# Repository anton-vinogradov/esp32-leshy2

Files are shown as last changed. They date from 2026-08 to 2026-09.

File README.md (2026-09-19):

<div align="center">

# Leshy2 ⭐

### An open standalone pocket tool for radio, communication and authorised research

**2.4/5-GHz Wi‑Fi · BLE · 802.15.4 · 3× nRF24 · Sub‑GHz · VHF/UHF · FM/AM/SW/LW/Airband · IR · LoRa/CC1101+NFC Cap**

[Capabilities](docs/hardware.md) · [Roadmap](docs/roadmap.md) · [Stage reports](docs/stage-results.md) · [Schematics](docs/schematics.md) · [Firmware](https://github.com/anton-vinogradov/esp32-leshy2-firmware) · [Русский](README.ru.md)

</div>

<!-- current-substep: H6.0.3-R1 -->

## What we want

Leshy2 is intended to be a hobby device combining spectrum
observation, communication, diagnostics and safe experimentation without a
mandatory laptop. The first order targets one genuinely working prototype:
the factory supplies two populated PCBAs and the owner completes a simple,
solder-free final assembly.

Repairability is not a design priority and does not justify greater cost, size,
or layout/manufacturing complexity. Optional service conveniences are acceptable
only without those penalties. Safety, reliability, required assembly and test
access, and firmware programming/recovery remain mandatory.

PCB layer count is an engineering choice based on electrical integrity,
manufacturability and the complete quoted cost, not a minimization target.
The current six-layer baseline is retained until a validated comparison justifies a change.

| Area | Intended result |
|---|---|
| Radio | S3 Wi‑Fi/BLE, C5 2.4/5-GHz Wi‑Fi and 802.15.4, 3× full nRF24, CC1101, VHF/UHF voice, FM/AM/SW/LW/Airband RX and IR |
| Interface | 3.5-inch 320×480 touch IPS, direct i8080‑8, buttons, encoder, microSD and audio |
| Expansion | Protected Cap slot for U214 LoRa or U219 CC1101+NFC and an M5 Unit port |
| Reliability | Four independent USB ports, accessible recovery, hardware TX evidence and fail-closed safety |

Transmission and hazardous laboratory functions are constrained by the
[safety model](docs/safety.md); the device is only for lawful use with the
system owner's permission.

## What we decided

- Two 80 × 150-mm six-layer boards: front UI/radio and rear RF/power.
- Six compute domains: S3, C5, front Hub RP, rear RF RP, Pack and Safety.
- Ten permanent antenna ports are split 5+5; each RF path remains board-local and reaches its external connector directly or through one removable microcoax.
- The EastRising `ER-TFT035IPS-6 + ER-TPC035-6` display connects directly to S3 through a 50-contact ZIF and i8080‑8; its FPC points toward the antenna edge, folds without twist and retains at least 5 mm of relaxed reserve.
- The factory fabricates and populates two PCBAs. Without soldering, the owner fits the display on a stock rectangular PSA pad, five microcoax jumpers, knob, fasteners and enclosure.
- The 80-contact M1 carries no structural load; four nylon screws, compression stops and the enclosure carry it.
- The 80 × 150-mm outline remains while routing meets its rules. If a required power, USB/i8080 or RF path cannot route after legal local rearrangement, the next candidate is 85 × 150 mm followed by complete requalification.

## What is designed

### Physical layout

The current preview below is composed from the actual PCBs: exterior faces share one scale, without an extra rear-board mirror. Only the installed display panel's envelope is added in blue. This is not an assembled 3D validation. Inspect the inner sides in [all four current component views](docs/h6-r2-component-views.md). Coordinates and cable paths are available in the [exact-placement](docs/h6-r2-exact-placement.md) and [microcoax](docs/h6-r2-microcoax-service.md) views.

Current native PCB arrangement with the display-panel envelope

H1-to-native correspondence is not fully verified: H1 remains a concept archive, not a picture of current positions. [H6 corrections and open interface findings](docs/h6-r2-interface-review.md) describe the current boards.

[Placement corrections and their verification](docs/h6-r2-placement-repair.md) explain the holder, encoder, port/card access and internal audio assembly. The routing phase is still open.

[Component unification](docs/h6-r2-component-unification.md): GCT USB4105-GF-A ×4 is installed on the native boards; fresh DRC/parity and preservation checks pass. Other candidates and necessary functional differences remain separate.

[Archive: H1 concept four-face Leshy2 mock-up](docs/images/h1-r2-four-faces.svg?rev=h1-r2.39-views-20260907)

[Legend for 223 H1 concept bodies](docs/images/h1-r2-component-legend.svg?rev=h1-r2.39-views-20260907) ·
[physical-design report](docs/h1-r2-physical-layout.md) ·
[functional-architecture report](docs/h0-r2-functional-architecture.md) ·
[front inner face](docs/images/h1-r2-inner-ui.svg) ·
[rear inner face](docs/images/h1-r2-inner-rf.svg) ·
[display mounting](docs/images/display-mount.svg) ·
[physical sections](docs/images/h1-r2-inner-sections.svg)

Leshy2 functional architecture

### Current routing

These are exports from the live `.kicad_pcb` files, not illustrative mock-ups.
Open either board for the full-size SVG.

<table>
  <tr>
    <td width="50%"><a href="docs/images/h6-r2-routing-ui.svg">Current UI-board routing</a></td>
    <td width="50%"><a href="docs/images/h6-r2-routing-rf.svg">Current RF/power-board routing</a></td>
  </tr>
  <tr><td align="center">UI PCB</td><td align="center">RF / power PCB</td></tr>
</table>

### Current components · both faces

All four views use the same scale. Outer faces are above; inner faces below
are viewed after turning each board over, with the antenna edge still at the top.
Grey shows component outlines/references; blue is actual silkscreen.
Known footprint defects remain visible — these views do not certify assembly.
[Full-size views and legend](docs/h6-r2-component-views.md). Gold shows all 50 SMA lands and the two-sided copper lands of USB, Cap and encoder interfaces; NFC endpoints are distinguished in the legend.

[Interface labels and coverage](docs/h6-r2-interface-silkscreen.md) distinguish user, service and assembly silkscreen from grey drawing references.

<table>
  <tr><th width="50%">Front / UI</th><th width="50%">Rear / RF-power</th></tr>
  <tr>
    <td><a href="docs/images/h6-r2-components-ui-outer.svg">UI components, outer face</a></td>
    <td><a href="docs/images/h6-r2-components-rf-outer.svg">RF components, outer face</a></td>
  </tr>
  <tr>
    <td><a href="docs/images/h6-r2-components-ui-inner.svg">UI components, inner face after turning over</a></td>
    <td><a href="docs/images/h6-r2-components-rf-inner.svg">RF components, inner face after turning over</a></td>
  </tr>
</table>

Component views refresh together with routing exports; the common freshness
check rejects images that no longer match the PCB files.

## What we obtained and verified

**Current hardware marker: `H6.0.3-R1`.**

- The historical H0–H5 reviews, including H2 native production ECAD, retain their own baseline scope; their reports are collected in [one index](docs/stage-results.md).
- **Current H3 is `review_required`.** The [current analytical result](docs/h3-r2-acceptance.md) and [rail-voltage paths](docs/power-rail-margins.md) now use the fitted MAIN converter/divider/current-setting resistor. They expose current and voltage shortfalls; MAIN temperature is not established. The MAIN/AON circuit remains unqualified for production or battery energization.
- Both native KiCad boards pass the current [exact-placement checks](docs/h6-r2-exact-placement.md).
- Manufacturer-drawing corrections are being integrated into both PCBs. The [native interface review](docs/h6-r2-interface-review.md) separates applied corrections from remaining assembly gates; clean DRC alone does not prove physical assembly.
- Recovery: S3 ROM UART0 has dedicated native pins; the [C5 TS3/LV control correction](docs/h6-r2-c5-mux-control-review.md) is implemented in source/native ECAD with scoped topology and DRC/parity checks passed. The Safety service manager, electrical/HIL qualification and KILL/update policy remain open; LV20 requires Pre-order, MOQ 21. [Actual recovery boundary](docs/service-recovery.md).
- [Routing automation and design checks](docs/h6-r2-routing-automation.md): the benchmark passed **474/474 connections plus three identical cold replays per block**; the new parallel acceptance command reports current design blockers explicitly. Production routing remains paused pending full-board and electrical qualification. Live copper/connectivity counts, hash-bound DRC results and electrical-review limitations have one owner: [H6.0.3-R1](docs/h6-r2-current-routing.md).
- Native ERC currently uses passive symbol pins; zero findings do not prove correct rail sources or compatible outputs. This electrical-semantics gap blocks release; [corrected pin mappings and partial typed-ERC review](docs/h6-r2-electrical-semantics.md) describe the current evidence and remaining work.

## What remains

1. Correct the native interface/assembly findings and close the electrical-pin/rail-source review gap, then finish every connection and zero schematic-to-PCB parity in H6.0.3.
2. Re-run power/thermal, USB/i8080/M1, RF/Airband, plane and return-current checks on the actual copper.
3. Check STEP, enclosure, cables and final assembly; produce Gerber/BOM/CPL and complete independent DFM/CPL review.
4. Build the first-spin firmware package: reproducible images, fake HAL, available emulation, display test patterns and a safe first-power-on procedure.
5. Immediately before ordering, recheck every exact MPN against JLCPCB Standard PCBA stock/MOQ/price and approve the single actual quote.

Ordering and fabrication remain blocked.

## How the documentation is organised

Each kind of information now has one owner so the same decision is not retold
on several pages:

| Document | Sole role |
|---|---|
| This page | Product story: intent → decisions → implementation → result → remaining work |
| [Roadmap](docs/roadmap.md) | Stage order, current marker and transition criteria only |
| [Stage reports](docs/stage-results.md) | Links to immutable completed-phase results only |
| [Physical design](docs/h1-r2-physical-layout.md), [schematics](docs/schematics.md), [cost](docs/h1-r2-cost.md) | Detail for one subject area |
| `hardware/**/generated` and release contracts | Machine-checkable truth |

Navigation links may repeat; substantive claims belong to their one owner. The
English pages are translations of the Russian pages with the same structure,
not a second independent narrative.

Licensed under [CERN Open Hardware Licence Version 2 — Strongly Reciprocal](LICENSE).

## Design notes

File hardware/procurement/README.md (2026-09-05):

# Procurement evidence workspace

These files preserve the reviewed H5 component/factory evidence used by current
H6 layout work. They are not part of the public finished-product narrative, do not
authorize a purchase and do not replace H7/H8 owner bring-up on the sole prototype.
The active policy is source research first, mapping to the selected assembly
platform second, a documented replacement or exact-part sourcing route third,
and one prototype order only after H6/F-PO and explicit approval. There is no
separate engineering-sample or H5 coupon purchase.
H1 through H5, including the joined pre-layout and component/factory reviews,
are complete. H6.0.3-R1 owns 80-mm routing and net parity after the complete
H6.0.1 placement/mechanical/cable closure and historical H6.0.2 routing slice. JLCPCB Standard PCBA is the
non-exclusive reference, and the full 210-line BOM is mapped to `J0`–`J3`, `J4-F`, `J4-P` or `J5-U`
in the [public manufacturing baseline](../../docs/manufacturing-platform.md).
The controlling state is
[`hardware/verification/h5-component-evidence-plan.json`](../verification/h5-component-evidence-plan.json).

| Gate | Prepared artifact | Current state | Closure condition |
|---|---|---|---|
| exact display and owner installation | [`ER-TFT035IPS-6-display-assembly.md`](ER-TFT035IPS-6-display-assembly.md) | exact `ER-TFT035IPS-6 + ER-TPC035-6 option 5344`, direct `FH34SRJ-50S-0.5SH(50)`, ready-made 3M (TC) `4910SQ-2(5)` 50.8-mm PSA and the relaxed one-fold FPC route are selected; the HMX donor, adapter, untraceable reseller pads and full 33-m tape roll are rejected routes | current-lot dry fit proves the ≤24.66-mm neutral-axis path, ≥5.00-mm relaxed reserve, correct contact orientation, ≤0.714-mm folded stack and ≥0.20-mm pad clearance before owner bonding; owner verifies image/backlight/touch in H7/H8 |
| exact U214 mating stack | [`U214-mating-data-request.md`](U214-mating-data-request.md) | H1 paper geometry closed with pass-through `HLE-107-02-G-DV-PE-LC`; optional manufacturer confirmation retained | exact U214 is packed with the sole prototype; owner performs ordinary mating, continuity and retention checks in H7/H8 |
| dual-SA818S and owner final assembly | [`original inquiry`](H5.0.3-R1-no-order-supplier-inquiry.md) + [`initial reply`](H5.0.3-R1-jlcpcb-response-2026-08-26.md) + [`substantive 2 September reply`](H5.0.3-R1-jlcpcb-response-2026-09-02.md) + [`machine record`](H5.0.3-R1-supplier-response.json) + [`ticket merge notice`](H5.0.3-R1-jlcpcb-ticket-merge-2026-09-02.md) | JLCPCB confirms exact `SA818S-U/V` placement at separate designators, exact-MPN incoming control and no replacement without confirmation, with PCBA MOQ 2. The owner accepts post-PCBA display/PSA/FPC, microcoax, knob and enclosure assembly, so the recorded JLCPCB box-build decline is non-gating. The substantive reply went to `av@apache.org` and appears in Gmail account `no.mail.in@gmail.com` | ✅ `H5-EVR07` passes the PCBA supplier gate; H6 creates quoteable outputs and order-time checks final VHF terms/stock |
| optional Parts API | [`H5.0.3-R1-parts-api-support-inquiry.md`](H5.0.3-R1-parts-api-support-inquiry.md) | support attributes rejection to a new account with no order history, but is not the API review team and gives no threshold; no reapplication submitted | Parts is actually approved after sufficient order history or an accepted exception case; manual evidence remains authoritative meanwhile |
| optional full-device comparison | [`sent PCBWay inquiry`](H5.0.3-R1-pcbway-fallback-inquiry.md) + [`H5-EVR08`](../verification/generated/H5-EVR08-fallback-factory-readiness.json) | The information-only exact-one questionnaire was sent on 2026-09-02 from `vinogradov.anton@gmail.com` to `service@pcbway.com`; Gmail confirmed submission. Owner final assembly removes this response from the release gate. Seeed remains the PCBA second source. No commercial action was created | Record PCBWay's answer when it arrives and compare cost/convenience; do not wait before H6 |
| sole-prototype article manifest | [`pre-kicad-sample-plan.md`](pre-kicad-sample-plan.md) | ✅ 33-line `$267.91` known-material manifest published, including exact panel, ready-cut `3M (TC) 4910SQ-2(5)` and exact `Ettinger 007.02.611` 11-mm stops; all routes mapped and purchase not authorized | H6 locks exact M2.5 nylon screw length and emits Gerber/BOM/CPL; quote and final VHF/stock checks follow immediately before the one order |

The current evidence does not authorize a purchase. KiCad PCB placement/routing
is authorized under H6; prototype fabrication remains a separate later gate.

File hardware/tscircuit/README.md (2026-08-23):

# Current ECAD status

There is **no current Leshy2 schematic or PCB layout in this directory yet**.
The previous tscircuit sheets and their partial KiCad exports were moved to
[`drafts/legacy-2026-08-22/tscircuit-pre-g2f3i`](../../drafts/legacy-2026-08-22/tscircuit-pre-g2f3i/)
because they describe a superseded device: 80-mm boards, a 4-inch ST7796
display, discrete D-pad buttons, STOP, onboard LoRa, SA868 and the old
controller/resource assignment.

Those files are retained only as historical implementation material. They must
not be built, reviewed as the current circuit or sent to a PCB manufacturer.

The current electrical source is the machine-reviewed `G2F-3I` architecture in
[`hardware/architecture`](../architecture/). H1 has been accepted and H2 now
authorizes a new reviewable production schematic generated from that source.
KiCad PCB placement and routing remain unauthorized until the current
schematic, ERC, power/fault simulation and joined mechanical/electrical/firmware
review pass.

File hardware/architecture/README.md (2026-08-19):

# Hardware architecture sources

This directory is the machine-readable source for the Leshy2 device map.

- `devices.json` contains physical devices, exact/current MPNs and contact data.
- `candidates/G2F-3I.json` assigns devices, nets and controller resources in the
  consolidated target architecture.
- `antenna-kit.json` is the dated 12-item full-field antenna manifest, including
  exact first targets, connector polarity, availability and remaining gates.
- `am-lw-pod.json` defines the passive controlled AM/LW pod assembly, its exact
  constituent first targets and the measurements still required before release.
- `generate.py` validates the sources and emits the exact pad/net atlas, pin
  ledger and BOM into `generated/`.
- `tests/` checks contact accounting, GPIO availability, safety defaults,
  resource exclusivity and generated output freshness.

Generate or verify the artifacts with:

```sh
python3 hardware/architecture/generate.py --write
python3 hardware/architecture/generate.py --check
python3 -m unittest discover -s hardware/architecture/tests
```

The public product description is in [`docs/hardware.md`](../../docs/hardware.md).

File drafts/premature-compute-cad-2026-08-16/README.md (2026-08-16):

# Premature compute CAD snapshot

- Archived: 2026-08-16
- Source: exact tracked CAD/CI snapshot from commit `d997122` (`HEAD` when the architecture process was reopened)
- Status: **noncanonical draft/reference; do not use for implementation**
- Superseding decision: [`DEC-0032`](../../docs/review/decisions/DEC-0032-reopen-product-design-before-cad.md)

This snapshot preserves the former `SYN-3A` compute symbols, footprints, provenance,
validator and CI workflow for traceability. Its presence does not select S3, C5,
RP2354A, their package variants, their service topology or any interconnect.

Reusing any part requires a reviewed target product design, whole-device optimality
decision, conceptual placement and new atomic architecture review under `FLOW-0001`.

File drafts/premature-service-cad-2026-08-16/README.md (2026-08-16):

# Premature service-CAD experiment

- Archived: 2026-08-16
- Status: **noncanonical discarded experiment; no implementation input**
- Superseding decision: [`DEC-0032`](../../docs/review/decisions/DEC-0032-reopen-product-design-before-cad.md)

An uncommitted experiment had started exact service connectors and recovery
footprints before product design and complete architecture selection. Those local
CAD artifacts were discarded rather than promoted. The reviewed, implementation-
neutral requirement that every selected programmable chip retain independent
programming, recovery and diagnostics remains active; connector count, format and
pinout are intentionally open.

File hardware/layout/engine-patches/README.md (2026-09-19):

# Experimental engine patches / экспериментальные исправления

`krt-0.22.0-npth-via-floor.patch` targets [KiCadRoutingTools](https://github.com/drandyhaas/KiCadRoutingTools) commit `5a7fbcb6ee4deebd1d9ec1d5bd094d8681f502f3`. Its SHA256 is `f23c065706e02fd003d350f9cd4c308de7b5849981d98a023c10d43850884b03`. Upstream code is MIT-licensed; its notice is retained alongside this patch.

The patch consistently applies the declared copper-to-NPTH floor to via obstacles, post-route nudging and internal DRC. It includes seven regression tests, including the actual failing RF/UI coordinates. It does not weaken rules or change the Rust binary. Apply only to an isolated checkout with `git apply`; never mutate the pinned baseline while a comparison is running. Independent native KiCad validation remains mandatory. Passing unit tests alone is not routing or production acceptance.

Патч согласованно учитывает заданный зазор от меди до NPTH в препятствиях для via, последующем сдвиге via и внутреннем DRC. Семь тестов включают реальные ошибочные координаты RF/UI. Правила и Rust-бинарник не меняются. Применять через `git apply` только в отдельной копии указанной версии; исходный движок во время сравнения не менять. Независимая проверка KiCad обязательна; одних unit-тестов недостаточно для принятия трассировки или производства.

## Pending-pad experiment / эксперимент защиты площадок

`krt-0.22.0-npth-pending-pad.patch` is a **combined replacement**, not a patch to apply on top of the first one. Apply it to the same clean upstream commit. SHA256: `0dec1ef898beec101580f496a7ef48a9042cb45ad77b29b2468e26c3f8a63067`. It retains the NPTH fix and adds opt-in `KICAD_PENDING_PAD_PROTECTION=1`: existing soft approach costs can persist for unescaped pads after a multipoint net's first branch is routed. It creates no copper and changes no clearance rules. Nine additional tests cover default-off behavior, owner exclusion, attachment/rip lifecycle and all four obstacle builders. Retirement reuses the engine's XY attachment heuristic, **not electrical connectivity**; strict native validation remains authoritative. Unit-test success does not establish a successful 474-connection campaign.

`krt-0.22.0-npth-pending-pad.patch` — **совмещённая замена**, не дополнение поверх первого патча; применять к той же чистой upstream-версии. Он сохраняет исправление NPTH и добавляет выключенную по умолчанию опцию `KICAD_PENDING_PAD_PROTECTION=1`: мягкая защита подходов к площадкам может сохраняться после трассировки первой ветви многоточечной сети. Медь не создаётся, правила зазоров не меняются. Девять новых тестов проверяют выключенное состояние, исключение собственной сети, появление/удаление подходящей меди и четыре пути построения препятствий. Снятие защиты использует существующую XY-эвристику, **не проверку электрической связности**; окончательное решение остаётся за независимым native-контролем. Успех unit-тестов не означает прохождения бенчмарка 474 связей.

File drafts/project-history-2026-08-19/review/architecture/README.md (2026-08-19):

# Product and architecture workspace

- Статус: **G2F logical/electrical feasibility active; architecture reopened**
- Correction: [`DEC-0032`](../decisions/DEC-0032-reopen-product-design-before-cad.md)
- Sequencing refinement: [`DEC-0041`](../decisions/DEC-0041-electrical-feasibility-before-physical-layout.md)
- Integrated-mockup pause: [`DEC-0058`](../decisions/DEC-0058-internals-before-integrated-mockup.md)
- Method: [`FLOW-0001`](FLOW-0001-product-to-cad-gates.md)

## Canonical active chain

1. Reviewed intent/capability inputs from stages 1–2.
2. Logical/electrical feasibility: neutral semantic demand, real-device pin
   provenance and at least two complete owner/bus/GPIO candidates.
3. Owner-selected working electrical baseline, explicitly provisional.
4. Dependency-ordered internal closure through [`INT-0001`](INT-0001-internal-design-closure-sequence.md):
   compute/service, safety, power, UI/storage, audio, RF and expansion evidence.
5. Resume target physical/product mockup only after the joint internal paper
   review; any packing/RF/power conflict loops back visibly.
6. Whole-device optimality, conceptual co-design and owner decision.
7. Atomic architecture only after all prior gates pass.
8. Final components, electrical CAD, schematic and PCB afterwards.

The current active artifacts are `DEM-0001`, `SRC-0002`, `DSP-0001/0002`,
`CTL-0001`, [`NIF-0001`](NIF-0001-digital-noninterference-layout.md),
[`RFQ-0002`](RFQ-0002-g2f-3i-rf-concurrency-boundary.md) and the generated
`G2F-pin-ledger` plus focused
[`G2F-3I principled pinout`](generated/G2F-3I-principled-pinout.md).
`PIN-0003/REV-0004V` review the exact owner/contact projection;
`DEC-0052/REV-0004X` then allocate S3 GPIO41/42 to direct-QSPI D2/D3 and record
the then-current `S3=2, C5=1, RP=0, slow=P27` free-contact state. Subsequent
`AUDIO-0002/FND-0067` uses P27 for the omitted RX-audio source selector;
`DEC-0054/REV-0005D` then assigns S3 GPIO6 to reset-safe `AUDIO_ARM`. After
`DEC-0059`, GPIO47 was the only free S3 contact. `DEC-0086/UI-0001` now use
GPIO39/GPIO47 for direct encoder PCNT0 capture and move touch IRQ into shared
GPIO37. `DEC-0088/DSP-0007` fix exact active-low ST77922, 10-kOhm raw pull-up
and non-inverting 1G07. A dedicated TCA9534A restores
interrupt-driven 4×3 controls and releases TCA6424 P00…P05. I5 now assigns
P00/P01/P02 to capture selection, speaker enable and headphone sensing; I6
assigns P03/P04 to powered-off CC1101 band selection. `DEC-0098/EXP-0001` then
uses P05 for independent native-M5-Unit power. Current free state is
`S3=0, C5=1, RP=0, main slow=0`; UI-matrix P7 remains reserved.
`DEC-0051` publishes that reviewed projection as the visible principle-level
working design in the root target document; it remains reopenable and is not
the G7 atomic architecture.
`DEC-0044/REV-0004L` make `G2F-3I` the leading reviewed paper
map under a digital no-neighbour-stall invariant. `FND-0053/REV-0004M` prove
that arbitrary cross-group co-located same-band TX↔RX cannot be promised;
`DEC-0045` selects one active group, while `SG-N24` explicitly requires every
simultaneous three-radio PTX/PRX mix. `DEC-0047` selects a qualified RF envelope.
`N24H-0001` separates ordered `L0 DIV↔DIV` pre-HIL from target `T1`, while
`N24M-0001/IMP-0040/DEC-0048` select three compact IPEX→external-SMA nRF paths
and external SMA for every onboard antenna endpoint; exact production lots,
feeds and measurements remain open.
`DEC-0046/QST-0001` require unused interfaces to
enter verified quiet states. It is not yet target: exact RF paths, power gates,
peripherals and HIL remain open; CAD stays blocked.
`AUDIO-0001/REV-0005B` close the exact ES8311 QFN-20 digital/contact fit:
S3 GPIO1/2/15/16/17/18 land on real I2C/I2S contacts, `CE` is address strap
`0x19`, and P10 is external `CODEC_PWR_EN`. `AUDIO-0002/REV-0005C` compare the
complete capture/playback/TX/reset path, add exact TAC5111IRGER reference
contacts and expose `FND-0067`; `DEC-0054` accepts the active-buffer ES8311
prototype plus direct arm and exact selector/gate/amp ICs. `FND-0095/
AUDIO-0003/DEC-0090/REV-0005AU` now close the dependent I5 paper block with
exact power/interface isolation, analog passives, address/clock handling and
physical microphone/speaker/headphone endpoints. I5 has **«Проведено ревью»**;
acoustic/RF/specimen HIL stays explicit. I6 later receives paper review by
`DEC-0097/COX-0001/REV-0005BC`; I7 is reviewed by `DEC-0098/0099`, and I8 is
now active.
`DEC-0058` now pauses the integrated mockup until the internal chain is jointly
reviewed. `INT-0001/I1` has **Проведено ревью** through
`DEC-0059/REV-0005L`: 1-bit C5 SDIO restores S3 UART0 and C5 native USB,
while M5 Unit UART moves to UART1 on the same pins. `DEC-0061/SAFE-0002/
REV-0005O` now give `I2` **Проведено ревью**: exact AON latch/reset/gate
devices cover S3+C5+RP and every external TX request, while seven RF detectors,
optical IR evidence, local-I²C source mask and direct physical aggregate are
machine-projected. `DEC-0082/PWR-0021/REV-0005AM` now give I3 paper electrical
scope **«Проведено ревью»** and make I4 the active paper block; named
procurement and prototype HIL evidence remains open.
`DEC-0083/USB-0001/REV-0005AN` then close the first I4 endpoint: exact JAE
USB-C and TI four-line protection replace the abstract port, corrected 220-pF
CC shunts preserve capacitance margin, and that endpoint leaves GPIO47 free. Physical
port/SI/ESD HIL stays open while I4 proceeds.
`FND-0088/DSP-0006/DEC-0084/REV-0005AO` then close the display paper
electrical endpoint: exact first ZIF candidate, protected-main logic supply,
reset-low defaults and a separately latch-protected PWM backlight replace the
three former abstractions. Real-tail mate/orientation, panel procurement and
electrical/thermal HIL remain open; no KiCad or physical freeze is implied.
`FND-0089/STO-0001/DEC-0085/REV-0005AP` then close the microSD paper
electrical endpoint. Exact card-side Ioff buffers, CS-gated DAT0 return,
mandatory switched pulls, all exposed-contact/detect ESD, reset defaults and
SPI-mode-first sequencing preserve the shared S3 allocation without a new
GPIO. Socket placement/access, real media, throughput and fault HIL stay open.
`FND-0090/UI-0001/DEC-0086/REV-0005AQ` then restore the complete local-control
inventory and close its principled pin fit: 4x3 ordinary matrix, direct PCNT0
encoder, direct RP PTT and independent AON STOP/RE-ARM.
`FND-0092/UI-0002/DEC-0087/REV-0005AR` close the next electrical boundary with
exact low-current switches, a gold-clad COM+NC STOP target, exact pull/filter
networks and separate matrix/fast/safety ESD returns. Cap/guard/harness and
enclosure mechanics and control HIL remain open.
`FND-0093/DSP-0007/DEC-0088/REV-0005AS` then close the exact integrated touch
identity/address/polarity endpoint: ST77922 is the assembly TDDI at `0x38`,
active-low TP_INT has its own 10-kOhm raw pull-up and fixed 1G07 path to shared
GPIO37, and the former inverter option is removed. Specimen IRQ/reset,
shared-source and physical HIL remain open.
`FND-0094/IOX-0001/DEC-0089/REV-0005AT` then complete the consolidated I4
audit. Exact TCA6424A power/address/reset/interrupt, AON-to-main observation
isolation, pack target `0x2A`, real GPIO4 microSD return, direct USB-shell
ground bond and exact STOP LED resistor are machine-projected. I4 paper
electrical scope has **«Проведено ревью»**; I5 follows as reviewed above, while prototype,
physical and procurement evidence stays open and KiCad remains unauthorized.
`PWR-0002/REV-0005P` review its current load/scenario prerequisites and reject
the legacy sheet as a target: its charger lacks a system power path, its ADC
is not a fuel gauge, fixed 3-A Type-C draw is unproven and its rails do not fit
the accepted AON/voice/current envelope. The owner accepted `IMP-0052/B` as
`DEC-0062`: the two 18650 slots remain individually replaceable, and admission
is fail-closed rather than accepting arbitrary loose cells. `DEC-0064` then
reopened the electrical series/controlled-1S arrangement for comparison, and
`DEC-0065/REV-0005T` confirm supervised 2S for the base product.
`PWR-0003/IMP-0053` are closed by `DEC-0063`: the owner selected sink-only
USB-PD up to 30 W. `PWR-0004/REV-0005R` review exact TPS25751DREFR,
BQ25798RQMR, CAT24C512WI-GT3 and TVS2200DRVR fit while leaving the cell manager,
rail tree, passives and HIL active in I3. `PWR-0005/FND-0075` separate ordinary
pack gauging from fail-closed loose-cell admission; `DEC-0066/REV-0005V`
accept exact MAX17320G20+T plus MSPM0C1104SDGS20R and project both physical
devices separately. `PWR-0006/FND-0076` retain the
controlled two-slot 1S and one-slot 1S alternatives as future-SKU comparison
evidence. `PWR-0007/FND-0077/REV-0005W` review the exact 2S tap rules, reset
hold, admission-supply isolation, two-ADC evidence and common-path losses.
`DEC-0067/REV-0005X` close the exposed recovery gate with no in-device
deep-cell recovery and accept the exact active switching FET, fuses, shunt,
NTCs, hold and supply-isolation packages. `PWR-0008/DEC-0068/REV-0005Y`
then review the independent fixed AON/3.3/4.0/5.0-V rail tree, exact
TPS629203/TPS564252 inductors, five TPS22919 branches and reverse-blocking
TPS259470L latch-off external boundary after `DEC-0069/REV-0005Z`.
`PWR-0009/DEC-0070/REV-0005AA` add two exact `MMBT3904-7-F` qualifiers so
disabled optional rails release `POWER_FAULT_N`, while EN-high PG loss remains
hardware-visible. `PWR-0010/DEC-0071/REV-0005AB` correct the earlier startup
claim: the 1.509-A eFuse limit is immediately active, 4.7 nF controls startup
slew and 220 nF admits only a bounded post-start 2-A transient. Exact OVLO,
local bypass and output bleed are now eight physical MPN-bearing instances in
the machine source and living diagrams. `PWR-0011/DEC-0072/REV-0005AC` then
replace the four converters' abstract networks with 24 exact physical
configuration, input, output, fixed-feedback and feed-forward passives. Their
fixed tolerance ranges remain compatible with the loads and eFuse OVLO, and
the obsolete 45.0-kOhm candidate is rejected for the active 45.3-kOhm MPN.
`PWR-0012/DEC-0073/REV-0005AD` first close direct AON enable plus nine exact
EN/PG/fault resistors using only existing BOM MPNs. `FND-0084/PWR-0019/
DEC-0080/REV-0005AK` later expose and remove the hidden source-sequencer
endpoint: AON PG directly holds TPS3808 MR, delayed POR directly enables main,
and an exact 10-kOhm/100-kOhm pair gives 3.0-V nominal release. The amended
control profile has ten physical resistor positions and no new unique MPN.
`FND-0085/PWR-0020/DEC-0081/REV-0005AL` then correct the remaining internal
single-fault gap with exact independent AON/main/voice post-buck cutoffs,
protected-side PG, threshold/loss calculations and a reviewed fault matrix;
no GPIO or function is lost.
`FND-0086/PWR-0021/DEC-0082/REV-0005AM` consolidate every I3 paper obligation,
heat source, fault and physical residue. I3 is paper-reviewed with all
prototype/lot/I8 evidence still explicit; this activates the dependent I4
paper block at that point in the chain.
`FND-0087/USB-0001/DEC-0083/REV-0005AN` now give exact protected product USB
the first I4 paper-endpoint review without promoting placement or HIL.
`FND-0088/DSP-0006/DEC-0084/REV-0005AO` give the second I4 endpoint a paper
review while explicitly rejecting a back-power-prone whole-panel switch and
keeping the connector footprint blocked on a real FPC-tail proof.
`FND-0089/STO-0001/DEC-0085/REV-0005AP` give the third I4 endpoint a paper
review, eliminate storage back-power and display-D1 contention, and keep the
socket footprint, media/endurance, throughput and destructive HIL blocked.
`FND-0090…0093/UI-0001/UI-0002/DSP-0007/DEC-0086…0088` retain every physical
control, close exact switch/protection and touch identity/address/polarity,
and leave only named mechanics/specimen HIL before the consolidated I4 audit.
`FND-0094/IOX-0001/DEC-0089/REV-0005AT` close that consolidated audit, correct
the shared-interface residues and advance the dependency chain to I5 without
claiming layout or HIL evidence.
`FND-0095/AUDIO-0003/DEC-0090/REV-0005AU` close that I5 paper block and
advance the dependency chain to active I6 without claiming acoustic, RF,
layout or HIL evidence.
`FND-0096/N24E-0001/DEC-0091/REV-0005AV` close the first I6 paper subblock:
three full-function nRF paths gain exact powered-off digital isolation,
local energy and directional 2400–2525-MHz actual-TX evidence. The unproven
Ebyte RF mate, thresholds, T1 fixture and every other I6 RF endpoint remain
open, so I6 and the no-KiCad boundary are unchanged.
`FND-0097/NAT-0001/DEC-0092/REV-0005AW` then close the native-radio paper
subblock: exact S3 2.4-GHz and C5 2.4/5-GHz external contacts now lead through
separate real U.FL mates and dual-band directional couplers into complete
LTC5532 evidence circuits. C5 ANT2 is explicitly default-disabled/no-connect;
jumper length, chassis RP-SMA, thresholds and whole-feed HIL remain physical
gates. `FND-0098/CCRF-0001/DEC-0093/REV-0005AX` next close the CC1101 paper
subblock: two equal-control SP3T bodies isolate all three branches at both ends,
P03/P04 select 315/433/868–915 only while power is off, exact crystal/balun/
passives/ESD are physical and a final-line AD8314 sample replaces the abstract
evidence tap. Conducted tuning, sensitivity/output/spurious/legal-profile,
SMA mechanics and coexistence HIL remain open; I6 and no-KiCad boundary stay
active for the remaining RF endpoints. `FND-0099/VRF-0001/DEC-0094/
REV-0005AY` then close the SA518 RF paper subblock: physical ANT contact 7
feeds a direct protected 50-Ohm SMA boundary, exact 24-V low-C ESD and an
AD8314 5.1-kOhm/52.3-Ohm actual-TX sample. The lower-voltage CC TVS is not
reused, no unproven filter bank spends P05, and a measured conducted failure
explicitly reopens that choice. Voice RF HIL remains open; I6 continues with
IR and consolidated coexistence under the same no-KiCad boundary.
`FND-0100/IRF-0001/DEC-0095/REV-0005AZ` then close the IR paper endpoint.
Exact top-view SMD `TSOP95238TT` and `TSMP95000TT` retain robust
demodulation plus measured 30-60-kHz carrier learning behind one discharged
receive rail and Ioff return buffer. Exact `VSMY14940`, 33-Ohm limit,
`DMN2056U-7` and the existing STOP gate close TX; shielded `VEMD1060X01` plus
AON `TLV9061IDBVR` verify physical light rather than current. Pin budgets do
not change. `FND-0101/RXF-0001/DEC-0096/REV-0005BA` subsequently catch the
still-abstract Si4732 FMI/AMI endpoints and add separate protected FM/SW and
non-50-Ohm AM/LW first-target circuits. `FND-0102/REV-0005BB` then correct the
entire shifted SOIC-16 machine contact map from the visually inspected
manufacturer package drawing and lock all 16 contacts. Optical/thermal/IEC and consolidated
coexistence HIL remain open. `FND-0103/FND-0104/COX-0001/DEC-0097/
REV-0005BC` then remove the stale cross-group-promotion path, split receiver,
codec/audio and voice quiet contracts and freeze one consolidated matrix for
all groups, legal intragroup modes, ordered transitions, eight fixture classes,
actual-TX evidence and no-stall thresholds. I6 has **«Проведено ревью»** for
paper electrical and qualification scope; physical HIL remains explicitly
not executed and can reopen its owner. I7 subsequently closes below and the
no-KiCad boundary continues through active I8.
`FND-0105/EXP-0001/DEC-0098/REV-0005BD` close the I7 M5 expansion paper
subblock. U214 and the native HY2.0-4P Unit port now have independent
true-reverse-blocking 5-V branches, branch-valid supervisors, exact signal
isolation and connector ESD. The fictitious accessory-presence input is removed;
P26 reports real Unit-rail readiness. Connector MPNs and all physical/hot-plug/
reverse-source/profile/coexistence evidence remain open.
`FND-0106…0108/SVC-0002/DEC-0099/REV-0005BE` then close the remaining I7
service/recovery paper circuit: separate data-only C5/RP USB ports now block
VBUS and D-line backfeed, three keyed DBG10 and six controls are exact, and
passive-drain reset sinks remove push-pull contention. I7 has **«Проведено
ревью»**; I8 is active and the no-KiCad boundary continues.
`FND-0109/BOM-0008` then generate the first complete I8 coverage view.
`PWR-0022/DEC-0100/REV-0005BF` repair and re-review the exposed MAX17320/MSPM0
support residue without changing the accepted 2S product topology. The current
map has 858 architecture instances; `FND-0112/BOM-0011/DEC-0103/REV-0005BJ`
exclude the one assembly-internal ST77922 evidence node, leaving 857
supplied/costed placements / 187 purchase MPN lines plus four explicit SMA, cable, M5
and antenna-kit gap families. `FND-0110/SAFE-0003/DEC-0101/REV-0005BG`
subsequently instantiate every actual-TX threshold network and repair the
AON-to-main evidence boundary. I8 inventory coverage is reviewed;
orderability, cost and alternate qualification remain active.
`FND-0113/REV-0005BP` then repair the product-site projection itself: a bounded
vertical overview renders on GitHub, while the exhaustive one-device-per-node
source and pin/net tables stay machine-derived. No architecture content changes;
I8 remains active and KiCad remains unauthorized.
`FND-0111/BOM-0009/DEC-0102/REV-0005BH` subsequently recheck all 33 missing
source lines, replace the RP prose pseudo-MPN with exact `SC1512-A4`
(`RP2354B0A4`) and, after the internal-node correction, leave current
orderability coverage at 186/187. Exact
standalone `HMX035CTFT-001` sourcing is the sole used-line residue; cost and
the four physical purchase families remain open. `DSP-0008/BOM-0010/REV-0005BI` then prove current complete-board
specimen access, define the exact standalone-panel RFQ and record the first
no-drop-in disposition without changing the display endpoint.
`BOM-0012/DEC-0104/REV-0005BK` subsequently classify all 187 purchase lines:
policy coverage is complete without pretending that specific second-source
MPNs are already qualified.
`BOM-0013…0026/DEC-0105…0106/REV-0005BL…CA` then validate the cost-evidence
contract, explicit RFQ/retail gaps and first 175/187 prices covering 829
placements. Their USD 157.3727 base-product subtotal is deliberately partial;
all twelve remaining prices have explicit gates and full factory COGS remains
open.
`BOM-0027/REV-0005CB` subsequently make the four physical-family boundaries
machine-readable: 4/4 families / 28 items now have owner, prerequisites and
acceptance. Exact connectors, harnesses, antenna-kit items and physical/RF HIL
remain open at those gates; no MPN or footprint is guessed.
`FND-0115/BOM-0028/REV-0005CC` then remove the circular exit condition: G2F/I8
cannot depend on G3 geometry or the downstream G8 frozen BOM. I8 receives
**«Проведено ревью»** in paper procurement-feasibility scope; exact physical
gate execution, target RFQ, named production alternates and factory COGS stay
mandatory at G3/G8. `FND-0116/I9-0001/REV-0005CD` then complete the joint
working-candidate paper review: all 59 unique `abstract:*` boundaries are
exhaustively classified and no owner decision remains hidden. G3 integrated
mockup work resumes; G7 atomic selection and KiCad remain unauthorized.
`PWR-0013/DEC-0074/REV-0005AE` then close the exact 10-Ohm pre-admission
load, independent non-retriggerable timer, 28.7-40.7-ms C0G paper window,
25-50-ms production acceptance and both divider/filter frontends. `FND-0078`
corrects the old PA24 battery-divider assignment to real
PA25/PA26 contacts without changing the `12/3/3` budget.
`PWR-0014/DEC-0075/REV-0005AF` then close the exact BQ25798 2S/750-kHz
strap, 2.2-uH/7-A inductor, all physical energy banks, BATP/TS/ILIM, local-bus
pulls, reset-high CE and special-pin terminations. `FND-0079` corrects product
USB-C/USB2 protection back to I4 and exposes TPS25751/CAT24C512 support
passives as the next true I3 paper dependency.
`FND-0080/PWR-0015/DEC-0076/REV-0005AG` then correct separate TPS
VBUS/VBUS_IN startup, hardware SafeMode,
17 exact support components and both complete I2C pull networks.
`FND-0082/PWR-0017/DEC-0078/REV-0005AI` then correct the physical TPUL WQFN
map, reuse its second channel for a `>=350 ms` hardware refractory lockout and
replace the single load with two parallel 20-Ohm/2-W branches. Exact-cell
selection is then closed at paper level by `FND-0083/PWR-0018/DEC-0079/
REV-0005AJ`: two exact `XTAR 18650 4000mAh` protected button-top instances
provide `28.8 Wh`, a 10-A discharge class and a 2-A standard-charge ceiling.
Assembly-matching certification evidence, droop distributions, mechanical
continuity/thermal coupling, calculated hot loss and HIL remain active.

## Active G2F artifacts

- [`INT-0001`](INT-0001-internal-design-closure-sequence.md) defines the
  dependency-ordered `I0…I9` paper/electrical closure required before the
  integrated physical mockup resumes;
- [`SAFE-0001`](SAFE-0001-aon-stop-and-tx-evidence-options.md) reviews the `I2`
  options; [`SAFE-0002`](SAFE-0002-accepted-aon-stop-and-evidence-circuit.md)
  records the accepted exact fan-out, pulls, fault matrix, eight evidence
  channels and test points. `FND-0071` paper mismatch is closed; I3/I6/HIL
  measured proof remains explicit;
- [`SAFE-0003`](SAFE-0003-exact-actual-tx-threshold-and-isolation.md)
  instantiates all eight comparator threshold/hysteresis networks, completes
  comparator/source-mask support and isolates three AON evidence signals from
  main-domain inputs; paper electrical scope reviewed, calibration/HIL open;
- [`PWR-0002`](PWR-0002-i3-power-prerequisite-audit.md) re-derives the `I3`
  loads/scenarios and rejects the old source as a target;
- [`PWR-0003`](PWR-0003-charge-power-path-options.md) compares the complete
  5-V Type-C/NVDC and USB-PD/buck-boost paths; B is accepted by `DEC-0063`;
- [`PWR-0004`](PWR-0004-accepted-usb-pd-front-end.md) verifies the exact
  sink-only 30-W PD/charger/configuration/protection path and sourcing snapshot;
- [`PWR-0005`](PWR-0005-replaceable-2s-manager-options.md) reviews exact
  gauge/admission candidates and reset-default behavior; option A is accepted
  by `DEC-0066`;
- [`PWR-0006`](PWR-0006-one-or-two-cell-topology-comparison.md) reviews the
  reopened topology, rails, losses, one-cell behavior and cost; supervised 2S
  is accepted by `DEC-0065`;
- [`PWR-0007`](PWR-0007-max17320-2s-surrounding-circuit.md) verifies the 2S
  sensing/shorting rules, current/loss screen, per-slot fuse/NTC candidates,
  shunt, reset hold, supply handover and real ADC budget; `DEC-0067` accepts
  no in-device recovery and the exact active common-drain power FET;
- [`PWR-0008`](PWR-0008-exact-downstream-rail-tree.md) verifies independent
  fixed rails, exact converter/inductor/load-switch/eFuse contacts, current
  headroom, availability, sequencing and the updated cost screen;
- [`PWR-0010`](PWR-0010-external-efuse-passive-profile.md) closes the first
  exact eFuse `RILM/dVdt/ITIMER/OVLO`, local-capacitor and discharge profile,
  and separates controlled startup from the bounded 2-A post-start interval;
- [`PWR-0011`](PWR-0011-application-converter-passive-profile.md) closes the
  exact AON and three TPS564252 energy/configuration/feedback profiles as 24
  separate physical parts, including lifecycle, tolerance and DC-bias screens;
- [`PWR-0012`](PWR-0012-exact-converter-control-passives.md) closes direct
  AON enable and, after the DEC-0080 amendment, ten exact converter/POR
  EN/PG/fault resistors without adding a GPIO or unique BOM MPN;
- [`PWR-0013`](PWR-0013-exact-pack-diagnostic-frontends.md) is retained as the
  historical first diagnostic pass and is explicitly superseded by PWR-0017;
- [`PWR-0014`](PWR-0014-exact-bq25798-passive-profile.md) closes the exact
  BQ25798 2S/750-kHz energy, current/temperature sensing, reset and special-pin
  profile while leaving placement/thermal/source-transition HIL explicit;
- [`PWR-0015`](PWR-0015-exact-tps25751-eeprom-support-profile.md) closes the
  exact TPS25751D/CAT24 autonomous SafeMode startup, 17 support components,
  unused contacts and complete local/host pull networks;
- [`PWR-0016`](PWR-0016-keystone-1048p-holder-and-ntc-coupling.md) closes the
  exact polarized holder and three physical cell-temperature contact roles;
- [`PWR-0017`](PWR-0017-hardware-diagnostic-refractory-lockout.md) closes the
  corrected TPUL contacts, cascaded hardware cooldown, hot repetition bound
  and two-branch pulse-rated load while leaving exact-cell droop numbers HIL;
- [`PWR-0018`](PWR-0018-xtar-18650-4000mah-cell-profile.md) selects two exact
  XTAR protected 4-Ah cells as the first qualification target and records the
  certification/specimen gates;
- [`PWR-0019`](PWR-0019-exact-source-sequence-and-power-reserve.md) replaces
  the abstract source sequencer with the exact AON-PG/POR/main path and freezes
  a conservative system-first USB/charge power rule;
- [`PWR-0020`](PWR-0020-independent-post-buck-containment.md) separates all
  internal raw buck outputs from their loads with exact independent cutoffs,
  protected PG and reviewed threshold/loss/single-fault behavior;
- [`PWR-0021`](PWR-0021-i3-consolidated-paper-closure.md) audits the complete
  I3 dependency, heat/fault ledger and remaining evidence, allowing I4 paper
  work without claiming prototype qualification;
- [`PWR-0022`](PWR-0022-exact-max17320-2s-support-profile.md) repairs the exact
  MAX17320 2S support, status translation, shunt force path and MSPM0 support;
  **Проведено ревью paper electrical scope**, physical/HIL open;
- [`USB-0001`](USB-0001-exact-product-usb-c-and-protection.md) closes the first
  I4 endpoint with exact JAE USB-C, four-line TI CC/USB2 protection, corrected
  220-pF CC shunts and complete real-contact routing while retaining HIL;
- [`STO-0001`](STO-0001-exact-isolated-microsd-endpoint.md) closes the third
  I4 endpoint with exact switched power, partial-power isolation, pull/damping,
  complete socket ESD and always-readable detect while retaining physical and
  media HIL;
- [`UI-0002`](UI-0002-exact-switch-and-control-protection.md) closes exact
  contact-current, default-state and ESD routes for every retained physical
  control while keeping actuator/enclosure HIL open;
- [`DSP-0007`](DSP-0007-exact-integrated-st77922-touch-endpoint.md) names the
  integrated ST77922, exact `0x38`/active-low contract and fixed board IRQ
  normalizer while retaining specimen/shared-line HIL;
- [`IOX-0001`](IOX-0001-consolidated-i4-electrical-closure.md) audits all I4
  endpoints together, closes the exact main slow-I/O core and cross-domain
  routes, and classifies every remaining item as HIL, physical, I5…I8 or CAD;
- [`AUDIO-0003`](AUDIO-0003-exact-audio-and-receiver-endpoint.md) closes I5
  with exact codec/receiver/voice power and isolation, complete analog paths,
  exact acoustic endpoints and separately named HIL residue;
- [`DEM-0001`](DEM-0001-current-semantic-signal-demand.md) reconstructs current
  signal demand without inheriting an owner;
- [`SRC-0002`](SRC-0002-real-device-pin-provenance.md) requires the full
  SoC/package/module/carrier chain and records the first verified candidates;
- [`AUD-0013`](../audits/AUD-0013-legacy-layout-generator-reuse.md) records which
  geometry/checks from the old drawing generator will be reused after pin review;
- [`REV-0003X`](../reviews/REV-0003X-electrical-feasibility-entry.md) reviews the
  sequencing correction and these inputs.
- [`DEC-0042`](../decisions/DEC-0042-single-source-architecture-data.md) accepts
  one machine-readable device/net source; [`G2F-pin-ledger`](generated/G2F-pin-ledger.md)
  renders three structurally checked maps including leading `G2F-3I`;
- [`PIN-0003`](PIN-0003-g2f-3i-principled-pinout.md) and the generated
  [`pinout atlas`](generated/G2F-3I-principled-pinout.md) provide the requested
  principled owner/net/pad diagram and exact tables. `FND-0059` fixes stale
  pre-quiet-state budgets; `FND-0060` exposes every still-abstract electrical
  endpoint instead of presenting it as a finished schematic;
- [`REV-0005K`](../reviews/REV-0005K-vertical-living-principled-diagram.md)
  makes that diagram a narrow top-to-bottom living projection. Every accepted
  internals change must update both target README diagrams and the generated
  atlas in the same commit; regression checks current candidate MPN coverage;
- [`REV-0003Y`](../reviews/REV-0003Y-single-source-and-draft-pin-maps.md) reviews
  the generator foundation and explicitly leaves complete-candidate review open.
- [`DSP-0001`](DSP-0001-display-storage-real-device-evidence.md) replaces the
  inherited full-frame target with the accepted task/dirty-region contract;
- [`DSP-0002`](DSP-0002-fast-display-path-options.md) finds that display+SD is
  the only deliberately shared high-rate pair, exposes the stale U214-derived
  `256 B` quantum as `FND-0061`, and reviews direct S3 QSPI, EVE and fourth-MCU
  paths. `IMP-0044/A` is accepted by `DEC-0052`; the machine map now assigns
  S3 GPIO41/42 to QSPI D2/D3 and uses measured `<=1 ms` display occupancy;
- [`DSP-0003`](DSP-0003-exact-fast-display-shortlist.md) shows that the old
  4-inch ST7796S remains a valid A0 workload fixture but not a QSPI target.
  `DEC-0053` accepts the new 3.5-inch portrait `320×480` QSPI IPS+touch class;
  [`DSP-0004`](DSP-0004-display-part-number-register.md) lists every known
  display identifier and every production `TBD` without freezing a dev board;
- [`CTL-0001`](CTL-0001-slow-control-and-external-i2c-boundary.md) proves that
  current validation closes MCU accounting only, derives the open slow-control
  envelope and records the required external-I²C fault boundary;
- [`DEC-0044`](../decisions/DEC-0044-delegated-noninterference-layout.md) accepts
  the 24-endpoint/separated-I²C invariant and delegates layout search;
  [`NIF-0001`](NIF-0001-digital-noninterference-layout.md) records the selected
  paper arrangement and rejected bandwidth/controller variants.
- [`RFQ-0002`](RFQ-0002-g2f-3i-rf-concurrency-boundary.md) applies real
  shared-chain/range/power facts to `G2F-3I`; [`FND-0053`](../findings/FND-0053-arbitrary-colocated-rf-concurrency-is-impossible.md)
  separates impossible arbitrary cross-group TX↔RX concurrency from mandatory
  three-nRF full-function concurrency,
  and [`IMP-0038`](../improvements/IMP-0038-visible-qualified-rf-arbiter.md)
  records the accepted group arbiter. [`FND-0054`](../findings/FND-0054-three-nrf-mix-needs-rf-acceptance.md)
  and [`IMP-0039`](../improvements/IMP-0039-three-nrf-full-mix-acceptance.md)
  derive the physical acceptance envelope for all nRF PTX/PRX mixes;
- [`DEC-0047`](../decisions/DEC-0047-qualified-nrf-mix-with-external-observer.md)
  accepts the qualified-envelope option; [`N24H-0001`](N24H-0001-two-device-full-mix-fixture.md)
  uses the two ESP32-DIV units as `L0` pre-HIL and requires separate target
  `T1` DUT/observer evidence for production acceptance;
- [`QST-0001`](QST-0001-unused-interface-quiet-states.md) propagates
  [`DEC-0046`](../decisions/DEC-0046-unused-interface-quiet-by-default.md) into
  per-interface power-down, clock-parking and EMI proof contracts.
- [`ANT-0001`](ANT-0001-external-sma-path-inventory.md) reviews every onboard
  antenna endpoint against exact device pins. It finds two Si4732 input
  domains and rejects the legacy one-generic-port assumption;
  [`DEC-0049`](../decisions/DEC-0049-nine-dedicated-external-sma-paths.md)
  accepts nine labelled SMA with separate `RX-FM/SW` and `RX-AM/LW` paths.
- [`RFH-0001`](RFH-0001-module-to-external-sma-interface-review.md) separates
  five module-origin feeds from four PCB/frontend-origin feeds. It verifies
  first-generation U.FL/MHF I/AMC compatibility for S3/C5, records Ebyte
  `IPX` as unproven `FND-0057`, and opens external gender choice `IMP-0042`.
- [`RFH-0002`](RFH-0002-antenna-connector-ecosystem-review.md) checks actual
  antenna ecosystems instead of grouping only by frequency. It finds RP-SMA
  typical for native Wi-Fi, standard SMA in Ebyte's nRF ecosystem and both
  polarities in sub-GHz; `DEC-0050/REV-0004T` accept bounded
  `2 RP-SMA + 7 standard SMA` and made exact antenna sourcing the next gate.
- [`ANT-0002`](ANT-0002-current-orderable-antenna-shortlist.md) reviews exact
  current commercial candidates. It finds safe SKU sharing for S3/C5 and the
  three nRF paths, a combined 868/915 candidate, but no honest universal
  315–915 or full VHF/UHF radiator. `DEC-0055/REV-0005E` accept the profiled
  external kit and exact-MPN availability gate. `FND-0058` keeps production
  two-source and assembled-HIL qualification open; `MFG-0001/IMP-0047` cover
  one-stop PCBA plus loose-antenna kitting without yet constraining supplier.
- [`DSP-0002/REV-0004W`](DSP-0002-fast-display-path-options.md) review the
  display acceleration gate against the exact current pin budget. Direct QSPI
  fits with `GPIO41/42`; current RP/C5 display ownership and direct I80/RGB do
  not. `DEC-0052/REV-0004X` accept and propagate this path;
  `DEC-0053/REV-0004Z` accept the 3.5-inch display class while exact production
  assembly, optics and HIL remain open in `DSP-0004`.
- [`AUDIO-0001`](AUDIO-0001-es8311-exact-electrical-fit.md) records every
  ES8311 QFN-20 contact, proves the unchanged digital pin budget and corrects
  `CE` versus external power enable. [`AUDIO-0002`](AUDIO-0002-complete-audio-path-comparison.md)
  compares the whole fail-safe path; [`IMP-0046`](../improvements/IMP-0046-es8311-analog-routing-topology.md)
  is accepted as [`DEC-0054`](../decisions/DEC-0054-fail-safe-complete-audio-path.md)
  with propagation reviewed by `REV-0005D`.

## Active and reference G3 artifacts

- [`PD-0001`](../product-design/PD-0001-g3-physical-design-inputs.md) translates
  reviewed capabilities into physical field/control/safety/RF/expansion/service
  inputs and has received input review;
- [`LAY-0001`](../product-design/LAY-0001-form-factor-candidates.md) visualizes
  compact, balanced and field-service same-scope experiments. Its drawing
  content was reviewed, but its direction is superseded by `DEC-0041`; no owner
  choice among P1/P2/P3 is requested.
- [`PHY-0001`](../product-design/PHY-0001-u214-rear-dock-fit.md) retains the
  accepted bounded U214 rear-envelope decision; its former `DEC-0058` pause is
  released after `INT-0001/I9` review.
- [`G3-0001`](../product-design/G3-0001-current-clamshell-reentry.md) is the
  active generated current clamshell starting projection. It preserves the
  useful legacy geometry/checks while replacing stale ownership, display,
  LoRa, antenna, control, service and battery assumptions; geometry re-entry
  is reviewed and G3 continues.

No electronic zone in `LAY-0001` assigns a chip, bus or pin. Former
`SYN/PIN/PKG` arithmetic may be reused only after exact-device revalidation.

## Active reviewed prerequisites

- reviewed stage-1 intent and safety/legal decisions;
- reviewed `REQ-*` behavior, evidence, concurrency and failure obligations with
  owner/backend clauses reopened by `DEC-0032`;
- `INV-0002/0004` for the prior 125 leaves, the current-competitor delta in
  [`AUD-0004`](../audits/AUD-0004-current-competitor-capability-gap.md), and the
  M5 expansion audit [`AUD-0005`](../audits/AUD-0005-m5-expansion-ecosystem-coverage.md),
  plus the former FIDO audit retained only as superseded evidence
  [`AUD-0006`](../audits/AUD-0006-fido-authenticator-security-boundary.md),
  haptic prerequisite audit
  [`AUD-0007`](../audits/AUD-0007-haptic-product-mechanical-cost.md) and IMU
  instrument-value audit
  [`AUD-0008`](../audits/AUD-0008-imu-instrument-value-and-placement.md), plus
  physical-keyboard archetype audit
  [`AUD-0009`](../audits/AUD-0009-physical-keyboard-product-archetype.md), and
  High-Speed USB host audit
  [`AUD-0010`](../audits/AUD-0010-high-speed-usb-host-use-cases.md), and
  mission-scope audit
  [`AUD-0011`](../audits/AUD-0011-radio-key-product-scope.md), and 6 GHz/Wi-Fi
  6E fact review
  [`AUD-0012`](../audits/AUD-0012-6ghz-wifi6e-product-scope.md).

`W-EXTRA-11` is reviewed by `DEC-0033/REQ-IBTN-0001`; M5-first Unit/Cap plus a
separate high-throughput class without native M5-Bus is reviewed by
`DEC-0034/REQ-EXT-0001`. `W-EXTRA-12` is reviewed by
former `DEC-0035/REQ-FIDO-0001` is removed from target by `DEC-0039`; product
haptic is rejected by `DEC-0036`; optional
external IMU measurement pose is reviewed by `DEC-0037/REQ-IMU-0001`. G2
also closes `W-EXTRA-15` through `DEC-0038`: no integrated keyboard, bounded
phone-assisted text. `DEC-0039/REQ-SCOPE-0001` reject generic `W-EXTRA-16`,
retain only RF-derived high-throughput transport and classify BadUSB as a
software-only exception. `DEC-0040` rejects `W-EXTRA-17` 6 GHz/Wi-Fi 6E from
base and optional product scope. `REV-0002AS` closes repeated G2 review; G3
target product design is now the active gate.

## Candidate/reference studies

- Former [`CAP-0001`](CAP-0001-zero-based-capability-input.md),
  [`CON-0001`](CON-0001-hardware-neutral-concurrency-model.md),
  [`RES-0001`](RES-0001-hardware-neutral-resource-demand.md),
  [`SRC-0001`](SRC-0001-primary-hardware-resource-facts.md),
  [`SYN-0001`](SYN-0001-zero-based-whole-device-candidates.md),
  [`PIN-0002`](PIN-0002-zero-based-exact-pin-maps.md),
  [`BUD-0002`](BUD-0002-zero-based-memory-traffic-budget.md),
  [`PWR-0001`](PWR-0001-zero-based-power-safety-envelope.md),
  [`RFQ-0001`](RFQ-0001-zero-based-rf-zoning-coexistence.md),
  [`CST-0001`](CST-0001-dated-candidate-cost-burden.md) and
  [`PKG-0001`](PKG-0001-zero-based-target-architecture-proposal.md) preserve
  useful electronic-placement arithmetic and risks.

They were reviewed for internal consistency, but not against a prior physical
product design or whole-product optimality model. None is a final prerequisite.
`SYN-3A` is one candidate among future alternatives, not the target.

## Archives

- [premature compute CAD](../../../drafts/premature-compute-cad-2026-08-16/README.md);
- [premature service CAD](../../../drafts/premature-service-cad-2026-08-16/README.md);
- [earlier legacy-derived stage 3](../../../drafts/stage3-legacy-derived-2026-08-16/README.md).

Every later artifact receives **«Проведено ревью»** only for its own reviewed
scope; no status propagates automatically to the next gate.

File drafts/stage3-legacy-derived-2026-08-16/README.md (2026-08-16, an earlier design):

# Archived legacy-derived stage-3 synthesis

- Статус: **Справочный архив**
- Дата архивации: 2026-08-16
- Причина: `FND-0033`, `DEC-0027`

Здесь сохранены полные тексты прежних demand/budget/pin/layout/score/owner artifacts. Они полезны как:

- каталог уже найденных рисков;
- набор гипотез для будущего comparison;
- отрицательные примеры implementation leakage.

Они не могут обосновывать owner, MCU, bus, pin, transport или final architecture. Активная рабочая точка — [`docs/review/architecture/README.md`](../../docs/review/architecture/README.md).

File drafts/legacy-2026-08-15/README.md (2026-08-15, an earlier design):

# Legacy documentation snapshot

This directory preserves the documentation and documentation-sync tooling that existed at the reset baseline on 2026-08-15.

Nothing here is authoritative. Do not update these files to describe the new design; use them only as research input and historical evidence.

Existing tsCircuit and KiCad files outside this directory were not moved because they are implementation artifacts. They are nevertheless considered legacy until regenerated by a reviewed stage.

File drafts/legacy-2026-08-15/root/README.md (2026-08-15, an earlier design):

# Leshy2

*Read this in: **English** · [Русский](README.ru.md)*

**An open-source, portable, multiband RF handheld — a field tool you build yourself.**

Leshy2 is the successor to [esp32-leshy](https://github.com/anton-vinogradov/esp32-leshy), a firmware fork of [ESP32-DIV](https://github.com/cifertech/ESP32-DIV). It keeps the mature ESP32-S3 as the main brain and bolts on an **ESP32-C5 co-processor** for the one thing the S3 can't do — native **5 GHz** Wi-Fi. Two chips, one field tool, in the DIV-style handheld shape, built in the open for about **$135–160** (~$108–125 in electronics).

> 🛑 **Your own gear only.** An educational security-research and radio tool. Use it only on networks, devices, and radios you own or are explicitly authorized in writing to test. Radio law differs by country — it is on you to check and obey it.

---

## 📖 How to read this README

This README is the project's **source of truth**: the pipeline from idea to finished boards, **stage by stage**. Each stage sets a **Spec** (what and why), records the **Decisions** made in it, and produces **Artifacts** (files in this repo) that become the input to the next stage — so you can read it as *spec → decisions → result* and check each step.

**Status:** ⏳ planned · 🟡 in progress · ✅ done · 🔬 reviewed (self-review passed; a later edit drops it back to ✅). Nothing is built on real hardware yet.

| # | Stage | Status |
|--:|---|:---:|
| 1 | [Why a new device](#1-why-a-new-device--vision) | 🔬 |
| 2 | [What it must do — capabilities](#2-what-it-must-do--capabilities) | ✅ |
| 3 | [Components](#3-components) | 🔬 |
| 4 | [Architecture](#4-architecture) | ✅ |
| 5 | [External design & controls](#5-external-design--controls) | ✅ |
| 6 | [Schematic sheets](#6-schematic-sheets) | 🟡 |
| 7 | [Merge, realize, review, complete](#7-merge-realize-review-complete) | 🟡 |
| 8 | [PCB layout](#8-pcb-layout) | 🟡 |
| 9 | [Firmware](#9-firmware) | ⏳ |
| 10 | [Firmware validation in emulation](#10-firmware-validation-in-emulation) | ⏳ |
| 11 | [Fabrication & bring-up](#11-fabrication--bring-up) | ⏳ |

---

## 1. Why a new device — vision

**✅ Spec.** Take [ESP32-DIV](https://github.com/cifertech/ESP32-DIV) further: keep its mature ESP32-S3 design and **broaden what the handheld can do** — first the 5 GHz Wi-Fi DIV lacks, then a wider set of on-board radios and peripherals. Concretely, support:

- **5 GHz Wi-Fi + Zigbee / 802.15.4 / Thread** — via an **ESP32-C5** co-processor (the only ESP32 with native 5 GHz).
- **Bluetooth LE** — BLE advertising flood, and the phone-typed text keyboard / companion link (both MCUs have BLE).
- **2.4 GHz raw** — 3× nRF24L01+PA/LNA (parallel scan, mousejack, jammer).
- **Sub-GHz 315 / 433 / 868 / 915 MHz** — CC1101 + an SP4T multi-band front end.
- **LoRa / Meshtastic** — SX1262 / E22-900M22S (+22 dBm).
- **Voice walkie** — SA868-U, 2 W TX/RX 433 / 446 MHz NBFM.
- **HF / CB / FM receiver + real analog audio** — Si4732 + a PAM8302 amp → speaker + a **TRRS headset jack** (headphone out + a mic ring to the SA868 walkie for hands-free) and an on-board MEMS mic.
- **GPS** — an **external M5 GPS Unit** on a Grove port (its own antenna); no on-board GPS. Plus **IR TX / RX**, **microSD** (PCAP logging).
- **2× Grove I²C** expansion for M5 Units (NFC / RFID2, RTC, IMU, sensors) + a **Grove-UART** port for the M5 GPS Unit (the S3's freed UART2).
- **2S 18650 power** with an on-board balancing boost-charger.
- **A bigger, higher-res display** — a **4.0″ 320×480 IPS** panel vs DIV's 2.8″ 240×320 (ILI9341): same SPI interface, but **~2× the area and 2× the pixels** (~2× the waterfall on screen) and IPS for wider viewing angles. Same ~143 ppi — bigger and roomier, not sharper. Plus **capacitive touch** (DIV is button-only).
- **A proper control set** — a **5-way D-pad + BACK + OPTIONS + PTT + panic STOP + F1 / F2 + an encoder wheel** (DIV's buttons are minimal); long text is typed from a phone.
- **Honest "on-air" indicators** — a per-TX-chain amber TX LED (7 chains; a passive hardware envelope detector, 0 GPIO) that shows a chain is transmitting even if the firmware hangs.

The S3 stays the brain (UI, display, all wired radios, SD, buses, 2.4 GHz Wi-Fi + BLE); the C5 is a pure 5 GHz co-processor. DIV handheld shape, fair price (~$135–160), open so people can join in.

**This peripheral wishlist is the driver for everything downstream** — it sets the capabilities (stage 2), which pick the components (stage 3), which shape the architecture (stage 4) and the physical device (stage 5).

**Decisions.**

- **Two chips, not one.** The earlier single-**ESP32-C5** plan lost to its pin crunch (20/20) — and 5 GHz is the *only* thing the C5 does better than the S3. So the **S3** (mature, ~36 GPIO, the leshy firmware already runs on it) is the brain and the **C5** is a pure 5 GHz co-processor.
- **Extend DIV, don't reinvent it.** Keep DIV's proven S3 base and the firmware lineage; bolt radios and peripherals around it rather than a clean-sheet design.
- **Draw the scope boundary here** (the *out-of-scope* list below) so the later stages don't chase full-5 GHz monitor+inject, Linux-class analytics, HF-TX, wideband SDR, cellular or jamming — chip, budget and legal limits.

**Wanted, but out of scope (and why).** Some capabilities were dropped for reasons beyond our control or because they'd blow up the budget — the boundary is set here so the later stages don't chase them:

- **Full 5 GHz Wi-Fi (monitor + injection, WPA-handshake capture, Pineapple-class).** The C5 does only Marauder-class recon (scan / deauth / beacon / probe / sniff); raw monitor+inject on 5 GHz needs a Linux Wi-Fi stack no ESP32 has. *(chip / SDK limit)*
- **On-device Linux-class analytics (aircrack-ng, Kismet, WiFi Pineapple, handshake cracking).** Would need a Raspberry-Pi-class Linux SBC bolted on — blowing up budget, size, power and battery life. The point is a lean, all-day ESP32 handheld, not a Linux box: log PCAPs to SD and crunch them on a laptop. *(budget / complexity)*
- **HF / CB / shortwave transmit.** The Si4732 is receive-only and physically cannot transmit. *(chip limit)*
- **Continuous wideband SDR capture / arbitrary TX (HackRF-class).** No wideband IQ front end — a different, far pricier class of device. *(scope / budget)*
- **Cellular / GSM.** No modem. *(cost + legality)*
- **True simultaneous multi-radio.** With nine antennas in one small volume, keying every TX chain at once desenses the receivers, so the different-band chains are time-shared (TDD arbitration in firmware); the 3× nRF24, one coordinated 2.4 GHz set, run in parallel — scan **and** multi-channel TX alike. *(RF coexistence — not the SPI bus, which sits at ~11–21 %.)*
- **Wideband jamming.** Deliberately not built — it is illegal (US §333, EU RED). *(legal — a "won't", not a "couldn't")*

**Artifacts.** This section, and the lineage it builds on:

- **[ESP32-DIV](https://github.com/cifertech/ESP32-DIV)** by CiferTech (MIT) — the hardware concept and the origin of the whole line.
- **[esp32-leshy](https://github.com/anton-vinogradov/esp32-leshy)** — the firmware predecessor (our ESP32-S3 take on DIV), which Leshy2's software ports from.

If you like this project, please star and support the original ESP32-DIV first.

---

## 2. What it must do — capabilities

**✅ Spec.** Fix the feature set the hardware has to deliver (everything for your own equipment).

**Decisions.**

- **Marauder-class Wi-Fi, not Pineapple-class.** Both bands do the useful management-frame work — scan, sniff, deauth, beacon / probe flood — because that runs on the ESP32 radio directly. Full monitor + injection (WPA-handshake capture, aircrack) needs a Linux Wi-Fi stack no ESP32 has, so we don't claim it.
- **Analog receive audio, no MCU in the path.** No ESP32 has a real DAC, so sound never touches the chip: the radio's line-out goes through an analog mux into a PAM8302 class-D amp to the speaker / headphone jack. Clean audio, and the CPU stays free for the UI.
- **Different-band chains are time-shared, not all keyed at once.** Nine antennas share one small volume, so firing every transmitter together desenses the receivers. Firmware time-shares the *different-band* chains (SA868 2 W, LoRa, CC1101, Wi-Fi). The **3× nRF24 are the parallel set** — one coordinated 2.4 GHz sub-system that runs three channels at once, both to scan the band **and** to transmit across several channels together (the leshy-style multi-channel test message / mousejack / jam).

**Artifacts.** The capability list + the frequency map below.

**Recon / attacks**
- Wi-Fi 2.4 GHz (ESP32-S3): scan, **deauth**, beacon / probe flood, sniff management frames — Marauder-class.
- Wi-Fi 5 GHz (ESP32-C5): scan, sniff, deauth, beacon / probe flood — Marauder-class on the 5 GHz band DIV never had. (5 GHz deauth is a target we'll attempt; unproven on production C5 until [bring-up](#11-fabrication--bring-up).)
- 2.4 GHz raw (3× nRF24L01+PA/LNA): parallel whole-band scan, mousejack, channel analyzer.
- Sub-GHz (CC1101): capture and replay OOK / FSK remotes on 315 / 433 / 868 / 915 MHz; RSSI activity "geiger".
- BLE advertising flood + 802.15.4 / Zigbee sniff (ESP32-C5).
- NFC (RFID2 unit over Grove): read MIFARE / NTAG.

**Listen (by voice)**
- Si4732 (receive only): CB 27 MHz, full HF / shortwave, MW / LW (AM / SSB / CW), and FM broadcast 64–108 MHz.
- SA868-U: 433 / 446 MHz NBFM voice — listen and talk.
- Real analog audio: line-out → PAM8302 class-D amp → speaker + headphone jack. The MCU is **not** in the audio path.

**Transmit**
- SA868-U walkie: talk on 433 / 446 MHz, RX and TX up to 2 W (PTT). TX power is region / licence limited.
- Meshtastic over LoRa (SX1262 / E22-900M22S, +22 dBm): encrypted text mesh at kilometer range; power caps enforced per region in firmware.

**Spectrum view**
- 4.0″ IPS TFT (ST7796, 320×480) over SPI, **capacitive touch** — a large color waterfall on hardware vertical scroll.
- 2.4 GHz raw spectrum via the nRF24 chain; sub-GHz waterfall via CC1101.
- Per-TX-chain amber TX LED (7) — a hardware envelope detector, honest "on air" even if firmware hangs, 0 GPIO.

**Aux**
- microSD (SPI) for PCAP logging · WS2812 RGB status LED + buzzer · GPS = external M5 Unit (Grove-UART) · IR TX/RX.
- **2× Grove HY2.0-4P (I²C, 3.3 V)** for M5 I²C Units (RFID2, RTC, IMU, sensors). Grove I²C Units only.
- Long text is typed on your phone (BLE / Wi-Fi) — no onboard keyboard (see stage 9).

### Frequency map

| Band | Chip | RX | TX | What you do |
|---|---|:--:|:--:|---|
| 2.4 GHz Wi-Fi + BLE | ESP32-S3 | ✓ | ✓ | scan, **deauth**, beacon / probe flood, sniff |
| 5 GHz Wi-Fi | ESP32-C5 | ✓ | ✓ | scan, sniff, deauth, beacon / probe flood |
| 802.15.4 / Zigbee + BLE | ESP32-C5 | ✓ | ✓ | Zigbee / Thread sniff, BLE adv flood |
| 2.4 GHz raw | 3× nRF24L01+ | ✓ | ✓ | whole-band scan, mousejack, analyzer |
| 315 / 433 / 868 / 915 MHz | CC1101 | ✓ | ✓ | capture / replay remotes, RSSI "geiger" |
| 433 / 446 MHz NBFM | SA868-U | ✓ | ✓ (≤2 W) | listen and talk (walkie, PTT) |
| 27 MHz CB + HF / MW / LW | Si4732 | ✓ | — | listen AM / SSB / CW and CB |
| 64–108 MHz FM | Si4732 | ✓ | — | listen to FM broadcast |
| LoRa (EU868 / US915) | SX1262 | ✓ | ✓ (+22 dBm) | Meshtastic encrypted text mesh |
| GPS L1 ~1.575 GHz | external M5 GPS Unit (Grove-UART) | ✓ | — | position / time |

**Honest limits.** 5 GHz is **Marauder-class only** (management-frame work — no full monitor + injection), all Si4732 HF is **receive-only**, and you **can't key every radio at once** (RF coexistence time-shares the chains — not a bus limit). For the full list of what's deliberately **out of scope and why** (raw 5 GHz, Linux-class analytics, wideband SDR, jamming…), see stage 1.

---

## 3. Components

**✅ Spec.** Choose the chips and modules that deliver the capabilities above, at a fair price.

**Decisions.**

- **Boost charger, not a buck or USB-PD.** The BQ25887 steps plain 5 V USB *up* to the 8.4 V a 2S pack needs, so no PD negotiation and no fragile high-voltage brick — any phone charger works. The trade-off: this chip has no power-path and no ship-mode, so a **hard master toggle is the only true off** (nothing sips the pack when it's off).
- **ST7796 on shared SPI, not AMOLED or a parallel panel.** The C5 has no `LCD_CAM` block and no spare pins for a parallel / QSPI bus, so the display shares the S3 SPI bus like every other wired part. SPI is enough because the waterfall rides the panel's **hardware vertical scroll** — per-frame writes stay tiny.
- **Wide-input bucks (MP2315) on both rails.** Both the +5 V and +3V3 bucks sit downstream of the 8.4 V BAT node, so each part must survive 8.4 V in. A 5.5 V-max part (e.g. TLV62569) would burn out there; the MP2315 takes the full 2S voltage.
- **Parts from LCSC / JLCPCB stock (assembly footprints).** Every choice is a real, in-stock, machine-placeable part rather than a datasheet ideal — so the BOM can actually be sourced and the board assembled without hand-soldering scarce chips.

**Artifacts.** The [**bill of materials & cost breakdown**](docs/bom.md) (~$108–125 in electronics) — every part, grouped by capability, with the biggest cost drivers.

---

## 4. Architecture

**✅ Spec.** Decide how the pieces connect: a two-chip topology, the shared bus and expanders, and a GPIO budget that fits this much radio.

**Decisions.**

- **S3 owns everything wired; the C5 owns the whole 2.4 / 5 GHz + IR block.** All the wired radios, buses, SD, the display and native 2.4 GHz Wi-Fi hang off the S3 brain; the C5 handles 5 GHz Wi-Fi and Zigbee / 802.15.4 **and drives the 3× nRF24 and the IR** (see [stage 5](#5-external-design--controls)). There is no RF mode-switch to hand a shared antenna between chips, so splitting the radio work any other way would need parts and pins the board does not have.
- **Quad PSRAM, not octal.** Octal PSRAM would eat GPIO35–37; quad frees those three pins for the chip-to-chip link. GPIO33/34 are not broken out on the WROOM module, so the C5's EN line moves onto a PCA9555 expander instead of costing an S3 pin (the C5 needs no BOOT line — its native USB auto-enters download).
- **The chip-to-chip link is SPI3 + DRDY, not UART.** A dedicated SPI3 bus with a data-ready strobe keeps the C5 a clean SPI slave off the shared bus and gives real bandwidth for scan results; the C5 flashes over its own USB-C and takes firmware updates as OTA over the link (the old S3→C5 UART bridge is dropped, freeing two C5 pins for the nRF / IR).
- **Expanders and a decoder beat the pin crunch.** The S3 is a full 36/36 chip, so ~30 slow signals (radio/display control, rail gates, UI buttons) go onto three I²C PCA9555 expanders at zero host pins, and one 74HC138 turns 3 pins into 8 chip-selects. Only timing-critical lines (encoder A/B, interrupts) keep direct S3 pins.
- **No standalone display on the C5.** Driving the panel from the C5 in a "C5-only" mode needed fragile Hi-Z and strapping-pin discipline on the shared bus for a low-value feature. Dropping it makes the C5 a pure co-processor and keeps the display firmly on the S3.
- **The design is two boards (see [stage 5](#5-external-design--controls)).** Logically the S3 is still the brain and drives every wired radio; physically it is a two-board clamshell — the **C5 board** carries the C5, its 5 GHz antenna, the **3× nRF24 and the IR** (all C5-driven) and their antennas, plus the power; the **main board** carries the S3 and everything else. Only the **SPI3 link + power** cross the board-to-board mezzanine — every radio stays local to its board, so no radio SPI crosses.
- **Diagram conventions (system diagram).** The [system diagram](docs/img/system-diagram.svg) is theme-aware (light / dark), kept in sync with these decisions (it must show the two-board split), and redrawn whenever the architecture changes — the same discipline as the [stage-5 mockup conventions](#5-external-design--controls).

**Artifacts.** [system diagram](docs/img/system-diagram.svg) · [pin budget](docs/pin-budget.md) · [full hardware breakdown](docs/hardware.md).

Leshy2 system architecture

- **Two chips.** **ESP32-S3-WROOM-1U-N8R2** (dual-core, quad PSRAM) is the **main brain** — UI, display, all wired radios, SD, every bus, native 2.4 GHz Wi-Fi + BLE. **ESP32-C5-WROOM-1U** is a **pure co-processor** — the only ESP32 with native 5 GHz — on its own dual-band antenna.
- **Chip-to-chip link:** a dedicated **SPI3 + DRDY** strobe (the C5 is a clean SPI slave; it never touches the shared bus). The C5 flashes over its own USB-C and takes OTA over the link — brick-safe.
- **Shared bus (S3 FSPI):** microSD + CC1101 + SX1262 + the display — chip-selects via a 74HC138. Three I²C **PCA9555** expanders carry the slow lines (radio/display control, rail gates, and the UI buttons); interrupts stay on direct pins. (The 3× nRF24 leave this bus for the C5's own SPI — stage 5.)
- **Display:** the ST7796 **4.0″ 320×480 IPS** panel is on that shared SPI — the C5 has no `LCD_CAM` and there are no spare pins for a parallel / QSPI panel, so SPI it is; the waterfall rides the panel's **hardware vertical scroll** to keep per-frame updates tiny. The panel's **capacitive touch** rides the shared I²C bus (INT on the UI expander U14 — no host pin), a complement to the physical controls.
- **Human interface, split by board.** The **S3 reads the front controls** — the D-pad + BACK / OPTIONS — through a **PCA9555** (slow lines, 0 host pins). The **encoder, F1 / F2 and PTT / panic-STOP sit on the C5 board** ringing the battery (stage 5); the **C5 reads them locally** — the encoder's A/B quadrature on its own GPIO — and relays their state to the S3 over the link, freeing the S3's two encoder pins and those button lines.
- **9 antennas** — split five and five across the two boards (stage 5): **five on the main board** (S3 2.4, CC1101, SA868, LoRa, Si4732), **four on the C5 board** (3× nRF24 + C5 5 GHz) + **IR**, the nRF spread for isolation. Each chain has its own removable board-mounted SMA. (GPS is off-board — an external M5 Unit with its own antenna.)
- **Two USB-C:** J1 → S3 (charge + data), J2 → C5 (data-only); both mount on the C5 board's inner face (stage 5). The pack charges only through J1.
- **Power:** 2× 18650 in 2S — **BQ25887 boost charger** (charges 2S from plain 5 V USB), MP2315 +5 V and +3V3 bucks, a TPS7A2033 +3V3 analog rail, rail gates that cut idle radios. A hard master toggle is the only on/off.

One radio runs at a time, so the shared bus and slow control lines fit the pin budget.

---

## 5. External design & controls

**✅ Spec.** From the components, settle the **physical device**: a **two-board clamshell** (DIV-inspired), the control scheme, where the external interfaces sit, how the antennas split across the two boards, the mounting, and the mechanical stack — display + controls on the outer front, 2× 18650 on the outer back, all electronics protected on the inner faces. ~75 × 150 mm per board.

**Decisions.**

- **Two boards in a clamshell, split by role.** Both boards face their components inward; the outer faces carry the display + controls (front) and the battery pack (back) — plus each board's antenna SMA at the top — so the electronics live protected in the gap. The **S3 main board** holds the S3, the wired radios (CC1101 + SP4T, SA868, LoRa, Si4732 + audio), the display, microSD, the buses and every user control; the **C5 board** holds the C5 and the whole **2.4 / 5 GHz + IR radio block** — its 5 GHz, the 3× nRF24 and the IR — plus the charger, power and battery. Each board keeps its own radios local, so the board-to-board connector stays thin (below). ~75 × 150 mm per board.
- **Antennas by board — five and five, on the outer faces (DIV-style).** The **S3 main board** carries five removable SMA — Wi-Fi 2.4, CC1101 (sub-GHz), SA868 (UHF), LoRa, Si4732 (HF/CB/FM, + telescopic whip); the **C5 board** carries four — 3× nRF24 + the C5 dual-band 5 GHz — plus **IR**. (GPS is off-board — an external M5 Unit carries its own antenna.) This splits the 2.4 GHz cluster — Wi-Fi with the S3, the three nRF with the C5 — for real isolation. The SMA **mount on the outer faces, at the top, whips up** — the inner faces are full of electronics, so (exactly as on the DIV) mounting the antennas outside is the only way they fit; the radios reach them by short u.FL pigtails. Because the main bank sits on the **front** outer face and the C5's on the **back**, the two land on **opposite outer faces and cannot collide**. The three nRF sit on a **5-slot grid with one slot skipped** — at the extremes + centre, maximally spread — and every SMA clears the corner mounting holes; the **IR (TX emitter + RX receiver) sits on the C5 board's side edge**, not the top.
- **The C5 drives its own radios — the 3× nRF24 and the IR, not just hosts them.** The C5 owns the whole 2.4 / 5 GHz + IR block: it runs the nRF24 (2.4 raw — scan, ESB sniff, mousejack, multi-channel TX) and the IR TX/RX (38 kHz) on its own GPIO, and the S3 commands it over the link. Every radio line stays local to its board (thin mezzanine) and the S3's 36/36 is relieved — the nRF CE/IRQ, including the GPIO46 strap, and the IR pins all leave the S3. Cost: the C5 is native ESP-IDF, so these get **native drivers** (RMT is the idiomatic IR path on IDF; the nRF24 is an SPI-register port) rather than the Arduino RF24 / IRremote borrows the S3 would have had for free, and the link protocol grows nRF / IR opcodes (the link **pins** do not change). It fits the C5's pins once the S3→C5 UART flash bridge is dropped — the C5 flashes over its own USB-C — leaving ~2–3 spare (nRF: SPI 3 + shared CE 1 + combined IRQ 1 + CS via a 74HC139 2 = 7; IR TX/RX 2).
- **The display stays on the S3, driven directly.** Routing pixels S3 → link → C5 → panel adds a hop and fights the C5's 5 GHz stream — slower, not faster — and both S3 SPI hosts are taken (SPI2 = wired radios, SPI3 = link), while 8080-parallel would cost 11–20 pins the 36/36 budget can't spare. So SPI2 + DMA + dirty-rect is the pin-optimum: the display costs **2 direct pins** (DC + TE); SCK/MOSI ride shared SPI2, CS via the 74HC138, RST on a PCA9555.
- **Mezzanine: the link + power only — thin.** With every radio local to its board, only the **SPI3 link** (SCK/MOSI/MISO/CS/DRDY), the **power rails** (VBAT / 3V3 / GND), **C5_EN** (the S3 resets the C5) and the **J1 USB data** (S3 flashing / console, 2 lines) cross the board-to-board connector — of the order of a dozen lines, kept short with interleaved grounds. No radio SPI crosses; I²C, the display and every radio's SPI stay local to their board.
- **User controls — the display face plus the battery ring; only service parts go inside.** What the operator presses stays reachable: the **outer front** carries a real **centred 5-way D-pad** — a proper navigation switch, drawn as one, not loose keys — with **BACK + OK + OPTIONS on one line** beside it, the **TX-live LED row + RGB status**, and nothing else. The **encoder, F1 / F2 and PTT / panic-STOP ring the battery on the C5 outer back** (encoder above, F1 / F2 left, PTT / STOP right) — **face buttons, read locally by the C5**. The **3.5 mm TRRS jack** (above the **2× Grove**) sits on the main inner **right** edge, the **mic** centred on the main inner **bottom** edge, and the **round speaker** centred on the C5 inner face — the jack and the C5's IR fold onto **opposite** device side edges, so neither shares a case slot. Every TX-capable chain shows its **amber TX-live LED** (hardware envelope detector). Buttons ride a PCA9555; the encoder A/B are on direct GPIO for clean quadrature. Capacitive touch is an addition, never the only way in.
- **Connectors and service parts on the inner faces, reached through edge slots.** The outer faces stay clean (display front, battery back), so **both USB-C, the master switch and the recovery buttons mount on inner faces** and poke out through slots in the case edge. The **master switch is a slide / toggle** (SPDT, latching — not a momentary push): flick it through the edge slot. The two USB-C and the master switch sit on the **C5 board's inner face**; the S3's RESET / BOOT stay on the **main board's inner face** (they must reach the S3), so J1's USB data reaches the S3 across the mezzanine (flashing / console only).
- **Batteries on the outer back; a 3-pin connector on the board.** A **plain** 2× 18650 plastic holder on the C5 board's outer face — cells clip straight in and out, no separate lid (open frame, DIV-style) — a keep-out with no parts under the cells; it wires to a 3-pin `BT1` (P+ / mid / P−).
- **Four corner mounting holes; boards ~75 × 150 mm; the gap clears the inner parts.** M2.5 holes at the four corners of both boards; standoffs between them set the mezzanine gap and carry the display and battery loads. **Board size: ~75 × 150 mm each, ~36 mm total thickness (11 mm gap + 18.6 mm battery + boards + display)** (the 18650 pack is the thickest outer layer). The standoff height (the mezzanine gap) is **no shorter than the DIV's, and no shorter than the tallest inner-face component** — the 3× nRF24 modules, mounted **low** (DIV-style, soldered / short pins, **not** on tall 2×4 sockets), are the tallest at **~5–7 mm**, so the gap follows a fixed **11 mm gap** (measured on the DIV); the two boards' inner parts must never collide (`h_A + h_B ≤ gap` at every point).
- **Recovery buttons: both chips get RESET + BOOT.** Each MCU carries **RESET + BOOT** on its board's bottom edge (pinhole). The C5's native USB-Serial-JTAG usually auto-enters download over its own USB-C, but a physical **BOOT** forces it when firmware hangs or reconfigures the USB pins — and the C5 runs the most experimental firmware (5 GHz / nRF / IR), so it needs that recovery path as much as the S3. The button costs **no host pin** (it just pulls the download-strap low). This is separate from the dropped S3→C5 `C5_BOOT` *line* (that drove UART flashing, which is gone).
- **Mockup drawing conventions — see the dedicated [layout spec](docs/layout-spec.md).** The render is generated by a [script](docs/img/leshy2_layout.py) to a fixed, detailed spec — a stage-5 artifact of its own: board sizes, the **mirror rule** (inner faces are back views), **interface (blue) / component (grey)** colouring with **teal silkscreen labels** for what is printed on the board, **real datasheet footprints**, fixed placement — board · face · edge · direction — of every **interface**, while internal **components** sit in a per-board **area** (positioned in stage 8), plus seven automated checks (overlap, accessibility, arrow-on-label, mezzanine gap, mounting-hole clearance, the **cross-board clamshell fold** — the C5 board seats X-mirrored, so the two boards' side-edge connectors must not fold onto the same case slot — and the **mezzanine mate**, both board-to-board halves at matching device coords). The generator **refuses to write** a render that fails any check. **These rules bind the physical PCB layout too, not just the render**; when they disagree, the spec wins.

**Artifacts.** [**clamshell layout**](docs/img/layout-clamshell.en.svg) · [**controls & firmware conventions**](docs/firmware-controls.md).

Leshy2 two-board clamshell layout — all four faces, external interfaces and mounting holes

**External interfaces & important components, by face:**

- **Main board (S3) — outer front:** 4.0″ (320 × 480 portrait) capacitive-touch display + a **centred 5-way D-pad** with **BACK + OK + OPTIONS on one line**; the **7 TX-live LEDs** (3× nRF, CC1101, SA868, LoRa, IR) spread across the width **+ RGB status**; **five antenna SMA across the top** (Wi-Fi 2.4, CC1101, SA868, LoRa, Si4732, whips up). The controls, speaker and mic are **not** here — they are on the C5 board / inner faces. Only what you look at or press lives on the front. 4 corner mounting holes.
- **Main board (S3) — inner:** ESP32-S3 + the wired radios (CC1101 + SP4T, SA868, SX1262 / LoRa, Si4732 + audio) + the buses (74HC138, 2× PCA9555) + display driver; **the connectors sit here on the inner face, at the edges** — 3.5 mm jack + 2× Grove I²C stacked on the **right** edge (jack on top), the **mic** centred on the bottom edge (microSD to its left, `RESET` / `BOOT` to its right), and microSD + `RESET` + `BOOT` (bottom edge) — reached through case slots; **u.FL pigtails up to the five outer SMA**; the mezzanine connector.
- **C5 board — inner:** ESP32-C5 + the **C5-driven 3× nRF24** (+ 74HC139 for their CS) + a PCA9555 + the charger and power (2× buck, LDO, S-8252A protection) — all inside a single **component area** (positioned in stage 8); the **round speaker** (lower) and the **IR TX + IR RX on the right side edge** (firing into the gap, DIV-style); **the bottom edge carries both USB-C, the master slide, `C5 RESET` and `C5 BOOT`**; the mezzanine connector.
- **C5 board — outer back:** the plain 2× 18650 holder (~40 × 78 mm, keep-out, no parts under cells) **ringed by the controls — encoder above, F1 / F2 left, PTT / panic-STOP right** (face buttons, C5-read) — plus `BT1`; **four antenna SMA across the top** (3× nRF24 + C5 5 GHz, whips up) on a **5-slot grid with one slot skipped so the nRF are maximally spread**. 4 corner mounting holes.

The physical set is sufficient by a [scenario-coverage review](docs/firmware-controls.md); most of the usability lives in firmware conventions (stage 9).

---

## 6. Schematic sheets

**✅ Spec.** Capture each subsystem as its own sheet, transcribed from the architecture — as design docs **and** as live [tscircuit](https://tscircuit.com) code (real parts, LCSC numbers, exports to KiCad).

**Decisions.**

- **Schematic as code, not hand-drawn KiCad.** Each subsystem is one tscircuit `.tsx`; the schematic, PCB, netlist and KiCad export are *generated* from it — nothing is drawn by hand. So the source of truth is one file per sheet, edits regenerate every view, and connectivity is proven by netlist rather than by how a drawing looks.
- **Real footprints from the parts engine, not hand-entered pins.** Every IC pulls its manufacturer-verified footprint and pin names from its LCSC number (`jlcpcb:C…`); pins are never typed by hand. An early hand draft had wrong pin assignments — letting the engine own the pinout kills that whole class of error.
- **One sheet per subsystem.** Six sheets (power / buses / RF / audio / expansion / indicators) split along the architecture, so each is small enough to review on its own before the whole board is merged.
- **Realize against real modules to surface hidden blockers.** Drawing on the actual parts catches problems the logical schematic can't see: the C5's GPIO33/34 aren't broken out (so those control lines move onto a PCA9555 expander), the charger is a boost topology, and the sub-GHz SP4T needs three control lines, not one.

**Artifacts.** Six sheets — each a design doc in its own `hardware/<sheet>/` folder (linked below), with the live tscircuit `.tsx` and the exported schematic SVG in [`hardware/tscircuit/`](hardware/tscircuit/):

1. [Power](hardware/power/power.md) — 2S, BQ25887 boost charger, rails, master toggle
2. [MCU + buses](hardware/c5-buses/c5-buses.md) — S3 + C5, the SPI3 link, 74HC138, PCA9555, USB
3. [RF chains](hardware/rf/rf.md) — 3× nRF24, CC1101 + SP4T, SX1262 (LoRa)
4. [Audio](hardware/audio/audio.md) — Si4732, SA868, analog path → PAM8302
5. [Expansion](hardware/expansion/expansion.md) — I²C Grove + Grove-UART (external M5 GPS Unit)
6. [Indicators / IO](hardware/indicators/indicators.md) — TX-live LEDs, IR clone/replay, microSD, encoder

🔄 **Re-netlist for the C5-drive split (per [§4](#4-architecture)).** The RF, buses and indicators sheets still show the **S3** driving the 3× nRF24 + IR, but the decision is that the **C5 drives them**. Rework: **`rf.tsx`** — the 3× nRF24 onto the C5's own SPI + a 74HC139 for CS, CE/IRQ on C5 GPIO; **`c5-buses.tsx`** — IR TX/RX + nRF CE/CSN/IRQ on C5 GPIO, drop the UART flash-bridge (`C5_FLASH_TX/RX`) + `C5_BOOT` (the C5 flashes over its own USB-C + OTA), mezzanine = SPI3 + power + `C5_EN`; **`indicators.tsx`** — the IR TX/RX and the C5/nRF TX-live detectors move to the C5 half. The sheets catch up to the already-final [`docs/pin-budget.md`](docs/pin-budget.md) (S3 30/36, C5 ~17/20). The stale `rf` / `c5-buses` schematic exports were **dropped**; the hand-drawn `hardware/kicad/` skeleton was **dropped** too — the tscircuit `.tsx` is the only source of truth.

> **How to (re)obtain a sheet:** edit its `.tsx`; pull the real footprint + pin names via `footprint="jlcpcb:C…"` (never hand-type pins — an early hand draft had wrong pins); regenerate its `schematic.svg` + `kicad_pcb` with the `package.json` scripts; prove connectivity only by netlist parity / `kicad-cli drc`, never by how it drew. Realizing against the **real module footprint** catches bonding bugs the logical schematic can't (the S3-WROOM-1U has no GPIO33/34 pads → `C5_EN`/`BOOT` moved to a PCA9555).

---

## 7. Merge, realize, review, complete

**🟡 Spec.** Realize the six sheets on real, manufacturer-verified parts, review adversarially, and finish the missing pieces so the schematic is complete before layout. 🔄 **Per [§5](#5-external-design--controls) the design is being re-split into two boards (front + back); the single-board merge described below predates that and is being reworked for the split.**

**Decisions.**

- **`board.tsx` is generated, not hand-merged.** `merge.py` assembles it from the six sheets + `integration.tsx`, so the sheets stay the single source of truth (edit a sheet, re-run the merge). A parts+nets diff-guard proved the generated board byte-identical to the hand-merged one it replaced — no silent drift when a sheet changes.
- **Review adversarially, before finishing.** Two whole-board self-reviews plus a per-sheet artifact pass ran *before* the completion work — they caught a real blocker (the PCA9555 has **no** internal pull-ups, so every switch input floated) and 5 major issues, all fixed. Cheaper to find on the schematic than at bring-up.
- **Antennas are removable board-edge SMA, distributed across the two boards.** Per [§5](#5-external-design--controls) the nine jacks split **five (front board) / four (back board) + IR** around both top edges — spreading the radios and the 3× nRF24 for isolation instead of nine on one edge. (GPS is off-board — an external M5 Unit with its own antenna.)
- **Part swaps chosen by real stock + margin.** A 4 A PPTC (thermal headroom over the draw), a 20 mm on-board speaker, an LC balun into each SP4T arm, **two single 18650 holders** (to expose the pack mid-point the BQ25887 needs for balancing), and one 5-way nav switch under the D-pad — pick parts that are in stock and leave slack, not the tightest fit.
- **No blind edits — defer what needs measuring.** The Si4732 RCLK load-cap count is left as-is and flagged for an AN383 check at bring-up, rather than guessing a value on paper.

**Artifacts.** The single-board `board.tsx` + its `board.kicad_pcb` / placement / routing were **dropped** (single-board topology, dead per the clamshell split). [`merge.py`](hardware/tscircuit/merge.py) + [`integration.tsx`](hardware/tscircuit/integration.tsx) + the six sheet `.tsx` stay.

> **How to (re)obtain the board — as two boards.** `board.tsx` is *generated* (`merge.py`), never hand-edited. Re-split `integration.tsx` for the clamshell (5 SMA on the main top + 4 on the C5 top + IR on the C5 side, not nine on one edge) and rework `merge.py` to emit **two `<board>`s** — one per physical board (main-S3, C5) — keeping the refdes-collision resolver (`U20 → m_U20/rf_U20`). Export the netlist with a **relative** `-o` path, in the background (~2-4 min); acceptance is `schematic_parity = 0` (`unconnected` = ratsnest, **not** a defect); never commit `.kicad_sch` (broken export, 319 ERC). Adversarial multi-agent review still catches what DRC can't (BQ25887 = boost charger with a separate `SNS`; ESD arrays common-cathode to **+3V3** not GND; PAM8302 needs input coupling caps; PCA9555 has **no** internal pull-ups → 14× 10k; J2 USB-C needs CC 5.1k). eFuse `set_flash_voltage 3.3V` de-straps GPIO45.

Done:

- **✅ Merge** — `board.tsx` is *generated* from the sheets (single source of truth: edit a sheet or `integration.tsx`, then re-run `merge.py`). A parts+nets diff-guard proves it byte-identical to the hand-merged board it replaced.
- **✅ Realize** — every IC / module / connector rides a real LCSC footprint (tscircuit parts engine); only mechanical placeholders stay geometric.
- **✅ Review** — two adversarial whole-board self-reviews + a per-sheet artifact review (electrical + `.md`↔`.tsx`). Confirmed defects fed the fixes below.
- **✅ Electrical fixes (review)** — pull-ups on every PCA9555 switch input (10 UI buttons + encoder / card-detect / jack-detect / PTT — the part has **no** internal pull-ups); **J2 CC 5.1 kΩ** (C5 flash-over-USB); a pull-up on the wired-OR `PCA9555_INT`; **local decoupling** (100 nF per IC/module power pin + bulk); ~1 kΩ base resistors on the buzzer / IR drivers. TX-live LEDs set to minimal power (10 kΩ, ~0.1 mA). `.md`↔`.tsx` wording synced; netlist verified clean.

Remaining (🟡) — the completion list:
- **Part swaps (placeholder → real).** TVS/ESD, PPTC fuse, electret mic, speaker, buzzer, 3.5 mm jack, an 18650 holder with a reachable mid-point (the BQ25887 balances the 2S pack), RF balun, per-band matching networks, and one 5-way nav switch under the D-pad.
- **Stage-3 sub-circuits to draw.** The 7 RF envelope detectors (TX-live LEDs), the backlight driver (+ PWM dim), the Si4732 HF PIN-limiter.
- **Fab-verify.** "Confirm at layout / bring-up" items: Grove pin-1 orientation, supercap polarity / inrush, Si4732 bus-mode strap **and RCLK load-cap count** (AN383 — why the crystal cap wasn't blindly changed), boot-state pull-downs.

*Detail lands here as each item is done.*

---

## 8. PCB layout

**🟡 WIP.** Place the complete board (edge-aware zones, two-sided) on a 4-layer stack with a GND plane, route it (auto + hand-RF), add the mechanical → gerbers. *Detail is filled in as this stage is worked.*

**Decisions.**

- **Autoroute with Freerouting, not the earlier tool.** The earlier router stalled at ~45 % of the nets; Freerouting reached 85 % in one pass and 424/425 nets through a Specctra DSN/SES pipeline — so it does the bulk of the copper and leaves only the hard cases for hand-finishing.
- **4-layer stack with a solid GND plane (In1 = GND).** A dedicated ground layer gives short, clean return paths and one stable reference for the many radios — something a 2-layer board cannot hold on a device this dense.
- **RF feeders routed by hand.** The antenna feed lines need controlled impedance, coplanar geometry and antenna keep-outs, which an autorouter cannot honour — so the RF traces are drawn manually while Freerouting handles the rest.
- **Edge-aware placement.** Each connector sits on the edge it must reach and the antenna bank goes to the top — so cables and pigtails leave cleanly and the radios stay away from the digital noise.

**Artifacts (regenerate).** The single-board `board-placed*` / `board-autorouted` / 4-layer files were **dropped** (single-board topology).

> **How to (re)obtain — two boards, each placed + routed separately.** Edge-aware placement (each connector on the edge it exits, antenna bank on top), 4-layer with a solid GND plane (In1 = GND; **In2.Cu must be `signal`, not `power`**, or Freerouting treats it as an empty plane and loses the layer). Route headless: Temurin **JDK 25** + **Freerouting 2.3.0** for signals/RF, then `route.py` plane-finalize (obstacle-aware GND-pad → polygon; a blind via straight into a GND pad = short — don't). DSN/SES via KiCad `pcbnew`-python; **FILL the zones before exporting the DSN**; RF feeders by hand (controlled impedance, antenna keep-outs). The two **mezzanine halves must mate** at matching device coordinates. Fab: JLCPCB into RU via a re-exporter (jlcpost.ru) or Rezonit; keep parts in LCSC stock.

---

## 9. Firmware

**⏳ WIP.** The firmware has its own repo — **[esp32-leshy2-firmware](https://github.com/anton-vinogradov/esp32-leshy2-firmware)** (same doc-first paradigm). Design it fresh from this device's capabilities, write the C5 5 GHz agent + the S3↔C5 protocol, implement the [control conventions](docs/firmware-controls.md) + the two safety blockers, and reuse working code from leshy and other open-source where it fits. *Detail is filled in as this stage is worked.*

**Decisions.**

- **Design fresh from this device's capabilities; reuse code per capability, not wholesale.** esp32-leshy was the proof that rolling your own firmware is easy — but it hit the ceiling of ESP32-DIV's fixed hardware, which is exactly why Leshy2 exists. So the firmware is built on our own terms now: top-down from a capability tree → a firmware tree, not from leshy's skeleton. For each capability we look at how open-source analogues solve it and decide — borrow the code, write it fresh, or take only the idea. Ports of leshy code are welcome and likely; leshy just doesn't dictate the structure.
- **The C5 is a thin 5 GHz agent behind a narrow S3↔C5 protocol.** The S3 stays the brain and owns the UI; the C5 only does 5 GHz recon and answers a small command/event link over SPI3 + DRDY — keeps the two codebases decoupled and the C5 easy to bring up or replace on its own.
- **Orderly shutdown is a firmware feature, not the master switch.** The switch cuts the pack instantly (no ship-mode), so an in-flight PCAP / log would corrupt; **OPTIONS → Shut down** (and a long-BACK) flushes SD, parks all radios, stops S3 + C5, then shows a "safe to flip" screen.
- **long-BACK / STOP kills all TX, over any screen.** A stuck transmit (deauth, beacon spam, latched PTT, nRF24 / CC1101 / LoRa jam) with a hung UI must stop without pulling power; one core handler — reached from the hardware STOP key or a long-BACK — stops every chain.
- **Long text is typed on a paired phone over BLE.** There's no room for an onboard keyboard; a BLE companion is the primary path (keeps Wi-Fi free during attacks), a Wi-Fi captive portal is the app-less fallback, and the D-pad char-wheel stays for short offline entry.

---

## 10. Firmware validation in emulation

**⏳ WIP.** Run the test firmware on emulators before committing copper — catch logic, driver, UI and link-protocol bugs while a fix still costs an edit, not a fab spin. *Detail is filled in as this stage is worked.*

**Decisions.**

- **Emulate the firmware before the board, in three free open layers.** **ESP-IDF Linux host-target + CMock** for driver and protocol unit tests in CI (the main layer, no hardware); **Wokwi** (with the headless `wokwi-cli`) for the on-screen UI and the SPI / I²C / UART buses; **Renode** (or the **Espressif QEMU fork**) to boot the real S3 binary and, in Renode, run S3 + C5 as two linked nodes. All three are open and scriptable in CI.
- **Emulation covers the digital half only — draw that line honestly.** It validates firmware logic, the ST7796 UI, register-level drivers (nRF24 / CC1101 / SX1262 / Si4732 / PCA9555), NMEA parsing and the S3↔C5 frame protocol. It does **not** touch RF physics, analog audio, power / charging, dense-SPI2 timing or the C5's 5 GHz radio — those stay on real hardware (stage 11).
- **No emulator ships our radios — we write them as behavioural stubs.** None of Wokwi / QEMU / Renode has nRF24 / CC1101 / SX1262 built in; each is a self-written SPI / I²C chip that answers the registers the driver actually pokes (CONFIG / STATUS / FIFO, the IRQ line). That proves the *driver*, not the over-the-air link — a virtual "packet arrived" is not a real RF channel.
- **The C5 is emulated as firmware logic only.** It is alpha in Wokwi and absent from QEMU / Renode, and its 5 GHz radio isn't modelled anywhere — so its command / state logic runs against a stub, and the real 5 GHz proof waits for bring-up (stage 11).
- **This replaces the old 5 GHz pre-fab gate.** 5 GHz physics can't be emulated and there is no budget plan B, so proving 5 GHz moved to bring-up on the real board (stage 11). This stage keeps the "prove it cheaply before copper" slot but aims it at what emulation *can* check — the firmware.

---

## 11. Fabrication & bring-up

**⏳ WIP.** Order (JLCPCB via a reshipper, or Rezonit), assemble, bring up (incl. the C5 5 GHz proof), tune antennas on a VNA. *Detail is filled in as this stage is worked.*

**Decisions.**

- **Prove the C5's 5 GHz here, on the real board — not as a pre-fab gate.** Emulation can't touch 5 GHz and there is no other 5 GHz part in budget, so the deauth / recon question is answered at bring-up. A miss only trims the C5 to passive recon (2.4 GHz deauth still runs on the S3) — it costs the C5 subsystem, not the board.
- **Fab at JLCPCB through a reshipper, Rezonit as the fallback.** JLCPCB has no direct shipping to Russia, so the board goes via a reshipper (jlcpost-class); the JLC7628 4-layer stack and its in-house assembly are the cheapest way to get the impedance-controlled RF board built. Rezonit is the domestic Plan B if the reshipper route stalls.
- **Keep every part in LCSC stock.** The BOM is pinned to parts JLCPCB can actually place from the same catalog it fabs on — no chasing unobtainable substitutions mid-order, no hand-soldering surprises. Procurability wins over the "perfect" part.
- **Tune every antenna by hand on a VNA at bring-up.** Nine antennas share one small volume and each RF chain has its own match net; that interaction can't be simulated cleanly, so the match is trimmed on real hardware with a VNA rather than trusted to the layout.
- **Plan for two spins, not one.** Budget and schedule assume one working spin plus one refinement spin — an honest RF-board expectation, so the first order isn't treated as final copper. See [roadmap](docs/roadmap.md).

---

*Get involved: [CONTRIBUTING.md](CONTRIBUTING.md).*

## License

[MIT](LICENSE) — same as upstream ESP32-DIV. Copyright © Anton Vinogradov ([anton-vinogradov](https://github.com/anton-vinogradov)).

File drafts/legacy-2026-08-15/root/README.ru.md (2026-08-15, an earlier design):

# Leshy2

*Читать на: [English](README.md) · **Русском***

**Открытый портативный многодиапазонный РЧ-наладонник — полевой инструмент, который ты собираешь сам.**

Leshy2 — преемник [esp32-leshy](https://github.com/anton-vinogradov/esp32-leshy), прошивочного форка [ESP32-DIV](https://github.com/cifertech/ESP32-DIV). Сохраняет зрелый ESP32-S3 как главный мозг и добавляет **сопроцессор ESP32-C5** ради того, чего S3 не умеет — нативного **5 ГГц** Wi-Fi. Два чипа, один полевой инструмент, в форме наладонника DIV, разрабатывается открыто, примерно за **$135–160** (~$108–125 электроники).

> 🛑 **Только своё железо.** Учебный инструмент для security-research и радио. Используй только на сетях, устройствах и радио, которыми владеешь или на тест которых есть письменное разрешение. Радиозакон различается по странам — проверять и соблюдать его на тебе.

---

## 📖 Как читать этот README

Этот README — **источник истины** проекта: конвейер от идеи до готовых плат, **этап за этапом**. Каждый этап задаёт **Постановку** (что и зачем), фиксирует принятые **Решения** и рождает **Артефакты** (файлы в репо), которые становятся входом следующего этапа — так это читается как *постановка → решения → результат*, и каждый шаг можно чекать.

**Статус:** ⏳ запланировано · 🟡 в работе · ✅ сделано · 🔬 отревьюено (саморевью пройдено; любая правка после — обратно на ✅). На реальном железе пока ничего не собрано.

| # | Этап | Статус |
|--:|---|:---:|
| 1 | [Зачем девайс](#1-зачем-девайс--vision) | 🔬 |
| 2 | [Что умеет — возможности](#2-что-умеет--возможности) | ✅ |
| 3 | [Компоненты](#3-компоненты) | 🔬 |
| 4 | [Архитектура](#4-архитектура) | ✅ |
| 5 | [Внешний вид и управление](#5-внешний-вид-и-управление) | ✅ |
| 6 | [Листы схемы](#6-листы-схемы) | 🟡 |
| 7 | [Свод, реализация, ревью, достройка](#7-свод-реализация-ревью-достройка) | 🟡 |
| 8 | [Разводка PCB](#8-разводка-pcb) | 🟡 |
| 9 | [Прошивка](#9-прошивка) | ⏳ |
| 10 | [Валидация прошивки в эмуляции](#10-валидация-прошивки-в-эмуляции) | ⏳ |
| 11 | [Изготовление и bring-up](#11-изготовление-и-bring-up) | ⏳ |

---

## 1. Зачем девайс — vision

**✅ Постановка.** Развить [ESP32-DIV](https://github.com/cifertech/ESP32-DIV): сохранить его зрелый дизайн ESP32-S3 и **расширить, что умеет наладонник** — сначала 5 ГГц Wi-Fi, которого у DIV нет, затем более широкий набор бортовых радио и периферии. Конкретно — поддержать:
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

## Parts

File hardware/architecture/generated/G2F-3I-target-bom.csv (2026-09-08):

scope | device_id | mpn | quantity | lifecycle | qualification | orderable_evidence | cost_evidence | cost_currency | cost_target_quantity | unit_price_usd | line_material_usd | cost_price_break | cost_source | cost_checked | cost_gate_status | cost_gate_reason | cost_gate_source | cost_gate_checked | alternate_evidence | alternate_policy_class | placements
base_product | abracon_abm8_26mhz_10_d_1_g_t | Abracon ABM8-26.000MHZ-10-D-1-G-T | 1 | active_orderable | verified_exact_cc_reference_crystal | present | present | USD | 100 | 0.3257 | 0.3257 | DigiKey cut-tape quantity-100 tier | https://www.digikey.com/en/products/detail/abracon-llc/ABM8-26-000MHZ-10-D-1-G-T/9997912 | 2026-08-19 |  |  |  |  | present | SUB-RF | cc_crystal
base_product | abracon_abm8_272_t3 | Abracon ABM8-272-T3 | 1 | active_orderable | verified_exact_rp2350_reference_crystal | present | present | USD | 100 | 0.4085 | 0.4085 | DigiKey cut-tape quantity-100 tier | https://www.digikey.com/en/products/detail/abracon-llc/ABM8-272-T3/22472366 | 2026-08-23 |  |  |  |  | present | SUB-RF | rp_clock
base_product | abracon_aota_b201610s3r3_101_t | Abracon AOTA-B201610S3R3-101-T | 1 | active_orderable | verified_exact_rp2350_reference_regulator_inductor | present | present | USD | 100 | 0.1512 | 0.1512 | DigiKey cut-tape quantity-100 tier | https://www.digikey.com/en/products/detail/abracon-llc/AOTA-B201610S3R3-101-T/25621527 | 2026-08-23 |  |  |  |  | present | SUB-PWR-PASSIVE | rp_vreg_inductor
base_product | adi_ad8314acpz_rl7 | Analog Devices AD8314ACPZ-RL7 | 6 | production_active_orderable | verified_exact_wideband_rf_power_detector | present | present | USD | 100 | 2.857 | 17.142 | DigiKey cut-tape quantity-100 tier | https://www.digikey.com/en/products/detail/analog-devices-inc/AD8314ACPZ-RL7/671084 | 2026-08-19 |  |  |  |  | present | SUB-COMPUTE-RF | det_cc;det_nrf0;det_nrf1;det_nrf2;det_voice;det_voice_v
base_product | adi_ltc5532_es6_trmpbf | LTC5532ES6#TRMPBF | 2 | production | verified_candidate | present | present | USD | 100 | 3.8877 | 7.7754 | DigiKey cut-tape quantity-100 tier | https://www.digikey.com/en/products/detail/analog-devices-inc/LTC5532ES6-TRMPBF/1115993 | 2026-08-19 |  |  |  |  | present | SUB-COMPUTE-RF | det_c5;det_s3
base_product | adi_max17320_g20_t | Analog Devices MAX17320G20+T | 1 | recommended_for_new_designs | verified_candidate | present | present | USD | 100 | 4.0019 | 4.0019 | DigiKey cut-tape quantity-100 tier | https://www.digikey.com/en/products/detail/analog-devices-inc-maxim-integrated/MAX17320G20-T/16675120 | 2026-08-19 |  |  |  |  | present | SUB-PWR-SAFETY | pack_gauge
base_product | alps_ec11e18244au | Alps Alpine EC11E18244AU | 1 | active_standard | verified_first_target_mechanical_fit_hil_open | present | present | USD | 100 | 3.288 | 3.288 | DigiKey tray quantity-100 tier | https://www.digikey.com/en/products/detail/alps-alpine/EC11E18244AU/19529126 | 2026-08-19 |  |  |  |  | present | SUB-MECH-OPTICAL | encoder
base_product | alps_skrtlae010 | Alps Alpine SKRTLAE010 | 6 | standard_active_orderable | verified_exact_external_service_boot_reset_switch | present | present | USD | 100 | 0.2433 | 1.4598 | DigiKey cut-tape quantity-100 tier | https://www.digikey.com/en/products/detail/alps-alpine/SKRTLAE010/19529044 | 2026-08-23 |  |  |  |  | present | SUB-MECH-OPTICAL | c5_boot_button;c5_reset_button;rp_boot_button;rp_reset_button;s3_boot_button;s3_reset_button
base_product | bourns_crm2512_fx_20r0elf | Bourns CRM2512-FX-20R0ELF | 2 | active | verified_candidate | present | present | USD | 100 | 0.184 | 0.368 | DigiKey cut-tape quantity-100 tier | https://www.digikey.com/en/products/detail/bourns-inc/CRM2512-FX-20R0ELF/4698376 | 2026-08-19 |  |  |  |  | present | SUB-CTRL-PASSIVE | pack_diag_res0;pack_diag_res1
base_product | cc1101rgpr | CC1101RGPR | 1 | active | verified_candidate | present | present | USD | 100 | 3.0358 | 3.0358 | DigiKey cut-tape quantity-100 tier | https://www.digikey.com/en/products/detail/texas-instruments/CC1101RGPR/3947323 | 2026-08-19 |  |  |  |  | present | SUB-COMPUTE-RF | cc
base_product | ck_js102011scqn | C&K JS102011SCQN | 1 | active_orderable | verified_exact_low_current_power_command_switch_mechanical_hil_open | present | present | USD | 100 | 0.7823 | 0.7823 | DigiKey cut-tape quantity-100 tier | https://www.digikey.com/en/products/detail/c-k/JS102011SCQN/7355835 | 2026-08-19 |  |  |  |  | present | SUB-MECH-OPTICAL | power_command_switch
base_product | davies_1227_j | Davies Molding 1227-J | 1 | active | verified_exact_shaft_and_plan_fit_hil_open | present | present | USD | 100 | 0.972 | 0.972 | Mouser quantity-100 tier | https://www.mouser.com/en/ProductDetail/Davies-Molding/1227-J?qs=AaRlLUpeMszUlt7gcGM9fQ%3D%3D | 2026-08-19 |  |  |  |  | present | SUB-MECH-OPTICAL | encoder_knob
base_product | diodes_2n7002dw_7_f | Diodes Incorporated 2N7002DW-7-F | 4 | active | verified_candidate | present | present | USD | 100 | 0.1277 | 0.5108 | DigiKey cut-tape quantity-100 tier | https://www.digikey.com/en/products/detail/diodes-incorporated/2N7002DW-7-F/749948 | 2026-08-19 |  |  |  |  | present | SUB-DISCRETE-PROT | pack_hold;pack_status_buffer;safe_reset_sink_a;safe_reset_sink_b
base_product | diodes_bat54_7_f | Diodes Incorporated BAT54-7-F | 5 | active | verified_candidate | present | present | USD | 100 | 0.0698 | 0.349 | DigiKey cut-tape quantity-100 tier | https://www.digikey.com/en/products/detail/diodes-incorporated/BAT54-7-F/717699 | 2026-08-19 |  |  |  |  | present | SUB-DISCRETE-PROT | cc_evidence_hold_diode;nrf_evidence_hold_diode;pack_system_diode;voice_evidence_hold_diode;voice_v_evidence_hold_diode
base_product | diodes_dmn2056u_7 | Diodes Incorporated DMN2056U-7 | 3 | active_orderable_factory_stocked | accepted_exact_low_leakage_service_vbus_detector_and_load_switch | present | present | USD | 100 | 0.0562 | 0.1686 | JLCPCB quantity-100 tier; exact-one price USD 0.0695 | https://jlcpcb.com/partdetail/DiodesIncorporated-DMN2056U7/C332302 | 2026-08-30 |  |  |  |  | present | SUB-DISCRETE-PROT | backlight_mosfet;ir_tx_mosfet;pack_diag_switch
base_product | diodes_mmbt3904_7_f | Diodes Incorporated MMBT3904-7-F | 2 | active | verified_candidate | present | present | USD | 100 | 0.0597 | 0.1194 | DigiKey cut-tape quantity-100 tier | https://www.digikey.com/en/products/detail/diodes-incorporated/MMBT3904-7-F/815727 | 2026-08-19 |  |  |  |  | present | SUB-DISCRETE-PROT | ext_pg_qualifier;voice_pg_qualifier
base_product | diodes_pam8302a_aycr | Diodes Incorporated PAM8302AAYCR | 1 | active | verified_candidate | present | present | USD | 100 | 0.351 | 0.351 | Mouser cut-tape quantity-100 tier | https://www.mouser.com/en/ProductDetail/Diodes-Incorporated/PAM8302AAYCR?qs=pYVYkI7xuRX9VhIMiIHWEw%3D%3D | 2026-08-23 |  |  |  |  | present | SUB-LOGIC-ANALOG | speaker_amp
base_product | eastrising_er_tft035ips_6_ctp | EastRising ER-TFT035IPS-6 + ER-TPC035-6 | 1 | manufacturer promises at least ten years continuity from 2023 for ER-TFT035IPS-6 and from 2015 for ER-TPC035-6; both exact lines are currently in stock | selected_exact_documented_production_display_for_h1_layout | present | present | USD | 100 | 14.91 | 14.91 | conservative quantity-1 base USD 9.34 plus exact capacitive-touch-controller option USD 5.57; quantity-10 configured material USD 14.67 each | https://www.buydisplay.com/3-5-inch-ips-320x480-tft-lcd-display-capacitive-touch-screen | 2026-08-29 |  |  |  |  | present | SUB-MECH-OPTICAL | display
base_product | ebyte_e01_ml01sp4 | Ebyte E01-ML01SP4 | 3 | nrf24_family_not_recommended_for_new_designs | verified_candidate | present | present | USD | 100 | 2.9633 | 8.8899 | JLCPCB public in-stock quantity-100 tier | https://jlcpcb.com/partdetail/E01-ML01SP4/C97340 | 2026-08-29 |  |  |  |  | present | SUB-COMPUTE-RF | nrf0;nrf1;nrf2
base_product | epson_q13fc13500005 | Seiko Epson Q13FC13500005 | 1 | active_orderable | verified_candidate | present | present | USD | 100 | 0.2154 | 0.2154 | LCSC quantity-50 tier applicable to a 100-piece purchase | https://www.lcsc.com/product-detail/crystals_seiko-epson-q13fc13500005_C841881.html | 2026-08-19 |  |  |  |  | present | SUB-RF | receiver_clock
base_product | esp32_c5_wroom_1u_n8r8 | ESP32-C5-WROOM-1U-N8R8 | 1 | active_candidate_revision_floor_v1_2 | verified_candidate | present | present | USD | 100 | 4.1338 | 4.1338 | JLCPCB C54951858 quantity-100 tier | https://jlcpcb.com/partdetail/C54951858 | 2026-08-28 |  |  |  |  | present | SUB-COMPUTE-RF | c5
base_product | esp32_s3_wroom_1u_n16r8 | ESP32-S3-WROOM-1U-N16R8 | 1 | active_orderable | verified_exact_16mb_flash_8mb_octal_psram_external_antenna | present | present | USD | 100 | 5.108 | 5.108 | DigiKey cut-tape quantity-100 tier | https://www.digikey.com/en/products/detail/espressif-systems/ESP32-S3-WROOM-1U-N16R8/16162641 | 2026-08-20 |  |  |  |  | present | SUB-COMPUTE-RF | s3
base_product | everest_es8311_qfn20 | Everest Semiconductor ES8311 | 1 | current manufacturer product brief revision 17.0 dated 2026-02; production sourcing and lot qualification remain open | verified_candidate | present | present | USD | 100 | 0.3024 | 0.3024 | JLCPCB assembly-parts quantity-100 tier; captive PCBA inventory | https://jlcpcb.com/partdetail/1044199-ES8311/C962342 | 2026-08-19 |  |  |  |  | present | SUB-LOGIC-ANALOG | codec
base_product | fh_rs_06k47r0ft | FH RS-06K47R0FT | 1 | active_factory_stocked_standard_pcba | verified_exact_jlcpcb_stocked_ir_emitter_current_limit_resistor | present | present | USD | 100 | 0.0062 | 0.0062 | conservative JLCPCB one-piece tier | https://jlcpcb.com/partdetail/151340-RS06K47R0FT/C140014 | 2026-08-28 |  |  |  |  | present | SUB-CTRL-PASSIVE | ir_emitter_limit
base_product | fh_rs_06l2r70ft | FH RS-06L2R70FT | 1 | active_factory_stocked_standard_pcba | verified_exact_jlcpcb_stocked_backlight_series_resistor | present | present | USD | 1 | 0.0084 | 0.0084 | JLCPCB one-piece tier | https://jlcpcb.com/partdetail/304147-RS06L2R70FT/C323265 | 2026-08-31 |  |  |  |  | present | SUB-CTRL-PASSIVE | backlight_series_resistor
base_product | gct_rfpc_sma31_fn_175_a | GCT RFPC-SMA31-FN-175-A | 8 | active | verified_exact_external_standard_sma_body | present | present | USD | 100 | 2.46456 | 19.7165 | DigiKey tray 90-179 quantity tier applied at target quantity 100 | https://www.digikey.com/en/products/detail/gct/RFPC-SMA31-FN-175-A/25576371 | 2026-08-19 |  |  |  |  | present | SUB-MECH-OPTICAL | cc_external_sma;nrf0_external_sma;nrf1_external_sma;nrf2_external_sma;receiver_amlw_external_sma;receiver_fmsw_external_sma;voice_external_sma;voice_v_external_sma
base_product | gct_rfpc_sma32_fn_175_a | GCT RFPC-SMA32-FN-175-A | 2 | active | verified_exact_external_reverse_polarity_sma_body | present | present | USD | 100 | 2.46456 | 4.9291 | DigiKey tray 90-179 quantity tier applied at target quantity 100 | https://www.digikey.com/en/products/detail/gct/RFPC-SMA32-FN-175-A/25576372 | 2026-08-19 |  |  |  |  | present | SUB-MECH-OPTICAL | c5_external_rp_sma;s3_external_rp_sma
base_product | gct_usb4105_gf_a | GCT USB4105-GF-A | 2 | production_active_explicit_jlcpcb_preorder_route | reviewed_exact_product_and_service_usb_receptacle_factory_preorder_route | present | present | USD | 100 | 0.5745 | 1.149 | DigiKey cut-tape quantity-100 tier | https://www.digikey.com/en/products/detail/gct/USB4105-GF-A/11198510 | 2026-08-19 |  |  |  |  | present | SUB-MECH-OPTICAL | c5_service_usb_connector;rp_service_usb_connector
base_product | hirose_dm3at_sf_pejm5 | Hirose DM3AT-SF-PEJM5 | 1 | active | verified_candidate | present | present | USD | 100 | 2.5656 | 2.5656 | DigiKey cut-tape quantity-100 tier | https://www.digikey.com/en/products/detail/hirose-electric-co-ltd/DM3AT-SF-PEJM5/2533565 | 2026-08-19 |  |  |  |  | present | SUB-MECH-OPTICAL | sd
base_product | hirose_fh34srj_50s_0_5sh_50 | Hirose FH34SRJ-50S-0.5SH(50) | 1 | active exact manufacturer line; current JLCPCB Standard-PCBA stock and assembly route verified | verified_exact_jlcpcb_stocked_direct_ui_display_connector | present | present | USD | 100 | 0.5832 | 0.5832 | conservative JLCPCB exact C3169104 quantity-1 tier; quantity-10 tier USD 0.4711 | https://jlcpcb.com/partdetail/HRS_Hirose-FH34SRJ_50S_0_5SH_50/C3169104 | 2026-08-29 |  |  |  |  | present | SUB-MECH-OPTICAL | display_connector
base_product | hirose_fx8c_80p_sv1_92 | Hirose FX8C-80P-SV1(92) | 1 | active | verified_exact_m1_11mm_plug | present | present | USD | 100 | 3.1759 | 3.1759 | DigiKey cut-tape quantity-100 tier | https://www.digikey.com/en/products/detail/hirose-electric-co-ltd/FX8C-80P-SV1-92/4284726 | 2026-08-19 |  |  |  |  | present | SUB-MECH-OPTICAL | m1_ui_plug
base_product | hirose_fx8c_80s_sv5_92 | Hirose FX8C-80S-SV5(92) | 1 | active | verified_exact_m1_11mm_receptacle | present | present | USD | 100 | 3.9133 | 3.9133 | DigiKey cut-tape quantity-100 tier | https://www.digikey.com/en/products/detail/hirose-electric-co-ltd/FX8C-80S-SV5-92/4284737 | 2026-08-19 |  |  |  |  | present | SUB-MECH-OPTICAL | m1_rf_receptacle
base_product | hirose_ufl_r_smt_1_10 | Hirose U.FL-R-SMT-1(80) | 5 | active_orderable | verified_exact_native_rf_board_mate | present | present | USD | 100 | 0.0823 | 0.4115 | JLCPCB in-stock quantity-50 tier applied to quantity 100 | https://jlcpcb.com/partdetail/U.FL-R-SMT-1%2880%29/C88374 | 2026-08-29 |  |  |  |  | present | SUB-MECH-OPTICAL | c5_rf_board_connector;nrf0_rf_board_connector;nrf1_rf_board_connector;nrf2_rf_board_connector;s3_rf_board_connector
base_product | infineon_bgs13sn8e6327xtsa1 | Infineon BGS13SN8E6327XTSA1 | 2 | active_orderable | verified_exact_cc_dual_ended_band_switch | present | present | USD | 100 | 0.2126 | 0.4252 | DigiKey cut-tape quantity-100 tier | https://www.digikey.com/en/products/detail/infineon-technologies/BGS13SN8E6327XTSA1/6559893 | 2026-08-19 |  |  |  |  | present | SUB-COMPUTE-RF | cc_switch_a;cc_switch_b
base_product | jae_dx07s016ja1r1500 | JAE DX07S016JA1R1500 | 1 | active | verified_candidate | present | present | USD | 100 | 1.2272 | 1.2272 | DigiKey cut-tape quantity-100 tier | https://www.digikey.com/en/products/detail/jae-electronics/DX07S016JA1R1500/11585731 | 2026-08-19 |  |  |  |  | present | SUB-MECH-OPTICAL | product_usb_connector
base_product | kemet_c0402c102k5ractu | KEMET C0402C102K5RACTU | 2 | active | verified_candidate | present | present | USD | 100 | 0.015 | 0.03 | DigiKey cut-tape quantity-100 tier | https://www.digikey.com/en/products/detail/kemet/C0402C102K5RACTU/411034 | 2026-08-19 |  |  |  |  | present | SUB-CTRL-PASSIVE | charger_sdrv_cap;ir_evidence_feedback_cap
base_product | kemet_c0402c330j5gactu | KEMET C0402C330J5GACTU | 5 | active | verified_candidate | present | present | USD | 100 | 0.0213 | 0.1065 | DigiKey cut-tape quantity-100 tier | https://www.digikey.com/en/products/detail/kemet/C0402C330J5GACTU/411019 | 2026-08-19 |  |  |  |  | present | SUB-CTRL-PASSIVE | c5_detector_output_cap;ext_buck_ff_cap;main_ff_cap;s3_detector_output_cap;voice_ff_cap
base_product | keystone_1048p | Keystone Electronics 1048P | 1 | active | verified_mechanical_reference | present | present | USD | 100 | 8.57 | 8.57 | Mouser tray quantity-100 tier | https://www.mouser.com/ProductDetail/Keystone-Electronics/1048P?qs=9%252Bwcgl%2FJqd1h8Vx3IFpTxA%3D%3D | 2026-08-19 |  |  |  |  | present | SUB-MECH-OPTICAL | pack_holder
base_product | kyocera_avx_cp0603q5425entr | KYOCERA AVX CP0603Q5425ENTR | 2 | active_orderable | verified_exact_native_rf_forward_coupler | present | present | USD | 100 | 0.4271 | 0.8542 | DigiKey cut-tape quantity-100 tier | https://www.digikey.com/en/products/detail/kyocera-avx/CP0603Q5425ENTR/4805840 | 2026-08-19 |  |  |  |  | present | SUB-RF | c5_rf_coupler;s3_rf_coupler
base_product | liteon_ltst_c190kfkt | LTST-C190KFKT | 1 | active | verified_candidate | present | present | USD | 100 | 0.0637 | 0.0637 | DigiKey cut-tape quantity-100 tier | https://www.digikey.com/en/products/detail/liteon/LTST-C190KFKT/386813 | 2026-08-19 |  |  |  |  | present | SUB-DISCRETE-PROT | fault_led
base_product | liteon_ltst_c190krkt | LTST-C190KRKT | 9 | active | verified_candidate | present | present | USD | 100 | 0.0675 | 0.6075 | DigiKey cut-tape quantity-100 tier | https://www.digikey.com/en/products/detail/liteon/LTST-C190KRKT/386817 | 2026-08-19 |  |  |  |  | present | SUB-DISCRETE-PROT | c5_tx_led;cc_tx_led;ext_tx_led;ir_tx_led;nrf0_tx_led;nrf1_tx_led;nrf2_tx_led;s3_tx_led;voice_tx_led
base_product | littelfuse_0451005_mrl | Littelfuse 0451005.MRL | 2 | active | verified_candidate | present | present | USD | 100 | 1.4488 | 2.8976 | DigiKey cut-tape quantity-100 tier | https://www.digikey.com/en/products/detail/littelfuse-inc/0451005-MRL/700828 | 2026-08-19 |  |  |  |  | present | SUB-CTRL-PASSIVE | pack_fuse0;pack_fuse1
base_product | littelfuse_sesd0402x1un_0020_090 | Littelfuse SESD0402X1UN-0020-090 | 3 | active_orderable | verified_exact_cc_external_rf_esd | present | present | USD | 100 | 0.3794 | 1.1382 | DigiKey cut-tape quantity-100 tier | https://www.digikey.com/en/products/detail/littelfuse-inc/SESD0402X1UN-0020-090/5233545 | 2026-08-19 |  |  |  |  | present | SUB-RF | cc_rf_esd;receiver_ami_esd;receiver_fmi_esd
optional_external_accessory | m5_u214 | M5Stack U214 Cap LoRa-1262 | 1 | active | verified_candidate | present | missing |  |  |  |  |  |  |  | retail_only_no_quantity_100_tier | The exact U214 is sold as a retail package at USD 14.50 with no published quantity-100 tier; a comparable production quantity quote is required instead of multiplying the retail price | https://www.digikey.com/en/products/detail/m5stack-technology-co-ltd/U214/29291633 | 2026-08-22 | present | SUB-COMPUTE-RF | u214
base_product | murata_blm18pg181sn1d | Murata BLM18PG181SN1D | 4 | active_orderable | verified_candidate | present | present | USD | 100 | 0.0431 | 0.1724 | DigiKey cut-tape quantity-100 tier | https://www.digikey.com/en/products/detail/murata-electronics/BLM18PG181SN1D/1634634 | 2026-08-19 |  |  |  |  | present | SUB-PWR-PASSIVE | codec_avdd_bead;codec_dvdd_bead;speaker_output_bead_n;speaker_output_bead_p
base_product | murata_gjm1555c1h100jb01d | Murata GJM1555C1H100JB01D | 1 | active_orderable | verified_exact_cc_matching_passive | present | present | USD | 100 | 0.0417 | 0.0417 | DigiKey cut-tape quantity-100 tier | https://www.digikey.com/en/products/detail/murata-electronics/GJM1555C1H100JB01D/702306 | 2026-08-19 |  |  |  |  | present | SUB-RF | cc_433_shunt_c10p
base_product | murata_gjm1555c1h101jb01d | Murata GJM1555C1H101JB01D | 2 | active_orderable | verified_exact_cc_rf_dc_block_passive | present | missing |  |  |  |  |  |  |  | quantity_100_rfq_required | Current exact-MPN sourcing exposes request-for-quote inventory but no published comparable quantity-100 USD tier; an RF-qualified replacement cannot be promoted only to obtain a price | https://www.1sourcecomponents.com/availability/MURATA--GJM1555C1H101JB01D.htm | 2026-08-19 | present | SUB-RF | cc_rf_n_dc_block;cc_rf_p_dc_block
base_product | murata_gjm1555c1h150jb01d | Murata GJM1555C1H150JB01D | 4 | active_orderable | verified_exact_cc_crystal_load_passive | present | present | USD | 100 | 0.0392 | 0.1568 | DigiKey cut-tape quantity-100 tier | https://www.digikey.com/en/products/detail/murata-electronics/GJM1555C1H150JB01D/702310 | 2026-08-19 |  |  |  |  | present | SUB-RF | cc_crystal_load_q1;cc_crystal_load_q2;rp_clock_load_xin;rp_clock_load_xout
base_product | murata_gjm1555c1h1r2bb01d | Murata GJM1555C1H1R2BB01D | 1 | active_orderable | verified_exact_cc_matching_passive | present | present | USD | 100 | 0.031 | 0.031 | DigiKey cut-tape quantity-100 tier | https://www.digikey.com/en/products/detail/murata-electronics/GJM1555C1H1R2BB01D/2592874 | 2026-08-19 |  |  |  |  | present | SUB-RF | cc_match_c1p2
base_product | murata_gjm1555c1h6r2db01d | Murata GJM1555C1H6R2DB01D | 1 | active_orderable | verified_exact_cc_matching_passive | present | present | USD | 100 | 0.021 | 0.021 | Mouser cut-tape quantity-100 tier | https://www.mouser.com/c/passive-components/capacitors/ceramic-capacitors/mlccs-multilayer-ceramic-capacitors/multilayer-ceramic-capacitors-mlcc-smd-smt/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 | 2026-08-19 |  |  |  |  | present | SUB-RF | cc_433_shunt_c6p2
base_product | murata_gjm1555c1h8r0db01d | Murata GJM1555C1H8R0DB01D | 1 | active_orderable | verified_exact_cc_matching_passive | present | present | USD | 100 | 0.0207 | 0.0207 | DigiKey cut-tape quantity-100 tier | https://www.digikey.com/en/products/detail/murata-electronics/GJM1555C1H8R0DB01D/2593153 | 2026-08-19 |  |  |  |  | present | SUB-RF | cc_315_shunt_c8p
base_product | murata_gjm1555c1hr47bb01d | Murata GJM1555C1HR47BB01D | 1 | active_orderable | verified_exact_cc_detector_tap_passive | present | present | USD | 100 | 0.0346 | 0.0346 | DigiKey cut-tape quantity-100 tier | https://www.digikey.com/en/products/detail/murata-electronics/GJM1555C1HR47BB01D/7362927 | 2026-08-19 |  |  |  |  | present | SUB-RF | cc_detector_tap_cap
base_product | murata_gjm1555c1hr60bb01d | Murata GJM1555C1HR60BB01D | 1 | active_orderable | verified_exact_cc_matching_passive | present | present | USD | 100 | 0.031 | 0.031 | DigiKey cut-tape quantity-100 tier | https://www.digikey.com/en/products/detail/murata-electronics/GJM1555C1HR60BB01D/2593254 | 2026-08-19 |  |  |  |  | present | SUB-RF | cc_rf_diff_cap
base_product | murata_grm1555c1h102ja01d | Murata GRM1555C1H102JA01D | 1 | active_orderable | verified_exact_si4732_fmi_first_target | present | present | USD | 100 | 0.0181 | 0.0181 | DigiKey cut-tape quantity-100 tier | https://www.digikey.com/en/products/detail/murata-electronics/GRM1555C1H102JA01D/702509 | 2026-08-19 |  |  |  |  | present | SUB-RF | receiver_fmi_coupling_cap
base_product | murata_grm1555c1h121ja01d | Murata GRM1555C1H121JA01D | 8 | active | verified_candidate | present | present | USD | 100 | 0.0197 | 0.1576 | DigiKey cut-tape quantity-100 tier | https://www.digikey.com/en/products/detail/murata-electronics/GRM1555C1H121JA01D/587178 | 2026-08-19 |  |  |  |  | present | SUB-CTRL-PASSIVE | cc_detector_filter;main_efuse_itimer_cap;nrf0_detector_filter;nrf1_detector_filter;nrf2_detector_filter;voice_detector_filter;voice_efuse_itimer_cap;voice_v_detector_filter
base_product | murata_grm1555c1h220ja01d | Murata GRM1555C1H220JA01D | 2 | active_orderable | verified_candidate | present | present | USD | 100 | 0.0025 | 0.005 | LCSC quantity-100 tier | https://www.lcsc.com/product-detail/C76960.html | 2026-08-19 |  |  |  |  | present | SUB-RF | receiver_clock_cap_gpo3;receiver_clock_cap_rclk
base_product | murata_grm1555c1h221ja01d | Murata GRM1555C1H221JA01D | 4 | active | verified_candidate | present | present | USD | 100 | 0.0177 | 0.0708 | DigiKey cut-tape quantity-100 tier | https://www.digikey.com/en/products/detail/murata-electronics/GRM1555C1H221JA01D/587204 | 2026-08-19 |  |  |  |  | present | SUB-CTRL-PASSIVE | pd_cc1_cap;pd_cc2_cap;speaker_output_cap_n;speaker_output_cap_p
base_product | murata_grm1555c1h390ja01d | Murata GRM1555C1H390JA01D | 2 | active_orderable | verified_exact_ltc5532_rf_input_coupling_capacitor | present | present | USD | 100 | 0.014 | 0.028 | Mouser cut-tape quantity-100 tier | https://www.mouser.com/ProductDetail/Murata-Electronics/GRM1555C1H390JA01D?qs=4k9rjS6ZRl5FP2mUYTju2g%3D%3D | 2026-08-19 |  |  |  |  | present | SUB-RF | c5_detector_input_cap;s3_detector_input_cap
base_product | murata_grm155r71a474ke01d | Murata GRM155R71A474KE01D | 1 | active_orderable | verified_exact_si4732_ami_first_target | present | present | USD | 100 | 0.1771 | 0.1771 | DigiKey cut-tape quantity-100 tier | https://www.digikey.com/en/products/detail/murata-electronics/GRM155R71A474KE01D/6605995 | 2026-08-19 |  |  |  |  | present | SUB-CTRL-PASSIVE | receiver_ami_coupling_cap
base_product | murata_grm155r71e473ka88d | Murata GRM155R71E473KA88D | 2 | active | verified_candidate | present | present | USD | 100 | 0.0126 | 0.0252 | DigiKey cut-tape quantity-100 tier | https://www.digikey.com/en/products/detail/murata-electronics/GRM155R71E473KA88D/702519 | 2026-08-19 |  |  |  |  | present | SUB-CTRL-PASSIVE | charger_btst1_cap;charger_btst2_cap
base_product | murata_grm155r71h103ka88d | Murata GRM155R71H103KA88D | 8 | production_active_factory_stocked_standard_pcba | verified_exact_jlcpcb_stocked_standard_pcba | present | present | USD | 100 | 0.0097 | 0.0776 | conservative JLCPCB one-piece tier; displayed stock 675,981 | https://jlcpcb.com/partdetail/MurataElectronics-GRM155R71H103KA88D/C77019 | 2026-08-29 |  |  |  |  | present | SUB-CTRL-PASSIVE | codec_tx_filter;pack_admission_reset_cap;pack_mid_adc_filter;pack_stack_adc_filter;safety_controller_reset_cap;u214_supervisor_ct;unit_supervisor_ct;voice_supervisor_ct
base_product | murata_grm155r71h472ka01d | Murata GRM155R71H472KA01D | 4 | active | verified_candidate | present | present | USD | 100 | 0.0098 | 0.0392 | DigiKey cut-tape quantity-100 tier | https://www.digikey.com/en/products/detail/murata-electronics/GRM155R71H472KA01D/587946 | 2026-08-19 |  |  |  |  | present | SUB-CTRL-PASSIVE | ext_dvdt_cap;main_efuse_dvdt_cap;unit_dvdt_cap;voice_efuse_dvdt_cap
base_product | murata_grm188r60j106me47d | Murata GRM188R60J106ME47D | 19 | active | verified_candidate | present | present | USD | 100 | 0.0377 | 0.7163 | DigiKey cut-tape quantity-100 tier | https://www.digikey.com/en/products/detail/murata-electronics/GRM188R60J106ME47D/965910 | 2026-08-19 |  |  |  |  | present | SUB-PWR-PASSIVE | aon_efuse_output_cap;backlight_efuse_output_bulk;codec_power_output_cap;display_logic_bulk_cap;headset_microphone_bias_filter_cap;ir_power_output_cap;main_efuse_output_cap;microphone_bias_filter_cap;nrf0_module_bulk_cap;nrf1_module_bulk_cap;nrf2_module_bulk_cap;pack_admission_bulk_cap;pd_ldo1v5_cap;pd_ldo3v3_cap;pd_vin_cap;receiver_power_output_cap;safety_controller_bulk;speaker_amp_bulk_cap;voice_efuse_output_cap
base_product | murata_grm188r71e224ka88d | Murata GRM188R71E224KA88D | 2 | active | verified_candidate | present | present | USD | 100 | 0.0306 | 0.0612 | DigiKey cut-tape quantity-100 tier | https://www.digikey.com/en/products/detail/murata-electronics/GRM188R71E224KA88D/702554 | 2026-08-19 |  |  |  |  | present | SUB-CTRL-PASSIVE | ext_itimer_cap;unit_itimer_cap
base_product | murata_grm188r71e474ka12d | Murata GRM188R71E474KA12D | 4 | active_stocked_orderable | verified_exact_max17320_bypass_capacitor | present | present | USD | 100 | 0.0496 | 0.1984 | DigiKey cut-tape quantity-100 tier | https://www.digikey.com/en/products/detail/murata-electronics/GRM188R71E474KA12D/702555 | 2026-08-19 |  |  |  |  | present | SUB-PWR-PASSIVE | pack_aoldo_cap;pack_cp_cap;pack_reg2_cap;pack_reg3_cap
base_product | murata_grm188z71a475me15d | Murata GRM188Z71A475ME15D | 2 | active_stocked_orderable | verified_exact_ir_receiver_filter_capacitor | present | present | USD | 100 | 0.0899 | 0.1798 | DigiKey cut-tape quantity-100 tier | https://www.digikey.com/en/products/detail/murata-electronics/GRM188Z71A475ME15D/13904814 | 2026-08-19 |  |  |  |  | present | SUB-PWR-PASSIVE | ir_carrier_supply_cap;ir_demod_supply_cap
base_product | murata_grm21br60j226me39l | Murata GRM21BR60J226ME39L | 6 | active | verified_candidate | present | present | USD | 100 | 0.1341 | 0.8046 | DigiKey cut-tape quantity-100 tier | https://www.digikey.com/en/products/detail/murata-electronics/GRM21BR60J226ME39L/587424 | 2026-08-19 |  |  |  |  | present | SUB-PWR-PASSIVE | headphone_l_coupling0;headphone_l_coupling1;headphone_r_coupling0;headphone_r_coupling1;s3_supply_bulk;sd_power_bulk_cap
base_product | murata_grm21br71e225ke11l | Murata GRM21BR71E225KE11L | 5 | active | verified_candidate | present | present | USD | 100 | 0.0612 | 0.306 | DigiKey cut-tape quantity-100 tier | https://www.digikey.com/en/products/detail/murata-electronics/GRM21BR71E225KE11L/6606096 | 2026-08-19 |  |  |  |  | present | SUB-PWR-PASSIVE | ext_input_cap;ext_output_cap;safe_rearm_delay_cap;unit_input_cap;unit_output_cap
base_product | murata_grm31c5c1h224je02l | Murata GRM31C5C1H224JE02L | 1 | active | verified_candidate | present | present | USD | 100 | 0.3198 | 0.3198 | DigiKey cut-tape quantity-100 tier | https://www.digikey.com/en/products/detail/murata-electronics/GRM31C5C1H224JE02L/10691338 | 2026-08-19 |  |  |  |  | present | SUB-CTRL-PASSIVE | pack_diag_timer_cap
base_product | murata_grm31cr71a226ke15l | Murata GRM31CR71A226KE15L | 1 | active | verified_candidate | present | present | USD | 100 | 0.1884 | 0.1884 | DigiKey cut-tape quantity-100 tier | https://www.digikey.com/en/products/detail/murata-electronics/GRM31CR71A226KE15L/2039036 | 2026-08-19 |  |  |  |  | present | SUB-PWR-PASSIVE | aon_output_cap
base_product | murata_grm31cr71e106ma12l | Murata GRM31CR71E106MA12L | 12 | active | verified_candidate | present | present | USD | 100 | 0.1224 | 1.4688 | DigiKey cut-tape quantity-100 tier | https://www.digikey.com/en/products/detail/murata-electronics/GRM31CR71E106MA12L/2548205 | 2026-08-19 |  |  |  |  | present | SUB-PWR-PASSIVE | charger_bat_cap0;charger_bat_cap1;charger_pmid_cap0;charger_pmid_cap1;charger_pmid_cap2;charger_sys_cap0;charger_sys_cap1;charger_sys_cap2;charger_sys_cap3;charger_sys_cap4;charger_vbus_cap0;charger_vbus_cap1
base_product | murata_grm32er71e226ke15l | Murata GRM32ER71E226KE15L | 13 | active | verified_candidate | present | present | USD | 100 | 0.3303 | 4.2939 | DigiKey cut-tape quantity-100 tier | https://www.digikey.com/en/products/detail/murata-electronics/GRM32ER71E226KE15L/2039092 | 2026-08-19 |  |  |  |  | present | SUB-PWR-PASSIVE | ext_buck_input_cap;ext_buck_output_cap0;ext_buck_output_cap1;main_input_cap;main_output_cap0;main_output_cap1;pd_pphv_cap0;pd_pphv_cap1;pd_pphv_cap2;pd_pphv_cap3;voice_input_cap;voice_output_cap0;voice_output_cap1
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

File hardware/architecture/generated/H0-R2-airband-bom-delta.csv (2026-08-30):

mpn | jlcpcb | qty | role | live_stock | unit_price | route
LT5560EDD#TRPBF | C462645 | 1 | active down-converting mixer | 165 | 14.5398 | JLCPCB Standard-PCBA SMT
PGA-103+ | C3008207 | 1 | 118-137-MHz low-noise gain | 1441 | 2.6063 | JLCPCB Standard-PCBA SMT
SI5351A-B-GTR | C504891 | 1 | 112-MHz local oscillator | 36999 | 1.218 | JLCPCB Standard-PCBA SMT
HMC544AETR | C579555 | 2 | paired low-loss input/output isolation selectors | 2004 | 3.1529 | JLCPCB Standard-PCBA SMT
SI4732-A10-GSR | C2155558 | 0 | existing FM/AM/SW/LW receiver reused for 6-25-MHz IF | 547 | 2.8621 | existing R1 line; no incremental quantity

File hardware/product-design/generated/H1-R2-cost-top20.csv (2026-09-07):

rank | source | mpn | role | quantity_per_prototype | effective_unit_price_usd | group_cost_per_prototype_usd | share_of_known_combined_total_pct
1 | external_antenna | SMA-W100RX2 | receive-only telescopic whip; AIR | 1 | 35.95 | 35.95 | 7.983
2 | external_antenna | 001-0012 | 2.4/5 GHz native radio; S3, C5 | 2 | 16.91 | 33.82 | 7.51
3 | external_antenna | AN0155H13 | VHF 136-174 MHz; VHF | 1 | 31.7 | 31.7 | 7.039
4 | external_antenna | ANT-433-CW-QW-SMA | 433 MHz / UHF 400-470 MHz; S433, UHF | 2 | 11.23 | 22.46 | 4.987
5 | base_bom | GCT RFPC-SMA31-FN-175-A | eight standard outward SMA / восемь внешних SMA | 8 | 2.46456 | 19.71648 | 4.378
6 | base_bom | EastRising ER-TFT035IPS-6 + ER-TPC035-6 | display | 1 | 14.91 | 14.91 | 3.311
7 | base_bom | Analog Devices AD8314ARMZ-REEL | six real-TX RF detectors / шесть RF-детекторов фактической передачи | 6 | 1.9398 | 11.6388 | 2.584
8 | base_bom | WBC16-1TLC | official DC1027A 1:16 mixer-output transformer | 1 | 10.2728 | 10.2728 | 2.281
9 | base_bom | OMRON B3S-1100P | sixteen ordinary user keys / шестнадцать обычных клавиш | 16 | 0.6405 | 10.248 | 2.276
10 | base_bom | Samtec FTSH-105-01-L-DV-K-P-TR | four internal recovery headers / четыре внутренних recovery-разъёма | 6 | 1.6991000000000003 | 10.194600000000001 | 2.264
11 | base_bom | G-NiceRF SA818S-V | VHF voice transceiver / VHF голосовой трансивер | 1 | 10.071 | 10.071 | 2.236
12 | base_bom | G-NiceRF SA818S-U | UHF voice transceiver / UHF голосовой трансивер | 1 | 9.7347 | 9.7347 | 2.162
13 | external_antenna | ANT-315-CW-HW-SMA | 315 MHz; S315 | 1 | 9.6 | 9.6 | 2.132
14 | base_bom | Ebyte E01-ML01SP4 | three 20-dBm PA/LNA full-function nRF24 radios / три полнофункциональных nRF24 с PA/LNA 20 dBm | 3 | 2.9633 | 8.889899999999999 | 1.974
15 | base_bom | Keystone Electronics 1048P | dual protected-18650 holder / держатель двух защищённых 18650 | 1 | 8.57 | 8.57 | 1.903
16 | base_bom | Texas Instruments TMUX1136DGSR | four complete audio/control selectors / четыре полных audio/control selector | 4 | 2.0581 | 8.2324 | 1.828
17 | base_bom | LTC5532ES6#TRMPBF | S3/C5 2.4/5-GHz TX detectors / детекторы TX S3/C5 2,4/5 ГГц | 2 | 3.8877 | 7.7754 | 1.727
18 | base_bom | LT5560EDD#TRPBF | official-reference active down-converting mixer | 1 | 6.9028 | 6.9028 | 1.533
19 | base_bom | TE Connectivity 1-2118651-0 | three 60-mm nRF RF jumpers / три 60-мм RF-кабеля nRF | 3 | 1.8099999999999998 | 5.43 | 1.206
20 | base_bom | Murata GRM32ER71E226KE15L | thirteen 22-uF power capacitors / тринадцать силовых конденсаторов 22 мкФ | 16 | 0.3303 | 5.2848 | 1.173

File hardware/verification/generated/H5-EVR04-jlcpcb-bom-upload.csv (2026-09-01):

Comment | Designator | Footprint | Quantity | Manufacturer Part Number | LCSC Part #
ABM8-26.000MHZ-10-D-1-G-T | X001001 | TBD | 1 | ABM8-26.000MHZ-10-D-1-G-T
ABM8-272-T3 | X002001 | TBD | 1 | ABM8-272-T3
AOTA-B201610S3R3-101-T | X003001 | TBD | 1 | AOTA-B201610S3R3-101-T
AD8314ACPZ-RL7 | X004001,X004002,X004003,X004004,X004005,X004006 | TBD | 6 | AD8314ACPZ-RL7
LTC5532ES6#TRMPBF | X005001,X005002 | TBD | 2 | LTC5532ES6#TRMPBF
MAX17320G20+T | X006001 | TBD | 1 | MAX17320G20+T
EC11E18244AU | X007001 | TBD | 1 | EC11E18244AU
SKRTLAE010 | X008001,X008002,X008003,X008004,X008005,X008006 | TBD | 6 | SKRTLAE010
CRM2512-FX-20R0ELF | X009001,X009002 | TBD | 2 | CRM2512-FX-20R0ELF
CC1101RGPR | X010001 | TBD | 1 | CC1101RGPR
JS102011SCQN | X011001 | TBD | 1 | JS102011SCQN
1227-J | X012001 | TBD | 1 | 1227-J
2N7002DW-7-F | X013001,X013002,X013003,X013004 | TBD | 4 | 2N7002DW-7-F
BAT54-7-F | X014001,X014002,X014003,X014004,X014005 | TBD | 5 | BAT54-7-F
DMN2056U-7 | X015001,X015002,X015003 | TBD | 3 | DMN2056U-7
MMBT3904-7-F | X016001,X016002 | TBD | 2 | MMBT3904-7-F
PAM8302AAYCR | X017001 | TBD | 1 | PAM8302AAYCR
ER-TFT035IPS-6 + ER-TPC035-6 | X018001 | TBD | 1 | ER-TFT035IPS-6 + ER-TPC035-6
E01-ML01SP4 | X019001,X019002,X019003 | TBD | 3 | E01-ML01SP4
Q13FC13500005 | X020001 | TBD | 1 | Q13FC13500005
ESP32-C5-WROOM-1U-N8R8 | X021001 | TBD | 1 | ESP32-C5-WROOM-1U-N8R8
ESP32-S3-WROOM-1U-N16R8 | X022001 | TBD | 1 | ESP32-S3-WROOM-1U-N16R8
ES8311 | X023001 | TBD | 1 | ES8311
RS-06K47R0FT | X024001 | TBD | 1 | RS-06K47R0FT
RS-06L2R70FT | X025001 | TBD | 1 | RS-06L2R70FT
RFPC-SMA31-FN-175-A | X026001,X026002,X026003,X026004,X026005,X026006,X026007,X026008 | TBD | 8 | RFPC-SMA31-FN-175-A
RFPC-SMA32-FN-175-A | X027001,X027002 | TBD | 2 | RFPC-SMA32-FN-175-A
USB4105-GF-A | X028001,X028002 | TBD | 2 | USB4105-GF-A
DM3AT-SF-PEJM5 | X029001 | TBD | 1 | DM3AT-SF-PEJM5
FH34SRJ-50S-0.5SH(50) | X030001 | TBD | 1 | FH34SRJ-50S-0.5SH(50)
FX8C-80P-SV1(92) | X031001 | TBD | 1 | FX8C-80P-SV1(92)
FX8C-80S-SV5(92) | X032001 | TBD | 1 | FX8C-80S-SV5(92)
U.FL-R-SMT-1(80) | X033001,X033002,X033003,X033004,X033005 | TBD | 5 | U.FL-R-SMT-1(80)
BGS13SN8E6327XTSA1 | X034001,X034002 | TBD | 2 | BGS13SN8E6327XTSA1
DX07S016JA1R1500 | X035001 | TBD | 1 | DX07S016JA1R1500
C0402C102K5RACTU | X036001,X036002 | TBD | 2 | C0402C102K5RACTU
C0402C330J5GACTU | X037001,X037002,X037003,X037004,X037005 | TBD | 5 | C0402C330J5GACTU
1048P | X038001 | TBD | 1 | 1048P
CP0603Q5425ENTR | X039001,X039002 | TBD | 2 | CP0603Q5425ENTR
LTST-C190KFKT | X040001 | TBD | 1 | LTST-C190KFKT
LTST-C190KRKT | X041001,X041002,X041003,X041004,X041005,X041006,X041007,X041008,X041009 | TBD | 9 | LTST-C190KRKT
0451005.MRL | X042001,X042002 | TBD | 2 | 0451005.MRL
SESD0402X1UN-0020-090 | X043001,X043002,X043003 | TBD | 3 | SESD0402X1UN-0020-090
U214 Cap LoRa-1262 | X044001 | TBD | 1 | U214 Cap LoRa-1262
BLM18PG181SN1D | X045001,X045002,X045003,X045004 | TBD | 4 | BLM18PG181SN1D
GJM1555C1H100JB01D | X046001 | TBD | 1 | GJM1555C1H100JB01D
GJM1555C1H101JB01D | X047001,X047002 | TBD | 2 | GJM1555C1H101JB01D
GJM1555C1H150JB01D | X048001,X048002,X048003,X048004 | TBD | 4 | GJM1555C1H150JB01D
GJM1555C1H1R2BB01D | X049001 | TBD | 1 | GJM1555C1H1R2BB01D
GJM1555C1H6R2DB01D | X050001 | TBD | 1 | GJM1555C1H6R2DB01D
GJM1555C1H8R0DB01D | X051001 | TBD | 1 | GJM1555C1H8R0DB01D
GJM1555C1HR47BB01D | X052001 | TBD | 1 | GJM1555C1HR47BB01D
GJM1555C1HR60BB01D | X053001 | TBD | 1 | GJM1555C1HR60BB01D
GRM1555C1H102JA01D | X054001 | TBD | 1 | GRM1555C1H102JA01D
GRM1555C1H121JA01D | X055001,X055002,X055003,X055004,X055005,X055006,X055007,X055008 | TBD | 8 | GRM1555C1H121JA01D
GRM1555C1H220JA01D | X056001,X056002 | TBD | 2 | GRM1555C1H220JA01D
GRM1555C1H221JA01D | X057001,X057002,X057003,X057004 | TBD | 4 | GRM1555C1H221JA01D
GRM1555C1H390JA01D | X058001,X058002 | TBD | 2 | GRM1555C1H390JA01D
GRM155R71A474KE01D | X059001 | TBD | 1 | GRM155R71A474KE01D
GRM155R71E473KA88D | X060001,X060002 | TBD | 2 | GRM155R71E473KA88D
GRM155R71H103KA88D | X061001,X061002,X061003,X061004,X061005,X061006,X061007,X061008 | TBD | 8 | GRM155R71H103KA88D
GRM155R71H472KA01D | X062001,X062002,X062003,X062004 | TBD | 4 | GRM155R71H472KA01D
GRM188R60J106ME47D | X063001,X063002,X063003,X063004,X063005,X063006,X063007,X063008,X063009,X063010,X063011,X063012,X063013,X063014,X063015,X063016,X063017,X063018,X063019 | TBD | 19 | GRM188R60J106ME47D
GRM188R71E224KA88D | X064001,X064002 | TBD | 2 | GRM188R71E224KA88D
GRM188R71E474KA12D | X065001,X065002,X065003,X065004 | TBD | 4 | GRM188R71E474KA12D
GRM188Z71A475ME15D | X066001,X066002 | TBD | 2 | GRM188Z71A475ME15D
GRM21BR60J226ME39L | X067001,X067002,X067003,X067004,X067005,X067006 | TBD | 6 | GRM21BR60J226ME39L
GRM21BR71E225KE11L | X068001,X068002,X068003,X068004,X068005 | TBD | 5 | GRM21BR71E225KE11L
GRM31C5C1H224JE02L | X069001 | TBD | 1 | GRM31C5C1H224JE02L
GRM31CR71A226KE15L | X070001 | TBD | 1 | GRM31CR71A226KE15L
GRM31CR71E106MA12L | X071001,X071002,X071003,X071004,X071005,X071006,X071007,X071008,X071009,X071010,X071011,X071012 | TBD | 12 | GRM31CR71E106MA12L
GRM32ER71E226KE15L | X072001,X072002,X072003,X072004,X072005,X072006,X072007,X072008,X072009,X072010,X072011,X072012,X072013 | TBD | 13 | GRM32ER71E226KE15L
LQG15HS10NJ02D | X073001,X073002,X073003 | TBD | 3 | LQG15HS10NJ02D
LQG15HS15NJ02D | X074001 | TBD | 1 | LQG15HS15NJ02D
LQG15HS2N2S02D | X075001 | TBD | 1 | LQG15HS2N2S02D
LQG15HS3N3S02D | X076001 | TBD | 1 | LQG15HS3N3S02D
LQG15HS3N6S02D | X077001 | TBD | 1 | LQG15HS3N6S02D
LQG15HS6N8J02D | X078001 | TBD | 1 | LQG15HS6N8J02D
LQW15AN56NG00D | X079001 | TBD | 1 | LQW15AN56NG00D
74LVC126APW,118 | X080001,X080002,X080003,X080004,X080005,X080006,X080007,X080008 | TBD | 8 | 74LVC126APW,118
74LVC1G32GV,125 | X081001,X081002 | TBD | 2 | 74LVC1G32GV,125
74LVC2G126DP,125 | X082001,X082002,X082003,X082004,X082005 | TBD | 5 | 74LVC2G126DP,125
74LVC2G14GV,125 | X083001,X083002 | TBD | 2 | 74LVC2G14GV,125
PESD24VY1BSF | X084001,X084002 | TBD | 2 | PESD24VY1BSF
SA818S-U | X085001 | TBD | 1 | SA818S-U
SA818S-V | X086001 | TBD | 1 | SA818S-V
B3S-1100P | X087001,X087002,X087003,X087004,X087005,X087006,X087007,X087008,X087009,X087010,X087011,X087012,X087013,X087014,X087015,X087016 | TBD | 16 | B3S-1100P
BAT54ALT1G | X088001,X088002,X088003,X088004,X088005 | TBD | 5 | BAT54ALT1G
BAV70LT1G | X089001 | TBD | 1 | BAV70LT1G
CAT24C512WI-GT3 | X090001 | TBD | 1 | CAT24C512WI-GT3
FSUSB42MUX | X091001,X091002 | TBD | 2 | FSUSB42MUX
ERJ-2RKF22R0X | X092001,X092002,X092003,X092004,X092005,X092006,X092007,X092008,X092009,X092010,X092011,X092012,X092013,X092014,X092015,X092016,X092017,X092018,X092019,X092020,X092021,X092022,X092023,X092024,X092025,X092026,X092027,X092028,X092029,X092030,X092031,X092032,X092033,X092034,X092035,X092036,X092037,X092038,X092039,X092040,X092041,X092042,X092043,X092044,X092045 | TBD | 45 | ERJ-2RKF22R0X
ERJ-2RKF27R0X | X093001,X093002 | TBD | 2 | ERJ-2RKF27R0X
ERJ-P08F10R0V | X094001 | TBD | 1 | ERJ-P08F10R0V
ERJ-P08F49R9V | X095001,X095002 | TBD | 2 | ERJ-P08F49R9V
AS02404PO | X096001 | TBD | 1 | AS02404PO
SC1512-A4 | X097001 | TBD | 1 | SC1512-A4
CMEJ-0413-42-SMT-TR | X098001 | TBD | 1 | CMEJ-0413-42-SMT-TR
SJ-43504-SMT-TR | X099001 | TBD | 1 | SJ-43504-SMT-TR
FTSH-105-01-L-DV-K-P-TR | X100001,X100002,X100003 | TBD | 3 | FTSH-105-01-L-DV-K-P-TR
HLE-107-02-G-DV-PE-LC | X101001 | TBD | 1 | HLE-107-02-G-DV-PE-LC
1125R-SMT-4P | X102001 | TBD | 1 | 1125R-SMT-4P
Si4732-A10-GSR | X103001 | TBD | 1 | Si4732-A10-GSR
MWSA0503S-2R2MT | X104001 | TBD | 1 | MWSA0503S-2R2MT
MWSA0503S-3R3MT | X105001,X105002 | TBD | 2 | MWSA0503S-3R3MT
MWSA0503S-4R7MT | X106001 | TBD | 1 | MWSA0503S-4R7MT
WPN201612H2R2MT | X107001 | TBD | 1 | WPN201612H2R2MT
TCA4307DGKR | X108001 | TBD | 1 | TCA4307DGKR
TCA6424ARGJR | X109001 | TBD | 1 | TCA6424ARGJR
B57332V5103F360 | X110001,X110002,X110003,X110004,X110005,X110006 | TBD | 6 | B57332V5103F360
C1005X5R0J475K050BC | X111001,X111002,X111003,X111004 | TBD | 4 | C1005X5R0J475K050BC
C1608X7R1C105K080AC | X112001,X112002,X112003,X112004,X112005,X112006,X112007,X112008,X112009,X112010,X112011,X112012,X112013,X112014,X112015,X112016,X112017,X112018,X112019,X112020,X112021,X112022,X112023,X112024,X112025,X112026,X112027,X112028,X112029,X112030,X112031,X112032,X112033,X112034,X112035,X112036,X112037 | TBD | 37 | C1608X7R1C105K080AC
CGA5L1X7R1E475K160AC | X113001,X113002,X113003 | TBD | 3 | CGA5L1X7R1E475K160AC
1-2118651-0 | X114001,X114002,X114003 | TBD | 3 | 1-2118651-0
2118651-2 | X115001,X115002 | TBD | 2 | 2118651-2
BQ25798RQMR | X116001 | TBD | 1 | BQ25798RQMR
CSD87313DMS | X117001 | TBD | 1 | CSD87313DMS
MSPM0C1106SDGS20R | X118001,X118002 | TBD | 2 | MSPM0C1106SDGS20R
SN74LVC08APWR | X119001,X119002 | TBD | 2 | SN74LVC08APWR
SN74LVC1G06DCKR | X120001,X120002 | TBD | 2 | SN74LVC1G06DCKR
SN74LVC1G07DCKR | X121001,X121002,X121003,X121004,X121005,X121006,X121007,X121008,X121009,X121010 | TBD | 10 | SN74LVC1G07DCKR
SN74LVC1G08DCKR | X122001,X122002,X122003,X122004 | TBD | 4 | SN74LVC1G08DCKR
SN74LVC1G125DCKR | X123001 | TBD | 1 | SN74LVC1G125DCKR
SN74LVC1G126DCKR | X124001,X124002,X124003,X124004 | TBD | 4 | SN74LVC1G126DCKR
SN74LVC1G17DCKR | X125001 | TBD | 1 | SN74LVC1G17DCKR
SN74LVC1G3157DBVR | X126001 | TBD | 1 | SN74LVC1G3157DBVR
SN74LVC1G74DCUR | X127001 | TBD | 1 | SN74LVC1G74DCUR
SN74LVC2G08DCUR | X128001,X128002,X128003 | TBD | 3 | SN74LVC2G08DCUR
SN74LVC2G66DCUR | X129001,X129002 | TBD | 2 | SN74LVC2G66DCUR
SN74LVC3G07DCUR | X130001,X130002 | TBD | 2 | SN74LVC3G07DCUR
SN74LVC3G34DCUR | X131001 | TBD | 1 | SN74LVC3G34DCUR
TCA9534APWR | X132001,X132002 | TBD | 2 | TCA9534APWR
TCA9535PWR | X133001 | TBD | 1 | TCA9535PWR
TCA9539PWR | X134001 | TBD | 1 | TCA9539PWR
TLV1821DCKR | X135001,X135002 | TBD | 2 | TLV1821DCKR
TLV1824PWR | X136001,X136002 | TBD | 2 | TLV1824PWR
TLV9061IDBVR | X137001,X137002 | TBD | 2 | TLV9061IDBVR
TMUX1136DGSR | X138001,X138002,X138003,X138004 | TBD | 4 | TMUX1136DGSR
TPD2EUSB30ADRTR | X139001,X139002 | TBD | 2 | TPD2EUSB30ADRTR
TPD4E05U06DQAR | X140001,X140002,X140003,X140004,X140005,X140006,X140007,X140008,X140009,X140010,X140011,X140012,X140013 | TBD | 13 | TPD4E05U06DQAR
TPD4S201RUKR | X141001 | TBD | 1 | TPD4S201RUKR
TPD8E003DQDR | X142001,X142002 | TBD | 2 | TPD8E003DQDR
TPS22919DCKR | X143001,X143002,X143003,X143004,X143005,X143006,X143007 | TBD | 7 | TPS22919DCKR
TPS2553DRVR-1 | X144001 | TBD | 1 | TPS2553DRVR-1
TPS25751DREFR | X145001 | TBD | 1 | TPS25751DREFR
TPS259470LRPWR | X146001,X146002 | TBD | 2 | TPS259470LRPWR
TPS25961DRVR | X147001 | TBD | 1 | TPS25961DRVR
TPS25974LRPWR | X148001,X148002 | TBD | 2 | TPS25974LRPWR
TPS3435CAKAGDDFR | X149001 | TBD | 1 | TPS3435CAKAGDDFR
TPS3808G33DBVR | X150001,X150002,X150003,X150004 | TBD | 4 | TPS3808G33DBVR
TPS3839K33DBZR | X151001,X151002 | TBD | 2 | TPS3839K33DBZR
TPS564252DRLR | X152001,X152002,X152003 | TBD | 3 | TPS564252DRLR
TPS629203DRLR | X153001 | TBD | 1 | TPS629203DRLR
TPUL2G223BQBR | X154001 | TBD | 1 | TPUL2G223BQBR
TS5A63157DCKR | X155001,X155002,X155003 | TBD | 3 | TS5A63157DCKR
TVS2200DRVR | X156001 | TBD | 1 | TVS2200DRVR
TXS0102DCUR | X157001 | TBD | 1 | TXS0102DCUR
B0310J50100AHF | X158001 | TBD | 1 | B0310J50100AHF
DC2337J5010AHF | X159001,X159002,X159003 | TBD | 3 | DC2337J5010AHF
0402WGF1333TCE | X160001 | TBD | 1 | 0402WGF1333TCE
0402WGF1603TCE | X161001 | TBD | 1 | 0402WGF1603TCE
0402WGF1651TCE | X162001 | TBD | 1 | 0402WGF1651TCE
0402WGF2201TCE | X163001,X163002,X163003,X163004,X163005,X163006,X163007,X163008,X163009,X163010,X163011,X163012,X163013,X163014,X163015,X163016,X163017,X163018,X163019,X163020,X163021,X163022,X163023 | TBD | 23 | 0402WGF2201TCE
0402WGF2703TCE | X164001 | TBD | 1 | 0402WGF2703TCE
0402WGF5231TCE | X165001 | TBD | 1 | 0402WGF5231TCE
0402WGF8201TCE | X166001 | TBD | 1 | 0402WGF8201TCE
TNPW040210K0BEED | X167001 | TBD | 1 | TNPW040210K0BEED
TNPW040243K7BEED | X168001 | TBD | 1 | TNPW040243K7BEED
TSMP95000TT | X169001 | TBD | 1 | TSMP95000TT
TSOP75238TR | X170001 | TBD | 1 | TSOP75238TR
VEMD1060X01 | X171001 | TBD | 1 | VEMD1060X01
VSMY14940 | X172001 | TBD | 1 | VSMY14940
WSL25125L000FEA | X173001 | TBD | 1 | WSL25125L000FEA
18650 4000mAh | X174001,X174002 | TBD | 2 | 18650 4000mAh
CC0402KRX7R9BB104 | X175001,X175002,X175003,X175004,X175005,X175006,X175007,X175008,X175009,X175010,X175011,X175012,X175013,X175014,X175015,X175016,X175017,X175018,X175019,X175020,X175021,X175022,X175023,X175024,X175025,X175026,X175027,X175028,X175029,X175030,X175031,X175032,X175033,X175034,X175035,X175036,X175037,X175038,X175039,X175040,X175041,X175042,X175043,X175044,X175045,X175046,X175047,X175048,X175049,X175050,X175051,X175052,X175053,X175054,X175055,X175056,X175057,X175058,X175059,X175060,X175061,X175062,X175063,X175064,X175065,X175066,X175067,X175068,X175069,X175070,X175071,X175072,X175073,X175074,X175075,X175076,X175077,X175078,X175079,X175080,X175081,X175082,X175083,X175084,X175085,X175086,X175087,X175088,X175089,X175090,X175091,X175092,X175093,X175094,X175095,X175096,X175097,X175098,X175099,X175100,X175101,X175102,X175103,X175104,X175105,X175106,X175107,X175108,X175109,X175110,X175111,X175112,X175113,X175114,X175115,X175116,X175117,X175118,X175119,X175120,X175121,X175122,X175123,X175124,X175125,X175126,X175127,X175128,X175129,X175130,X175131,X175132,X175133,X175134,X175135,X175136,X175137,X175138,X175139,X175140,X175141,X175142,X175143,X175144,X175145,X175146,X175147 | TBD | 147 | CC0402KRX7R9BB104
CC0603KRX7R0BB104 | X176001 | TBD | 1 | CC0603KRX7R0BB104
RC0402FR-07100KL | X177001,X177002,X177003,X177004,X177005,X177006,X177007,X177008,X177009,X177010,X177011,X177012,X177013,X177014,X177015,X177016,X177017,X177018,X177019,X177020,X177021,X177022,X177023,X177024,X177025,X177026,X177027,X177028,X177029,X177030,X177031,X177032,X177033,X177034,X177035,X177036,X177037,X177038,X177039,X177040 | TBD | 40 | RC0402FR-07100KL
RC0402FR-07100RL | X178001,X178002,X178003,X178004,X178005,X178006,X178007 | TBD | 7 | RC0402FR-07100RL
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

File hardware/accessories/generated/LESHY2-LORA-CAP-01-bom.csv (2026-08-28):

variant | quantity | device_id | mpn | role_instances | unit_price_usd_q100 | cost_status | source_url
LESHY2-LORA-CAP-01-EU868 | 1 | adi_ad8314acpz_rl7 | Analog Devices AD8314ACPZ-RL7 | rf_detector | 2.85700 | priced | https://www.digikey.com/en/products/detail/analog-devices-inc/AD8314ACPZ-RL7/671084
LESHY2-LORA-CAP-01-EU868 | 1 | gct_rfpc_sma31_fn_175_a | GCT RFPC-SMA31-FN-175-A | rf_sma | 2.46456 | priced | https://www.digikey.com/en/products/detail/gct/RFPC-SMA31-FN-175-A/25576371
LESHY2-LORA-CAP-01-EU868 | 1 | microchip_24aa02uidt_i_ot | Microchip 24AA02UIDT-I/OT | identity | 0.30000 | priced | https://www.microchip.com/en-us/product/24aa02uid
LESHY2-LORA-CAP-01-EU868 | 1 | murata_grm188r60j106me47d | Murata GRM188R60J106ME47D | radio_bulk | 0.03770 | priced | https://www.lcsc.com/product-detail/Multilayer-Ceramic-Capacitors-MLCC-SMD-SMT_Murata-Electronics-GRM188R60J106ME47D_C77041.html
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

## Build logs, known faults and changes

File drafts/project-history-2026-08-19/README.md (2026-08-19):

# Archived project history

This directory preserves the former review, decision, finding, status and stage
documents for source archaeology. They are not part of the product site and do
not define the current device. The consolidated product description starts at
the repository root.

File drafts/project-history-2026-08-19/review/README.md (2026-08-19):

# Журнал ревью Leshy2

Этот каталог — единственная точка учёта стадий, решений, находок и доказательств ревью для hardware- и firmware-репозиториев.

## Правила

1. Каждый этап начинается только после проверки его пререквизитов.
2. Требования, решения и находки получают устойчивые идентификаторы: `REQ-*`, `DEC-*`, `FND-*`.
3. Итоговый статус этапа — **«Проведено ревью»** — выставляется только после закрытия находок и воспроизводимой проверки выходных артефактов.
4. Изменение проверенного входа переводит зависимые этапы в **«Требуется повторное ревью»**.
5. Явное несоответствие исправляется и перепроверяется. Неочевидное или потенциально «лишнее» сначала выносится на решение владельца проекта.
6. Значимое улучшение оформляется как предложение и становится решением только после согласия владельца проекта.
7. Ограничения из legacy-документов не наследуются как неизменные. Если найден реалистичный обход, он оформляется как `IMP-*`: старое ограничение, новая возможность или доказательство, цена, риск и затрагиваемые требования. Владелец проекта информируется до изменения scope; после согласия предложение превращается в `DEC-*`.
8. Этап подтверждается автоматически, если его проверки пройдены и по нему нет открытых вопросов, предложений или находок. При наличии хотя бы одного такого пункта статус «Проведено ревью» требует решения владельца проекта.
9. Каждый legacy-пункт `OUT-*` обязан пройти повторную техническую и правовую проверку. Ограничение конкретного старого компонента не считается ограничением продукта: рассматриваются разумная замена, дополнительный модуль и изолированный/проводной лабораторный сценарий. Окончательное исключение получает статус `exclude-proven` только с актуальными первичными источниками, указанной юрисдикцией и оценкой цены обхода.
10. Стоимость сокращается только по правилу `DEC-0005`: экономия должна сохранять принятые функции и измеримые характеристики, safety/legal-гейты, надёжность, автономность, ремонтопригодность и тестируемость. Более дешёвая, но неэквивалентная конфигурация считается отдельным вариантом, а не экономией без потерь.
11. Каждое открытое предложение в журнале и сообщениях владельцу явно помечается `⚠️ Предложение`; принятые или отклонённые предложения предупреждением больше не маркируются.
12. Вопрос о решении всегда содержит необходимый контекст в том же сообщении: текущее состояние, причину вопроса, существенные варианты и их последствия, рекомендацию и один явно сформулированный вопрос. Независимые решения разделяются и по возможности принимаются последовательно; взаимозависимые архитектурные решения принимаются только атомарным пакетом по `DEC-0026`.
13. Корневые README обоих репозиториев описывают целевой готовый продукт только через принятые контракты и всегда отделяют target от текущей реализации.
14. Текущие стадии, доказательства реализации, открытые находки и `⚠️ Предложение` публикуются в `docs/status/current-state.*.md`, а не смешиваются с образом готового продукта.
15. При распространении принятого решения проверяются hardware/firmware, target/current-state и EN/RU пары; открытое условие нельзя превращать в безусловное обещание.
16. Корневые target README — product landing pages, а не review ledger:
    `DEC/REV/FND/IMP` chronology, maturity narrative и open-gate lists живут в
    current-state/review. Exact MPN, diagram и pin mapping допустимы как
    техническая спецификация без истории выбора (`DEC-0060`).

## Реестр

- [Целевой hardware-продукт](../../README.ru.md)
- [Текущее состояние hardware-проработки](../status/current-state.ru.md)
- [Целевой firmware-продукт](https://github.com/anton-vinogradov/esp32-leshy2-firmware/blob/main/README.ru.md)
- [Текущее состояние firmware-проработки](https://github.com/anton-vinogradov/esp32-leshy2-firmware/blob/main/docs/status/current-state.ru.md)
- [Baseline](baseline.md)
- [Этапы и статусы](stages.md)
- [DEC-0001: historical C5 ownership — всё target ownership переоткрыто DEC-0032](decisions/DEC-0001-c5-owns-nrf24-ir.md)
- [DEC-0002: all-in-one, Лаборатория и акт о ненападении](decisions/DEC-0002-project-vision.md)
- [DEC-0003: безопасный TX-дефолт](decisions/DEC-0003-safe-tx-defaults.md)
- [DEC-0004: обязательный пересмотр legacy-исключений](decisions/DEC-0004-reconsider-legacy-exclusions.md)
- [DEC-0005: снижение стоимости без потери продукта](decisions/DEC-0005-zero-loss-cost.md)
- [DEC-0006: внешний GNSS через M5Stack Unit GPS v1.1](decisions/DEC-0006-external-m5-gnss.md)
- [DEC-0007: оба внешних LoRa-варианта — изменено DEC-0008](decisions/DEC-0007-dual-external-lora-profiles.md)
- [DEC-0008: U214 для общепринятых LoRa-частот; E22 не обязателен](decisions/DEC-0008-u214-common-lora-bands.md)
- [DEC-0009: бортовой ES8311 с аппаратным analog bypass](decisions/DEC-0009-onboard-es8311-audio.md)
- [DEC-0010: три уровня функциональности и вложенная контролируемая зона](decisions/DEC-0010-three-functional-levels.md)
- [DEC-0011: целевой README отдельно от текущего состояния](decisions/DEC-0011-target-readme-current-state.md)
- [DEC-0012: решение по IMP-0010 после полного demand model — уточнено DEC-0022](decisions/DEC-0012-defer-imp-0010-to-pin-budget.md)
- [DEC-0013: открытая owner-controlled цепочка подписанных обновлений](decisions/DEC-0013-owner-controlled-signed-updates.md)
- [DEC-0014: NMEA baseline и квалифицируемый advanced CASIC profile](decisions/DEC-0014-casic-gnss-profile.md)
- [DEC-0015: открытый owner-imported SSB patch loader Si4732](decisions/DEC-0015-open-si4732-ssb-patch-loader.md)
- [DEC-0016: conditional SA518 dual-band voice target с SA868S fallback](decisions/DEC-0016-conditional-sa518-dual-band-voice.md)
- [DEC-0017: M5 Unit NFC U216 — первый HF NFC target](decisions/DEC-0017-u216-hf-nfc-backend.md)
- [DEC-0018: двухтрактный consumer IR сохранён; C5/backend открыт](decisions/DEC-0018-dual-path-consumer-ir.md)
- [DEC-0019: калиброванный трёхантенный RPD-hunt без ложных dBm/угла/VSWR](decisions/DEC-0019-calibrated-rpd-three-antenna-hunt.md)
- [DEC-0020: open-first Thread и optional conditional Zigbee](decisions/DEC-0020-open-first-thread-conditional-zigbee.md)
- [DEC-0021: historical S3 BLE profile; target owner переоткрыт DEC-0032](decisions/DEC-0021-s3-native-ble-owner.md)
- [DEC-0022: сначала полный реестр хотелок, затем компоновка и бюджет ресурсов](decisions/DEC-0022-capability-first-before-layout.md)
- [DEC-0023: freeze полного wishlist после делегированного саморевью](decisions/DEC-0023-wishlist-freeze.md)
- [DEC-0024: latched hard STOP с физическим re-arm](decisions/DEC-0024-latched-hard-stop.md)
- [DEC-0025: dedicated 4.0 V VVOICE для SA518](decisions/DEC-0025-dedicated-4v-sa518-voice-rail.md)
- [DEC-0026: атомарная приёмка единой архитектуры](decisions/DEC-0026-atomic-integrated-architecture-acceptance.md)
- [DEC-0027: zero-based architecture только от capabilities, не legacy layout](decisions/DEC-0027-zero-based-capability-driven-architecture.md)
- [DEC-0028: historical `PKG-0001/SYN-3A` choice — superseded by DEC-0032](decisions/DEC-0028-accept-zero-based-syn-3a.md)
- [DEC-0029: conditional C5 revision rule; C5 not selected](decisions/DEC-0029-c5-v1.2-production-floor.md)
- [DEC-0030: historical vendored CAD decision — active snapshot archived](decisions/DEC-0030-vendored-critical-cad-libraries.md)
- [DEC-0031: independent service-access requirement retained; exact topology reopened](decisions/DEC-0031-permanent-three-domain-development-access.md)
- [DEC-0032: architecture reopened; product design/optimality before CAD](decisions/DEC-0032-reopen-product-design-before-cad.md)
- [DEC-0033: external passive M5-style Port-B iButton profile; no base pad](decisions/DEC-0033-external-m5-ibutton-profile.md)
- [DEC-0034: M5-first Unit/Cap + separate high-throughput; no native M5-Bus](decisions/DEC-0034-m5-first-two-tier-expansion.md)
- [DEC-0035: historical personal FIDO authenticator — target superseded DEC-0039](decisions/DEC-0035-open-personal-fido-authenticator.md)
- [DEC-0036: product haptic rejected; generic expansion remains](decisions/DEC-0036-no-product-haptic.md)
- [DEC-0037: optional external IMU measurement pose](decisions/DEC-0037-optional-external-imu-measurement-pose.md)
- [DEC-0038: phone-assisted text without an integrated product keyboard](decisions/DEC-0038-phone-assisted-text-no-integrated-keyboard.md)
- [DEC-0039: radio/key mission scope; FIDO/generic host removed, BadUSB optional](decisions/DEC-0039-radio-key-scope-correction.md)
- [DEC-0040: 6 GHz/Wi-Fi 6E fully rejected; 2.4/5 retained](decisions/DEC-0040-reject-6ghz-wifi6e.md)
- [DEC-0041: logical/electrical feasibility before adapted physical layout](decisions/DEC-0041-electrical-feasibility-before-physical-layout.md)
- [DEC-0042: one machine-readable source for exact devices, pins and later layout](decisions/DEC-0042-single-source-architecture-data.md)
- [DEC-0043: task/dirty-region display performance](decisions/DEC-0043-task-based-display-performance.md)
- [DEC-0044: delegated non-interference layout search; G2F-3I leading paper map](decisions/DEC-0044-delegated-noninterference-layout.md)
- [DEC-0045: one active signal group; SG-N24 is a three-radio full-mix group](decisions/DEC-0045-one-active-signal-group.md)
- [DEC-0046: unused interfaces are quiet by default](decisions/DEC-0046-unused-interface-quiet-by-default.md)
- [DEC-0047: qualified internal nRF mix with an external observer](decisions/DEC-0047-qualified-nrf-mix-with-external-observer.md)
- [DEC-0048: external SMA antenna bank; three compact nRF IPEX paths](decisions/DEC-0048-external-sma-antenna-bank.md)
- [DEC-0049: nine dedicated external SMA paths](decisions/DEC-0049-nine-dedicated-external-sma-paths.md)
- [DEC-0050: ecosystem-aligned 2 RP-SMA + 7 standard SMA](decisions/DEC-0050-ecosystem-aligned-sma-polarity.md)
- [DEC-0051: reviewed principled pinout is the visible G3 working design](decisions/DEC-0051-principled-pinout-as-working-design.md)
- [DEC-0052: direct QSPI display path on S3](decisions/DEC-0052-qspi-first-display-path.md)
- [DEC-0053: 3.5-inch portrait QSPI display class](decisions/DEC-0053-new-35in-qspi-display-class.md)
- [DEC-0054: fail-safe complete audio path](decisions/DEC-0054-fail-safe-complete-audio-path.md)
- [DEC-0055: profiled external antenna kit](decisions/DEC-0055-profiled-external-antenna-kit.md)
- [DEC-0056: prefer one-stop PCBA/antenna kitting with fallback](decisions/DEC-0056-prefer-one-stop-kitting-with-fallback.md)
- [DEC-0057: U214 rear dock above the batteries](decisions/DEC-0057-u214-rear-dock-above-batteries.md)
- [DEC-0058: finish internals before resuming integrated mockup](decisions/DEC-0058-internals-before-integrated-mockup.md)
- [DEC-0059: full S3/C5 service over 1-bit SDIO](decisions/DEC-0059-full-service-over-1bit-sdio.md)
- [DEC-0060: GitHub target README are product landing pages](decisions/DEC-0060-github-target-product-site.md)
- [DEC-0061: AON hard STOP and per-path TX evidence — принят A, I2 reviewed](decisions/DEC-0061-aon-stop-and-per-path-tx-evidence.md)
- [DEC-0062: two individually replaceable cells — 2S confirmed by DEC-0065](decisions/DEC-0062-individually-replaceable-2s-cells.md)
- [DEC-0063: sink-only USB-PD up to 30 W](decisions/DEC-0063-sink-only-30w-usb-pd-power-path.md)
- [DEC-0064: two physical slots retained; topology comparison completed](decisions/DEC-0064-reopen-battery-electrical-topology.md)
- [DEC-0065: supervised 2S battery topology](decisions/DEC-0065-supervised-2s-battery-topology.md)
- [DEC-0066: MAX17320 plus MSPM0 fail-closed 2S manager](decisions/DEC-0066-max17320-mspm0-fail-closed-manager.md)
- [DEC-0067: no in-device deep-cell recovery; exact switching path](decisions/DEC-0067-no-in-device-deep-cell-recovery.md)
- [DEC-0068: independent fixed AON/3.3/4.0/5.0-V downstream rails](decisions/DEC-0068-separate-fixed-downstream-rails.md)
- [DEC-0069: latch-off external accessory eFuse](decisions/DEC-0069-latch-off-external-efuse.md)
- [DEC-0070: enable-qualified switched-rail PG evidence](decisions/DEC-0070-enable-qualified-switched-rail-pg.md)
- [DEC-0071: controlled startup and bounded post-start accessory transient](decisions/DEC-0071-post-start-accessory-transient-profile.md)
- [DEC-0072: exact converter energy and fixed-feedback passives](decisions/DEC-0072-exact-converter-energy-feedback-passives.md)
- [DEC-0073: exact converter enable, PG and fault passives](decisions/DEC-0073-exact-converter-control-passives.md)
- [DEC-0074: 10-Ohm bounded pack diagnostic with independent <=50-ms cutoff](decisions/DEC-0074-bounded-pack-diagnostic-pulse.md)
- [DEC-0075: exact 750-kHz BQ25798 passive and reset profile](decisions/DEC-0075-exact-bq25798-passive-profile.md)
- [DEC-0076: exact TPS25751D/CAT24 support and autonomous SafeMode startup](decisions/DEC-0076-exact-tps25751-eeprom-support-profile.md)
- [DEC-0077: exact polarized 1048P holder and qualified protected-cell profile](decisions/DEC-0077-keystone-1048p-qualified-cell-profile.md)
- [DEC-0078: hardware refractory lockout for pack diagnostics](decisions/DEC-0078-hardware-diagnostic-refractory-lockout.md)
- [DEC-0079: XTAR 18650 4000mAh exact first qualification target](decisions/DEC-0079-xtar-18650-4000mah-qualification-target.md)
- [DEC-0080: exact AON-PG/POR/main-rail sequence](decisions/DEC-0080-exact-aon-pg-por-main-sequence.md)
- [DEC-0081: independent AON/main/voice post-buck containment](decisions/DEC-0081-independent-internal-rail-containment.md)
- [DEC-0082: I3 paper electrical closure](decisions/DEC-0082-i3-paper-closure.md)
- [DEC-0083: exact protected product USB-C port](decisions/DEC-0083-exact-protected-product-usb-port.md)
- [DEC-0084: exact protected display electrical endpoint](decisions/DEC-0084-exact-protected-display-electrical-endpoint.md)
- [DEC-0085: exact isolated microSD electrical endpoint](decisions/DEC-0085-exact-isolated-microsd-electrical-endpoint.md)
- [DEC-0086: complete local controls and direct encoder capture](decisions/DEC-0086-complete-local-controls-and-direct-encoder.md)
- [DEC-0087: exact control switch and protection endpoint](decisions/DEC-0087-exact-control-switch-and-protection-endpoint.md)
- [DEC-0088: exact integrated ST77922 touch controller and IRQ](decisions/DEC-0088-exact-integrated-touch-controller-and-irq.md)
- [DEC-0089: consolidated I4 electrical closure](decisions/DEC-0089-consolidated-i4-electrical-closure.md)
- [DEC-0090: I5 exact audio and receiver paper closure](decisions/DEC-0090-i5-exact-audio-and-receiver-paper-closure.md)
- [DEC-0091: exact three-nRF electrical endpoint](decisions/DEC-0091-exact-three-nrf-electrical-endpoint.md)
- [DEC-0092: exact S3/C5 native RF endpoints](decisions/DEC-0092-exact-s3-c5-native-rf-endpoints.md)
- [DEC-0093: exact CC1101 three-band electrical endpoint](decisions/DEC-0093-exact-cc1101-three-band-endpoint.md)
- [DEC-0094: exact SA518 broadband RF endpoint](decisions/DEC-0094-exact-sa518-broadband-rf-endpoint.md)
- [DEC-0095: exact dual-receiver, TX and optical-evidence IR endpoint](decisions/DEC-0095-exact-ir-endpoint.md)
- [DEC-0096: exact Si4732 dual-input RF endpoint](decisions/DEC-0096-exact-si4732-dual-input-rf-endpoint.md)
- [DEC-0097: one-group I6 qualification and fixtures](decisions/DEC-0097-one-group-i6-qualification-and-fixtures.md)
- [DEC-0098: exact independent M5 expansion boundary](decisions/DEC-0098-exact-independent-m5-expansion-boundary.md)
- [DEC-0099: exact three-domain service/recovery boundary](decisions/DEC-0099-exact-three-domain-service-recovery-boundary.md)
- [DEC-0100: exact MAX17320 2S support closure](decisions/DEC-0100-exact-max17320-2s-support-closure.md)
- [DEC-0101: exact actual-TX threshold and domain isolation](decisions/DEC-0101-exact-actual-tx-threshold-and-domain-isolation.md)
- [DEC-0102: exact SC1512-A4 order identity](decisions/DEC-0102-exact-sc1512-a4-order-identity.md)
- [DEC-0103: separate architecture evidence nodes from purchase BOM](decisions/DEC-0103-separate-architecture-nodes-from-purchase-bom.md)
- [DEC-0104: complete no-silent-substitution policy](decisions/DEC-0104-complete-no-silent-substitution-policy.md)
- [DEC-0105: machine-readable quantity-100 cost evidence](decisions/DEC-0105-machine-readable-quantity-100-cost-evidence.md)
- [DEC-0106: explicit gates for unpriced purchase lines](decisions/DEC-0106-explicit-unpriced-cost-gates.md)
- [ANT-0001: exact external-SMA path inventory — проведено ревью фактов](architecture/ANT-0001-external-sma-path-inventory.md)
- [ANT-0002: current-orderable antenna shortlist — факты reviewed, qualification open](architecture/ANT-0002-current-orderable-antenna-shortlist.md)
- [MFG-0001: one-stop PCBA + loose-antenna kitting feasibility — факты reviewed](architecture/MFG-0001-one-stop-pcba-antenna-kitting.md)
- [PIN-0003: G2F-3I principled pinout — current paper mapping проведено ревью](architecture/PIN-0003-g2f-3i-principled-pinout.md)
- [AUDIO-0001: ES8311 exact digital/contact fit — проведено ревью, analog topology open](architecture/AUDIO-0001-es8311-exact-electrical-fit.md)
- [AUDIO-0002: complete fail-safe audio path — вариант A принят DEC-0054](architecture/AUDIO-0002-complete-audio-path-comparison.md)
- [AUDIO-0003: exact complete audio and receiver endpoint — проведено ревью paper electrical block](architecture/AUDIO-0003-exact-audio-and-receiver-endpoint.md)
- [N24E-0001: exact three-nRF electrical endpoint — проведено ревью paper subblock](architecture/N24E-0001-exact-three-nrf-electrical-endpoint.md)
- [NAT-0001: exact S3/C5 native RF evidence endpoints — проведено ревью paper subblock](architecture/NAT-0001-exact-s3-c5-native-rf-evidence-endpoints.md)
- [CCRF-0001: exact CC1101 three-band endpoint — проведено ревью paper subblock](architecture/CCRF-0001-exact-cc1101-three-band-endpoint.md)
- [VRF-0001: exact SA518 broadband RF endpoint — проведено ревью paper subblock](architecture/VRF-0001-exact-sa518-broadband-rf-endpoint.md)
- [IRF-0001: exact dual-receiver, TX and optical-evidence endpoint — проведено ревью paper subblock](architecture/IRF-0001-exact-dual-receiver-transmit-and-optical-evidence-endpoint.md)
- [RXF-0001: exact Si4732 dual-input receive frontend — проведено ревью paper subblock](architecture/RXF-0001-exact-si4732-dual-input-receive-frontend.md)
- [COX-0001: consolidated I6 qualification matrix — проведено ревью paper scope, physical HIL open](architecture/COX-0001-consolidated-i6-qualification-matrix.md)
- [EXP-0001: exact independent M5 Cap/Unit boundary — проведено ревью paper subblock, physical HIL open](architecture/EXP-0001-exact-m5-expansion-boundary.md)
- [SVC-0002: exact three-domain service/recovery boundary — проведено ревью paper subblock, physical HIL open](architecture/SVC-0002-exact-three-domain-service-recovery-boundary.md)
- [INT-0001: dependency-ordered internal-design closure — I1…I9 working-candidate paper scopes reviewed, G3 active](architecture/INT-0001-internal-design-closure-sequence.md)
- [I9-0001: joint candidate paper-projection self-review — проведено ревью, not G7 atomic architecture](architecture/I9-0001-joint-candidate-paper-projection-review.md)
- [DSP-0007: exact integrated ST77922 touch endpoint — проведено ревью paper endpoint](architecture/DSP-0007-exact-integrated-st77922-touch-endpoint.md)
- [IOX-0001: consolidated I4 electrical closure — проведено ревью paper block](architecture/IOX-0001-consolidated-i4-electrical-closure.md)
- [PWR-0009: enable-qualified switched-rail PG evidence — проведено ревью принципиальной схемы](architecture/PWR-0009-enable-qualified-switched-rail-pg.md)
- [PWR-0010: exact external-eFuse passive profile — проведено ревью принципиальной схемы](architecture/PWR-0010-external-efuse-passive-profile.md)
- [PWR-0011: exact application-converter passive profile — проведено ревью принципиальной схемы](architecture/PWR-0011-application-converter-passive-profile.md)
- [PWR-0012: exact converter control-passive profile — проведено ревью принципиальной схемы](architecture/PWR-0012-exact-converter-control-passives.md)
- [PWR-0013: historical pack diagnostic frontend — corrected by PWR-0017](architecture/PWR-0013-exact-pack-diagnostic-frontends.md)
- [PWR-0014: exact BQ25798 inductor/passive/reset profile — проведено ревью принципиальной схемы](architecture/PWR-0014-exact-bq25798-passive-profile.md)
- [PWR-0015: exact TPS25751D/CAT24 support profile — проведено ревью принципиальной схемы](architecture/PWR-0015-exact-tps25751-eeprom-support-profile.md)
- [PWR-0016: exact 1048P holder and three-NTC coupling — проведено ревью бумажной схемы](architecture/PWR-0016-keystone-1048p-holder-and-ntc-coupling.md)
- [PWR-0017: exact hardware diagnostic refractory lockout — проведено ревью бумажной схемы](architecture/PWR-0017-hardware-diagnostic-refractory-lockout.md)
- [PWR-0018: exact XTAR 18650 4000mAh cell profile — проведено ревью paper fit](architecture/PWR-0018-xtar-18650-4000mah-cell-profile.md)
- [PWR-0019: exact source sequence and input-power reserve — проведено ревью paper sequence](architecture/PWR-0019-exact-source-sequence-and-power-reserve.md)
- [PWR-0020: independent post-buck containment — проведено ревью paper calculation/single-fault behavior](architecture/PWR-0020-independent-post-buck-containment.md)
- [PWR-0021: I3 consolidated paper closure — проведено ревью](architecture/PWR-0021-i3-consolidated-paper-closure.md)
- [PWR-0022: exact MAX17320 2S support — проведено ревью paper electrical scope](architecture/PWR-0022-exact-max17320-2s-support-profile.md)
- [USB-0001: exact product USB-C receptacle and four-line protection — проведено ревью paper endpoint](architecture/USB-0001-exact-product-usb-c-and-protection.md)
- [SAFE-0001: AON hard STOP and per-path actual-TX evidence — prerequisites reviewed](architecture/SAFE-0001-aon-stop-and-tx-evidence-options.md)
- [REQ-SYS-0001: System/UI/storage platform contract — проведено ревью](requirements/REQ-SYS-0001-system-ui-storage.md)
- [REQ-GNSS-0001: navigation/time/integrity contract — проведено ревью](requirements/REQ-GNSS-0001-navigation-integrity.md)
- [REQ-RX-0001: Si4732 receiver/scan/record/decode contract — проведено ревью](requirements/REQ-RX-0001-si4732-receiver.md)
- [REQ-VHF-0001: analog voice/modem/relay contract — проведено ревью](requirements/REQ-VHF-0001-analog-voice-modem.md)
- [REQ-NFC-0001: HF NFC/RFID contract — проведено ревью](requirements/REQ-NFC-0001-hf-nfc-rfid.md)
- [REQ-IR-0001: consumer IR capability — проведено ревью; owner открыт](requirements/REQ-IR-0001-consumer-infrared.md)
- [REQ-N24-0001: 3×nRF24 full-function contract — capability проведено ревью, layout после wishlist freeze](requirements/REQ-N24-0001-three-nrf24-raw-2g4.md)
- [REQ-W5-0001: dual-band Wi-Fi/IEEE 802.15.4 capability — backend открыт](requirements/REQ-W5-0001-c5-wifi-ieee802154.md)
- [REQ-BLE-0001: native BLE capability — owner открыт](requirements/REQ-BLE-0001-native-ble-and-security.md)
- [REQ-W24-0001: Wi-Fi 2.4/ESP-NOW capability — backend открыт](requirements/REQ-W24-0001-s3-wifi-espnow.md)
- [REQ-SUB-0001: CC1101 Sub-GHz contract — проведено ревью](requirements/REQ-SUB-0001-cc1101-subghz.md)
- [REQ-LORA-0001: external SX1262 contract — проведено ревью](requirements/REQ-LORA-0001-external-sx1262.md)
- [REQ-X-0001: cross-session/privacy/performance contract — проведено ревью](requirements/REQ-X-0001-cross-session-performance.md)
- [REQ-IBTN-0001: external iButton/1-Wire contact-tool contract — проведено ревью capability](requirements/REQ-IBTN-0001-ibutton-one-wire.md)
- [REQ-EXT-0001: M5-first two-tier expansion contract — проведено ревью требований](requirements/REQ-EXT-0001-m5-first-expansion-platform.md)
- [REQ-FIDO-0001: historical personal FIDO authenticator — removed from target](requirements/REQ-FIDO-0001-open-personal-authenticator.md)
- [REQ-IMU-0001: external measurement-pose IMU — проведено ревью требований](requirements/REQ-IMU-0001-external-measurement-pose.md)
- [REQ-SCOPE-0001: radio/key product boundary — проведено ревью требований](requirements/REQ-SCOPE-0001-radio-key-product-boundary.md)
- [FND-0001: конфликт единственного GP-SPI C5](findings/FND-0001-c5-single-gp-spi.md)
- [FND-0002: владелец BLE расходился между legacy-репозиториями — закрыто DEC-0021](findings/FND-0002-ble-owner-conflict.md)
- [FND-0003: audio-архитектура принята, implementation proof ожидается](findings/FND-0003-missing-mcu-audio-path.md)
- [FND-0004: бортовой и внешний GNSS расходятся — закрыто DEC-0006](findings/FND-0004-gnss-scope-conflict.md)
- [FND-0005: неверная распиновка audio Si4732 — закрыто исправлением](findings/FND-0005-si4732-audio-pin-map.md)
- [FND-0006: конфликт `U13` между UI matrix и audio-control](findings/FND-0006-u13-ui-audio-pin-collision.md)
- [FND-0007: I²C-only STOP — архитектурно исправлено DEC-0024, схема/HIL открыты](findings/FND-0007-stop-is-only-i2c-input.md)
- [FND-0008: legacy System/UI смешивал функции с реализацией — закрыто](findings/FND-0008-legacy-system-ui-contract-conflicts.md)
- [FND-0009: legacy u-blox GNSS расходится с принятым AT6668 — закрыто DEC-0014](findings/FND-0009-legacy-ublox-vs-at6668.md)
- [FND-0010: SSB patch и synchronous-AM имеют разные proof/license состояния — закрыто DEC-0015](findings/FND-0010-si4732-ssb-patch-and-sync-am.md)
- [FND-0011: SA868 floating TX controls и high-power hardware default — исправлено консервативно](findings/FND-0011-sa868-unsafe-tx-defaults.md)
- [FND-0012: SA868 API/диапазон не доказывает весь legacy scope — закрыто DEC-0016](findings/FND-0012-sa868-api-and-band-overclaims.md)
- [FND-0013: VOX не имеет microphone-capture path](findings/FND-0013-sa868-vox-has-no-microphone-capture.md)
- [FND-0014: firmware preset не создаёт licence-exempt PMR446 equipment — закрыто на уровне требований](findings/FND-0014-pmr446-preset-is-not-compliance.md)
- [FND-0015: Grove NFC Unit требуют 5 V, текущие порты дают 3.3 V](findings/FND-0015-nfc-unit-power-profile-mismatch.md)
- [FND-0016: NFC frontend не доказывает universal emulation/relay/key recovery — закрыто DEC-0017](findings/FND-0016-nfc-emulation-relay-and-attack-overclaims.md)
- [FND-0017: IR TX artifact не fail-safe/qualified — частично исправлено](findings/FND-0017-ir-tx-artifact-not-safe-or-qualified.md)
- [FND-0018: fixed 38 kHz demodulator не учит carrier — закрыто DEC-0018](findings/FND-0018-ir-fixed-demodulator-cannot-learn-carrier.md)
- [FND-0019: 3×nRF24 artifact не C5-owned/fail-safe/qualified — частично исправлено](findings/FND-0019-nrf24-artifact-not-c5-safe-or-qualified.md)
- [FND-0020: nRF24 RPD не является RSSI/VSWR — закрыто DEC-0019](findings/FND-0020-nrf24-rpd-is-not-rssi-or-vswr.md)
- [FND-0021: nRF24 security/BLE/licence overclaims](findings/FND-0021-nrf24-security-ble-and-license-overclaims.md)
- [FND-0022: C5 module/ANT1/ANT2/RF artifact — частично исправлено](findings/FND-0022-c5-module-antenna-and-radio-artifact-not-qualified.md)
- [FND-0023: C5 public Wi-Fi API и patched binary overclaims](findings/FND-0023-c5-wifi-public-api-and-patched-blob-overclaims.md)
- [FND-0024: 5 GHz DFS/country/PMF/privacy gates](findings/FND-0024-c5-dfs-country-privacy-and-pmf-gates.md)
- [FND-0025: passive-only 802.15.4 ceiling — закрыто DEC-0020](findings/FND-0025-c5-802154-passive-only-ceiling-and-coexistence.md)
- [FND-0026: native BLE scan не является connection sniff, stable identity или дальномером](findings/FND-0026-native-ble-is-not-connection-sniff-identity-or-distance.md)
- [FND-0027: BLE protocol/emulation/attack claims требуют corpus, rights и security gates](findings/FND-0027-ble-protocol-emulation-attack-and-license-overclaims.md)
- [FND-0028: владелец 3×nRF24 переоткрыт; layout после wishlist freeze](findings/FND-0028-nrf24-owner-reopened-by-full-function-resource-audit.md)
- [FND-0029: memory variant, inter-MCU transport и recovery делят scarce pins](findings/FND-0029-memory-transport-recovery-pin-coupling.md)
- [FND-0030: legacy 5 V voice rail — архитектурно исправлено DEC-0025, схема/HIL открыты](findings/FND-0030-sa518-legacy-5v-exceeds-accepted-1w-profile.md)
- [FND-0031: UI count дважды включил STOP — закрыто исправлением](findings/FND-0031-ui-control-count-double-counted-stop.md)
- [FND-0032: U214 RESET отменяет вторую «свободную» LoRa line — candidate исправлен](findings/FND-0032-u214-reset-invalidates-two-freed-lora-lines.md)
- [FND-0033: legacy layout assumptions leaked into synthesis — исправлено перезапуском](findings/FND-0033-legacy-layout-assumptions-leaked-into-synthesis.md)
- [FND-0034: all-external-I/O S3 placement overflow — исправлено без потери функций](findings/FND-0034-all-external-io-overflows-s3-pin-map.md)
- [FND-0035: RP2354A A4 stock/order-code correction](findings/FND-0035-rp2354a-order-code-stock-correction.md)
- [FND-0036: current CAD не представлял exact compute target — закрыто DEC-0030](findings/FND-0036-current-cad-cannot-represent-target-compute.md)
- [FND-0037: C5 USB-download strap был ошибочно назван GPIO26 — исправлено на GPIO28](findings/FND-0037-c5-usb-download-strap-misidentified.md)
- [FND-0038: permanent C5 UART уменьшает generic reserve с семи до пяти — исправлено](findings/FND-0038-permanent-c5-uart-reduces-generic-reserve.md)
- [FND-0039: architecture frozen before product design/optimality — closed by reopen](findings/FND-0039-architecture-frozen-before-product-design.md)
- [FND-0040: current competitor benchmark missing — closed by repeat G2 review](findings/FND-0040-current-competitor-benchmark-missing.md)
- [FND-0041: owner assumptions remained in neutral inputs — исправлено](findings/FND-0041-owner-assumptions-remained-in-neutral-inputs.md)
- [FND-0042: M5 is not one interface or a 90% turnkey solution — product model исправлен](findings/FND-0042-m5-is-not-one-interface-or-ninety-percent-solution.md)
- [FND-0043: historical FIDO assurance boundary — target removed DEC-0039](findings/FND-0043-open-multitool-is-not-a-hardware-security-key.md)
- [FND-0044: external vibrator is not automatically on-device haptics](findings/FND-0044-external-vibrator-is-not-automatically-device-haptics.md)
- [FND-0045: external 6-axis IMU is not device heading or RF bearing](findings/FND-0045-external-six-axis-imu-is-not-device-heading-or-rf-bearing.md)
- [FND-0046: legacy UI layout is not a target constraint](findings/FND-0046-legacy-ui-layout-is-not-a-target-constraint.md)
- [FND-0047: Full-Speed USB is not the raw-SDR/high-throughput tier](findings/FND-0047-full-speed-usb-is-not-raw-sdr-tier.md)
- [FND-0048: accepted 5 GHz does not imply 6 GHz/Wi-Fi 6E — fixed DEC-0040](findings/FND-0048-5ghz-does-not-imply-6ghz.md)
- [FND-0049: exact MCU map lacked full real-device provenance — process fixed, parts open](findings/FND-0049-exact-pin-map-lacked-device-provenance.md)
- [FND-0050: nRF24 is NRND; CC1101 is ACTIVE — lifecycle generalization corrected](findings/FND-0050-legacy-radio-lifecycle-risk.md)
- [FND-0051: legacy display connector/throughput do not match real modules](findings/FND-0051-legacy-display-interface-and-throughput.md)
- [FND-0052: draft maps did not close slow control — fixed in G2F-3I](findings/FND-0052-draft-maps-do-not-close-slow-control.md)
- [FND-0053: arbitrary co-located RF concurrency is impossible](findings/FND-0053-arbitrary-colocated-rf-concurrency-is-impossible.md)
- [FND-0054: three-nRF digital concurrency does not prove mixed-RF sensitivity](findings/FND-0054-three-nrf-mix-needs-rf-acceptance.md)
- [FND-0055: legacy one-port Si4732 hides separate FMI and AMI domains](findings/FND-0055-si4732-two-antenna-input-domains.md)
- [FND-0056: exact SA518 has no SQ pin; activity/update proof remains](findings/FND-0056-sa518-has-no-dedicated-sq-pin.md)
- [FND-0057: Ebyte IPX mating family is unproven — machine source corrected](findings/FND-0057-ebyte-ipx-mating-family-unproven.md)
- [FND-0058: antenna sourcing shortlist does not close production qualification](findings/FND-0058-antenna-sourcing-and-qualification-gate-open.md)
- [FND-0059: stale post-quiet-state pin budget — corrected and regression-protected](findings/FND-0059-stale-pin-budget-after-quiet-state.md)
- [FND-0060: abstract electrical endpoints block final pinout](findings/FND-0060-abstract-electrical-endpoints-block-final-pinout.md)
- [FND-0061: stale 256-byte display quantum after U214 moved to RP](findings/FND-0061-stale-display-quantum-after-u214-move.md)
- [FND-0062: old 4-inch is not the QSPI path — закрыто DEC-0053](findings/FND-0062-old-four-inch-display-is-not-qspi.md)
- [FND-0063: HMX035CTFT-001 MPN was disclosed — закрыто исправлением](findings/FND-0063-hmx035ctft-mpn-was-disclosed.md)
- [FND-0064: stage ledger kept stale S3 budget — закрыто исправлением](findings/FND-0064-stale-s3-budget-in-stage-ledger.md)
- [FND-0065: ES8311 CE is address strap and analog pairs are differential](findings/FND-0065-es8311-ce-and-differential-path.md)
- [FND-0066: audio optimum selected DEC-0054; analog/HIL closure open](findings/FND-0066-es8311-line-input-and-pam-differential-capability.md)
- [FND-0067: RX select/reset bypass fixed architecturally; HIL open](findings/FND-0067-audio-source-select-and-reset-bypass.md)
- [FND-0068: U214 envelope missing from legacy layout — исправлено DEC-0057](findings/FND-0068-u214-envelope-missing-from-legacy-layout.md)
- [FND-0069: U214 host connector MPN/stack-up open](findings/FND-0069-u214-host-connector-mpn-and-stack-up-open.md)
- [FND-0070: full service access conflicted with 4-bit C5 SDIO — закрыто DEC-0059](findings/FND-0070-service-access-conflicts-with-4bit-sdio.md)
- [FND-0071: STOP/evidence coverage missed RP and 3×nRF/CC — paper mismatch closed DEC-0061; HIL open](findings/FND-0071-hard-stop-and-tx-evidence-coverage.md)
- [FND-0072: target README contained engineering chronology — закрыто DEC-0060](findings/FND-0072-target-readmes-contained-engineering-chronology.md)
- [FND-0073: legacy power sheet is not a current target — electrical topology reopened](findings/FND-0073-legacy-power-is-not-a-current-target.md)
- [FND-0074: TPS25751 requires an external boot image — corrected; recovery HIL open](findings/FND-0074-tps25751-requires-external-boot-image.md)
- [FND-0075: a pack gauge is not a loose-cell admission controller](findings/FND-0075-pack-gauge-is-not-loose-cell-admission.md)
- [FND-0076: parallel removable cells shift, not remove, admission risk](findings/FND-0076-parallel-cells-shift-admission-risk.md)
- [FND-0077: MAX17320 prequal is a linear CHG-FET mode — closed DEC-0067; regression fact retained](findings/FND-0077-max17320-prequal-is-a-linear-fet-mode.md)
- [FND-0078: MSPM0 PA24 forbids battery-divider injection current — исправлено переносом на PA25/PA26](findings/FND-0078-mspm0-pa24-forbids-injection-current.md)
- [FND-0079: product USB is an I4 consumer, not an I3 passive — исправлено](findings/FND-0079-product-usb-is-an-i4-consumer.md)
- [FND-0080: TPS autonomous startup and complete-bus pulls were incomplete — исправлено](findings/FND-0080-tps25751-autonomous-start-and-bus-pulls.md)
- [FND-0081: holder name did not prove contacts or NTC coupling — исправлено на бумажном уровне](findings/FND-0081-holder-contact-and-thermal-proof-gap.md)
- [FND-0082: TPUL package map and repeat-pulse safety were incomplete — исправлено на бумажном уровне](findings/FND-0082-tpul-pin-map-and-repeat-pulse-gap.md)
- [FND-0083: generic protected-cell placeholder blocked real limits — исправлено exact target](findings/FND-0083-generic-cell-placeholder-blocked-real-limits.md)
- [FND-0084: abstract main source sequencer — исправлено exact AON-PG/POR chain](findings/FND-0084-abstract-main-source-sequencer.md)
- [FND-0085: internal buck high-side shorts were not independently contained — исправлено](findings/FND-0085-uncontained-internal-buck-high-side-short.md)
- [FND-0086: I3 paper and HIL closure were conflated — исправлено](findings/FND-0086-i3-paper-and-hil-closure-were-conflated.md)
- [FND-0087: product USB ended on an abstract, unprotected endpoint — исправлено](findings/FND-0087-product-usb-ended-on-abstract-port.md)
- [FND-0088: display endpoint still contained abstract circuits — исправлено на бумажном уровне](findings/FND-0088-display-endpoint-still-contained-abstract-circuits.md)
- [FND-0089: microSD endpoint was back-powered and unprotected — исправлено на бумажном уровне](findings/FND-0089-microsd-endpoint-was-backpowered-and-unprotected.md)
- [FND-0090: required local controls were dropped — исправлено](findings/FND-0090-required-local-controls-were-dropped.md)
- [FND-0091: TCA9534A address range was wrong — исправлено](findings/FND-0091-tca9534a-address-range-was-wrong.md)
- [FND-0092: control switch current and ESD were abstract — исправлено](findings/FND-0092-control-switch-current-and-esd-were-abstract.md)
- [FND-0093: touch-controller identity and IRQ polarity were left open — исправлено](findings/FND-0093-touch-controller-identity-and-polarity-were-left-open.md)
- [FND-0094: consolidated I4 audit found hidden interface gaps — исправлено](findings/FND-0094-consolidated-i4-audit-found-hidden-interface-gaps.md)
- [FND-0095: abstract audio hid power-domain and endpoint failures — исправлено](findings/FND-0095-i5-abstract-audio-hidden-power-domain-failures.md)
- [FND-0096: nRF quiet state and TX evidence were not physical — исправлено](findings/FND-0096-nrf-quiet-state-and-tx-evidence-were-not-physical.md)
- [FND-0097: native RF evidence stopped before the real feed — исправлено на бумажном уровне](findings/FND-0097-native-rf-evidence-stopped-before-the-real-feed.md)
- [FND-0098: CC1101 single-ended band switching was invalid — исправлено на бумажном уровне](findings/FND-0098-cc1101-single-ended-band-switch-was-invalid.md)
- [FND-0099: SA518 RF feed and evidence were not electrically closed — исправлено на бумажном уровне](findings/FND-0099-sa518-rf-feed-and-evidence-were-not-electrically-closed.md)
- [FND-0100: IR endpoint was abstract and not production-shaped — исправлено на бумажном уровне](findings/FND-0100-ir-endpoint-was-abstract-and-not-production-shaped.md)
- [FND-0101: Si4732 RF inputs remained abstract — исправлено на бумажном уровне](findings/FND-0101-si4732-rf-inputs-remained-abstract.md)
- [FND-0102: Si4732 SOIC-16 contact map was shifted — исправлено, проведено ревью](findings/FND-0102-si4732-soic16-contact-map-was-shifted.md)
- [FND-0103: cross-group HIL could reopen forbidden concurrency — исправлено, проведено ревью](findings/FND-0103-cross-group-hil-could-reopen-forbidden-concurrency.md)
- [FND-0104: monolithic receiver/audio quiet contract was contradictory — исправлено, проведено ревью](findings/FND-0104-monolithic-receiver-audio-quiet-contract.md)
- [FND-0105: M5 connector has no presence contact — исправлено, проведено ревью](findings/FND-0105-no-m5-presence-contact.md)
- [FND-0106: reset fan-out contended service controls — исправлено, проведено ревью](findings/FND-0106-reset-fanout-contended-service-controls.md)
- [FND-0107: data-only service USB was not data-isolated — исправлено, проведено ревью](findings/FND-0107-data-only-service-usb-was-not-data-isolated.md)
- [FND-0108: obsolete service switch and inexact header — исправлено, проведено ревью](findings/FND-0108-obsolete-service-switch-and-inexact-header.md)
- [FND-0109: machine map was not a complete physical BOM — coverage/MAX support исправлены, qualification active](findings/FND-0109-machine-map-was-not-a-complete-physical-bom.md)
- [FND-0110: actual-TX thresholds and AON boundary were abstract — исправлено](findings/FND-0110-actual-tx-thresholds-and-aon-boundary-were-abstract.md)
- [FND-0111: orderability audit exposed pseudo-MPN and display gap — controller identity исправлено](findings/FND-0111-orderability-audit-exposed-pseudo-mpn-and-display-gap.md)
- [FND-0112: assembly-internal display controller was double-counted — исправлено](findings/FND-0112-assembly-internal-controller-was-double-counted.md)
- [FND-0113: monolithic principled diagram exceeded GitHub's Mermaid limit — исправлено](findings/FND-0113-monolithic-principled-diagram-exceeded-github-limit.md)
- [FND-0114: hidden projection and USB-led overview obscured the architecture — исправлено](findings/FND-0114-hidden-projection-and-usb-led-overview.md)
- [FND-0115: I8 exit mixed G2F feasibility with downstream G8 — исправлено](findings/FND-0115-i8-exit-mixed-g2f-with-downstream-g8.md)
- [FND-0116: I9 abstract and stage labels were not closed — исправлено](findings/FND-0116-i9-abstract-and-stage-labels-were-not-closed.md)
- [FND-0117: legacy layout was not a current G3 projection — исправлено](findings/FND-0117-legacy-layout-was-not-a-current-g3-projection.md)
- [PHY-0001: U214 rear dock above batteries — D accepted, exact dock/HIL open](product-design/PHY-0001-u214-rear-dock-fit.md)
- [MEC-0001: U214 Cap-Bus mechanical interface facts — reviewed, MPN/stack-up open](product-design/MEC-0001-u214-cap-bus-mechanical-interface.md)
- [IMP-0001: безопасный TX-дефолт вместо максимума — принято](improvements/IMP-0001-safe-tx-defaults.md)
- [⚠️ IMP-0002: SDIO как обход GP-SPI блокера C5 — предложение](improvements/IMP-0002-c5-sdio-link.md)
- [⚠️ IMP-0003: переоткрыть EAPOL/PMKID capture — предложение](improvements/IMP-0003-wifi-handshake-capture.md)
- [⚠️ IMP-0004: dedicated BLE connection sniffer — предложение](improvements/IMP-0004-dedicated-ble-sniffer.md)
- [IMP-0005: снять NFC ceiling готовым M5 Unit NFC U216 — принято](improvements/IMP-0005-pn7160-nfc-expansion.md)
- [⚠️ IMP-0006: исходная UI-matrix конфликтует с audio — переработано в IMP-0010](improvements/IMP-0006-ui-key-matrix.md)
- [IMP-0007: внешний Cardputer LoRa+GNSS Cap — основной профиль](improvements/IMP-0007-cardputer-lora-gnss-cap.md)
- [IMP-0008: универсальный внешний LoRa-профиль — транспорт принят, E22 опционален](improvements/IMP-0008-modular-lora-expansion.md)
- [IMP-0009: бортовой mono codec ES8311 с hardware bypass — принято](improvements/IMP-0009-onboard-mono-audio-codec.md)
- [IMP-0010: hard STOP принят DEC-0024; matrix/удаление `U14` остаются layout-кандидатом](improvements/IMP-0010-hardware-stop-and-expander-consolidation.md)
- [IMP-0011: подписанная цепочка обновлений S3 и C5 — принято как A-open](improvements/IMP-0011-signed-update-chain.md)
- [IMP-0012: backend-native assistance и индикатор целостности GNSS — принято](improvements/IMP-0012-casic-gnss-advanced-profile.md)
- [IMP-0013: открытый lifecycle SSB-патча Si4732 — принято](improvements/IMP-0013-reproducible-ssb-patch-lifecycle.md)
- [IMP-0014: conditional migration на dual-band SA518 — принято](improvements/IMP-0014-dual-band-sa518-voice-backend.md)
- [IMP-0015: dual-path consumer IR learning — принято](improvements/IMP-0015-dual-path-consumer-ir-learning.md)
- [IMP-0016: честный calibrated three-antenna RPD hunt — принят вариант A](improvements/IMP-0016-calibrated-three-antenna-2g4-hunt.md)
- [IMP-0017: native BLE + ограниченный BLE-compatible subset nRF24 — принято](improvements/IMP-0017-native-ble-plus-nrf24-compatibility.md)
- [IMP-0018: open-first Thread + conditional Zigbee — принят вариант A](improvements/IMP-0018-open-first-thread-and-zigbee-scope.md)
- [IMP-0019: S3 как единственный baseline native-BLE owner — принято](improvements/IMP-0019-s3-primary-native-ble-owner.md)
- [⚠️ IMP-0020: ordinary Bluetooth Mesh — требуется отдельное решение](improvements/IMP-0020-ordinary-ble-mesh-scope.md)
- [IMP-0021: S3 nRF owner — справочный архив, не active proposal](improvements/IMP-0021-s3-owns-three-full-function-nrf24.md)
- [IMP-0022: latched hard-STOP tree с перезапуском обоих MCU — принят DEC-0024](improvements/IMP-0022-latched-hard-stop-tree.md)
- [IMP-0023: dedicated 4.0 V rail для SA518 — принят DEC-0025](improvements/IMP-0023-dedicated-4v-sa518-voice-rail.md)
- [IMP-0024: conditional C5 revision floor — C5 не выбран](improvements/IMP-0024-c5-v1.2-production-floor.md)
- [IMP-0025: historical vendored CAD snapshot — archived by DEC-0032](improvements/IMP-0025-repository-vendored-critical-cad-libraries.md)
- [IMP-0026: historical three-domain service topology; requirement retained, exact implementation reopened](improvements/IMP-0026-connectorless-owner-recovery-fixture.md)
- [IMP-0027: external iButton/1-Wire Port-B strategy — принято DEC-0033](improvements/IMP-0027-ibutton-one-wire-profile.md)
- [IMP-0028: M5-first, not M5-only expansion platform — принят B/DEC-0034](improvements/IMP-0028-m5-first-not-m5-only-expansion.md)
- [IMP-0029: historical personal FIDO authenticator — removed DEC-0039](improvements/IMP-0029-open-personal-fido-authenticator.md)
- [IMP-0030: haptic feedback placement — отклонено DEC-0036](improvements/IMP-0030-haptic-feedback-placement.md)
- [IMP-0031: external IMU measurement annotation — принято A/DEC-0037](improvements/IMP-0031-external-imu-measurement-annotation.md)
- [IMP-0032: physical keyboard archetype — принято C/DEC-0038, phone-assisted text](improvements/IMP-0032-keyboard-whole-product-comparison.md)
- [IMP-0033: generic High-Speed USB host — rejected DEC-0039](improvements/IMP-0033-native-high-speed-usb-host.md)
- [IMP-0034: 6 GHz/Wi-Fi 6E placement — C/rejected DEC-0040](improvements/IMP-0034-6ghz-wifi6e-placement.md)
- [IMP-0035: one source for exact pins and physical layout — принято A/DEC-0042](improvements/IMP-0035-single-source-pin-and-layout-generator.md)
- [IMP-0036: task-based display performance — принят A/DEC-0043](improvements/IMP-0036-task-based-display-performance.md)
- [IMP-0037: complete slow-control plane and isolate external I²C — принято A/DEC-0044](improvements/IMP-0037-slow-control-and-external-i2c-isolation.md)
- [IMP-0038: visible qualified RF arbiter — принят A-GROUP/DEC-0045](improvements/IMP-0038-visible-qualified-rf-arbiter.md)
- [IMP-0039: three-nRF full-mix RF acceptance — принят A/DEC-0047](improvements/IMP-0039-three-nrf-full-mix-acceptance.md)
- [IMP-0040: three-nRF exact module/antenna baseline — принят A/DEC-0048](improvements/IMP-0040-three-nrf-module-and-antenna-baseline.md)
- [IMP-0041: 9 dedicated SMA or 8 with shared Si4732 port — принят A/DEC-0049](improvements/IMP-0041-exact-external-sma-count.md)
- [IMP-0042: external SMA gender/polarity — принят B/DEC-0050](improvements/IMP-0042-external-sma-gender-and-feed-policy.md)
- [IMP-0043: profiled external antenna kit — принято A/DEC-0055](improvements/IMP-0043-profiled-antenna-kit.md)
- [IMP-0044: QSPI-first fast display path — принято A/DEC-0052](improvements/IMP-0044-qspi-first-fast-display-path.md)
- [IMP-0045: new 3.5-inch portrait QSPI display class — принято A/DEC-0053](improvements/IMP-0045-new-35in-qspi-display-class.md)
- [IMP-0046: complete codec/routing/reset-default package — принято A/DEC-0054](improvements/IMP-0046-es8311-analog-routing-topology.md)
- [IMP-0047: one-stop PCBA and antenna kitting — принято B/DEC-0056](improvements/IMP-0047-one-stop-pcba-antenna-kitting-policy.md)
- [IMP-0048: U214 dock versus SMA banks — принято D/DEC-0057](improvements/IMP-0048-u214-dock-versus-sma-placement.md)
- [IMP-0049: complete service access versus 4-bit C5 SDIO — принято A/DEC-0059](improvements/IMP-0049-service-access-versus-4bit-sdio.md)
- [IMP-0050: AON hard STOP and per-path TX evidence — принят A/DEC-0061](improvements/IMP-0050-aon-stop-and-per-path-tx-evidence.md)
- [IMP-0051: target README as product site — принято DEC-0060](improvements/IMP-0051-target-readmes-as-product-site.md)
- [IMP-0052: safe field-replaceable 2S battery boundary — B accepted/DEC-0062](improvements/IMP-0052-safe-field-replaceable-2s-pack.md)
- [IMP-0053: 5-V Type-C power path versus USB-PD — B accepted/DEC-0063](improvements/IMP-0053-5v-typec-versus-pd-charge-path.md)
- [IMP-0054: fail-closed 2S admission manager — A accepted/DEC-0066](improvements/IMP-0054-fail-closed-2s-admission-manager.md)
- [IMP-0055: battery electrical topology after reopen — A accepted/DEC-0065](improvements/IMP-0055-battery-electrical-topology-after-reopen.md)
- [IMP-0056: deep-cell recovery boundary — A accepted/DEC-0067](improvements/IMP-0056-deep-cell-recovery-boundary.md)
- [INV-0001: дедуплицированная инвентаризация legacy-возможностей](inventories/INV-0001-legacy-capabilities.md)
- [INV-0002: единый реестр хотелок продукта — заморожен](inventories/INV-0002-product-wishlist.md)
- [INV-0003: девять групп wishlist и четыре extra-пакета — проведено ревью](inventories/INV-0003-wishlist-review-groups.md)
- [INV-0004: итоговая матрица саморевью 125/125 и dispositions extras](inventories/INV-0004-wishlist-self-review.md)
- [Product/architecture workspace — G2F logical/electrical feasibility active](architecture/README.md)
- [PD-0001: reviewed G3 physical-product inputs](product-design/PD-0001-g3-physical-design-inputs.md)
- [G3-0001: current clamshell geometry re-entry — checkpoint проведено ревью; G3 active](product-design/G3-0001-current-clamshell-reentry.md)
- [LAY-0001: former form-factor/zoning experiment — reference only](product-design/LAY-0001-form-factor-candidates.md)
- [Stage 3: target product design — current artifact and gate](../stages/03-target-product-design.md)
- [FLOW-0001: normative product→architecture→CAD gates](architecture/FLOW-0001-product-to-cad-gates.md)
- [DEM-0001: current hardware-neutral semantic signal demand — проведено ревью](architecture/DEM-0001-current-semantic-signal-demand.md)
- [SRC-0002: real-device pin provenance — machine-readable compute/control pass reviewed](architecture/SRC-0002-real-device-pin-provenance.md)
- [G2F generated pin ledger: three structurally checked maps; G2F-3I leading paper candidate](architecture/generated/G2F-pin-ledger.md)
- [G2F-3I generated principled pinout atlas: exact owner/net/pad projection](architecture/generated/G2F-3I-principled-pinout.md)
- [NIF-0001: digital non-interference layout — бумажная компоновка проведена ревью](architecture/NIF-0001-digital-noninterference-layout.md)
- [RFQ-0002: G2F-3I physical RF concurrency boundary — facts/policy reviewed, measurements open](architecture/RFQ-0002-g2f-3i-rf-concurrency-boundary.md)
- [QST-0001: unused-interface quiet-state contracts — requirement reviewed, exact electrical/HIL open](architecture/QST-0001-unused-interface-quiet-states.md)
- [SAFE-0002: accepted AON STOP and eight-path evidence circuit — I2 проведено ревью](architecture/SAFE-0002-accepted-aon-stop-and-evidence-circuit.md)
- [SAFE-0003: exact actual-TX thresholds and AON-to-main isolation — проведено ревью paper electrical scope](architecture/SAFE-0003-exact-actual-tx-threshold-and-isolation.md)
- [PWR-0002: I3 current-load/legacy-power prerequisite audit — reviewed; topology later reopened](architecture/PWR-0002-i3-power-prerequisite-audit.md)
- [PWR-0003: I3 charge and system-power-path options — reviewed; CPD accepted](architecture/PWR-0003-charge-power-path-options.md)
- [PWR-0004: exact sink-only USB-PD frontend — paper fit reviewed](architecture/PWR-0004-accepted-usb-pd-front-end.md)
- [PWR-0005: replaceable-2S manager/admission options — reviewed; A accepted](architecture/PWR-0005-replaceable-2s-manager-options.md)
- [PWR-0006: 2S, controlled two-slot 1S and one-slot 1S comparison — reviewed; A accepted](architecture/PWR-0006-one-or-two-cell-topology-comparison.md)
- [PWR-0007: MAX17320 2S surrounding circuit — reviewed; A accepted DEC-0067](architecture/PWR-0007-max17320-2s-surrounding-circuit.md)
- [PWR-0008: exact downstream rail tree — active topology and first targets reviewed](architecture/PWR-0008-exact-downstream-rail-tree.md)
- [N24H-0001: two-device three-nRF full-mix fixture — test plan reviewed](architecture/N24H-0001-two-device-full-mix-fixture.md)
- [N24M-0001: exact nRF module/antenna comparison — inputs reviewed](architecture/N24M-0001-exact-module-antenna-comparison.md)
- [RFH-0001: module-to-external-SMA interface facts — проведено ревью; DEC-0050](architecture/RFH-0001-module-to-external-sma-interface-review.md)
- [RFH-0002: antenna connector ecosystems — проведено ревью; B принят DEC-0050](architecture/RFH-0002-antenna-connector-ecosystem-review.md)
- [DSP-0001: display/touch/storage evidence and performance contract — проведено ревью](architecture/DSP-0001-display-storage-real-device-evidence.md)
- [DSP-0002: fast-display path options — QSPI-first accepted DEC-0052](architecture/DSP-0002-fast-display-path-options.md)
- [DSP-0003: exact fast-display shortlist — target class accepted DEC-0053](architecture/DSP-0003-exact-fast-display-shortlist.md)
- [DSP-0004: display part-number register — reviewed, production MPN gates open](architecture/DSP-0004-display-part-number-register.md)
- [DSP-0005: HMX035CTFT-001 exact electrical fit — paper fit reviewed, HIL open](architecture/DSP-0005-hmx035ctft-electrical-fit.md)
- [DSP-0006: exact display rail, backlight and first mate profile — paper endpoint reviewed, physical HIL open](architecture/DSP-0006-exact-display-rail-backlight-and-mate-profile.md)
- [DSP-0008: display procurement boundary and exact RFQ packet — sourcing strategy проведено ревью](architecture/DSP-0008-display-procurement-boundary-and-rfq.md)
- [STO-0001: exact isolated microSD endpoint — paper endpoint reviewed, physical/media/HIL open](architecture/STO-0001-exact-isolated-microsd-endpoint.md)
- [UI-0001: complete local-control topology — inventory and pin fit reviewed](architecture/UI-0001-complete-local-control-topology.md)
- [UI-0002: exact switch and control protection — paper endpoint reviewed](architecture/UI-0002-exact-switch-and-control-protection.md)
- [AUDIO-0001: ES8311 QFN-20 exact digital/contact fit — reviewed, analog open](architecture/AUDIO-0001-es8311-exact-electrical-fit.md)
- [AUDIO-0003: exact audio/receiver endpoint — I5 paper electrical block reviewed](architecture/AUDIO-0003-exact-audio-and-receiver-endpoint.md)
- [CTL-0001: slow-control budget and external-I²C boundary — facts reviewed, topology open](architecture/CTL-0001-slow-control-and-external-i2c-boundary.md)
- [CAP-0001: former capability snapshot — candidate/reference, owner-contaminated](architecture/CAP-0001-zero-based-capability-input.md)
- [CON-0001: former concurrency/failure model — candidate/reference](architecture/CON-0001-hardware-neutral-concurrency-model.md)
- [RES-0001: former resource demand — candidate/reference, owner-contaminated](architecture/RES-0001-hardware-neutral-resource-demand.md)
- [SRC-0001: former primary package/controller/peripheral candidate facts — reviewed; SRC-0002 required](architecture/SRC-0001-primary-hardware-resource-facts.md)
- [SYN-0001: zero-based whole-device candidates — проведено ревью набора](architecture/SYN-0001-zero-based-whole-device-candidates.md)
- [PIN-0002: former exact pin/controller maps — historical candidate/reference](architecture/PIN-0002-zero-based-exact-pin-maps.md)
- [BUD-0002: historical memory/traffic model — display row superseded by DEC-0043](architecture/BUD-0002-zero-based-memory-traffic-budget.md)
- [PWR-0001: zero-based power/safety envelope — проведено ревью](architecture/PWR-0001-zero-based-power-safety-envelope.md)
- [RFQ-0001: zero-based RF zoning/coexistence — проведено ревью](architecture/RFQ-0001-zero-based-rf-zoning-coexistence.md)
- [CST-0001: dated candidate cost/implementation burden — проведено ревью](architecture/CST-0001-dated-candidate-cost-burden.md)
- [PKG-0001: former `SYN-3A` target — candidate/reference only](architecture/PKG-0001-zero-based-target-architecture-proposal.md)
- [DM/BUD/PIN/SC/LAY/CMP/ADR: legacy-derived stage-3 архив](../../drafts/stage3-legacy-derived-2026-08-16/README.md)
- [REV-0003H: правило атомарного architecture package — проведено ревью](reviews/REV-0003H-atomic-architecture-package-rule.md)
- [REV-0003I: реестр зависимостей этапа 3 — проведено ревью](reviews/REV-0003I-stage3-dependency-register.md)
- [REV-0003J: zero-based restart этапа 3 — проведено ревью](reviews/REV-0003J-zero-based-stage3-restart.md)
- [REV-0003K: zero-based concurrency model — проведено ревью](reviews/REV-0003K-zero-based-concurrency-model.md)
- [REV-0003L: zero-based resource model — проведено ревью](reviews/REV-0003L-zero-based-resource-model.md)
- [REV-0003M: primary hardware fact baseline — проведено ревью](reviews/REV-0003M-primary-hardware-fact-baseline.md)
- [REV-0003N: zero-based whole-device candidate set — проведено ревью](reviews/REV-0003N-zero-based-candidate-set.md)
- [REV-0003O: zero-based exact pin/controller maps — проведено ревью](reviews/REV-0003O-zero-based-exact-pin-maps.md)
- [REV-0003P: zero-based memory/traffic budget — проведено ревью](reviews/REV-0003P-zero-based-memory-traffic-budget.md)
- [REV-0003Q: zero-based power envelope — проведено ревью](reviews/REV-0003Q-zero-based-power-envelope.md)
- [REV-0003R: zero-based RF zoning/coexistence — проведено ревью](reviews/REV-0003R-zero-based-rf-zoning.md)
- [REV-0003S: dated candidate cost/implementation burden — проведено ревью](reviews/REV-0003S-zero-based-cost-burden.md)
- [REV-0003T: readiness atomic package — проведено ревью](reviews/REV-0003T-atomic-package-readiness.md)
- [REV-0003U: historical propagation review — superseded](reviews/REV-0003U-stage3-acceptance-propagation.md)
- [Current component/BOM workspace — I8/I9 working-candidate paper scopes reviewed; G3 active](components/README.md)
- [BOM-0001: former candidate component evidence register](components/BOM-0001-stage4-component-evidence-register.md)
- [BOM-0008: consolidated target BOM/AVL/cost workbench — inventory coverage проведено ревью](components/BOM-0008-consolidated-target-bom-and-avl.md)
- [BOM-0009: exact-line orderability recheck — corrected current 186/187, display residue открыт](components/BOM-0009-current-orderability-recheck.md)
- [BOM-0010: display procurement and alternate disposition — sourcing strategy проведено ревью](components/BOM-0010-display-procurement-and-alternate-disposition.md)
- [BOM-0011: assembly-internal purchase boundary — corrected 857/187 coverage проведено ревью](components/BOM-0011-assembly-internal-purchase-boundary.md)
- [BOM-0012: complete substitution/no-silent-replacement policy — 187/187 проведено ревью](components/BOM-0012-complete-substitution-policy.md)
- [BOM-0013: first exact quantity-100 cost evidence — 15/187 проведено ревью](components/BOM-0013-first-quantity-100-cost-evidence.md)
- [BOM-0014: high-placement cost and explicit gates — second-batch snapshot проведено ревью](components/BOM-0014-high-placement-cost-and-explicit-gates.md)
- [BOM-0015: third high-placement cost evidence — third-batch snapshot проведено ревью](components/BOM-0015-third-high-placement-cost-evidence.md)
- [BOM-0016: high-value IC/RF cost evidence — fourth-batch 52/187 / 614 checkpoint](components/BOM-0016-high-value-ic-rf-cost-evidence.md)
- [BOM-0017: power/UI/RF cost evidence — fifth-batch 61/187 / 623 checkpoint](components/BOM-0017-power-ui-rf-cost-evidence.md)
- [BOM-0018: audio/power/mechanical cost evidence — sixth-batch 76/187 / 643 checkpoint](components/BOM-0018-audio-power-mechanical-cost-evidence.md)
- [BOM-0019: high-placement passive/discrete cost evidence — seventh-batch 91/187 / 708 checkpoint](components/BOM-0019-high-placement-passive-cost-evidence.md)
- [BOM-0020: control/protection/RF-passive cost evidence — eighth-batch 106/187 / 747 checkpoint](components/BOM-0020-control-protection-rf-cost-evidence.md)
- [BOM-0021: control/logic/passive cost evidence — ninth-batch 118/187 / 771 checkpoint](components/BOM-0021-control-logic-passive-cost-evidence.md)
- [BOM-0022: RF/timing/indicator/passive cost evidence — tenth-batch 133/187 / 787 checkpoint](components/BOM-0022-rf-timing-indicator-passive-cost-evidence.md)
- [BOM-0023: logic/interface/IR cost evidence — eleventh-batch checkpoint](components/BOM-0023-logic-interface-ir-cost-evidence.md)
- [BOM-0024: exact resistor cost evidence — twelfth-batch checkpoint](components/BOM-0024-resistor-cost-evidence.md)
- [BOM-0025: specialty cost evidence and explicit gates — thirteenth-batch 169/187 / 823 checkpoint](components/BOM-0025-specialty-cost-and-gates.md)
- [BOM-0026: exact high-Q RF-capacitor cost evidence — current 175/187 / 829 placements проведено ревью](components/BOM-0026-high-q-rf-capacitor-cost-evidence.md)
- [BOM-0027: physical purchase-family resolution gates — 4/4 families проведено ревью gate coverage](components/BOM-0027-physical-purchase-family-resolution-gates.md)
- [BOM-0028: consolidated I8 paper procurement-feasibility review — проведено ревью](components/BOM-0028-i8-consolidated-paper-procurement-review.md)
- [Generated G2F-3I target BOM coverage review](components/generated/G2F-3I-target-bom-review.md)
- [Generated G2F-3I target BOM CSV](components/generated/G2F-3I-target-bom.csv)
- [REV-0004A: stage-4 entry/register — проведено ревью](reviews/REV-0004A-stage4-entry-register.md)
- [REV-0004B: compute/clock/recovery primary facts — проведено ревью фактов](reviews/REV-0004B-compute-clock-recovery-evidence.md)
- [REV-0004C: C5 v1.2 propagation — проведено ревью](reviews/REV-0004C-c5-v1.2-propagation.md)
- [REV-0004D: compute CAD availability audit — проведено ревью фактов](reviews/REV-0004D-compute-cad-library-audit.md)
- [REV-0004E: historical CAD snapshot review — archived](reviews/REV-0004E-vendored-critical-cad-libraries.md)
- [REC-0001: compute recovery/link prerequisites — проведено ревью пререквизитов](components/REC-0001-compute-recovery-and-link-prerequisites.md)
- [REV-0004F: compute recovery/link prerequisites — проведено ревью](reviews/REV-0004F-compute-recovery-link-prerequisites.md)
- [SVC-0001: former three-domain development-access candidate](components/SVC-0001-three-domain-development-access.md)
- [SVC-0002: exact three-domain service/recovery implementation — проведено ревью paper electrical scope](architecture/SVC-0002-exact-three-domain-service-recovery-boundary.md)
- [REV-0004G: historical three-domain access review](reviews/REV-0004G-three-domain-development-access.md)
- [REV-0004H: architecture reopen and premature-CAD archive — проведено ревью исправления](reviews/REV-0004H-architecture-reopen-and-cad-archive.md)
- [REV-0004I: neutral-input correction — проведено ревью исправления](reviews/REV-0004I-neutral-input-correction.md)
- [REV-0004J: task-based display decision propagation — проведено ревью](reviews/REV-0004J-display-performance-decision-propagation.md)
- [REV-0004K: slow-control/external-I²C fact review — проведено; proposal later accepted DEC-0044](reviews/REV-0004K-slow-control-and-i2c-fact-review.md)
- [REV-0004L: digital non-interference layout — проведено ревью бумажной компоновки](reviews/REV-0004L-digital-noninterference-layout.md)
- [REV-0004M: G2F-3I RF concurrency facts/policy — проведено; measurements open](reviews/REV-0004M-g2f-3i-rf-concurrency-fact-review.md)
- [REV-0004N: unused-interface quiet-state input — проведено ревью paper controls](reviews/REV-0004N-unused-interface-quiet-state-input-review.md)
- [REV-0004O: external-SMA/compact-nRF decision propagation — проведено ревью](reviews/REV-0004O-external-sma-decision-propagation.md)
- [REV-0004P: exact external-SMA path fact review — проведено ревью](reviews/REV-0004P-external-sma-path-fact-review.md)
- [REV-0004Q: nine-SMA decision propagation — проведено ревью](reviews/REV-0004Q-nine-sma-decision-propagation.md)
- [REV-0004R: module-to-SMA interface fact review — проведено; DEC-0050](reviews/REV-0004R-module-to-sma-interface-fact-review.md)
- [REV-0004S: antenna connector ecosystem fact review — проведено; DEC-0050](reviews/REV-0004S-antenna-connector-ecosystem-fact-review.md)
- [REV-0004T: SMA polarity decision propagation — проведено ревью](reviews/REV-0004T-sma-polarity-decision-propagation.md)
- [REV-0004U: current-orderable antenna shortlist — facts reviewed; decision/HIL open](reviews/REV-0004U-current-orderable-antenna-shortlist.md)
- [REV-0004V: principled pinout self-review — current mapping reviewed, electrical closure open](reviews/REV-0004V-principled-pinout-self-review.md)
- [REV-0004W: fast-display paths — facts reviewed, proposal/exact panel open](reviews/REV-0004W-fast-display-path-options.md)
- [REV-0004X: QSPI display decision propagation — проведено ревью](reviews/REV-0004X-qspi-display-decision-propagation.md)
- [REV-0004Y: exact fast-display shortlist — facts reviewed, superseded by DEC-0053](reviews/REV-0004Y-exact-fast-display-shortlist.md)
- [REV-0004Z: display-class decision/part-number propagation — проведено ревью](reviews/REV-0004Z-display-class-decision-propagation.md)
- [REV-0005A: HMX035CTFT-001 electrical-fit propagation — проведено ревью](reviews/REV-0005A-hmx-display-electrical-fit.md)
- [REV-0005AO: exact display endpoint propagation — проведено ревью](reviews/REV-0005AO-display-endpoint-propagation.md)
- [REV-0005AP: isolated microSD endpoint propagation — проведено ревью](reviews/REV-0005AP-microsd-endpoint-propagation.md)
- [REV-0005B: ES8311 digital fit and analog-gap propagation — проведено ревью scope](reviews/REV-0005B-es8311-digital-fit-and-analog-gap.md)
- [REV-0005C: complete audio-path prerequisites — проведено ревью фактов](reviews/REV-0005C-complete-audio-path-prerequisites.md)
- [REV-0005D: DEC-0054 audio-decision propagation — проведено ревью](reviews/REV-0005D-audio-decision-propagation.md)
- [REV-0005E: DEC-0055 antenna-kit propagation — проведено ревью](reviews/REV-0005E-antenna-kit-decision-propagation.md)
- [REV-0005F: DEC-0056 kitting-policy propagation — проведено ревью](reviews/REV-0005F-kitting-policy-decision-propagation.md)
- [REV-0005G: U214 physical-envelope facts — проведено ревью, DEC-0057](reviews/REV-0005G-u214-physical-envelope-fact-review.md)
- [REV-0005H: U214 rear-dock paper fit — проведено ревью, D accepted/HIL open](reviews/REV-0005H-u214-rear-dock-paper-fit-review.md)
- [REV-0005I: DEC-0057 rear-dock propagation — проведено ревью](reviews/REV-0005I-u214-rear-dock-decision-propagation.md)
- [REV-0005J: internals before integrated mockup — процесс reviewed, I1 open](reviews/REV-0005J-internals-before-integrated-mockup.md)
- [REV-0005K: vertical living principled diagram — проведено ревью](reviews/REV-0005K-vertical-living-principled-diagram.md)
- [REV-0005L: full-service 1-bit SDIO propagation — проведено ревью, I1 closed](reviews/REV-0005L-full-service-1bit-sdio-propagation.md)
- [REV-0005M: I2 safety prerequisites — проведено; superseded DEC-0061/REV-0005O](reviews/REV-0005M-i2-safety-prerequisites.md)
- [REV-0005N: target product-site cleanup — проведено ревью](reviews/REV-0005N-target-product-site-cleanup.md)
- [REV-0005O: I2 safety decision propagation — проведено ревью](reviews/REV-0005O-i2-safety-decision-propagation.md)
- [REV-0005P: I3 power prerequisites — проведено ревью; battery gate closed by DEC-0062/REV-0005Q](reviews/REV-0005P-i3-power-prerequisites.md)
- [REV-0005Q: replaceable-cell decision propagation — проведено ревью; IMP-0053 next](reviews/REV-0005Q-battery-format-decision-propagation.md)
- [REV-0005R: sink-only USB-PD decision propagation — проведено ревью](reviews/REV-0005R-usb-pd-decision-propagation.md)
- [REV-0005S: battery-topology reopen propagation — проведено ревью; historical intermediate](reviews/REV-0005S-battery-topology-reopen-propagation.md)
- [REV-0005T: supervised-2S topology decision propagation — проведено ревью](reviews/REV-0005T-supervised-2s-topology-decision-propagation.md)
- [REV-0005U: exact 2S manager revalidation — факты reviewed; A later accepted](reviews/REV-0005U-exact-2s-manager-revalidation.md)
- [REV-0005V: 2S manager decision propagation — проведено ревью](reviews/REV-0005V-2s-manager-decision-propagation.md)
- [REV-0005W: MAX17320 surrounding-circuit gate — historical gate; later closed DEC-0067](reviews/REV-0005W-max17320-surrounding-circuit-gate.md)
- [REV-0005X: deep-cell policy and exact circuit propagation — проведено ревью](reviews/REV-0005X-deep-cell-policy-propagation.md)
- [REV-0005Y: exact downstream rail-tree propagation — проведено ревью](reviews/REV-0005Y-downstream-rail-tree-propagation.md)
- [REV-0005Z: latch-off external eFuse propagation — проведено ревью](reviews/REV-0005Z-latch-off-efuse-propagation.md)
- [REV-0005AA: enable-qualified switched-rail PG propagation — проведено ревью](reviews/REV-0005AA-switched-rail-pg-qualification.md)
- [REV-0005AB: external-eFuse passive profile propagation — проведено ревью](reviews/REV-0005AB-external-efuse-passive-profile.md)
- [REV-0005AC: application-converter passive profile propagation — проведено ревью](reviews/REV-0005AC-application-converter-passive-profile.md)
- [REV-0005AD: converter control-passive profile propagation — проведено ревью](reviews/REV-0005AD-converter-control-passive-profile.md)
- [REV-0005AE: pack diagnostic frontend propagation — проведено ревью](reviews/REV-0005AE-pack-diagnostic-profile.md)
- [REV-0005AF: BQ25798 passive/reset profile propagation — проведено ревью](reviews/REV-0005AF-bq25798-passive-profile.md)
- [REV-0005AG: TPS25751D/EEPROM support-profile propagation — проведено ревью](reviews/REV-0005AG-tps25751-eeprom-support-profile.md)
- [REV-0005AH: battery holder and three-NTC propagation — проведено ревью](reviews/REV-0005AH-battery-holder-and-ntc-coupling.md)
- [REV-0005AI: diagnostic lockout propagation — проведено ревью](reviews/REV-0005AI-diagnostic-lockout-propagation.md)
- [REV-0005AJ: exact-cell propagation — проведено ревью](reviews/REV-0005AJ-exact-cell-propagation.md)
- [REV-0005AK: source-sequence propagation — проведено ревью](reviews/REV-0005AK-source-sequence-propagation.md)
- [REV-0005AL: internal-rail containment propagation — проведено ревью](reviews/REV-0005AL-internal-rail-containment-propagation.md)
- [REV-0005AM: I3 paper-closure propagation — проведено ревью](reviews/REV-0005AM-i3-paper-closure-propagation.md)
- [REV-0005AN: exact product USB-port propagation — проведено ревью](reviews/REV-0005AN-product-usb-port-propagation.md)
- [REV-0005AO: exact display-endpoint propagation — проведено ревью](reviews/REV-0005AO-display-endpoint-propagation.md)
- [REV-0005AP: exact microSD-endpoint propagation — проведено ревью](reviews/REV-0005AP-microsd-endpoint-propagation.md)
- [REV-0005AQ: complete local-controls propagation — проведено ревью](reviews/REV-0005AQ-local-controls-propagation.md)
- [REV-0005AR: exact control switch/protection propagation — проведено ревью](reviews/REV-0005AR-exact-control-switch-protection-propagation.md)
- [REV-0005AS: exact integrated-touch propagation — проведено ревью](reviews/REV-0005AS-exact-touch-propagation.md)
- [REV-0005AT: consolidated I4 propagation — проведено ревью](reviews/REV-0005AT-consolidated-i4-propagation.md)
- [REV-0005AU: I5 audio and receiver propagation — проведено ревью](reviews/REV-0005AU-i5-audio-receiver-propagation.md)
- [REV-0005AV: I6 three-nRF electrical propagation — проведено ревью subblock](reviews/REV-0005AV-i6-three-nrf-propagation.md)
- [REV-0005AW: I6 native S3/C5 RF propagation — проведено ревью subblock](reviews/REV-0005AW-i6-native-rf-propagation.md)
- [REV-0005AX: I6 CC1101 propagation — проведено ревью subblock](reviews/REV-0005AX-i6-cc1101-propagation.md)
- [REV-0005AY: I6 SA518 RF propagation — проведено ревью subblock](reviews/REV-0005AY-i6-sa518-rf-propagation.md)
- [REV-0005AZ: I6 IR propagation — проведено ревью subblock](reviews/REV-0005AZ-i6-ir-propagation.md)
- [REV-0005BA: I6 Si4732 RF propagation — проведено ревью subblock](reviews/REV-0005BA-i6-si4732-rf-propagation.md)
- [REV-0005BB: Si4732 SOIC-16 pin-map correction — проведено ревью](reviews/REV-0005BB-si4732-soic16-pin-map-correction.md)
- [REV-0005BC: I6 consolidated proof propagation — проведено ревью paper qualification scope](reviews/REV-0005BC-i6-consolidated-proof-propagation.md)
- [REV-0005BD: I7 M5 expansion propagation — проведено ревью paper electrical scope](reviews/REV-0005BD-i7-m5-expansion-propagation.md)
- [REV-0005BE: I7 service/recovery propagation — проведено ревью paper electrical scope](reviews/REV-0005BE-i7-service-recovery-propagation.md)
- [REV-0005BF: MAX17320 support repair propagation — проведено ревью paper electrical scope](reviews/REV-0005BF-max17320-support-repair-propagation.md)
- [REV-0005BG: actual-TX threshold and AON-boundary propagation — проведено ревью paper electrical scope](reviews/REV-0005BG-actual-tx-threshold-propagation.md)
- [REV-0005BH: current orderability and exact-RP propagation — проведено ревью sourcing batch](reviews/REV-0005BH-orderability-propagation.md)
- [REV-0005BI: display procurement boundary propagation — проведено ревью sourcing strategy](reviews/REV-0005BI-display-procurement-propagation.md)
- [REV-0005BJ: assembly-internal BOM propagation — проведено ревью corrected purchasing coverage](reviews/REV-0005BJ-assembly-internal-bom-propagation.md)
- [REV-0005BK: substitution-policy propagation — проведено ревью 187/187 policy coverage](reviews/REV-0005BK-substitution-policy-propagation.md)
- [REV-0005BL: first cost-evidence propagation — проведено ревью 15/187 lines](reviews/REV-0005BL-first-cost-evidence-propagation.md)
- [REV-0005BM: second cost-evidence and explicit-gate propagation — проведено ревью 23/187 lines](reviews/REV-0005BM-second-cost-evidence-propagation.md)
- [REV-0005BN: third cost-evidence propagation — проведено ревью 39/187 lines](reviews/REV-0005BN-third-cost-evidence-propagation.md)
- [REV-0005BO: high-value cost-evidence propagation — проведено ревью 52/187 lines](reviews/REV-0005BO-high-value-cost-evidence-propagation.md)
- [REV-0005BP: bounded principled and current-stage diagrams — проведено ревью](reviews/REV-0005BP-bounded-principled-and-stage-diagrams.md)
- [REV-0005BQ: power/UI/RF cost-evidence propagation — проведено ревью 61/187 lines](reviews/REV-0005BQ-power-ui-rf-cost-evidence-propagation.md)
- [REV-0005BR: audio/power/mechanical cost-evidence propagation — проведено ревью sixth-batch checkpoint](reviews/REV-0005BR-audio-power-mechanical-cost-propagation.md)
- [REV-0005BS: high-placement passive/discrete cost-evidence propagation — проведено ревью seventh-batch checkpoint](reviews/REV-0005BS-high-placement-passive-cost-propagation.md)
- [REV-0005BT: control/protection/RF cost-evidence propagation — eighth-batch 106/187 checkpoint](reviews/REV-0005BT-control-protection-rf-cost-propagation.md)
- [REV-0005BU: control/logic/passive cost-evidence propagation — ninth-batch checkpoint](reviews/REV-0005BU-control-logic-passive-cost-propagation.md)
- [REV-0005BV: RF/timing/indicator/passive cost-evidence propagation — tenth-batch checkpoint](reviews/REV-0005BV-rf-timing-indicator-passive-cost-propagation.md)
- [REV-0005BW: logic/interface/IR cost-evidence propagation — проведено ревью eleventh-batch checkpoint](reviews/REV-0005BW-logic-interface-ir-cost-propagation.md)
- [REV-0005BX: exact resistor cost-evidence propagation — проведено ревью twelfth-batch checkpoint](reviews/REV-0005BX-resistor-cost-propagation.md)
- [REV-0005BY: specialty cost-evidence and gate propagation — проведено ревью 169/187 lines](reviews/REV-0005BY-specialty-cost-gate-propagation.md)
- [REV-0005BZ: renderable principled-device atlas — проведено ревью](reviews/REV-0005BZ-renderable-principled-atlas.md)
- [REV-0005CA: high-Q RF-capacitor cost-evidence propagation — проведено ревью 175/187 lines](reviews/REV-0005CA-high-q-rf-capacitor-cost-propagation.md)
- [REV-0005CB: physical purchase-family gate propagation — проведено ревью 4/4 gate coverage](reviews/REV-0005CB-physical-purchase-gate-propagation.md)
- [REV-0005CC: consolidated I8 paper procurement propagation — проведено ревью](reviews/REV-0005CC-i8-consolidated-paper-procurement-propagation.md)
- [REV-0005CD: I9 joint candidate-projection propagation — проведено ревью](reviews/REV-0005CD-i9-joint-candidate-projection-propagation.md)
- [REV-0005CE: current G3 clamshell propagation — geometry-reentry checkpoint проведено ревью](reviews/REV-0005CE-current-g3-clamshell-propagation.md)
- [AUD-0001: повторный аудит legacy-исключений — проведено ревью требований](audits/AUD-0001-legacy-exclusions.md)
- [AUD-0002: снижение стоимости без потерь](audits/AUD-0002-zero-loss-cost.md)
- [AUD-0003: прежний nRF-owner audit — справочный архив](audits/AUD-0003-three-nrf24-owner-placement.md)
- [AUD-0004: current competitor capability/product-design gap — проведено ревью](audits/AUD-0004-current-competitor-capability-gap.md)
- [AUD-0005: M5 expansion ecosystem coverage — проведено ревью; B принят](audits/AUD-0005-m5-expansion-ecosystem-coverage.md)
- [AUD-0006: historical FIDO authenticator capability/security boundary](audits/AUD-0006-fido-authenticator-security-boundary.md)
- [AUD-0007: haptic product/mechanical/cost boundary — проведено ревью; product haptic отклонён](audits/AUD-0007-haptic-product-mechanical-cost.md)
- [AUD-0008: IMU instrument value/placement — проведено ревью; A принят](audits/AUD-0008-imu-instrument-value-and-placement.md)
- [AUD-0009: physical-keyboard product archetype — проведено ревью; DEC-0038](audits/AUD-0009-physical-keyboard-product-archetype.md)
- [AUD-0010: High-Speed USB host use cases — проведено ревью; generic host rejected](audits/AUD-0010-high-speed-usb-host-use-cases.md)
- [AUD-0011: radio/key product scope — проведено ревью; DEC-0039](audits/AUD-0011-radio-key-product-scope.md)
- [AUD-0012: 6 GHz/Wi-Fi 6E scope — reviewed; rejected DEC-0040](audits/AUD-0012-6ghz-wifi6e-product-scope.md)
- [AUD-0013: legacy physical-layout generator reuse — проведено ревью](audits/AUD-0013-legacy-layout-generator-reuse.md)
- [Контракт владения](../contracts/ownership.md)
- [REV-0000: ревью этапа 0](reviews/REV-0000-stage-0.md)
- [REV-0000A: ревью целевых и текущих стартовых страниц](reviews/REV-0000A-document-entrypoints.md)
- [REV-0001: ревью этапа 1](reviews/REV-0001-stage-1.md)
- [REV-0001A: повторное ревью трёхуровневой границы](reviews/REV-0001A-three-functional-levels.md)
- [REV-0002A: ревью инвентаризации возможностей](reviews/REV-0002A-capability-inventory.md)
- [REV-0002B: ревью scope внешнего GNSS](reviews/REV-0002B-external-gnss.md)
- [REV-0002C: историческое ревью прежнего LoRa scope](reviews/REV-0002C-modular-lora-scope.md)
- [REV-0002D: повторное ревью U214 и общепринятых LoRa-частот](reviews/REV-0002D-u214-common-bands.md)
- [REV-0002E: ревью вариантов цифрового audio-path](reviews/REV-0002E-audio-options.md)
- [REV-0002F: ревью распространения решения ES8311](reviews/REV-0002F-es8311-decision-propagation.md)
- [REV-0002G: ревью переноса IMP-0010 на сводный pin budget](reviews/REV-0002G-defer-imp-0010-to-pin-budget.md)
- [REV-0002H: ревью пререквизитов System/UI/storage](reviews/REV-0002H-system-ui-prerequisites.md)
- [REV-0002I: ревью System/UI/storage и распространения A-open](reviews/REV-0002I-system-ui-decision-propagation.md)
- [REV-0002J: ревью пререквизитов GNSS/navigation](reviews/REV-0002J-gnss-prerequisites.md)
- [REV-0002K: ревью GNSS/navigation и распространения варианта A](reviews/REV-0002K-gnss-decision-propagation.md)
- [REV-0002L: ревью пререквизитов Si4732 receiver](reviews/REV-0002L-si4732-prerequisites.md)
- [REV-0002M: ревью Si4732 receiver и распространения варианта A](reviews/REV-0002M-si4732-decision-propagation.md)
- [REV-0002N: ревью пререквизитов analog voice/SA868](reviews/REV-0002N-sa868-prerequisites.md)
- [REV-0002O: ревью analog voice и распространения SA518/A](reviews/REV-0002O-voice-backend-decision-propagation.md)
- [REV-0002P: ревью пререквизитов NFC/RFID](reviews/REV-0002P-nfc-prerequisites.md)
- [REV-0002Q: ревью NFC/RFID и распространения U216/A](reviews/REV-0002Q-nfc-decision-propagation.md)
- [REV-0002R: ревью пререквизитов consumer IR](reviews/REV-0002R-ir-prerequisites.md)
- [REV-0002S: финальное ревью и распространение consumer IR решения](reviews/REV-0002S-ir-decision-propagation.md)
- [REV-0002T: ревью пререквизитов 3×nRF24](reviews/REV-0002T-nrf24-prerequisites.md)
- [REV-0002U: финальное ревью и распространение решения 3×nRF24](reviews/REV-0002U-nrf24-decision-propagation.md)
- [REV-0002V: ревью пререквизитов C5 Wi-Fi/IEEE 802.15.4](reviews/REV-0002V-c5-wifi-802154-prerequisites.md)
- [REV-0002W: финальное ревью и распространение C5 Wi-Fi/802.15.4 решения](reviews/REV-0002W-c5-wifi-802154-decision-propagation.md)
- [REV-0002X: ревью пререквизитов native Bluetooth LE](reviews/REV-0002X-ble-prerequisites.md)
- [REV-0002Y: финальное ревью и распространение S3 native-BLE ownership](reviews/REV-0002Y-s3-native-ble-decision-propagation.md)
- [REV-0002Z: ревью пререквизитов повторного выбора владельца 3×nRF24](reviews/REV-0002Z-nrf24-owner-placement-prerequisites.md)
- [REV-0002AA: ревью capability-first порядка до компоновки](reviews/REV-0002AA-capability-first-workflow.md)
- [REV-0002AB: ревью группировки полного wishlist — проведено ревью](reviews/REV-0002AB-wishlist-grouping.md)
- [REV-0002AC: саморевью полного wishlist — проведено ревью](reviews/REV-0002AC-wishlist-self-review.md)
- [REV-0002AD: итоговое ревью этапа 2 — проведено ревью](reviews/REV-0002AD-stage-2.md)
- [REV-0002AE: M5 ecosystem audit and iButton disposition — проведено ревью фактов/W-EXTRA-11](reviews/REV-0002AE-m5-expansion-and-ibutton-disposition.md)
- [REV-0002AF: M5-first two-tier decision propagation — проведено ревью](reviews/REV-0002AF-m5-first-decision-propagation.md)
- [REV-0002AG: historical U2F/FIDO prerequisite review](reviews/REV-0002AG-fido-prerequisites.md)
- [REV-0002AH: historical personal FIDO decision propagation — target superseded](reviews/REV-0002AH-fido-decision-propagation.md)
- [REV-0002AI: haptic feedback prerequisite review — проведено ревью фактов](reviews/REV-0002AI-haptic-prerequisites.md)
- [REV-0002AJ: haptic rejection propagation — проведено ревью](reviews/REV-0002AJ-haptic-rejection-propagation.md)
- [REV-0002AK: IMU instrument-value prerequisites — проведено ревью фактов](reviews/REV-0002AK-imu-prerequisites.md)
- [REV-0002AL: optional external IMU decision propagation — проведено ревью](reviews/REV-0002AL-imu-decision-propagation.md)
- [REV-0002AM: physical-keyboard archetype prerequisites — проведено ревью фактов](reviews/REV-0002AM-keyboard-archetype-prerequisites.md)
- [REV-0002AN: phone-assisted text decision propagation — проведено ревью](reviews/REV-0002AN-phone-assisted-text-decision-propagation.md)
- [REV-0002AO: High-Speed USB host prerequisites — проведено ревью фактов](reviews/REV-0002AO-high-speed-usb-host-prerequisites.md)
- [REV-0002AP: radio/key mission scope propagation — проведено ревью](reviews/REV-0002AP-radio-key-scope-propagation.md)
- [REV-0002AQ: 6 GHz/Wi-Fi 6E prerequisites — проведено ревью фактов](reviews/REV-0002AQ-6ghz-wifi6e-prerequisites.md)
- [REV-0002AR: 6 GHz/Wi-Fi 6E rejection propagation — проведено ревью](reviews/REV-0002AR-6ghz-rejection-propagation.md)
- [REV-0002AS: repeat G2 review after competitor delta — проведено ревью](reviews/REV-0002AS-stage-2-delta-rereview.md)
- [REV-0003A: пререквизиты единого demand model — проведено ревью](reviews/REV-0003A-demand-model-prerequisites.md)
- [REV-0003B: MCU pin/controller inventory и layout scorecard — проведено ревью](reviews/REV-0003B-pin-inventory-and-scorecard.md)
- [REV-0003C: распространение решения latched hard STOP — проведено ревью](reviews/REV-0003C-hard-stop-decision-propagation.md)
- [REV-0003D: traffic и memory envelope — проведено ревью подшага](reviews/REV-0003D-traffic-memory-envelope.md)
- [REV-0003E: финальное ревью power envelope и VVOICE — проведено ревью](reviews/REV-0003E-power-envelope-and-voice-rail.md)
- [REV-0003F: повторное ревью control count перед layouts — проведено ревью](reviews/REV-0003F-layout-entry-control-count.md)
- [REV-0003G: три static full-layout maps — проведено ревью подшага](reviews/REV-0003G-three-static-layouts.md)
- [REV-0003V: G3 physical-product input review — проведено ревью](reviews/REV-0003V-g3-physical-inputs.md)
- [REV-0003W: former G3 form-factor experiment review — direction superseded](reviews/REV-0003W-g3-form-factor-candidates.md)
- [REV-0003X: G2F entry and real-device rule — проведено ревью](reviews/REV-0003X-electrical-feasibility-entry.md)
- [REV-0003Y: single-source foundation and draft maps — structural scope проведено ревью](reviews/REV-0003Y-single-source-and-draft-pin-maps.md)
- [REV-0003Z: display/touch/storage exact-device facts — проведено ревью, exact target открыт](reviews/REV-0003Z-display-storage-real-device-evidence.md)

## Статусы

`Не начато` → `Требуется решение` → `В работе` → `На ревью` → `Проведено ревью`.

Дополнительные состояния: `Заблокировано`, `Требуется повторное ревью`.

## Реестр улучшений

Предложения `IMP-*` добавляются в `improvements/`. Отсутствие предложений означает только то, что обход ещё не найден или не доказан, а не то, что legacy-ограничение принято.

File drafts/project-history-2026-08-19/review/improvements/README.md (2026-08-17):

# Предложения по улучшениям

Здесь фиксируются доказуемые способы обойти ограничения legacy-дизайна или существенно улучшить получение артефактов.

Каждое `IMP-*` должно содержать:

- точную формулировку старого ограничения и ссылку на legacy-артефакт;
- почему ограничение больше не обязательно;
- предлагаемый обход;
- подтверждающие источники, расчёт или эксперимент;
- стоимость, сложность и новые риски;
- затрагиваемые требования, решения и этапы;
- решение владельца проекта: принять, отклонить или отложить.

Предложение не меняет scope и не становится архитектурным решением до явного согласия владельца проекта.

Последний owner gate — [`IMP-0056`](IMP-0056-deep-cell-recovery-boundary.md),
закрытый вариантом A в `DEC-0067`.
`PWR-0007/FND-0077` обнаружили материальную развилку: MAX17320 использует CHG
FET в линейном режиме для prequal, поэтому in-device recovery меняет FET,
thermal/SOA validation и продуктовый safety boundary. Рекомендован A: base
product отклоняет глубоко разряженную банку, а отдельное исследование возможно
только внешней изолированной оснасткой в Controlled Zone. В machine source
принят active common-drain `CSD87313DMST`; прежний `FDMC8030` отклонён как
`Last Shipments`.

Предыдущий [`IMP-0054`](IMP-0054-fail-closed-2s-admission-manager.md) закрыт
вариантом A в `DEC-0066`: exact `MAX17320G20+T` и
`MSPM0C1104SDGS20R`. [`IMP-0055`](IMP-0055-battery-electrical-topology-after-reopen.md)
ранее закрыто supervised 2S; альтернативы 1S остаются future-SKU evidence.

Предыдущее [`IMP-0053`](IMP-0053-5v-typec-versus-pd-charge-path.md) закрыто
выбором B в `DEC-0063`: принят sink-only USB-PD до 30 Вт с exact frontend
`PWR-0004`. Старый BQ25887-вариант остаётся dominated после добавления всех
отсутствующих блоков.

Последние закрытые предложения — `IMP-0053` и
[`IMP-0052`](IMP-0052-safe-field-replaceable-2s-pack.md), принятое вариантом B
как `DEC-0062`: две 18650 остаются отдельно заменяемыми, но не считаются
произвольной допустимой парой; [`IMP-0051`](IMP-0051-target-readmes-as-product-site.md),
принятое как `DEC-0060`, и
[`IMP-0050`](IMP-0050-aon-stop-and-per-path-tx-evidence.md), принятое вариантом
A как `DEC-0061`.

[`IMP-0042`](IMP-0042-external-sma-gender-and-feed-policy.md) ранее принято
вариантом B/`DEC-0050`: две native-Wi-Fi RP-SMA и семь standard SMA.

[`IMP-0043`](IMP-0043-profiled-antenna-kit.md) принято как `DEC-0055`:
профилированный комплект с общими MPN для S3/C5 и трёх nRF, combined 868/915,
но отдельными 315/433, VHF/UHF и Si4732 whip/loop profiles. Availability теперь
проверяется при выборе exact MPN. `FND-0058` по-прежнему не позволяет считать
sourcing shortlist production qualification, а `FND-0057` требует specimen
proof generic Ebyte `IPX` mating family.

[`IMP-0047`](IMP-0047-one-stop-pcba-antenna-kitting-policy.md) принято вариантом
B/`DEC-0056`: one-stop PCBA + antenna kitting является первым RFQ и
предпочтением, но не hard constraint. При худших total cost, сроке,
quality/test scope или supply risk закупки разделяются. `MFG-0001`
подтверждает техническую доступность turnkey kitting, не выбирая поставщика.

[`IMP-0048`](IMP-0048-u214-dock-versus-sma-placement.md) принято вариантом D
как `DEC-0057`: U214 размещается в заднем поперечном Cardputer-like dock над
аккумуляторами. `PHY-0001/REV-0005H` проверяют 4.5-mm side overhang, сохранение
девяти верхних SMA и paper depth внутри 18650 silhouette. Legacy encoder
требуется перенести; `MEC-0001/FND-0069` оставляют exact connector/stack-up и
installed-cap HIL открытыми.

[`IMP-0049`](IMP-0049-service-access-versus-4bit-sdio.md) принято вариантом A
как `DEC-0059`: working 1-bit SDIO восстанавливает C5 native USB и S3 default
UART0 RF-test access. 4-bit остаётся только fallback после провала measured
framed-throughput HIL.

[`IMP-0050`](IMP-0050-aon-stop-and-per-path-tx-evidence.md) принято вариантом A
как `DEC-0061`: трёхдоменный AON hard STOP и отдельное physical evidence для
семи onboard RF paths + IR используют `RP.GPIO22` aggregate и local-I²C source
mask без новой ноги. BAT15 coupon остаётся cost-down experiment;
shared/inferred evidence отклонено как потеря функции.

[`IMP-0051`](IMP-0051-target-readmes-as-product-site.md) принято как
`DEC-0060`: четыре корневые EN/RU страницы являются целевым GitHub product
site. Инженерная chronology остаётся в current-state/review, wide pin table
заменена responsive details-list, а regression защищает разделение слоёв.

[`IMP-0046`](IMP-0046-es8311-analog-routing-topology.md) принято вариантом A
как `DEC-0054`: active high-Z ES8311 capture, differential speaker selector,
отдельный TX selector и reset-safe GPIO6 `AUDIO_ARM`. Passive capture остаётся
только HIL-gated cost-down option; analog values и HIL не закрыты решением.

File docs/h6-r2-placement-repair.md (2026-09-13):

# H6.0.3-R1 · Placement repair

[Русский](h6-r2-placement-repair.ru.md) · [Interface review](h6-r2-interface-review.md)

2026-09-14: the upper LED row and its labels move **1 mm down**, increasing the
nominal display-to-LED-body gap **0.54 → 1.54 mm**. The lower row, panel and FPC
stay put. Use the existing DISPLAY silk for alignment, not LEDs as physical stops.
The [finite leadout review](../hardware/layout/h6-r2-led-display-clearance.json)
records the five local anode updates; final assembly tolerances still need dry fit.

2026-09-09: the separate [four-port GCT unification](h6-r2-component-unification.md) is implemented, with fresh native DRC/parity and preservation checks passed. Its [two-reference integration record](../hardware/layout/h6-r2-usb-unification-integration.json) supersedes the earlier JAE mouth datum, not the other placement corrections below.

**2026-09-13. The same left-side encoder moves upward, directly below Cap:
F270 [9.25,54], with U39 at B90 [15.4,89] and the internal headset at B0 [0.8,39].
Native integration, DRC/parity, labels, refreshed views and the full test run pass.
H6.0.3-R1 stays open, not fabrication or whole-device acceptance.**

## What we want

The holder must be centred, the encoder must really be on the left under Cap, the PTT
on the right, and ordinary electronics inside the sandwich. Ports, microphone,
speaker and their support circuits must be represented in the correct place.
A mirrored picture, an oversized reserve drawn as a body, or a part-count check
does not establish that result.

All positions below use native PCB coordinates. For the RF assembly transform,
`x_assembly = 80 − x_native`; native poses are not mirrored again. The selected
MPNs were unchanged by these placement-only corrections. The separate USB follow-up replaces RF J1 with GCT; electrical functions, board size and logical pin/net identities are retained.

## What was decided and corrected

| Area | Repair and limit |
| --- | --- |
| Holder / NTC | BT1 **F90 [40,85]**, removing the former +2.99-mm X displacement; R33/R34 **F90 [30.45,85] / [49.55,85]** follow the two nominal cell axes. Fab now distinguishes the real nominal **77.06 × 39.78 mm plastic body** from the dashed **86-mm pad-span reserve**. The already-corrected contact polarity is retained. This does not invent exact SMT lands, locator holes or thermal contact. |
| Internal power corridor | F2 stays inside at **B270 [53.37,47.87]**, near the centred BT1.3. U51 retains its centring-package position **B90 [40.05,53.5]**; U39 now moves separately to **B90 [15.4,89]** to clear the upper encoder. The original **2-mm fuse-owner locality** is not waived; the actual BT1.3–F2.1 span is **4.2731 mm**, below its 4.5-mm bound. |
| Encoder / PTT | SW3 is now **F270 [9.25,54]**, directly below Cap on the same left rear-outer side. The earlier **[9.25,81.25]** left/down pose is historical, not the current target. PTT SW4 stays on the right at **F0 [72.1,67.42]**; ordinary support parts remain inside. The nominal 15-mm knob leaves **5.48 mm to Cap / 3.3 mm to the holder** in plan, not qualified finger or 3D access. E/D and A/B/C identities and the existing engineering footprint remain unchanged. |
| Product USB | The preceding JAE repair used B180 [16.47,146.2], mouth Y149.8. The approved [GCT follow-up](h6-r2-component-unification.md) instead uses **B180 [16.47,146.325]** nominally, mouth **Y150 flush**; U5 moves 0.15 mm inward. Fresh native DRC/parity and preservation checks pass. Neither nominal datum qualifies actual plug-overmould fit. |
| Headset / microphone | U83 **SJ-43515TS-SMT-TR** moves inside to **B0 [0.8,39]**, retaining the outward left mouth at X−0.7; the former **[0.8,99.9]** is historical. MK1 remains **B0 [47,147.4]**, with its maximum body rim **0.5 mm inside** the bottom board edge; U85 stays **B90 [16.5,113.75]**. The microphone top port faces the inter-board space, with sound access through the designed open bottom gap; this does not turn the port normal downward or qualify acoustics. The former incorrect **F180 [8,112]** position stays superseded. |
| Actual supply locality | The UI moves remote bypass/bulk capacitors back toward their real owners: backlight switch, SD supply/card and three nRF modules. The checks name actual power pads, not whichever same-net pad is nearest. RF C259 becomes **B90 [61.275,82.125]** in the slot freed by the coordinated C230 relocation; its distances to U106.27 and .31 are **5.4200 / 7.3550 mm**, each bounded by 7.5 mm. C260/C261 remain separate local 100-nF bypasses. |
| Speaker representation | The wired **PUI Audio AS02404PO** body is registered on **UI B at [15.7,124]**, maximum **12.2 × 24.2 × 4.8 mm**. RF LS1 remains its electrical wire termination, not a second speaker body. C54 stays B0 and moves only **+0.30 mm Y** to **[14.805,136.905]**; its actual supply span improves to 3.8733 mm. Body registration is not acoustic or attachment qualification. |
| Microphone label | **UI F `MIC` [33,148.9]** identifies the RF microphone's bottom access: X33 = 80 − RF X47. It is a cross-board label, not an invented UI footprint. The abbreviation keeps the normal **1-mm text / 0.15-mm stroke** without overlapping `DOWN`. The RF `RF RP` / `BOOT` captions return to their uniform positions **[6,114.2] / [6,116.3]**; the former microphone-specific offset is withdrawn. |

The [under-Cap review](../hardware/layout/h6-r2-encoder-under-cap-review.json)
enumerates **106 previously unrouted RF references**, including SW3/U39/U83 and
the internal J3 shift of **+0.25 mm X** to **B90 [30.425,106.92]**. Local support
groups move with their real owners; U68 and U100 use explicitly reviewed compact
cells. C197, R169 and R235 are reserved but unchanged. The change preserves exact
MPNs, pad/net identities and **765 RF copper objects plus the unchanged UI's 92**;
native integration confirms their preservation.

The **2026-09-08 seven-part microphone correction** and the earlier **15 UI /
105 RF** package are historical scopes, not the new change list. RF remains
**12 on F / 768 on B**; UI stays 30 on F / 398 on B. The bottom microphone,
centred holder, service controls and four USB ports are not moved by this step.

The new review records **33 exact named-pad pair measurements**, including
regressions—not 33 electrical-performance passes. The upper headset's
`HEADSET_MIC_RAW` U83.1 → U85.3 straight span grows **23.229 → 80.397 mm**.
The compact U68 cell shortens its local selected/bias connections, but remote
`CAPTURE_RX_BIASED` and `CODEC_CAPTURE_VMID` branches become longer. Deliberate
low-noise routing and complete return-path review remain required. The relocated
UHF module also needs its RF feed, ground plane, power-delivery and coupling
review; geometric fit does not establish RF performance.

The selected `MIC_RAW` physical pad 1 → U85.1 span is **43.704–44.357 mm**
across its pads: a straight-line lower bound, **not a routed length or a qualified
quiet connection**. The capsule has an internal FET with a **2.2-kΩ load**;
`MIC_RAW` is not an unbuffered electret element. No new audio route is asserted.
Ground/ESD return, remote branches and measured noise/acoustics remain open.

The speaker contract reserves at least **0.8 mm diaphragm motion** and a
maximum **1.12 mm insulated mounting bed**. Its present Z screen uses existing
opposing-height metadata; this is not complete toleranced 3D proof, an adopted
tape MPN, or measured retention. The side sound path, wires and strain relief
still need implementation and inspection.

The repair preserves the prior **front-button symmetry**, ten indicators,
**14.7-mm SMA pitch**, recessed microSD and its access notch, upward display
FPC slot, M1 pair and board outline. It does not move other controls to imitate
the old H1 concept.

## Verification status

- The **106-reference native integration passes**, with **0 DRC violations /
  0 schematic-parity findings** and all **35/35 required RF labels** matched,
  with no collision candidates. Geometry passes **326 locality pairs / 72 critical
  spans, 0 placement conflicts**; the 33 pair reviews retain explicit regressions.
- All current views are refreshed and visually checked. System suite: **1482 tests
  (124 skips)**; KiCad-native H6 suite: **886 tests, no failures**.
- The preserved routing baseline is **857 copper objects: UI92 + RF765**,
  **197 resolved / 3071 unrouted connections**; this is not completed routing.

Historical only: the 2026-09-08 placement/microphone package passed DRC/parity,
1216-footprint parity, 20 intent checks, a 1383-test system run (95 skips) and
808 KiCad-native tests. Its 50-land SMA screen and five coax paths with at least
5.22 mm nominal slack remain prior evidence, not fresh qualification of this step.

The [current-routing audit](../hardware/layout/generated/H6-R2-current-routing-audit.json)
owns the live PCB hashes and source-bound checks; no old hash table is copied here.

The [shared validation command](../hardware/layout/h6_r2_validate.py), run with
KiCad Python, supports `--check --tests` and `--refresh --tests`. Refresh writes
derived files only; logs stay in ignored `work/`, and PCB changes stop the run.

## What remains open

The incorrect placements above are distinct from the existing unqualified
engineering boundaries:

- **Holder:** complete lands/locator registration, physical power routing,
  cell-floor geometry and actual NTC compression/thermal contact.
- **Encoder:** conditional rounded-slot and signal-hole fit, opposite-face
  protrusion and actual solder access. Both metal mounting lugs must be soldered;
  nominal clearances do not prove insertion, strength or the manufacturing process.
- **Audio:** noise-sensitive routing, real ground/ESD return, remote
  U68/U72/headset branches, sound transfer through the open bottom gap, speaker attachment and measured
  acoustics. Placement and direct spans do not qualify the whole audio path.
- **Other interfaces:** Cap mating/numbering, SMA finished-board thickness and
  antenna/tool fit, display folds/adhesive, card/plug tolerances and closed-device
  access remain bounded by the [interface review](h6-r2-interface-review.md).
- **Electrical behaviour:** power/startup and typed-ERC findings remain open.
  C5 BOOT connectivity, mux SEL/OE control and recovery under KILL are not repaired
  by this package. No safety interlock is relaxed and no prototype boot is claimed.

## Reproducible owners

The [placement contract](../hardware/layout/h6-r2-placement-contract.json) owns
exact poses and actual-pad limits. Narrow records describe
[UI supplies](../hardware/layout/h6-r2-ui-supply-locality.json),
[C259](../hardware/layout/h6-r2-slow-io-bulk-review.json),
[internal audio](../hardware/layout/h6-r2-inner-audio-candidate.json),
[seven-reference bottom microphone review](../hardware/layout/h6-r2-microphone-bottom-candidate.json),
[historical left encoder](../hardware/layout/h6-r2-encoder-left-candidate.json),
[current encoder-under-Cap review](../hardware/layout/h6-r2-encoder-under-cap-review.json) and
[the separate speaker body](../hardware/layout/h6-r2-speaker-body.json).
Historical rows and proofs remain immutable; explicit supersession metadata names
the current replacement owner. They are not fresh native receipts. The [current routing](h6-r2-current-routing.md) and
[component views](h6-r2-component-views.md) bind the actual promoted boards.

Earlier [holder-polarity evidence](../hardware/layout/h6-r2-holder-polarity-review.json)
and [encoder fit review](h6-r2-encoder-engineering-fit.md) remain source evidence,
not authority to restore their superseded placements. Current drawing fixes
do not make their remaining mechanics manufacturing-ready.

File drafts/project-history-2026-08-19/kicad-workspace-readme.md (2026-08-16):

# Active KiCad gate

- Status: **blocked by upstream design gates; no canonical symbols, schematic or PCB**
- Superseding process decision: [`DEC-0032`](../../docs/review/decisions/DEC-0032-reopen-product-design-before-cad.md)
- Archived premature snapshot: [`drafts/premature-compute-cad-2026-08-16`](../../drafts/premature-compute-cad-2026-08-16/README.md)

KiCad implementation may start only after all of these outputs are reviewed:

1. complete product requirements and constraints;
2. target physical/industrial design contract;
3. several whole-device architecture candidates derived from those inputs;
4. explicit optimality/Pareto comparison and owner selection;
5. conceptual mechanical, RF, power and service placement proving feasibility;
6. accepted architecture, resource and interface package;
7. exact component shortlist with current lifecycle/supply evidence.

Early component and CAD searches are allowed only as feasibility probes. Their
outputs stay in drafts and cannot become normative pins, footprints, BOM rows
or enclosure constraints before the gates above pass.

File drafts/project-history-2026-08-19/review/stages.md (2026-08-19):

# Этапы и статусы

Нормативные gate definitions и правила итерации находятся в
[`FLOW-0001`](architecture/FLOW-0001-product-to-cad-gates.md). Нумерация ниже
исправлена решением [`DEC-0032`](decisions/DEC-0032-reopen-product-design-before-cad.md);
прежняя последовательность ошибочно ставила architecture/BOM раньше product
and physical design (`FND-0039`).

## Где мы сейчас

`I8` ниже — внутренний шаг feasibility gate `2F`, а не одноимённый
верхнеуровневый gate `8`. I1…I9 проведены в working-candidate paper scope;
точный frozen BOM остаётся downstream gate 8. Текущая работа — G3
physical/product design от legacy-макета. Архитектура ещё не выбрана и KiCad
не разрешён.

```mermaid
flowchart TD
  G02["Gates 0–2<br/>baseline · product intent · capabilities<br/><b>ПРОВЕДЕНО РЕВЬЮ</b>"]
  I17["Gate 2F / I1–I7<br/>compute · safety · power · UI · audio · RF · expansion<br/><b>ПРОВЕДЕНО РЕВЬЮ В PAPER SCOPE</b>"]
  I8["Gate 2F / I8<br/>components · sources · cost · alternates<br/>175/187 цен + 12 gates · 4/4 physical-family gates<br/><b>ПРОВЕДЕНО РЕВЬЮ PAPER SCOPE</b>"]
  I9["Gate 2F / I9<br/>совместное self-review и candidate paper projection<br/><b>ПРОВЕДЕНО РЕВЬЮ PAPER SCOPE</b>"]
  G3["▶ МЫ ЗДЕСЬ — Gate 3<br/>целевой physical/product design<br/>legacy-макет — вход; integrated mockup возобновлён"]
  G48["Gates 4–8<br/>целые кандидаты → optimality → co-design<br/>→ atomic architecture → frozen BOM"]
  G9["Gate 9<br/>electrical/CAD + firmware architecture<br/><b>KICAD НЕ РАЗРЕШЁН</b>"]
  G1011["Gates 10–11<br/>PCB/pre-fab → prototype/HIL"]

  G02 --> I17 --> I8 --> I9 --> G3 --> G48 --> G9 --> G1011

  classDef reviewed fill:#163d2b,stroke:#35b779,color:#ffffff,stroke-width:2px;
  classDef current fill:#5a4300,stroke:#ffcc4d,color:#ffffff,stroke-width:4px;
  classDef blocked fill:#3b3f46,stroke:#8b949e,color:#ffffff,stroke-width:1px;
  class G02,I17,I8,I9 reviewed;
  class G3 current;
  class G48,G9,G1011 blocked;
```

| № | Gate | Основной выход | Статус |
|---:|---|---|---|
| 0 | Review baseline | правила, evidence/decision/finding ledgers | **Проведено ревью** |
| 1 | Product intent | назначение, ranked goals, safety/legal and no-loss boundaries | **Проведено ревью**; может быть переоткрыто явным finding |
| 2 | Capabilities | полный wishlist, competitors, requirements, exclusions, concurrency/failure needs | **Проведено повторное ревью `REV-0002AS`**: `W-EXTRA-11..17` полностью disposed; 6 GHz/Wi-Fi 6E rejected `DEC-0040` |
| 2F | Logical/electrical feasibility | neutral signal demand, real-device pin provenance, ≥2 complete owner/bus/GPIO maps and working baseline | **Проведено ревью working-candidate paper scope**: `FND-0116/I9-0001/REV-0005CD` jointly check I1…I9, all budgets, 858 architecture nodes / 857 supplied placements / 187 purchase lines and all 970 `abstract:*` occurrences / 59 labels; no unresolved owner decision remains. This is not selection of G7 atomic architecture. Exact RFQ, named production alternates, physical gate execution and factory COGS remain mandatory at G3/G8; KiCad remains unauthorized |
| 3 | Target product design | adapted legacy physical mockup, form factor, interaction, controls, interfaces, battery, antenna/service/environment/cost envelopes | **Активен**: `FND-0117/G3-0001/REV-0005CE` провели ревью current geometry re-entry и создали active generated `75×150-mm` clamshell starting projection; `PD-0001` — input, premature `LAY-0001` P1/P2/P3 — reference only; complete packing/ergonomics/connectors/HIL remain open and conflicts переоткрывают их G2F owner |
| 4 | Whole-device candidates | ≥2 complete architectures covering the same reviewed product | Не начато в исправленном процессе; старые `SYN-2A/2B/3A` — reference studies only |
| 5 | Optimality decision | reviewed weights, score/Pareto/sensitivity and owner selection | Не начато |
| 6 | Conceptual co-design | block/board/antenna/power/thermal/service placement and preliminary resource feasibility | Не начато |
| 7 | Atomic architecture | owners, transports, exact resources/pins, reset/update/safety and reopen gates | **Переоткрыто**; former `DEC-0028/PKG-0001` superseded as target by `DEC-0032` |
| 8 | Components and BOM | exact qualified parts, lifecycle/supply/cost/alternates | Заблокировано этапом 7; former stage-4 evidence is candidate/reference only |
| 9 | Electrical/CAD and firmware architecture | electrical specification, canonical libraries, schematic/ERC, runtime/HAL/toolchain/test contracts | Заблокировано; active KiCad contains no canonical implementation |
| 10 | PCB and pre-fab | placement/routing/DRC/SI/PI/RF/mechanical/manufacturing evidence | Не начато |
| 11 | Prototype and bring-up | assembly, recovery, safety/RF/HIL measurements | Не начато |

Этапы могут содержать параллельные feasibility probes, но их результаты
остаются черновиками. Ни одна ветвь не использует непроверенный или
candidate-only artifact как окончательный вход.

Текущее дополнение gate 2F: `DEC-0083/USB-0001/REV-0005AN` дают первому I4
endpoint product USB-C **«Проведено ревью»** на paper-schematic уровне. Exact
JAE receptacle, TI four-line CC/USB2 protection и corrected 220-pF CC shunts
внесены в machine map; placement, USB Full-Speed RC/SI, ESD/short-to-VBUS HIL
остаются открыты. I4 и gate 2F в целом продолжаются, KiCad не разрешён.
`DEC-0084/DSP-0006/REV-0005AO` затем дают display/touch paper endpoint
**«Проведено ревью»**: first exact 40-contact ZIF candidate, protected-main
logic rail, reset-low defaults и latch-off PWM backlight внесены в machine
map без нового GPIO. Real-tail mate, procurement и shared-SPI/touch/
backlight HIL остаются открыты; I4 и gate 2F продолжаются.
`DEC-0085/STO-0001/REV-0005AP` затем дают microSD paper endpoint
**«Проведено ревью»**: exact switched rail, Ioff SCK/CMD/CS isolation,
CS-gated DAT0/MISO, mandatory pulls, eight ESD channels и always-readable
detect внесены в machine map без нового GPIO. Socket access, media/endurance,
throughput, hot-remove и destructive HIL остаются открыты; I4 продолжается к
остальным UI endpoints.
`DEC-0086…0088/UI-0001/UI-0002/DSP-0007` затем сохраняют полный physical
control set, закрывают exact switch/current/ESD и фиксируют integrated ST77922
at `0x38` с active-low TP_INT, 10-kOhm raw pull-up и fixed 1G07 на GPIO37.
`FND-0094/IOX-0001/DEC-0089/REV-0005AT` завершают consolidated I4 audit:
TCA6424A получает полный exact power/address/reset/IRQ контракт, AON-наблюдение
изолируется от выключенного main-домена, pack target фиксируется на `0x2A`, а
остаточные USB/microSD/STOP endpoints становятся реальными. I4 имеет
**«Проведено ревью»**, активен I5; mechanics/specimen HIL остаются открыты,
KiCad по-прежнему не разрешён.
`FND-0095/AUDIO-0003/DEC-0090/REV-0005AU` затем закрывают I5: exact power,
supervisor и physical isolation для ES8311/Si4732/SA518, полный capture/
playback/TX тракт, exact microphone/speaker/headphone endpoints и все
first-target пассивы внесены в machine map. Main slow I/O становится
`21/0/3`; полный набор controls не изменён. I5 имеет **«Проведено ревью»**,
активен I6; its three-nRF paper electrical subblock is reviewed by
`DEC-0091/REV-0005AV`, and its separate native S3/C5 feeds by
`DEC-0092/REV-0005AW`. `FND-0098/CCRF-0001/DEC-0093/REV-0005AX` затем
исправляют односторонний CC band switch: exact dual-SP3T path, three-band
coupon, final-line ESD и AD8314 actual-TX sample входят в machine map; P03/P04
заняты; позднее `DEC-0098` отдаёт P05 native-Unit power request, поэтому current
main slow I/O становится `24/0/0`.
`FND-0099/VRF-0001/DEC-0094/REV-0005AY` далее закрывают SA518 paper RF path:
ANT contact 7, direct protected 50-Ом SMA boundary, 24-В low-C ESD и exact
5,1-кОм/52,3-Ом AD8314 sample. P05 не расходуется на фильтры без measured
failure. `FND-0100/IRF-0001/DEC-0095/REV-0005AZ` закрывают IR paper endpoint:
exact `TSOP95238TT + TSMP95000TT` RX pair, discharged/Ioff
receive boundary, `VSMY14940` current-limited STOP-gated TX и independent
`VEMD1060X01/TLV9061IDBVR` actual-optical evidence. Затем
`FND-0101/RXF-0001/DEC-0096/REV-0005BA` исправляют пропущенные abstract FMI/AMI:
отдельные защищённые FM/SW и не-50-Ом AM/LW first-target тракты теперь
завершены до физических SMA boundary. `FND-0102/REV-0005BB` дополнительно
исправляют всю сдвинутую SOIC-16 contact map Si4732 по визуально проверенному
manufacturer package drawing и regression-lock всех 16 контактов. Весь optical/thermal/IEC,
specimen/conducted/coexistence HIL остаётся открыт. `FND-0103/FND-0104/
COX-0001/DEC-0097/REV-0005BC` затем исправляют cross-group promotion и
неприменимый monolithic receiver/audio quiet contract, фиксируют one-group
runtime, отдельные quiet boundaries, восемь fixture classes, ordered
transitions и все no-stall thresholds. I6 paper scope имеет **«Проведено
ревью»** без присвоения несуществующих измерений; physical HIL может открыть
его владельца повторно. I7 закрыт `DEC-0098/0099`; I8 inventory coverage
проведён `FND-0109/BOM-0008`; `PWR-0022/DEC-0100/REV-0005BF` исправляют и
повторно закрывают narrow MAX17320 support I3. `FND-0111/BOM-0009/DEC-0102/
REV-0005BH` проверяют current source batch; после `BOM-0011` 186/187 purchase
lines имеют evidence,
а exact `HMX035CTFT-001` остаётся открыт. `DSP-0008/BOM-0010/REV-0005BI`
закрывают donor/specimen route, exact RFQ и no-drop-in policy без подмены
standalone sourcing. `BOM-0012/DEC-0104/REV-0005BK` закрывают
no-silent-substitution policy 187/187; `BOM-0013…0026/DEC-0105…0106/
REV-0005BL…CA` проводят ревью cost contract, explicit RFQ/retail gates и
первых 175/187 строк / 829 placements с partial subtotal USD 157.3727. Все 12
оставшихся цен имеют явные gates; они и specific alternate qualification активны,
KiCad не разрешён. `BOM-0027/REV-0005CB` добавляют 4/4 physical-family gate
contracts; `FND-0115/BOM-0028/REV-0005CC` проводят I8 paper review и передают
exact physical/frozen-BOM результаты в их G3/G8 gates. `FND-0116/I9-0001/
REV-0005CD` затем проводят совместное I9 working-candidate self-review и
возобновляют G3; это не G7 atomic architecture и не разрешение KiCad.
`FND-0112/BOM-0011/DEC-0103/REV-0005BJ` отдельно исправляют
двойной purchasing-счёт internal ST77922 и фиксируют current 857/187.

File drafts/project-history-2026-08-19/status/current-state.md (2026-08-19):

# Leshy2 Hardware — current engineering state

> Snapshot: 2026-08-19. This page describes proven maturity. The intended
> behavior is in the [hardware target README](../../README.md); software behavior
> is in the [firmware target README](https://github.com/anton-vinogradov/esp32-leshy2-firmware/blob/main/README.md).

- Canonical evidence: [review ledger](../review/README.md)
- Russian version: [current-state.ru.md](current-state.ru.md)
- Corrected gate chain: [`FLOW-0001`](../review/architecture/FLOW-0001-product-to-cad-gates.md)

## Review progress

| Gate | State |
|---|---|
| 0. Review baseline | Reviewed |
| 1. Product intent and safety/legal boundaries | Reviewed |
| 2. Capabilities, exclusions, concurrency/failure needs | **Reviewed again**: `REV-0002AS`; competitor delta closed |
| 2F. Logical/electrical feasibility | **Reviewed for the working-candidate paper scope**: I1…I9, all current budgets and all 59 unique `abstract:*` boundaries jointly pass; this is not G7 atomic-architecture selection |
| 3. Target physical/product design | **Active** from the `DEC-0051/PIN-0003` visible working design and legacy clamshell generator; P1/P2/P3 remain reference-only and physical conflicts loop back to their G2F owner |
| 4–6. Whole-device alternatives, optimality and conceptual co-design | Not started; G2F/G3 form an explicit review loop |
| 7. Atomic architecture | **Reopened** by `DEC-0032` |
| 8. Components/BOM | Blocked; previous evidence is candidate/reference only |
| 9. Electrical/CAD/firmware architecture | Blocked; no active canonical KiCad implementation |
| 10–11. PCB, fabrication and bring-up | Not started |

The canonical table is [`stages.md`](../review/stages.md).

The current I4 control/touch endpoint has **paper review completed** through
[`UI-0001`](../review/architecture/UI-0001-complete-local-control-topology.md)
[`UI-0002`](../review/architecture/UI-0002-exact-switch-and-control-protection.md)
and [`DSP-0007`](../review/architecture/DSP-0007-exact-integrated-st77922-touch-endpoint.md):
the full D-pad/OK/BACK/OPT/F1/F2/encoder/PTT/STOP/RE-ARM inventory is retained,
exact switch/protection routes are machine-projected, and integrated ST77922
touch is fixed at address `0x38` with active-low IRQ on shared GPIO37.
Cap/guard/harness/enclosure and specimen/electrical HIL remain open.

The dependent I5 audio/receiver block now has **paper review completed**
through [`AUDIO-0003`](../review/architecture/AUDIO-0003-exact-audio-and-receiver-endpoint.md),
`DEC-0090` and `REV-0005AU`. ES8311, Si4732 and SA518 have exact reset-off
power and physical interface isolation; receiver/microphone capture, bypass/
codec playback, ordinary/codec-injected TX and exact microphone, speaker and
switched-headphone endpoints are complete on paper. P00/P01/P02 implement
capture source, speaker enable and headphone sensing; CC1101 band selection
now uses P03/P04 and leaves P05 free;
the full D-pad, PTT, STOP, F1/F2 and encoder remain unchanged. Acoustic, RF,
specimen and concurrent-load HIL remain explicit, and I6 is active.

The first four I6 slices now also have **paper review completed**. Three
full-function nRF paths have independent Ioff isolation, local energy and
directional 2400…2525-MHz evidence. Separate S3 2.4-GHz and C5 2.4/5-GHz
feeds run from real module RF contacts through exact PCB U.FL receptacles and
`CP0603Q5425ENTR` couplers into complete LTC5532 channels; C5 ANT2 remains
default-disabled/no-connect. The CC1101 path uses two equal-control
`BGS13SN8E6327XTSA1` bodies around exact 315/433/868–915-MHz first-pass
branches, so `00` isolates both ends; P03/P04 are rail-off band truth bits and
P05 is the only free main slow-I/O contact. The complete line has exact ESD
and an `AD8314ACPZ-RL7` actual-TX sample after all switching/matching. Exact
jumper/chassis connectors, thresholds, VNA/conducted and whole-device
RF/coexistence HIL remain open. SA518 ANT contact 7 now feeds a direct
controlled-50-Ohm SMA boundary with exact 24-V `PESD24VY1BSF` protection and
an `AD8314ACPZ-RL7` 5.1-kOhm/52.3-Ohm actual-TX sample. No unproven external
filter bank consumes P05; measured conducted failure reopens that choice.
IR and consolidated coexistence are the next active slices.

## Competitor-delta closure

- `W-EXTRA-11` is closed: [`DEC-0033/REQ-IBTN-0001`](../review/decisions/DEC-0033-external-m5-ibutton-profile.md)
  accepts an external passive M5-style Port-B iButton adapter and no base pad;
- infrastructure is closed by [`DEC-0034/REQ-EXT-0001`](../review/decisions/DEC-0034-m5-first-two-tier-expansion.md): M5-first Unit/Cap plus a separate high-throughput class, without native M5-Bus;
- former `W-EXTRA-12` FIDO acceptance is removed from target by [`DEC-0039`](../review/decisions/DEC-0039-radio-key-scope-correction.md);
- `W-EXTRA-13` is closed by [`DEC-0036`](../review/decisions/DEC-0036-no-product-haptic.md): no product haptic, motor, dedicated profile or mount;
- `W-EXTRA-14` is closed by [`DEC-0037`](../review/decisions/DEC-0037-optional-external-imu-measurement-pose.md)/[`REQ-IMU-0001`](../review/requirements/REQ-IMU-0001-external-measurement-pose.md);
- `W-EXTRA-15` is closed by [`DEC-0038`](../review/decisions/DEC-0038-phone-assisted-text-no-integrated-keyboard.md): no integrated keyboard, bounded phone-assisted text;
- `W-EXTRA-16` generic High-Speed USB host is rejected by `DEC-0039`; only RF-derived transport remains;
- `W-EXTRA-17` 6 GHz/Wi-Fi 6E is fully rejected by `DEC-0040`; accepted
  autonomous 2.4/5 GHz remains unchanged.

`REV-0002AS` closes repeated G2 review. `DEC-0041` makes G2F active before the
physical mockup; `DEC-0042` accepts its machine-readable exact-device/net source.

## What remains reviewed

- all-in-one autonomous field-product intent, non-aggression onboarding and the
  Main/Lab/Controlled-Zone safety model;
- conservative TX defaults, explicit maximum-power choice, hard STOP/no
  automatic re-arm and separate actual-TX evidence;
- the complete 125-leaf wishlist review and no-loss cost rule;
- three full-function nRF24 paths with every simultaneous PTX/PRX role mix;
- ordinary 2.4/5 GHz Wi-Fi, IEEE 802.15.4, native BLE and 2.4 GHz/ESP-NOW
  capability requirements;
- packet Sub-GHz, broadcast receive, analog voice, audio, IR, external
  GNSS/LoRa/NFC, the external iButton/1-Wire adapter and their safety/evidence
  boundaries;
- open owner-controlled signed updates and the requirement that every selected
  programmable chip retain independent programming/recovery/diagnostics.

These are product inputs. `G2F-3I/PIN-0003` is now the reviewed, reopenable
working owner/bus/compute-pin baseline for G3, not the final atomic
architecture. Board count, connectors, exact electrical parts and enclosure
remain unaccepted; physical/RF/power conflict may change working pins.
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

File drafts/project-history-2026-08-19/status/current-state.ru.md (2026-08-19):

# Аппаратная часть Leshy2 — текущее состояние проработки

> Снимок: 2026-08-19. Здесь указана доказанная зрелость. Образ готового
> продукта — в [целевом hardware README](../../README.ru.md), software — в
> [целевом firmware README](https://github.com/anton-vinogradov/esp32-leshy2-firmware/blob/main/README.ru.md).

- Канонические evidence: [журнал ревью](../review/README.md)
- English version: [current-state.md](current-state.md)
- Исправленная gate chain: [`FLOW-0001`](../review/architecture/FLOW-0001-product-to-cad-gates.md)
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

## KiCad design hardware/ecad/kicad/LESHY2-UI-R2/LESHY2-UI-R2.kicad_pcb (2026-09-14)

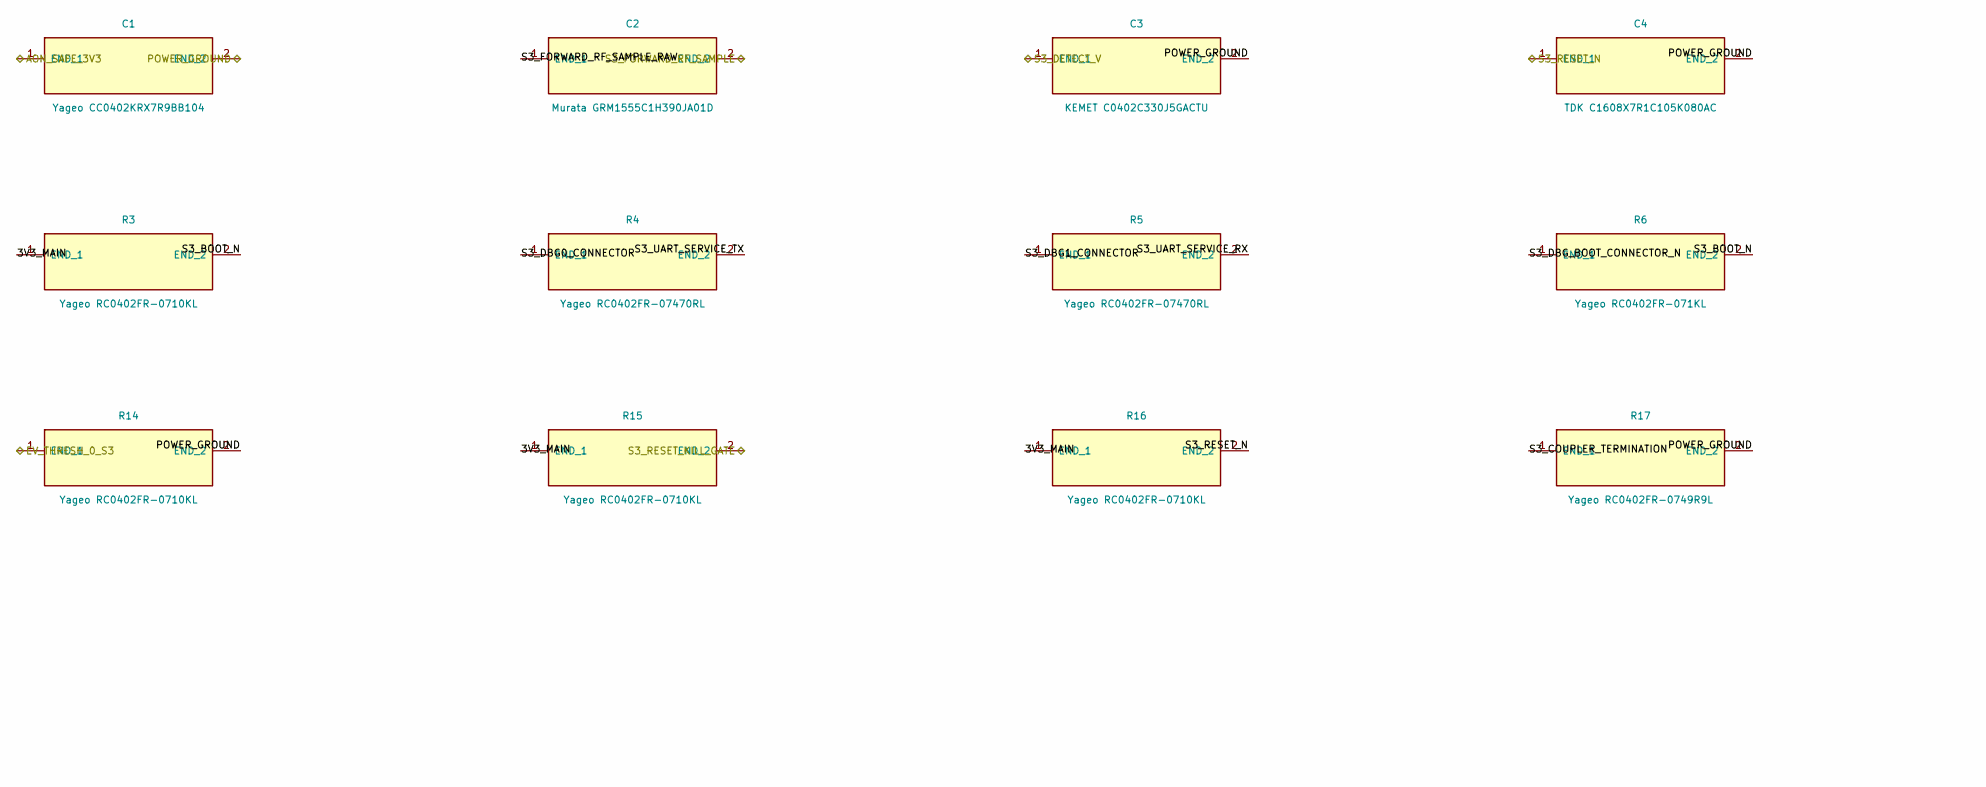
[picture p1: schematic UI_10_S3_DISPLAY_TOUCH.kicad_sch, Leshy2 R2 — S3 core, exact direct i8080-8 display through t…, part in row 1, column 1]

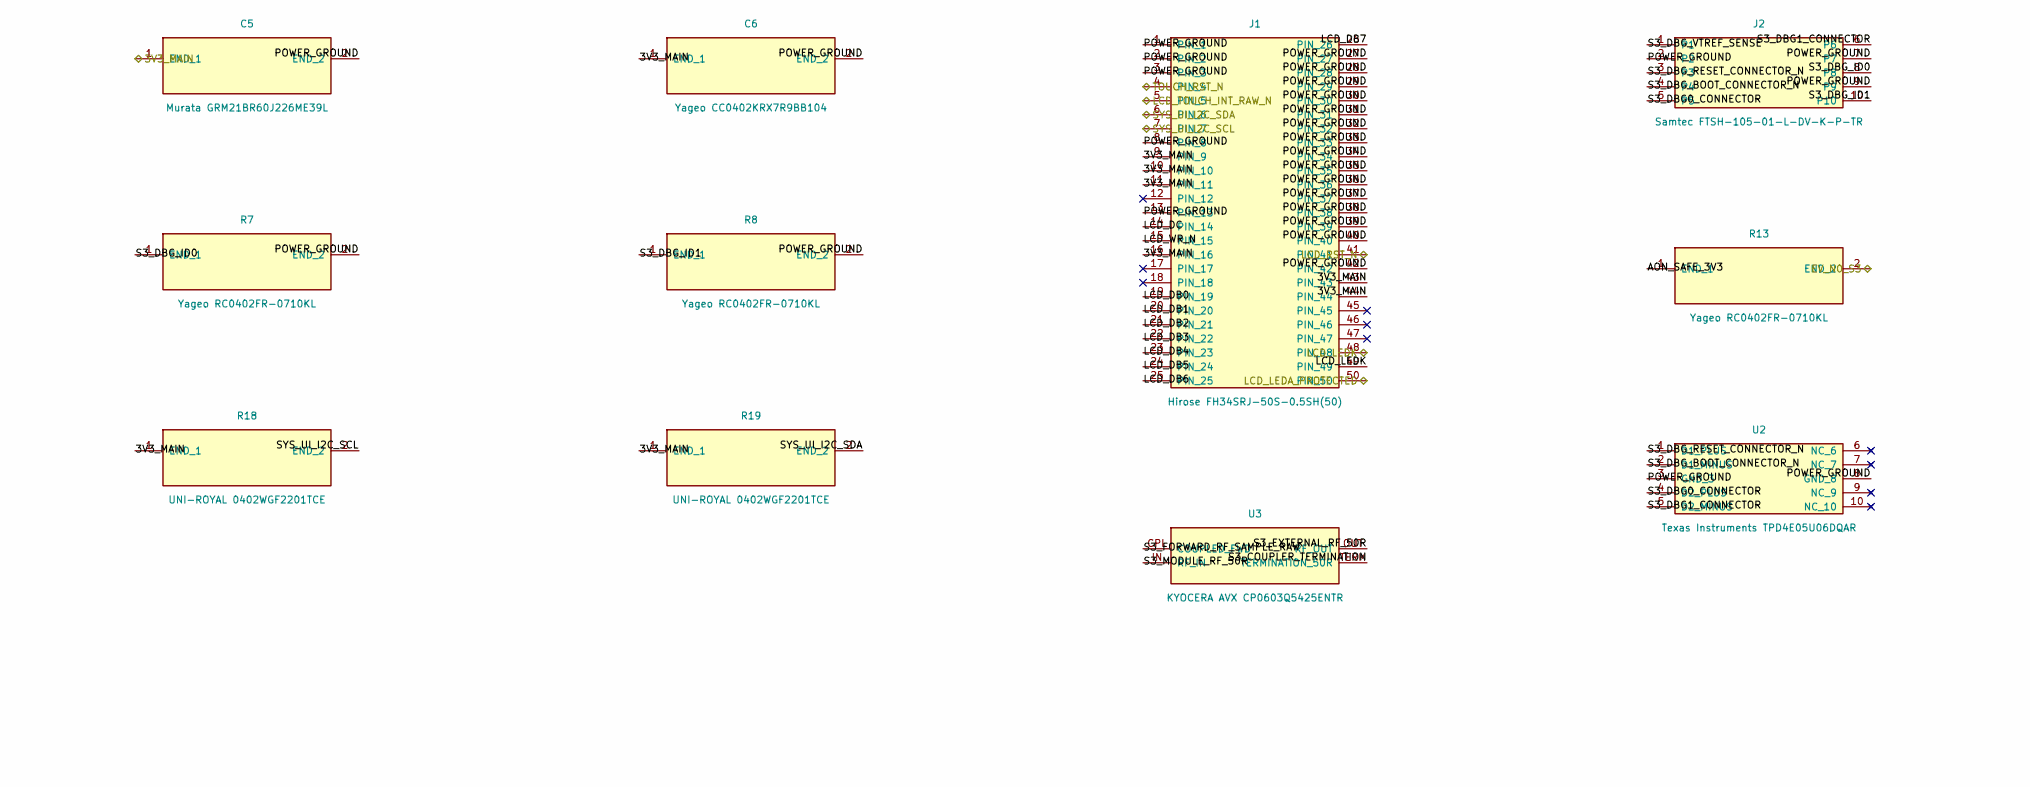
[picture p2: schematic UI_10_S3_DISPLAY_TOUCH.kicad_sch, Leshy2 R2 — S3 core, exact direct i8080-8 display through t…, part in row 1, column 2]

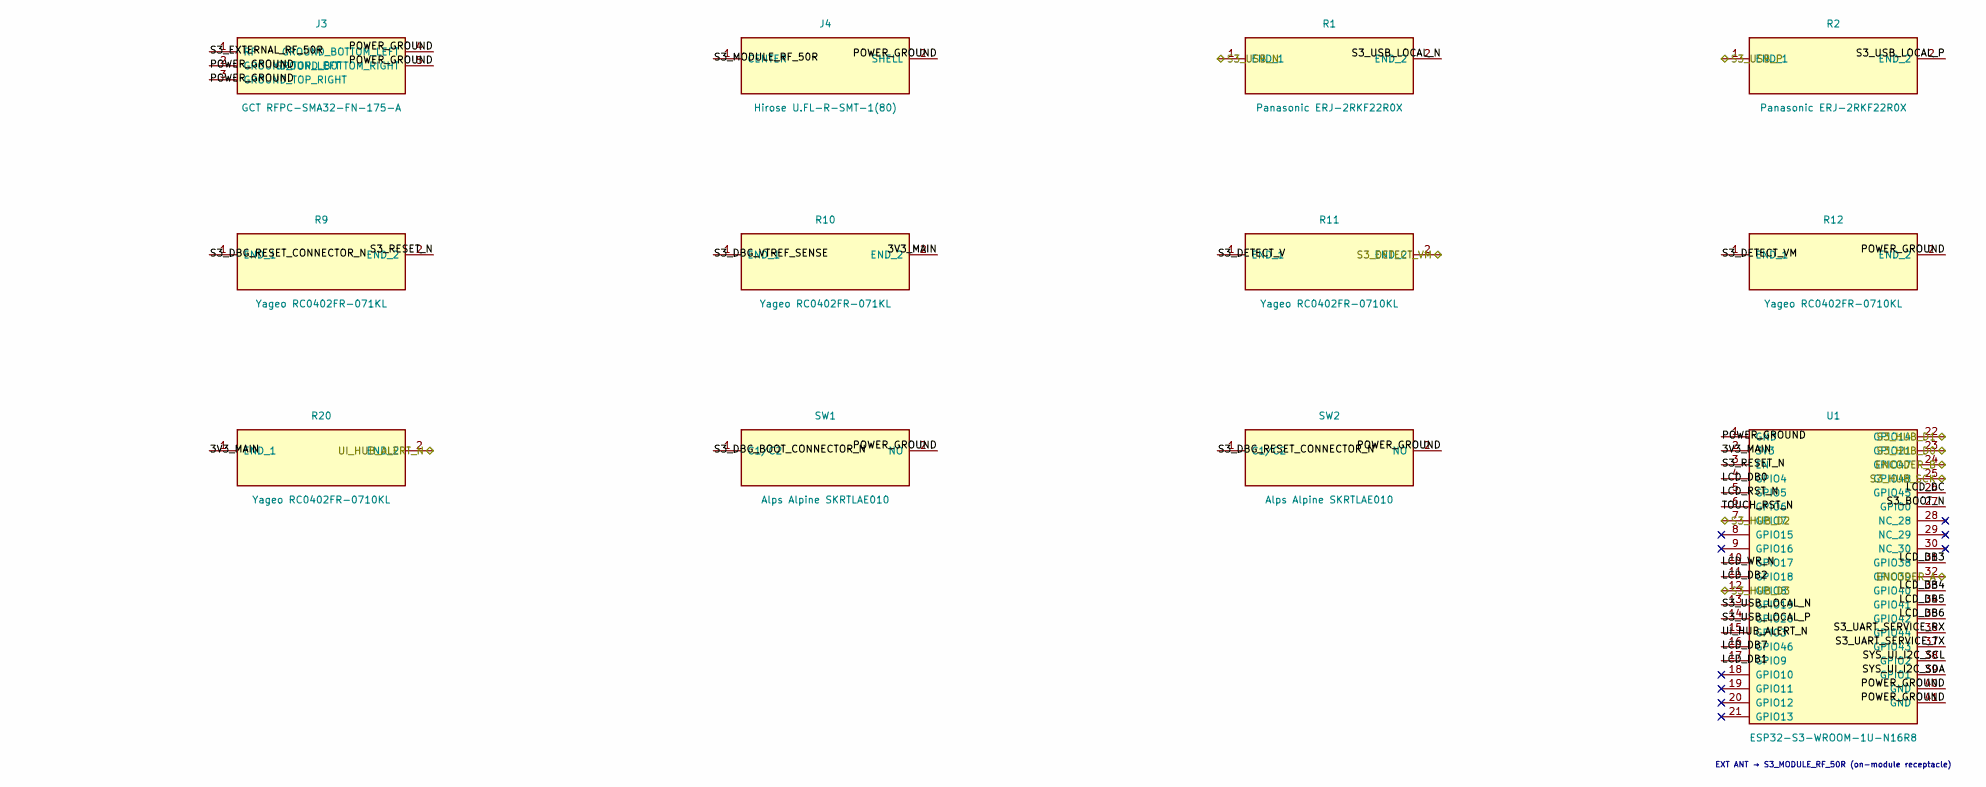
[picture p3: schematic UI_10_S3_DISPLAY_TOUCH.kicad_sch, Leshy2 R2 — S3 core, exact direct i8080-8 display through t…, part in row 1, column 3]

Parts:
C1, C6: Yageo CC0402KRX7R9BB104; C_0402_1005Metric
C2: Murata GRM1555C1H390JA01D; C_0402_1005Metric
C3: KEMET C0402C330J5GACTU; C_0402_1005Metric
C4: TDK C1608X7R1C105K080AC; C_0603_1608Metric
C5: Murata GRM21BR60J226ME39L; C_0805_2012Metric
J1: Hirose FH34SRJ-50S-0.5SH(50); FH34SRJ-50S-0.5SH-50
J2: Samtec FTSH-105-01-L-DV-K-P-TR; FTSH-105-01-L-DV-K-P-TR
J3: GCT RFPC-SMA32-FN-175-A; RFPC-SMA32-FN-175-A
J4: Hirose U.FL-R-SMT-1(80); U.FL_Hirose_U.FL-R-SMT-1_Vertical
R1, R2: Panasonic ERJ-2RKF22R0X; R_0402_1005Metric
R3, R7, R8, R11, R12, R13, R14, R15, R16, R20: Yageo RC0402FR-0710KL; R_0402_1005Metric
R4, R5: Yageo RC0402FR-07470RL; R_0402_1005Metric
R6, R9, R10: Yageo RC0402FR-071KL; R_0402_1005Metric
R17: Yageo RC0402FR-0749R9L; R_0402_1005Metric
R18, R19: UNI-ROYAL 0402WGF2201TCE; R_0402_1005Metric
SW1, SW2: Alps Alpine SKRTLAE010; SW_Push_1P1T-MP_NO_Horizontal_Alps_SKRTLAE010
U1: ESP32-S3-WROOM-1U-N16R8; ESP32-S3-WROOM-1U
U2: Texas Instruments TPD4E05U06DQAR; USON-10_2.5x1.0mm_P0.5mm
U3: KYOCERA AVX CP0603Q5425ENTR; CP0603Q5425ENTR

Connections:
/UI_10_S3_DISPLAY_TOUCH/3V3_MAIN: C5.1 (END_1), C6.1 (END_1), J1.9 (PIN_9), J1.10 (PIN_10), J1.11 (PIN_11), J1.16 (PIN_16), J1.43 (PIN_43), J1.44 (PIN_44), R3.1 (END_1), R10.2 (END_2), R15.1 (END_1), R16.1 (END_1), R18.1 (END_1), R19.1 (END_1), R20.1 (END_1), U1.2 (3V3); also elsewhere on the board
/UI_10_S3_DISPLAY_TOUCH/AON_SAFE_3V3: C1.1 (END_1), R13.1 (END_1); also elsewhere on the board
/UI_10_S3_DISPLAY_TOUCH/ENCODER_A: U1.32 (GPIO39); also elsewhere on the board
/UI_10_S3_DISPLAY_TOUCH/ENCODER_B: U1.24 (GPIO47); also elsewhere on the board
/UI_10_S3_DISPLAY_TOUCH/LCD_DB0: J1.19 (PIN_19), U1.4 (GPIO4)
/UI_10_S3_DISPLAY_TOUCH/LCD_DB1: J1.20 (PIN_20), U1.17 (GPIO9)
/UI_10_S3_DISPLAY_TOUCH/LCD_DB2: J1.21 (PIN_21), U1.11 (GPIO18)
/UI_10_S3_DISPLAY_TOUCH/LCD_DB3: J1.22 (PIN_22), U1.31 (GPIO38)
/UI_10_S3_DISPLAY_TOUCH/LCD_DB4: J1.23 (PIN_23), U1.33 (GPIO40)
/UI_10_S3_DISPLAY_TOUCH/LCD_DB5: J1.24 (PIN_24), U1.34 (GPIO41)
/UI_10_S3_DISPLAY_TOUCH/LCD_DB6: J1.25 (PIN_25), U1.35 (GPIO42)
/UI_10_S3_DISPLAY_TOUCH/LCD_DB7: J1.26 (PIN_26), U1.16 (GPIO46)
/UI_10_S3_DISPLAY_TOUCH/LCD_DC: J1.14 (PIN_14), U1.26 (GPIO45)
/UI_10_S3_DISPLAY_TOUCH/LCD_LEDK: J1.48 (PIN_48), J1.49 (PIN_49); also elsewhere on the board
/UI_10_S3_DISPLAY_TOUCH/LCD_RST_N: J1.41 (PIN_41), U1.5 (GPIO5); also elsewhere on the board
/UI_10_S3_DISPLAY_TOUCH/LCD_WR_N: J1.15 (PIN_15), U1.10 (GPIO17)
/UI_10_S3_DISPLAY_TOUCH/POWER_GROUND: C1.2 (END_2), C3.2 (END_2), C4.2 (END_2), C5.2 (END_2), C6.2 (END_2), J1.1 (PIN_1), J1.2 (PIN_2), J1.3 (PIN_3), J1.8 (PIN_8), J1.13 (PIN_13), J1.27 (PIN_27), J1.28 (PIN_28), J1.29 (PIN_29), J1.30 (PIN_30), J1.31 (PIN_31), J1.32 (PIN_32), J1.33 (PIN_33), J1.34 (PIN_34), J1.35 (PIN_35), J1.36 (PIN_36), J1.37 (PIN_37), J1.38 (PIN_38), J1.39 (PIN_39), J1.40 (PIN_40), J1.42 (PIN_42), J2.2, J2.7, J2.9, J3.2 (GROUND_TOP_LEFT), J3.3 (GROUND_TOP_RIGHT), J3.4 (GROUND_BOTTOM_LEFT), J3.5 (GROUND_BOTTOM_RIGHT), J4.2 (SHELL), R7.2 (END_2), R8.2 (END_2), R12.2 (END_2), R14.2 (END_2), R17.2 (END_2), SW1.2 (NO), SW2.2 (NO), U1.1 (GND), U1.40 (GND), U1.41 (GND), U2.3 (GND_3), U2.8 (GND_8); also elsewhere on the board
/UI_10_S3_DISPLAY_TOUCH/S3_BOOT_N: R3.2 (END_2), R6.2 (END_2), U1.27 (GPIO0)
/UI_10_S3_DISPLAY_TOUCH/S3_COUPLER_TERMINATION: R17.1 (END_1), U3.TERM (TERMINATION_50R)
/UI_10_S3_DISPLAY_TOUCH/S3_DBG0_CONNECTOR: J2.5, R4.1 (END_1), U2.4 (D2_PLUS)
/UI_10_S3_DISPLAY_TOUCH/S3_DBG1_CONNECTOR: J2.6, R5.1 (END_1), U2.5 (D2_MINUS)
/UI_10_S3_DISPLAY_TOUCH/S3_DBG_BOOT_CONNECTOR_N: J2.4, R6.1 (END_1), SW1.1 (C1/C2), U2.2 (D1_MINUS)
/UI_10_S3_DISPLAY_TOUCH/S3_DBG_ID0: J2.8, R7.1 (END_1)
/UI_10_S3_DISPLAY_TOUCH/S3_DBG_ID1: J2.10, R8.1 (END_1)
/UI_10_S3_DISPLAY_TOUCH/S3_DBG_RESET_CONNECTOR_N: J2.3, R9.1 (END_1), SW2.1 (C1/C2), U2.1 (D1_PLUS)
/UI_10_S3_DISPLAY_TOUCH/S3_DBG_VTREF_SENSE: J2.1, R10.1 (END_1)
/UI_10_S3_DISPLAY_TOUCH/S3_DETECT_V: C3.1 (END_1), R11.1 (END_1); also elsewhere on the board
/UI_10_S3_DISPLAY_TOUCH/S3_DETECT_VM: R11.2 (END_2), R12.1 (END_1); also elsewhere on the board
/UI_10_S3_DISPLAY_TOUCH/S3_EXTERNAL_RF_50R: J3.1 (RF), U3.OUT (RF_OUT)
/UI_10_S3_DISPLAY_TOUCH/S3_FORWARD_RF_SAMPLE: C2.2 (END_2); also elsewhere on the board
/UI_10_S3_DISPLAY_TOUCH/S3_FORWARD_RF_SAMPLE_RAW: C2.1 (END_1), U3.CPL (COUPLED_FWD)
/UI_10_S3_DISPLAY_TOUCH/S3_HUB_D0: U1.23 (GPIO21); also elsewhere on the board
/UI_10_S3_DISPLAY_TOUCH/S3_HUB_D1: U1.22 (GPIO14); also elsewhere on the board
/UI_10_S3_DISPLAY_TOUCH/S3_HUB_D2: U1.7 (GPIO7); also elsewhere on the board
/UI_10_S3_DISPLAY_TOUCH/S3_HUB_D3: U1.12 (GPIO8); also elsewhere on the board
/UI_10_S3_DISPLAY_TOUCH/S3_HUB_SCK: U1.25 (GPIO48); also elsewhere on the board
/UI_10_S3_DISPLAY_TOUCH/S3_MODULE_RF_50R: J4.1 (CENTER), U3.IN (RF_IN)
/UI_10_S3_DISPLAY_TOUCH/S3_RESET_KILL_GATE: R15.2 (END_2); also elsewhere on the board
/UI_10_S3_DISPLAY_TOUCH/S3_RESET_N: C4.1 (END_1), R9.2 (END_2), R16.2 (END_2), U1.3 (EN); also elsewhere on the board
/UI_10_S3_DISPLAY_TOUCH/S3_UART_SERVICE_RX: R5.2 (END_2), U1.36 (GPIO44)
/UI_10_S3_DISPLAY_TOUCH/S3_UART_SERVICE_TX: R4.2 (END_2), U1.37 (GPIO43)
/UI_10_S3_DISPLAY_TOUCH/S3_USB_LOCAL_N: R1.2 (END_2), U1.13 (GPIO19)
/UI_10_S3_DISPLAY_TOUCH/S3_USB_LOCAL_P: R2.2 (END_2), U1.14 (GPIO20)
/UI_10_S3_DISPLAY_TOUCH/S3_USB_N: R1.1 (END_1); also elsewhere on the board
/UI_10_S3_DISPLAY_TOUCH/S3_USB_P: R2.1 (END_1); also elsewhere on the board
/UI_10_S3_DISPLAY_TOUCH/SYS_UI_I2C_SCL: J1.7 (PIN_7), R18.2 (END_2), U1.38 (GPIO2); also elsewhere on the board
/UI_10_S3_DISPLAY_TOUCH/SYS_UI_I2C_SDA: J1.6 (PIN_6), R19.2 (END_2), U1.39 (GPIO1); also elsewhere on the board
/UI_10_S3_DISPLAY_TOUCH/TOUCH_RST_N: J1.4 (PIN_4), U1.6 (GPIO6); also elsewhere on the board
/UI_10_S3_DISPLAY_TOUCH/UI_HUB_ALERT_N: R20.2 (END_2), U1.15 (GPIO3); also elsewhere on the board
/UI_11_STORAGE_CONTROLS_INDICATORS/LCD_LEDA_PROTECTED: J1.50 (PIN_50); also elsewhere on the board
/UI_11_STORAGE_CONTROLS_INDICATORS/LCD_TOUCH_INT_RAW_N: J1.5 (PIN_5); also elsewhere on the board
/UI_50_FRONT_POWER_SAFETY/EV_N0_S3: R13.2 (END_2); also elsewhere on the board
/UI_50_FRONT_POWER_SAFETY/EV_THRESH_0_S3: R14.1 (END_1); also elsewhere on the board

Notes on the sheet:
EXT ANT → S3_MODULE_RF_50R (on-module receptacle)

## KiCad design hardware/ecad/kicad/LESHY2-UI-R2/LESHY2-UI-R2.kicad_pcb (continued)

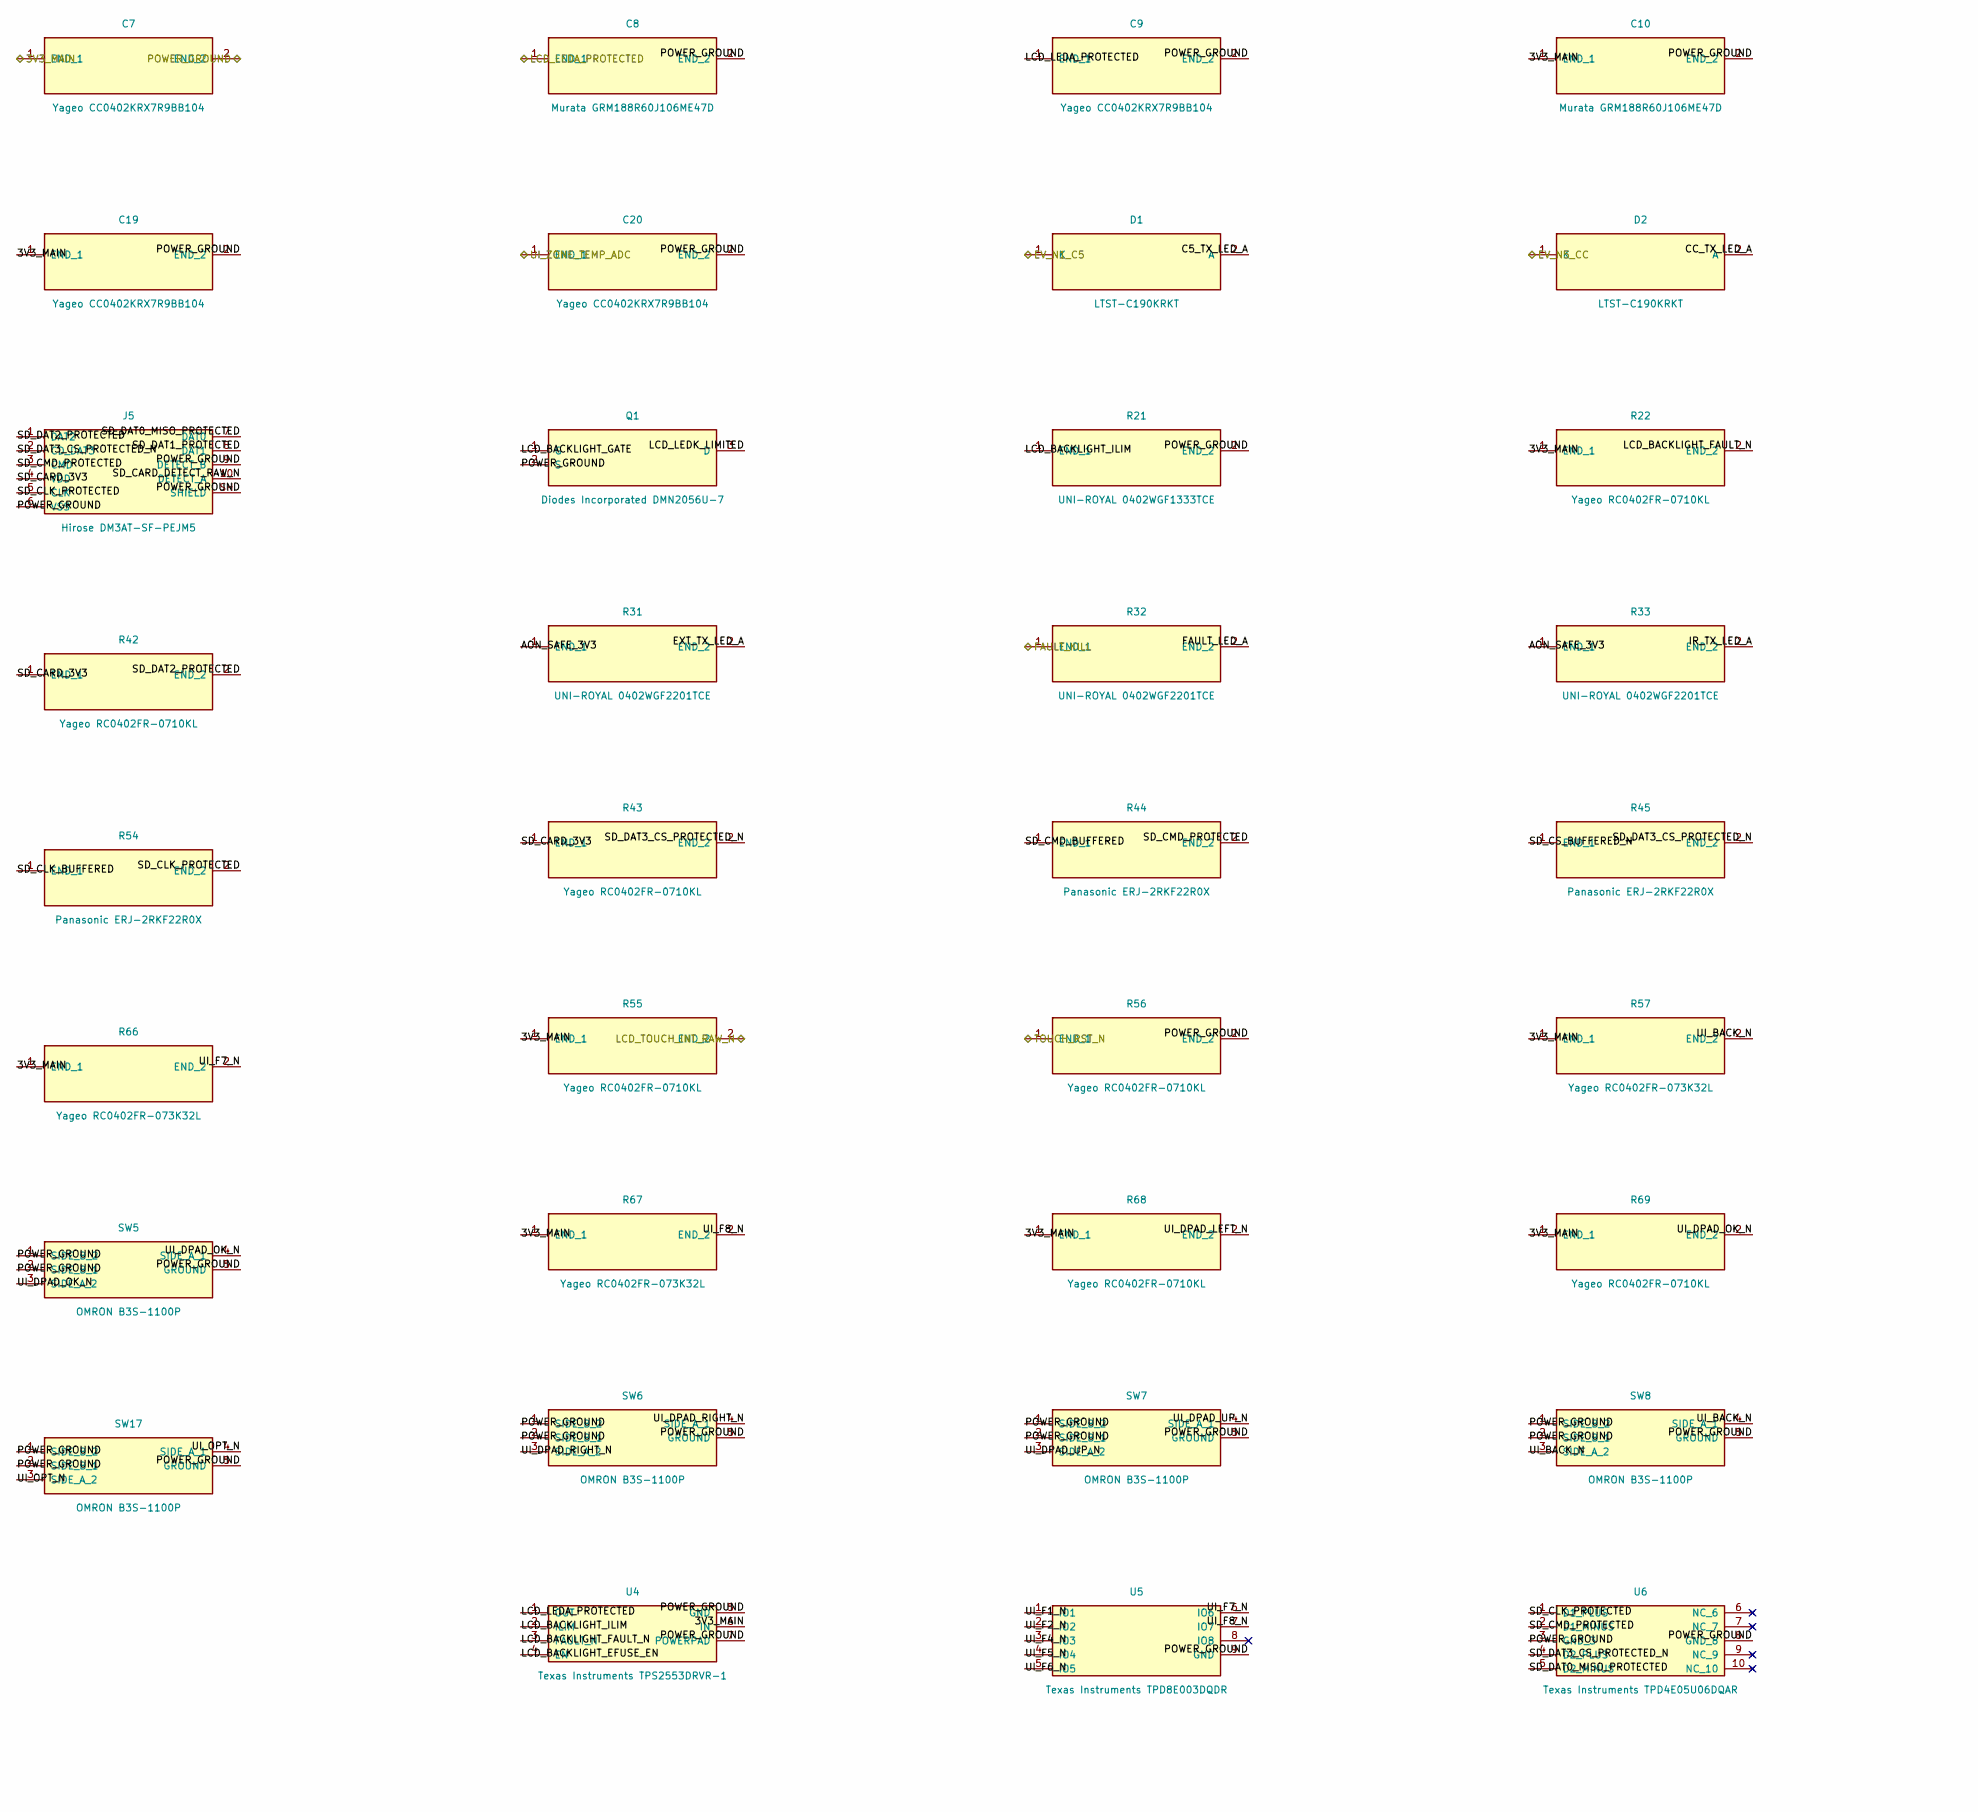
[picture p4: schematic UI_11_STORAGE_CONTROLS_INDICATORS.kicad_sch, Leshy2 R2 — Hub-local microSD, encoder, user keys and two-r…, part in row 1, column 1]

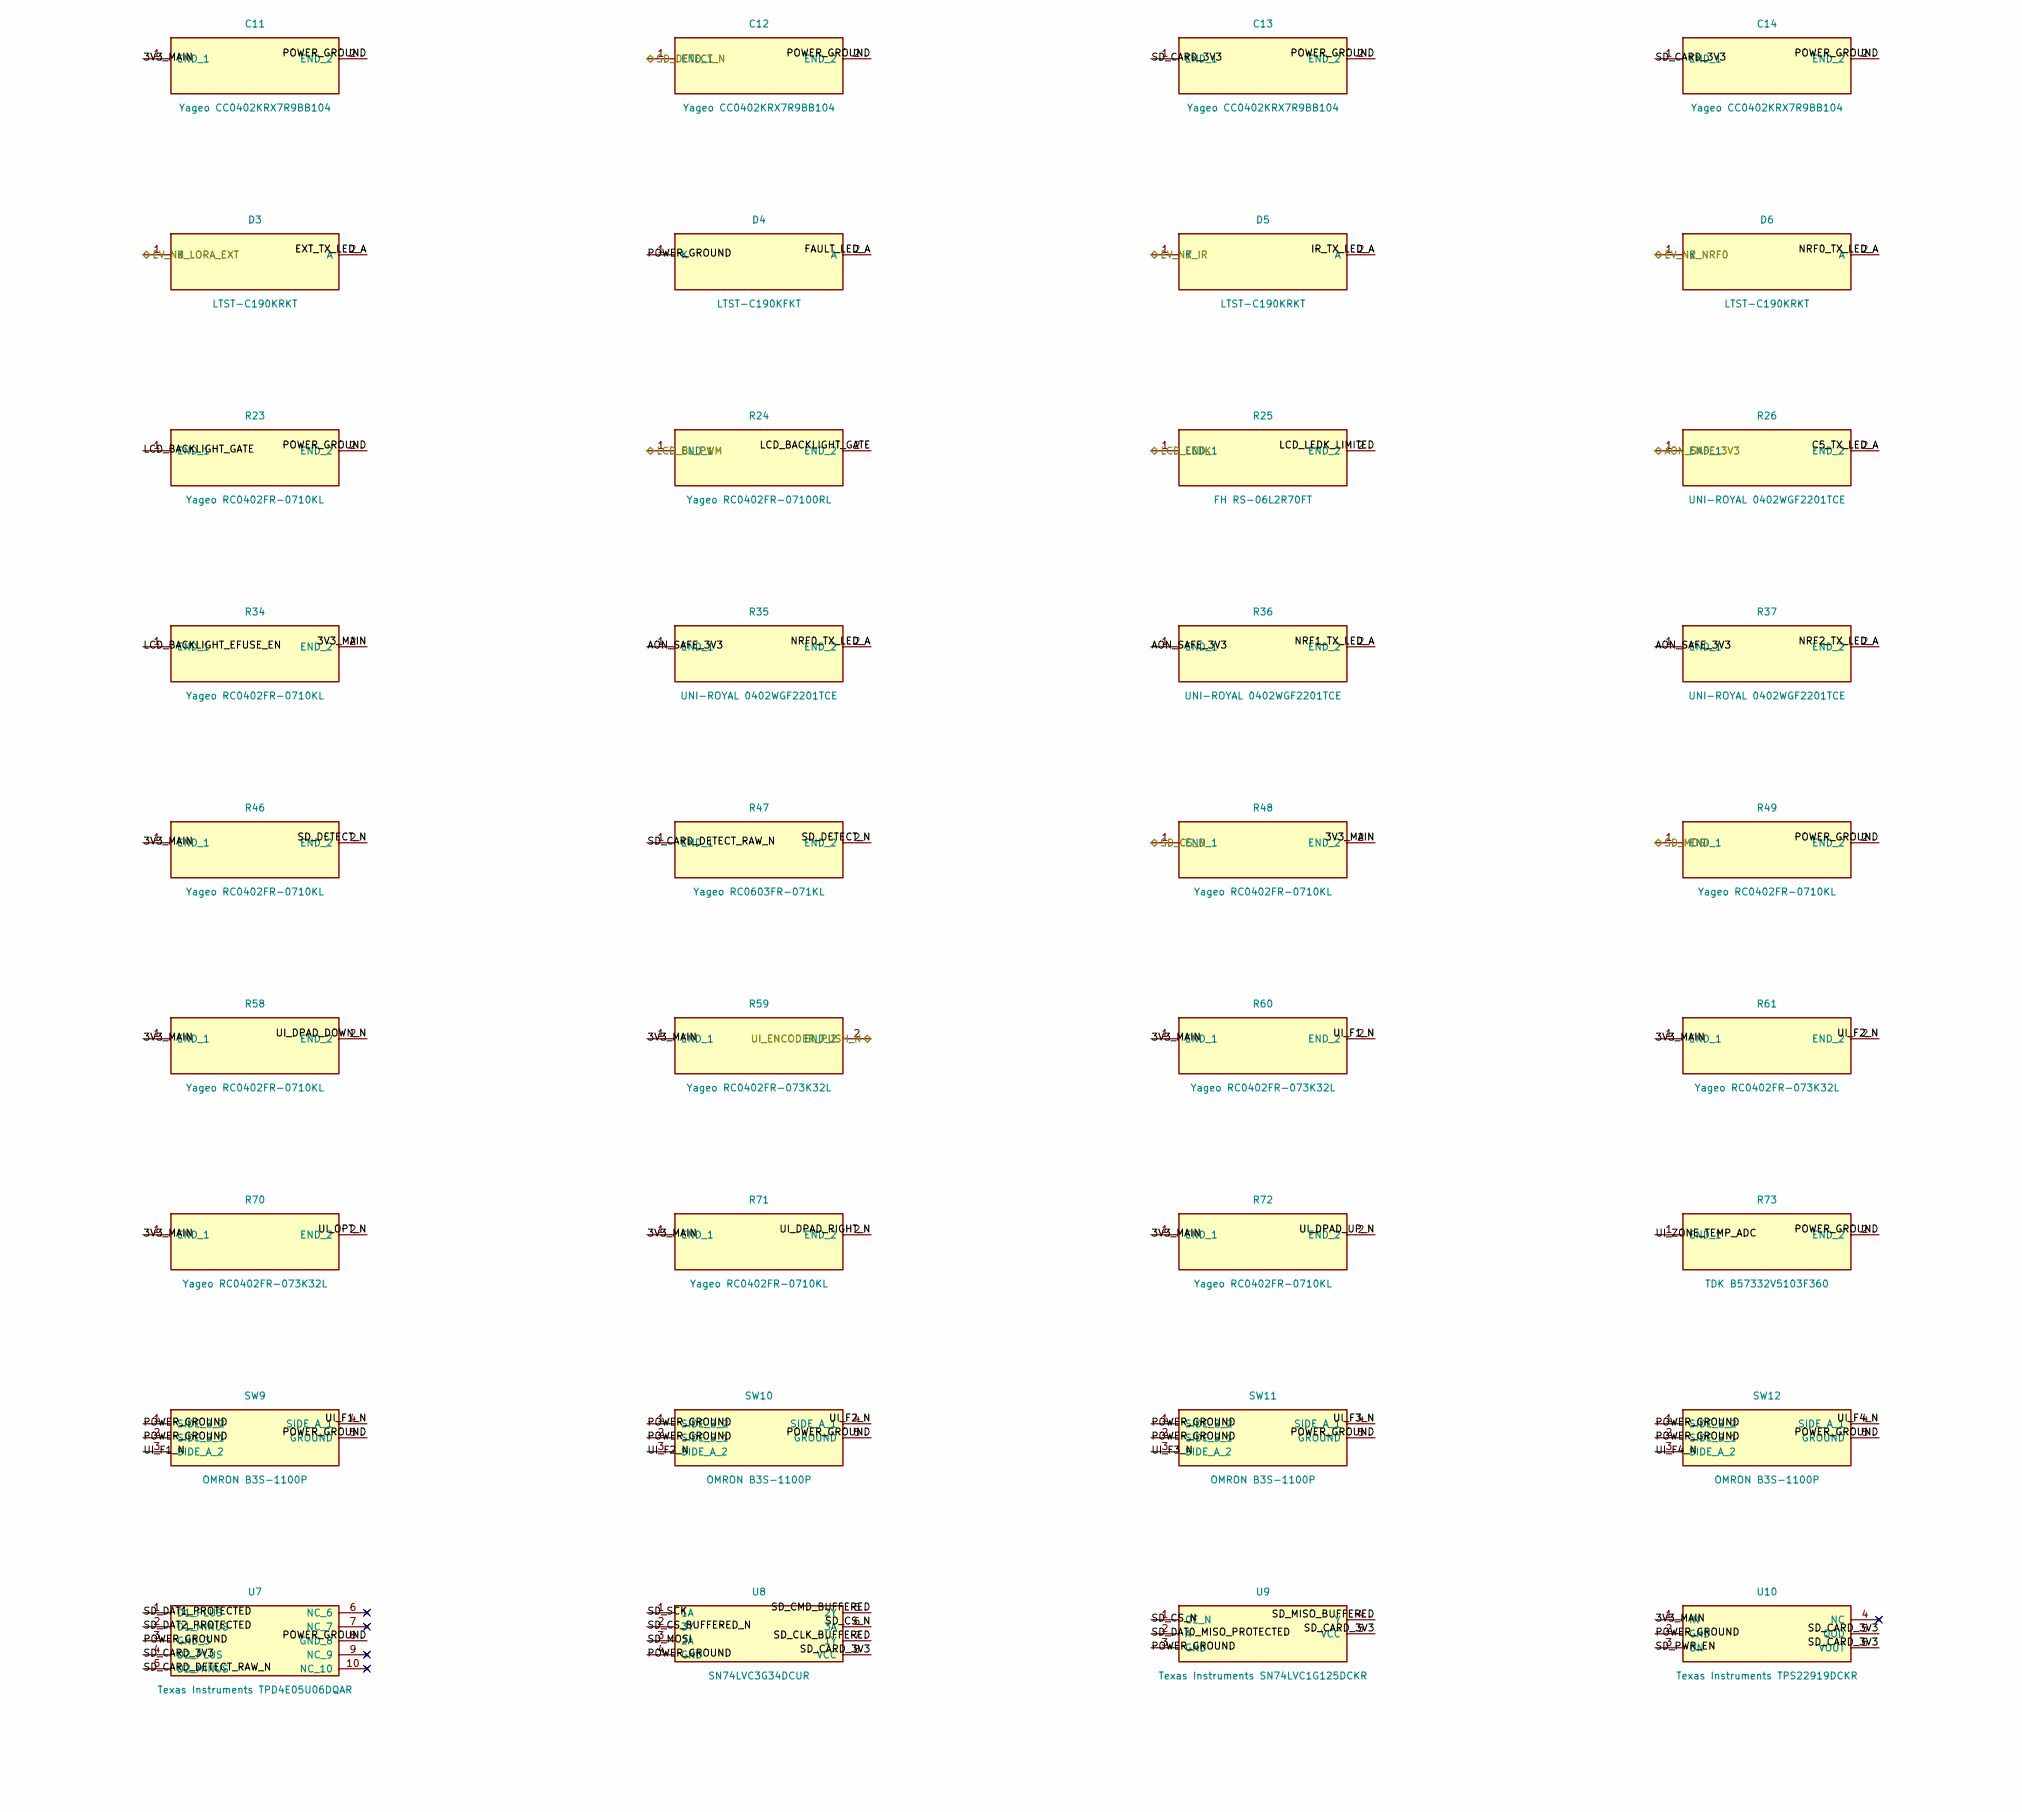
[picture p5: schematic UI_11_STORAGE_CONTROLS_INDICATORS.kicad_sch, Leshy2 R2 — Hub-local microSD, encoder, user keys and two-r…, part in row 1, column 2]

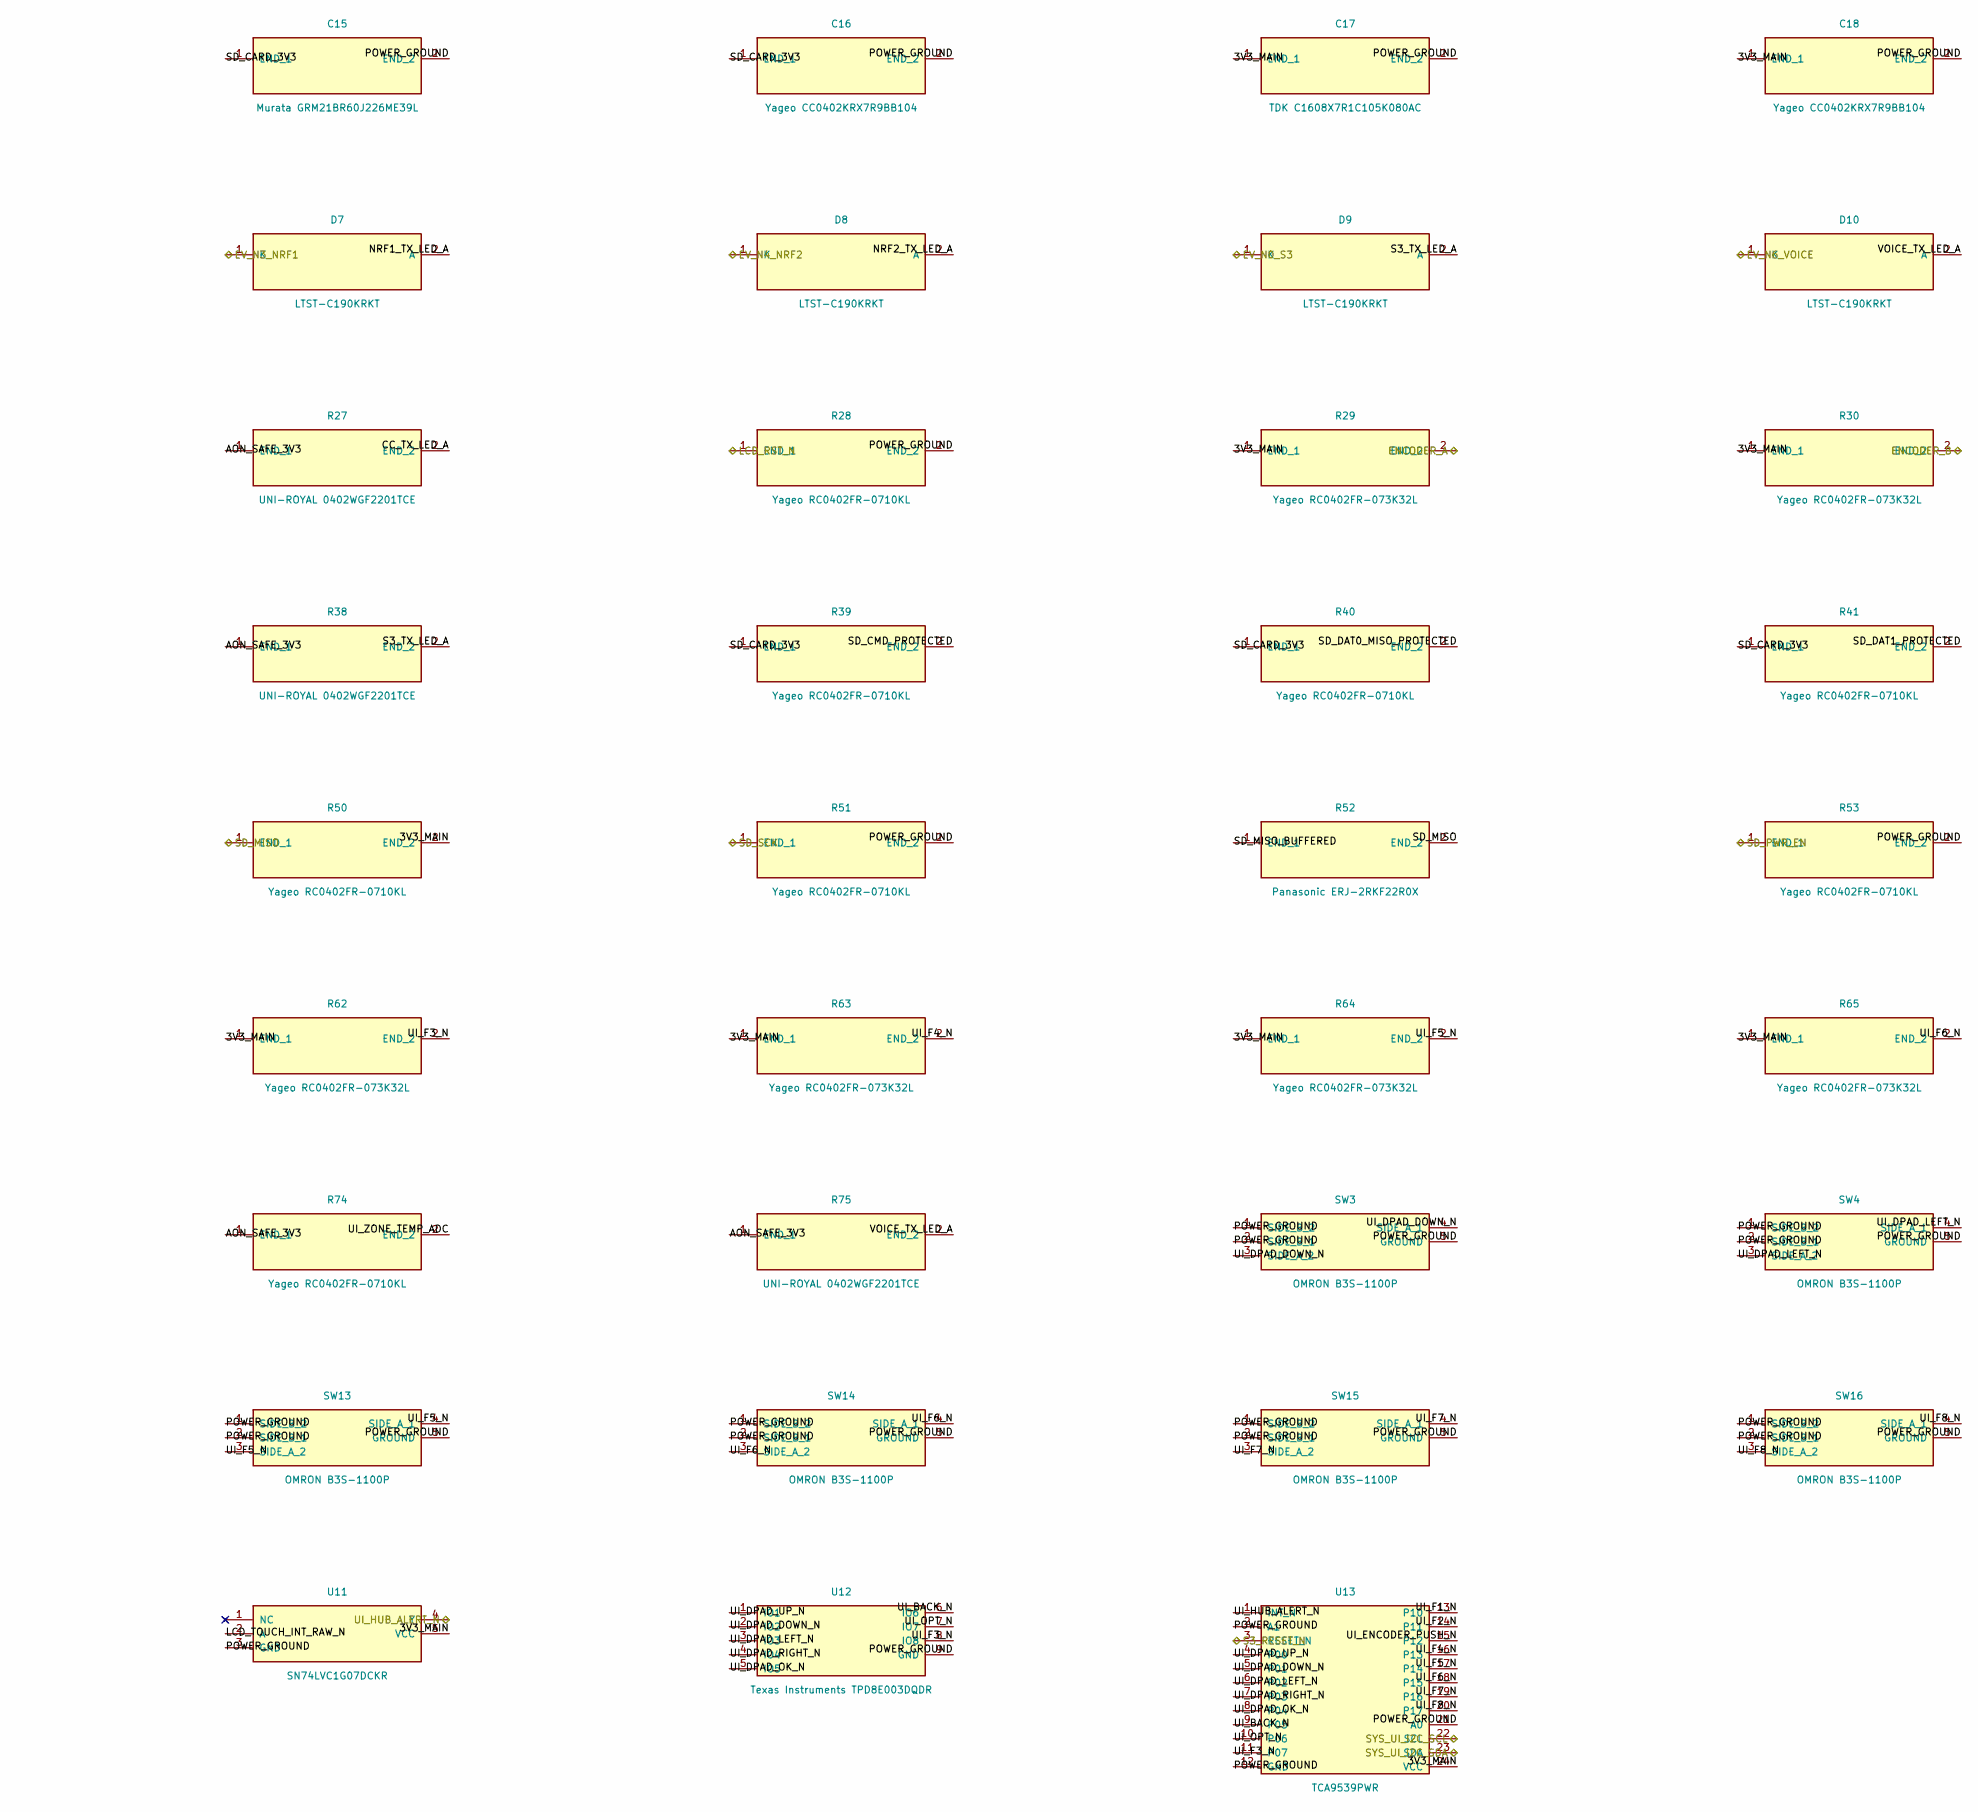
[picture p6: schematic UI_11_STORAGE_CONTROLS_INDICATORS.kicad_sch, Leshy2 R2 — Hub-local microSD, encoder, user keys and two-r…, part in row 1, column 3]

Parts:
C7, C9, C11, C12, C13, C14, C16, C18, C19, C20: Yageo CC0402KRX7R9BB104; C_0402_1005Metric
C8, C10: Murata GRM188R60J106ME47D; C_0603_1608Metric
C15: Murata GRM21BR60J226ME39L; C_0805_2012Metric
C17: TDK C1608X7R1C105K080AC; C_0603_1608Metric
D1, D2, D3, D5, D6, D7, D8, D9, D10: LTST-C190KRKT; LED_0603_1608Metric
D4: LTST-C190KFKT; LED_0603_1608Metric
J5: Hirose DM3AT-SF-PEJM5; microSD_HC_Hirose_DM3AT-SF-PEJM5
Q1: Diodes Incorporated DMN2056U-7; SOT-23
R21: UNI-ROYAL 0402WGF1333TCE; R_0402_1005Metric
R22, R23, R28, R34, R39, R40, R41, R42, R43, R46, R48, R49, R50, R51, R53, R55, R56, R58, R68, R69, R71, R72, R74: Yageo RC0402FR-0710KL; R_0402_1005Metric
R24: Yageo RC0402FR-07100RL; R_0402_1005Metric
R25: FH RS-06L2R70FT; R_1206_3216Metric
R26, R27, R31, R32, R33, R35, R36, R37, R38, R75: UNI-ROYAL 0402WGF2201TCE; R_0402_1005Metric
R29, R30, R57, R59, R60, R61, R62, R63, R64, R65, R66, R67, R70: Yageo RC0402FR-073K32L; R_0402_1005Metric
R44, R45, R52, R54: Panasonic ERJ-2RKF22R0X; R_0402_1005Metric
R47: Yageo RC0603FR-071KL; R_0603_1608Metric
R73: TDK B57332V5103F360; R_0603_1608Metric
SW3, SW4, SW5, SW6, SW7, SW8, SW9, SW10, SW11, SW12, SW13, SW14, SW15, SW16, SW17: OMRON B3S-1100P; B3S-1100P
U4: Texas Instruments TPS2553DRVR-1; WSON-6-1EP_2x2mm_P0.65mm_EP1x1.6mm
U5, U12: Texas Instruments TPD8E003DQDR; TPD8E003DQDR
U6, U7: Texas Instruments TPD4E05U06DQAR; USON-10_2.5x1.0mm_P0.5mm
U8: SN74LVC3G34DCUR; VSSOP-8_2.3x2mm_P0.5mm
U9: Texas Instruments SN74LVC1G125DCKR; Texas_R-PDSO-G5_DCK-5
U10: Texas Instruments TPS22919DCKR; SOT-363_SC-70-6
U11: SN74LVC1G07DCKR; Texas_R-PDSO-G5_DCK-5
U13: TCA9539PWR; TSSOP-24_4.4x7.8mm_P0.65mm

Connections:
/UI_10_S3_DISPLAY_TOUCH/3V3_MAIN: C7.1 (END_1), C10.1 (END_1), C11.1 (END_1), C17.1 (END_1), C18.1 (END_1), C19.1 (END_1), R22.1 (END_1), R29.1 (END_1), R30.1 (END_1), R34.2 (END_2), R46.1 (END_1), R48.2 (END_2), R50.2 (END_2), R55.1 (END_1), R57.1 (END_1), R58.1 (END_1), R59.1 (END_1), R60.1 (END_1), R61.1 (END_1), R62.1 (END_1), R63.1 (END_1), R64.1 (END_1), R65.1 (END_1), R66.1 (END_1), R67.1 (END_1), R68.1 (END_1), R69.1 (END_1), R70.1 (END_1), R71.1 (END_1), R72.1 (END_1), U4.6 (IN), U10.1 (IN), U11.5 (VCC), U13.24 (VCC); also elsewhere on the board
/UI_10_S3_DISPLAY_TOUCH/AON_SAFE_3V3: R26.1 (END_1), R27.1 (END_1), R31.1 (END_1), R33.1 (END_1), R35.1 (END_1), R36.1 (END_1), R37.1 (END_1), R38.1 (END_1), R74.1 (END_1), R75.1 (END_1); also elsewhere on the board
/UI_10_S3_DISPLAY_TOUCH/ENCODER_A: R29.2 (END_2); also elsewhere on the board
/UI_10_S3_DISPLAY_TOUCH/ENCODER_B: R30.2 (END_2); also elsewhere on the board
/UI_10_S3_DISPLAY_TOUCH/LCD_LEDK: R25.1 (END_1); also elsewhere on the board
/UI_10_S3_DISPLAY_TOUCH/LCD_RST_N: R28.1 (END_1); also elsewhere on the board
/UI_10_S3_DISPLAY_TOUCH/POWER_GROUND: C7.2 (END_2), C8.2 (END_2), C9.2 (END_2), C10.2 (END_2), C11.2 (END_2), C12.2 (END_2), C13.2 (END_2), C14.2 (END_2), C15.2 (END_2), C16.2 (END_2), C17.2 (END_2), C18.2 (END_2), C19.2 (END_2), C20.2 (END_2), D4.1 (K), J5.6 (VSS), J5.9 (DETECT_B), J5.SH (SHIELD), Q1.2 (S), R21.2 (END_2), R23.2 (END_2), R28.2 (END_2), R49.2 (END_2), R51.2 (END_2), R53.2 (END_2), R56.2 (END_2), R73.2 (END_2), SW3.1 (SIDE_B_2), SW3.2 (SIDE_B_1), SW3.5 (GROUND), SW4.1 (SIDE_B_2), SW4.2 (SIDE_B_1), SW4.5 (GROUND), SW5.1 (SIDE_B_2), SW5.2 (SIDE_B_1), SW5.5 (GROUND), SW6.1 (SIDE_B_2), SW6.2 (SIDE_B_1), SW6.5 (GROUND), SW7.1 (SIDE_B_2), SW7.2 (SIDE_B_1), SW7.5 (GROUND), SW8.1 (SIDE_B_2), SW8.2 (SIDE_B_1), SW8.5 (GROUND), SW9.1 (SIDE_B_2), SW9.2 (SIDE_B_1), SW9.5 (GROUND), SW10.1 (SIDE_B_2), SW10.2 (SIDE_B_1), SW10.5 (GROUND), SW11.1 (SIDE_B_2), SW11.2 (SIDE_B_1), SW11.5 (GROUND), SW12.1 (SIDE_B_2), SW12.2 (SIDE_B_1), SW12.5 (GROUND), SW13.1 (SIDE_B_2), SW13.2 (SIDE_B_1), SW13.5 (GROUND), SW14.1 (SIDE_B_2), SW14.2 (SIDE_B_1), SW14.5 (GROUND), SW15.1 (SIDE_B_2), SW15.2 (SIDE_B_1), SW15.5 (GROUND), SW16.1 (SIDE_B_2), SW16.2 (SIDE_B_1), SW16.5 (GROUND), SW17.1 (SIDE_B_2), SW17.2 (SIDE_B_1), SW17.5 (GROUND), U4.5 (GND), U4.7 (POWERPAD), U5.9 (GND), U6.3 (GND_3), U6.8 (GND_8), U7.3 (GND_3), U7.8 (GND_8), U8.4 (GND), U9.3 (GND), U10.2 (GND), U11.3 (GND), U12.9 (GND), U13.2 (A1), U13.12 (GND), U13.21 (A0); also elsewhere on the board
/UI_10_S3_DISPLAY_TOUCH/S3_RESET_N: U13.3 (RESET_N); also elsewhere on the board
/UI_10_S3_DISPLAY_TOUCH/SYS_UI_I2C_SCL: U13.22 (SCL); also elsewhere on the board
/UI_10_S3_DISPLAY_TOUCH/SYS_UI_I2C_SDA: U13.23 (SDA); also elsewhere on the board
/UI_10_S3_DISPLAY_TOUCH/TOUCH_RST_N: R56.1 (END_1); also elsewhere on the board
/UI_10_S3_DISPLAY_TOUCH/UI_HUB_ALERT_N: U11.4 (Y), U13.1 (INT_N); also elsewhere on the board
/UI_11_STORAGE_CONTROLS_INDICATORS/C5_TX_LED_A: D1.2 (A), R26.2 (END_2)
/UI_11_STORAGE_CONTROLS_INDICATORS/CC_TX_LED_A: D2.2 (A), R27.2 (END_2)
/UI_11_STORAGE_CONTROLS_INDICATORS/EV_N5_CC: D2.1 (K); also elsewhere on the board
/UI_11_STORAGE_CONTROLS_INDICATORS/EV_N6_VOICE: D10.1 (K); also elsewhere on the board
/UI_11_STORAGE_CONTROLS_INDICATORS/EV_N8_LORA_EXT: D3.1 (K); also elsewhere on the board
/UI_11_STORAGE_CONTROLS_INDICATORS/EXT_TX_LED_A: D3.2 (A), R31.2 (END_2)
/UI_11_STORAGE_CONTROLS_INDICATORS/FAULT_KILL: R32.1 (END_1); also elsewhere on the board
/UI_11_STORAGE_CONTROLS_INDICATORS/FAULT_LED_A: D4.2 (A), R32.2 (END_2)
/UI_11_STORAGE_CONTROLS_INDICATORS/IR_TX_LED_A: D5.2 (A), R33.2 (END_2)
/UI_11_STORAGE_CONTROLS_INDICATORS/LCD_BACKLIGHT_EFUSE_EN: R34.1 (END_1), U4.4 (EN)
/UI_11_STORAGE_CONTROLS_INDICATORS/LCD_BACKLIGHT_FAULT_N: R22.2 (END_2), U4.3 (FAULT_N)
/UI_11_STORAGE_CONTROLS_INDICATORS/LCD_BACKLIGHT_GATE: Q1.1 (G), R23.1 (END_1), R24.2 (END_2)
/UI_11_STORAGE_CONTROLS_INDICATORS/LCD_BACKLIGHT_ILIM: R21.1 (END_1), U4.2 (ILIM)
/UI_11_STORAGE_CONTROLS_INDICATORS/LCD_BL_PWM: R24.1 (END_1); also elsewhere on the board
/UI_11_STORAGE_CONTROLS_INDICATORS/LCD_LEDA_PROTECTED: C8.1 (END_1), C9.1 (END_1), U4.1 (OUT); also elsewhere on the board
/UI_11_STORAGE_CONTROLS_INDICATORS/LCD_LEDK_LIMITED: Q1.3 (D), R25.2 (END_2)
/UI_11_STORAGE_CONTROLS_INDICATORS/LCD_TOUCH_INT_RAW_N: R55.2 (END_2), U11.2 (A); also elsewhere on the board
/UI_11_STORAGE_CONTROLS_INDICATORS/NRF0_TX_LED_A: D6.2 (A), R35.2 (END_2)
/UI_11_STORAGE_CONTROLS_INDICATORS/NRF1_TX_LED_A: D7.2 (A), R36.2 (END_2)
/UI_11_STORAGE_CONTROLS_INDICATORS/NRF2_TX_LED_A: D8.2 (A), R37.2 (END_2)
/UI_11_STORAGE_CONTROLS_INDICATORS/S3_TX_LED_A: D9.2 (A), R38.2 (END_2)
/UI_11_STORAGE_CONTROLS_INDICATORS/SD_CARD_3V3: C13.1 (END_1), C14.1 (END_1), C15.1 (END_1), C16.1 (END_1), J5.4 (VDD), R39.1 (END_1), R40.1 (END_1), R41.1 (END_1), R42.1 (END_1), R43.1 (END_1), U7.4 (D2_PLUS), U8.8 (VCC), U9.5 (VCC), U10.5 (QOD), U10.6 (VOUT)
/UI_11_STORAGE_CONTROLS_INDICATORS/SD_CARD_DETECT_RAW_N: J5.10 (DETECT_A), R47.1 (END_1), U7.5 (D2_MINUS)
/UI_11_STORAGE_CONTROLS_INDICATORS/SD_CLK_BUFFERED: R54.1 (END_1), U8.7 (1Y)
/UI_11_STORAGE_CONTROLS_INDICATORS/SD_CLK_PROTECTED: J5.5 (CLK), R54.2 (END_2), U6.1 (D1_PLUS)
/UI_11_STORAGE_CONTROLS_INDICATORS/SD_CMD_BUFFERED: R44.1 (END_1), U8.5 (2Y)
/UI_11_STORAGE_CONTROLS_INDICATORS/SD_CMD_PROTECTED: J5.3 (CMD), R39.2 (END_2), R44.2 (END_2), U6.2 (D1_MINUS)
/UI_11_STORAGE_CONTROLS_INDICATORS/SD_CS_BUFFERED_N: R45.1 (END_1), U8.2 (3Y)
/UI_11_STORAGE_CONTROLS_INDICATORS/SD_CS_N: R48.1 (END_1), U8.6 (3A), U9.1 (OE_N); also elsewhere on the board
/UI_11_STORAGE_CONTROLS_INDICATORS/SD_DAT0_MISO_PROTECTED: J5.7 (DAT0), R40.2 (END_2), U6.5 (D2_MINUS), U9.2 (A)
/UI_11_STORAGE_CONTROLS_INDICATORS/SD_DAT1_PROTECTED: J5.8 (DAT1), R41.2 (END_2), U7.1 (D1_PLUS)
/UI_11_STORAGE_CONTROLS_INDICATORS/SD_DAT2_PROTECTED: J5.1 (DAT2), R42.2 (END_2), U7.2 (D1_MINUS)
/UI_11_STORAGE_CONTROLS_INDICATORS/SD_DAT3_CS_PROTECTED_N: J5.2 (CD_DAT3), R43.2 (END_2), R45.2 (END_2), U6.4 (D2_PLUS)
/UI_11_STORAGE_CONTROLS_INDICATORS/SD_DETECT_N: C12.1 (END_1), R46.2 (END_2), R47.2 (END_2); also elsewhere on the board
/UI_11_STORAGE_CONTROLS_INDICATORS/SD_MISO: R50.1 (END_1), R52.2 (END_2); also elsewhere on the board
/UI_11_STORAGE_CONTROLS_INDICATORS/SD_MISO_BUFFERED: R52.1 (END_1), U9.4 (Y)
/UI_11_STORAGE_CONTROLS_INDICATORS/SD_MOSI: R49.1 (END_1), U8.3 (2A); also elsewhere on the board
/UI_11_STORAGE_CONTROLS_INDICATORS/SD_PWR_EN: R53.1 (END_1), U10.3 (ON); also elsewhere on the board
/UI_11_STORAGE_CONTROLS_INDICATORS/SD_SCK: R51.1 (END_1), U8.1 (1A); also elsewhere on the board
/UI_11_STORAGE_CONTROLS_INDICATORS/UI_BACK_N: R57.2 (END_2), SW8.3 (SIDE_A_2), SW8.4 (SIDE_A_1), U12.6 (IO6), U13.9 (P05)
/UI_11_STORAGE_CONTROLS_INDICATORS/UI_DPAD_DOWN_N: R58.2 (END_2), SW3.3 (SIDE_A_2), SW3.4 (SIDE_A_1), U12.2 (IO2), U13.5 (P01)
/UI_11_STORAGE_CONTROLS_INDICATORS/UI_DPAD_LEFT_N: R68.2 (END_2), SW4.3 (SIDE_A_2), SW4.4 (SIDE_A_1), U12.3 (IO3), U13.6 (P02)
/UI_11_STORAGE_CONTROLS_INDICATORS/UI_DPAD_OK_N: R69.2 (END_2), SW5.3 (SIDE_A_2), SW5.4 (SIDE_A_1), U12.5 (IO5), U13.8 (P04)
/UI_11_STORAGE_CONTROLS_INDICATORS/UI_DPAD_RIGHT_N: R71.2 (END_2), SW6.3 (SIDE_A_2), SW6.4 (SIDE_A_1), U12.4 (IO4), U13.7 (P03)
/UI_11_STORAGE_CONTROLS_INDICATORS/UI_DPAD_UP_N: R72.2 (END_2), SW7.3 (SIDE_A_2), SW7.4 (SIDE_A_1), U12.1 (IO1), U13.4 (P00)
/UI_11_STORAGE_CONTROLS_INDICATORS/UI_ENCODER_PUSH_N: R59.2 (END_2), U13.15 (P12); also elsewhere on the board
/UI_11_STORAGE_CONTROLS_INDICATORS/UI_F1_N: R60.2 (END_2), SW9.3 (SIDE_A_2), SW9.4 (SIDE_A_1), U5.1 (IO1), U13.13 (P10)
/UI_11_STORAGE_CONTROLS_INDICATORS/UI_F2_N: R61.2 (END_2), SW10.3 (SIDE_A_2), SW10.4 (SIDE_A_1), U5.2 (IO2), U13.14 (P11)
/UI_11_STORAGE_CONTROLS_INDICATORS/UI_F3_N: R62.2 (END_2), SW11.3 (SIDE_A_2), SW11.4 (SIDE_A_1), U12.8 (IO8), U13.11 (P07)
/UI_11_STORAGE_CONTROLS_INDICATORS/UI_F4_N: R63.2 (END_2), SW12.3 (SIDE_A_2), SW12.4 (SIDE_A_1), U5.3 (IO3), U13.16 (P13)
/UI_11_STORAGE_CONTROLS_INDICATORS/UI_F5_N: R64.2 (END_2), SW13.3 (SIDE_A_2), SW13.4 (SIDE_A_1), U5.4 (IO4), U13.17 (P14)
/UI_11_STORAGE_CONTROLS_INDICATORS/UI_F6_N: R65.2 (END_2), SW14.3 (SIDE_A_2), SW14.4 (SIDE_A_1), U5.5 (IO5), U13.18 (P15)
/UI_11_STORAGE_CONTROLS_INDICATORS/UI_F7_N: R66.2 (END_2), SW15.3 (SIDE_A_2), SW15.4 (SIDE_A_1), U5.6 (IO6), U13.19 (P16)
/UI_11_STORAGE_CONTROLS_INDICATORS/UI_F8_N: R67.2 (END_2), SW16.3 (SIDE_A_2), SW16.4 (SIDE_A_1), U5.7 (IO7), U13.20 (P17)
/UI_11_STORAGE_CONTROLS_INDICATORS/UI_OPT_N: R70.2 (END_2), SW17.3 (SIDE_A_2), SW17.4 (SIDE_A_1), U12.7 (IO7), U13.10 (P06)
/UI_11_STORAGE_CONTROLS_INDICATORS/UI_ZONE_TEMP_ADC: C20.1 (END_1), R73.1 (END_1), R74.2 (END_2); also elsewhere on the board
/UI_11_STORAGE_CONTROLS_INDICATORS/VOICE_TX_LED_A: D10.2 (A), R75.2 (END_2)
/UI_20_C5_WIFI_IR_SERVICE/EV_N1_C5: D1.1 (K); also elsewhere on the board
/UI_20_C5_WIFI_IR_SERVICE/EV_N7_IR: D5.1 (K); also elsewhere on the board
/UI_50_FRONT_POWER_SAFETY/EV_N0_S3: D9.1 (K); also elsewhere on the board
/UI_50_FRONT_POWER_SAFETY/EV_N2_NRF0: D6.1 (K); also elsewhere on the board
/UI_50_FRONT_POWER_SAFETY/EV_N3_NRF1: D7.1 (K); also elsewhere on the board
/UI_50_FRONT_POWER_SAFETY/EV_N4_NRF2: D8.1 (K); also elsewhere on the board

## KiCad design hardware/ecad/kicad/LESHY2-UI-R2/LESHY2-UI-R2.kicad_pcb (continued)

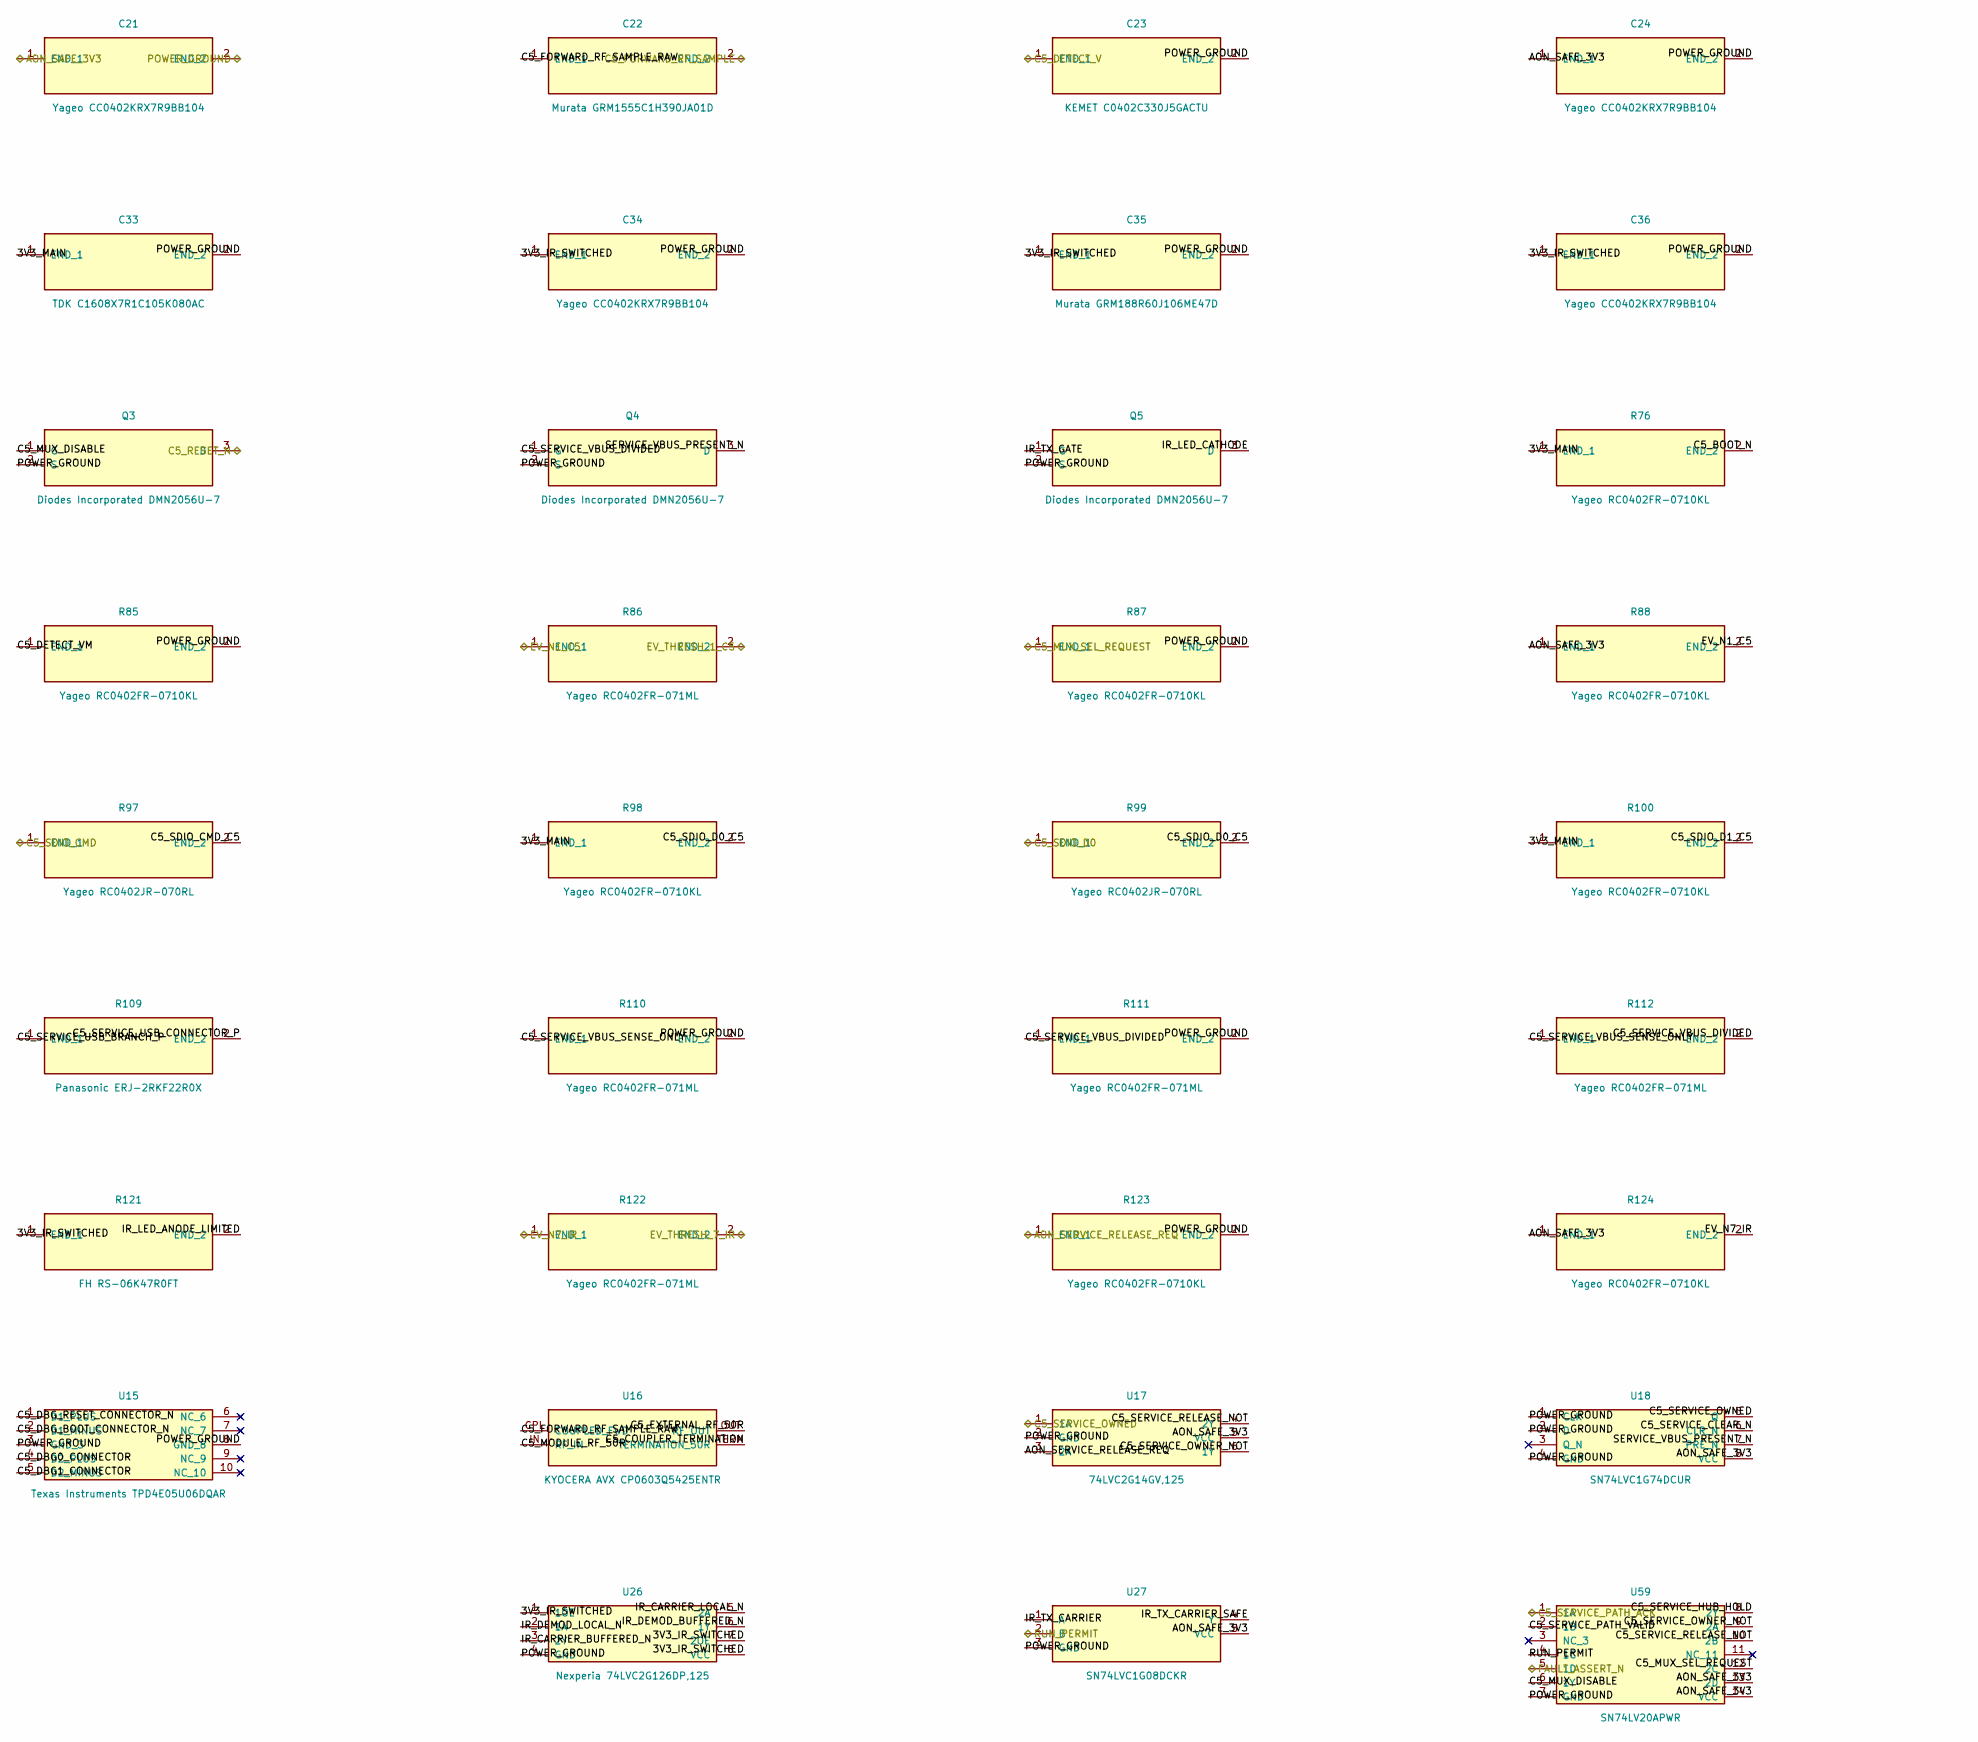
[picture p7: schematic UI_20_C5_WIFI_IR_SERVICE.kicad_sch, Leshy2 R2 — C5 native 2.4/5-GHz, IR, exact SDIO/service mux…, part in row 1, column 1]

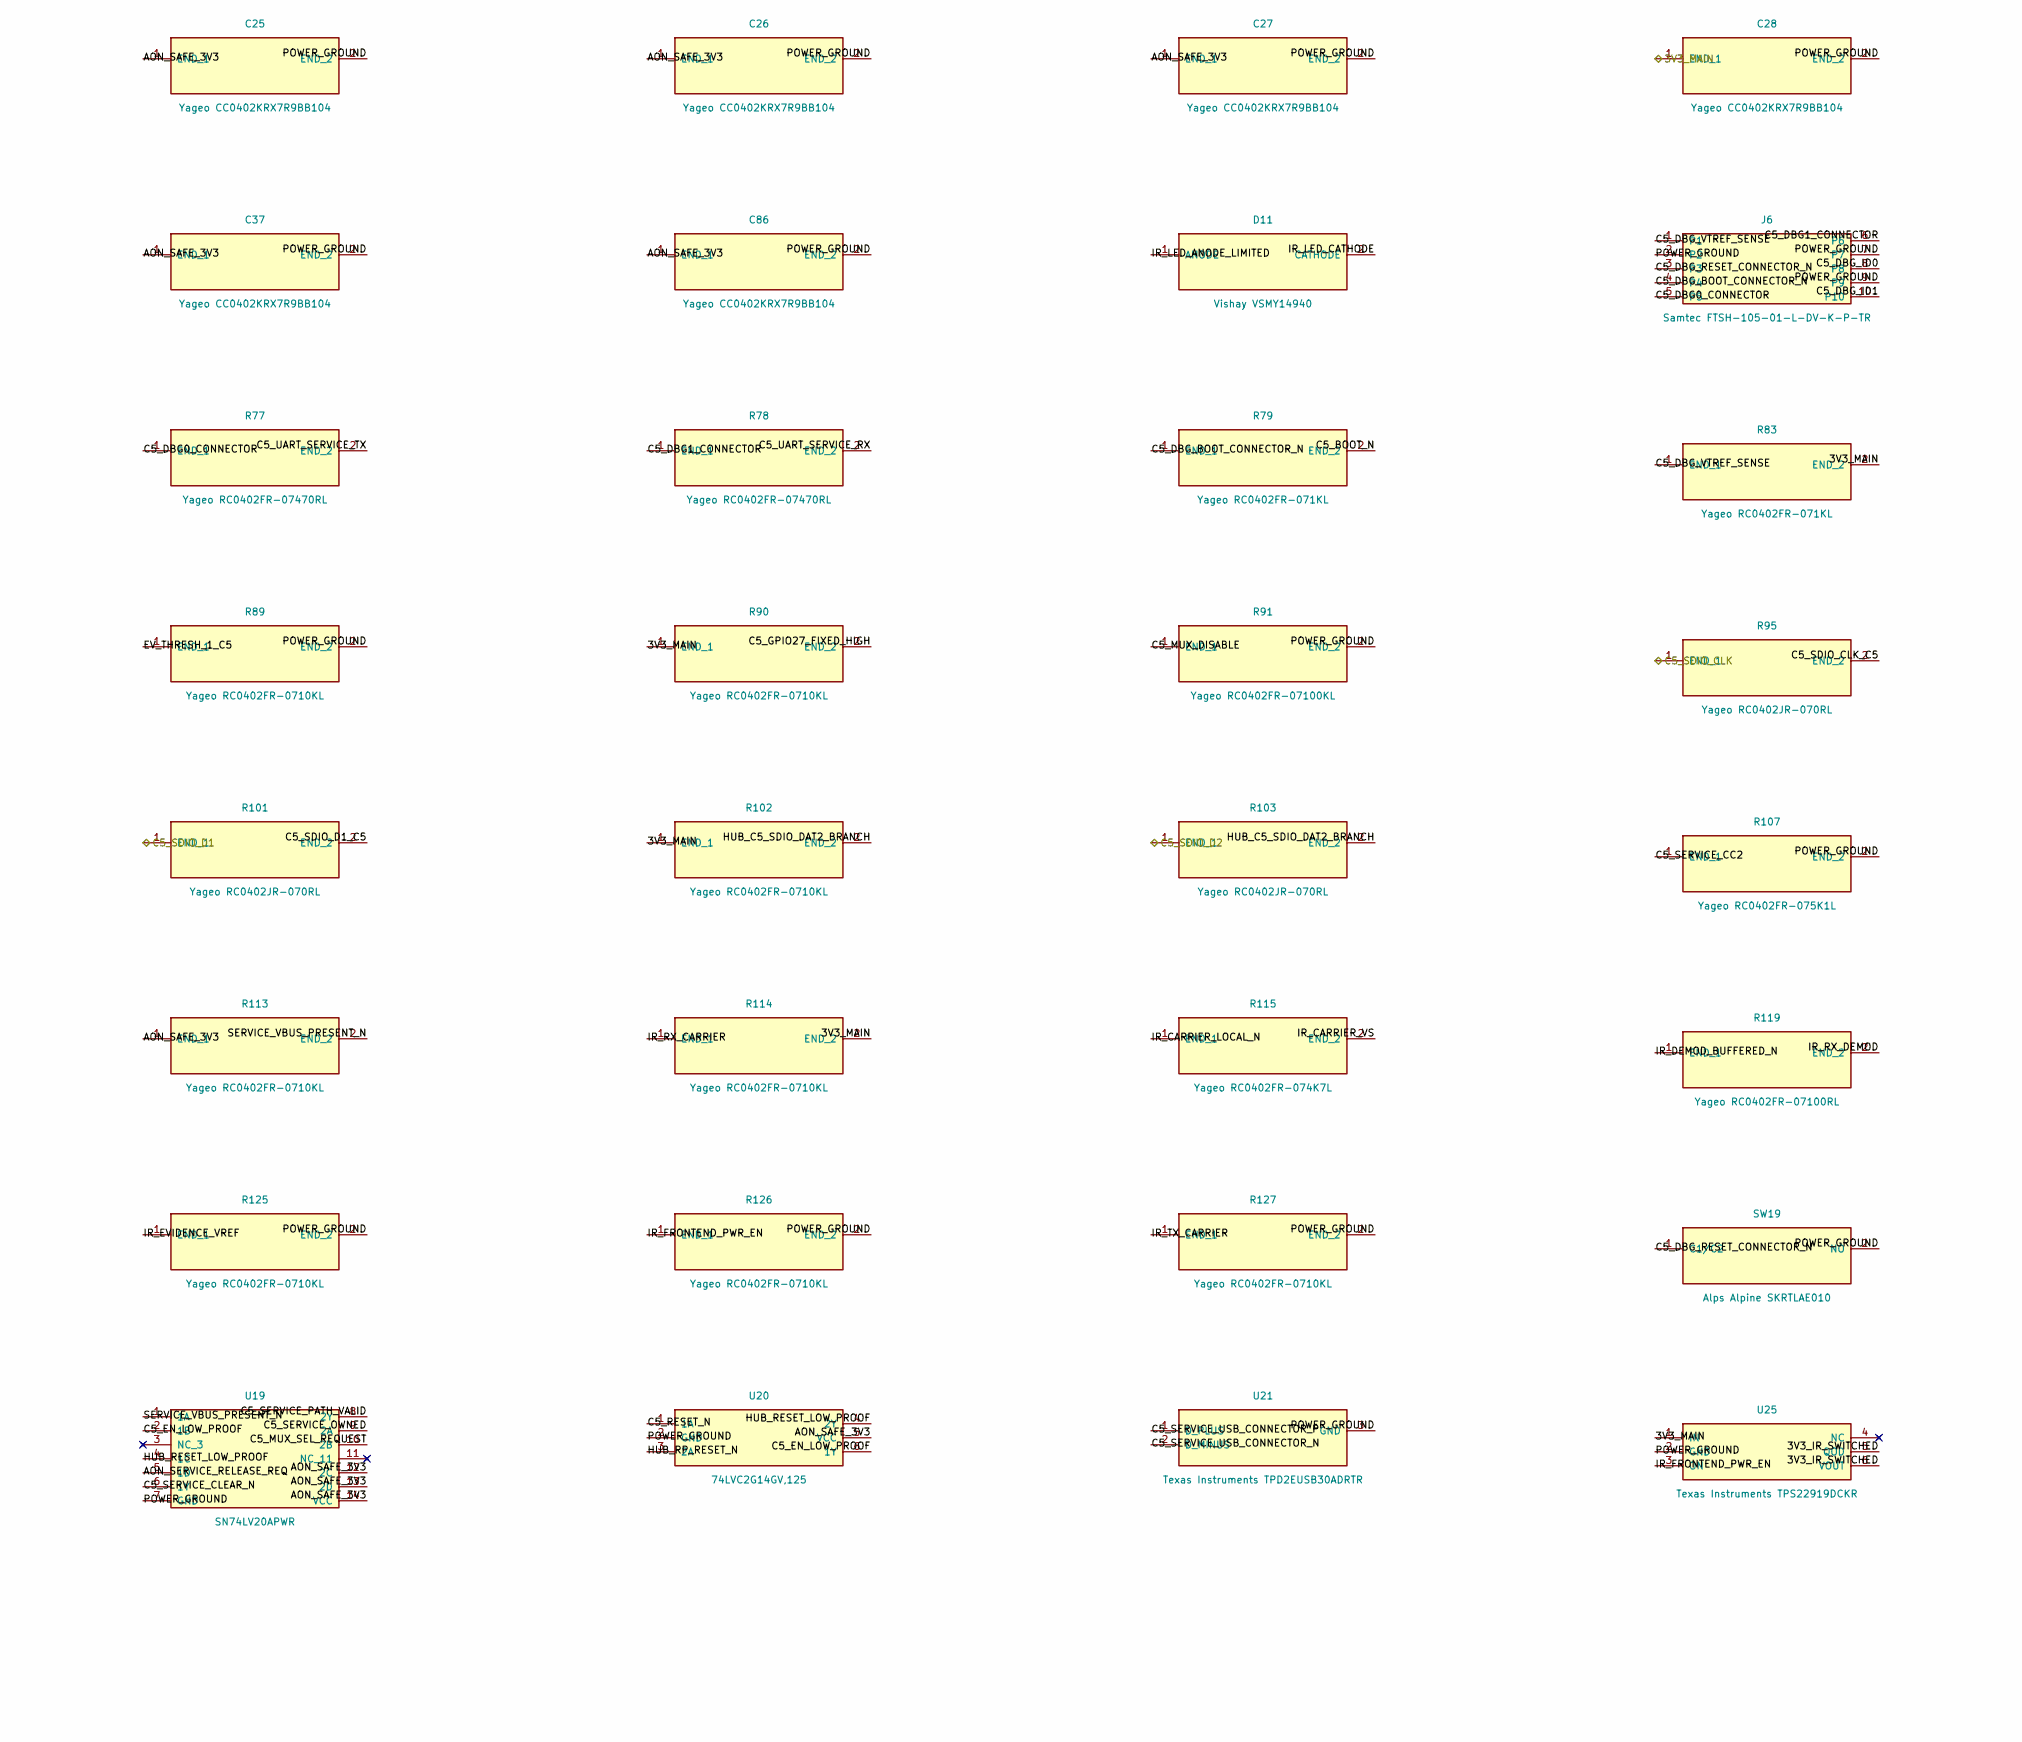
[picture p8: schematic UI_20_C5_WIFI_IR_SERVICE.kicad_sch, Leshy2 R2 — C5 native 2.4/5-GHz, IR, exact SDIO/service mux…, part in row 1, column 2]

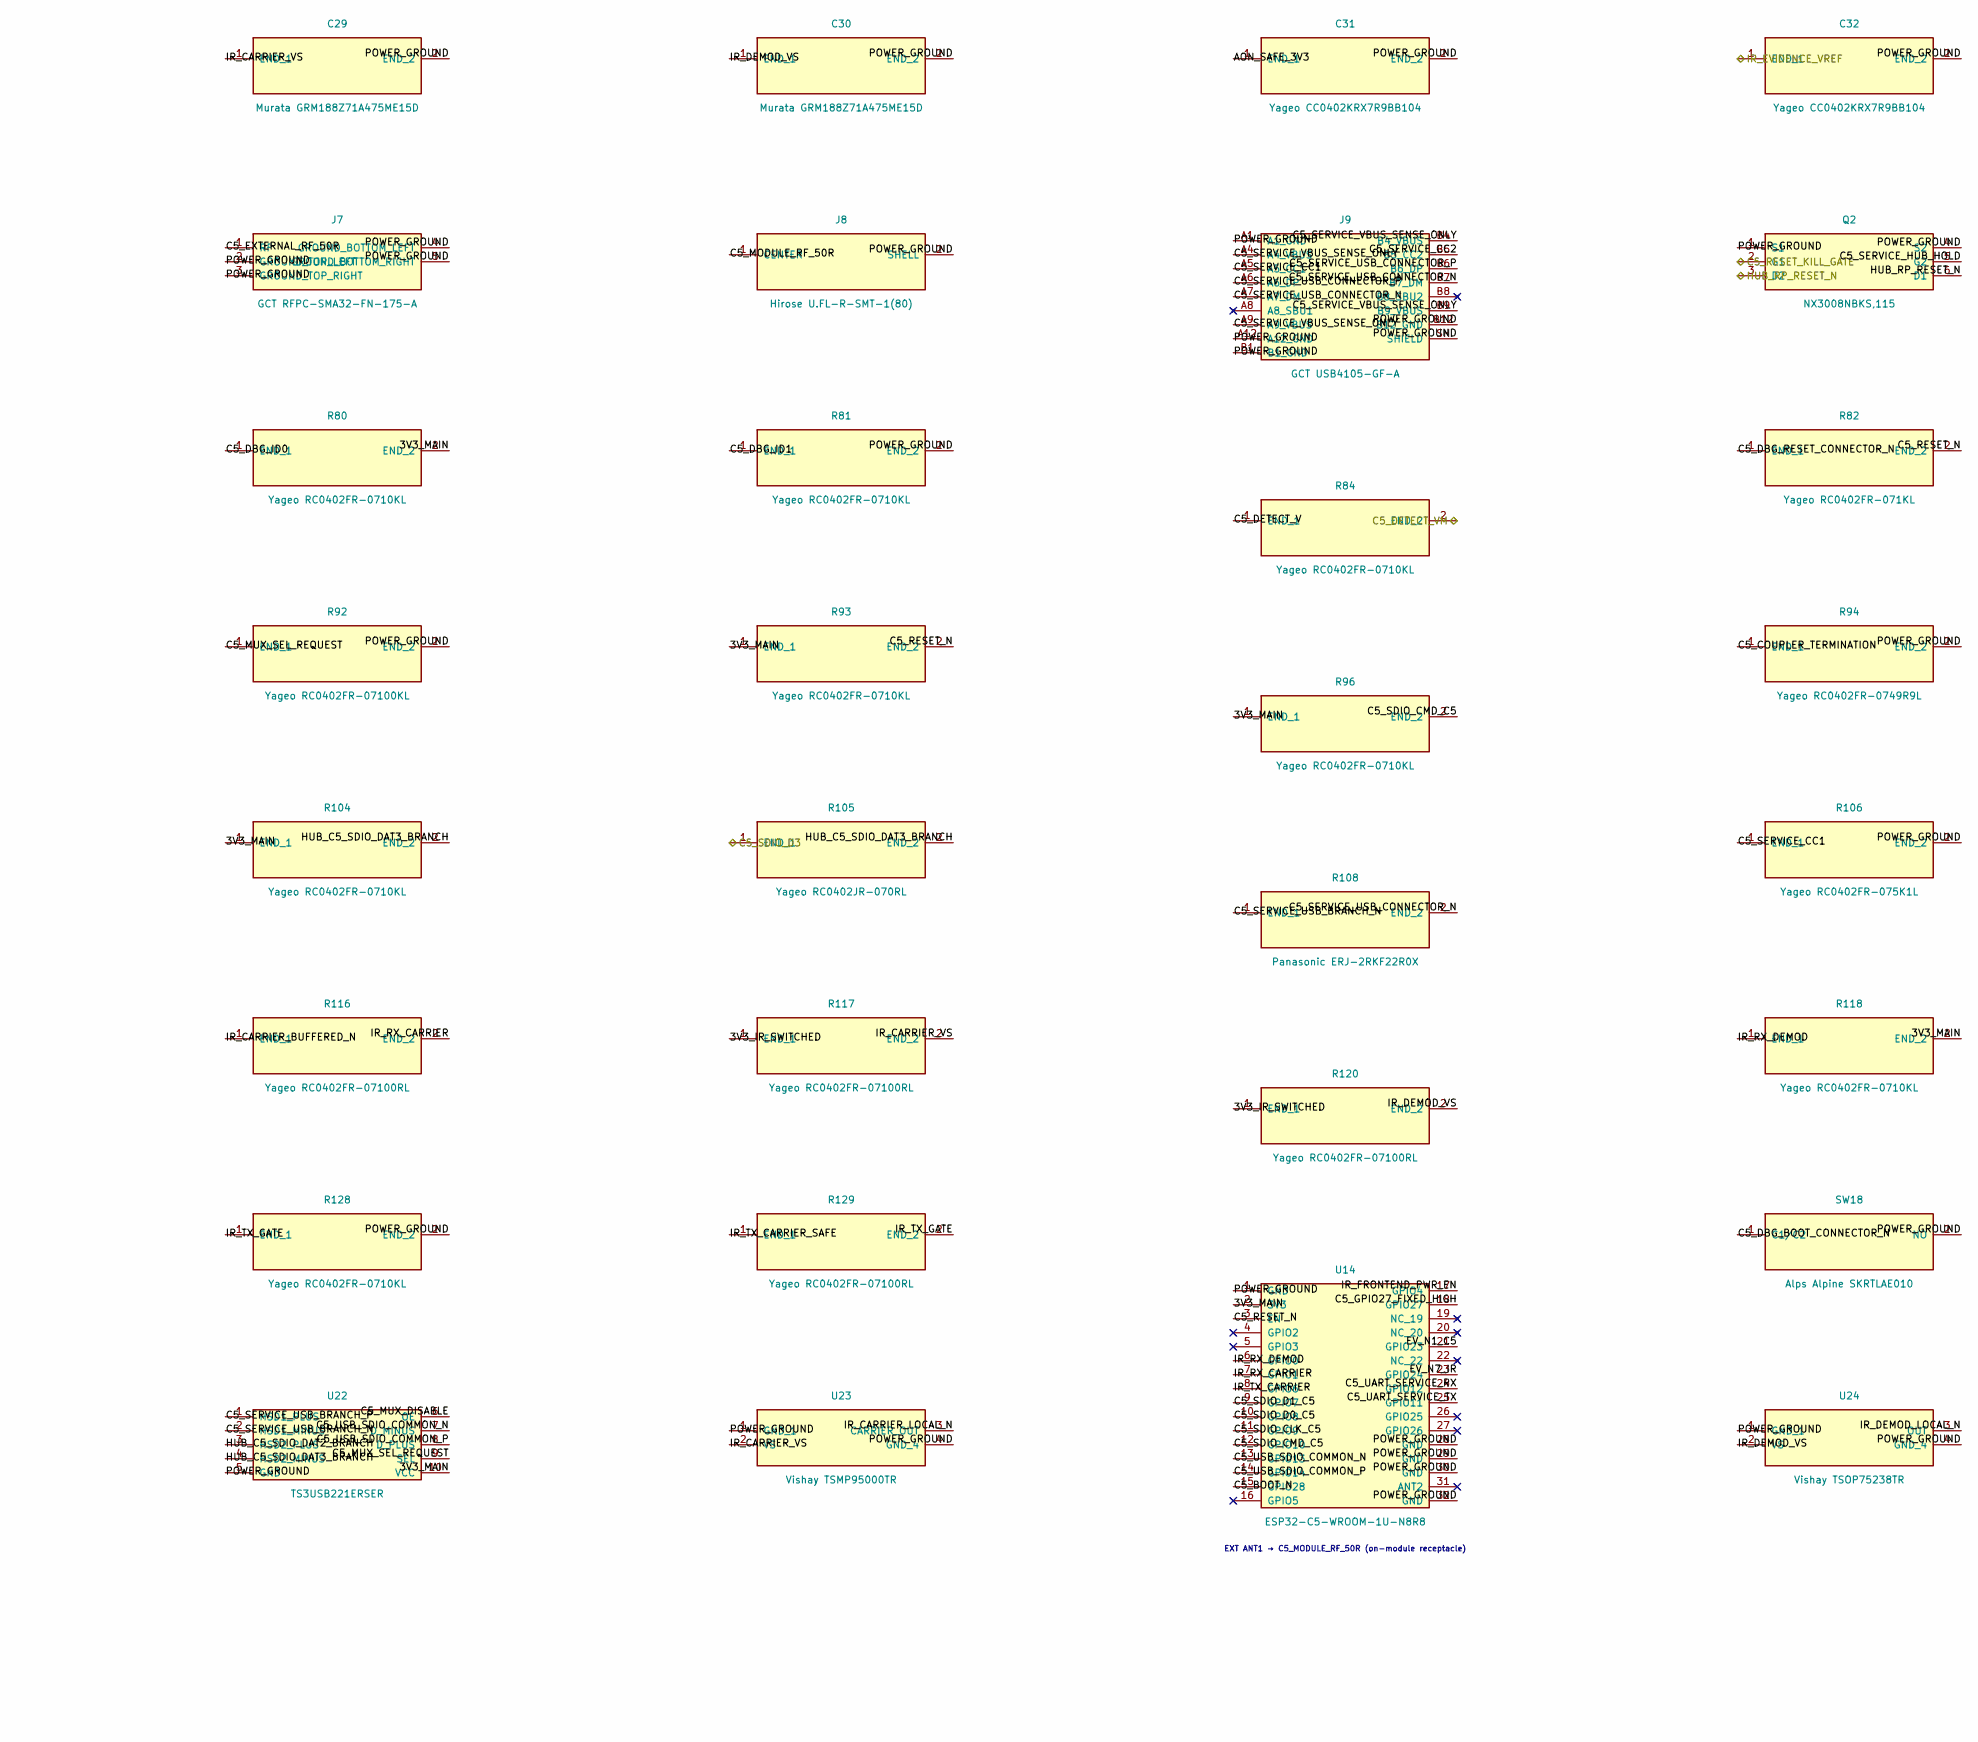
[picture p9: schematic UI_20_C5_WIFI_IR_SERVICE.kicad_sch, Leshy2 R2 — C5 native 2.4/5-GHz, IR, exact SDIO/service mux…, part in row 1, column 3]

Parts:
C21, C24, C25, C26, C27, C28, C31, C32, C34, C36, C37, C86: Yageo CC0402KRX7R9BB104; C_0402_1005Metric
C22: Murata GRM1555C1H390JA01D; C_0402_1005Metric
C23: KEMET C0402C330J5GACTU; C_0402_1005Metric
C29, C30: Murata GRM188Z71A475ME15D; C_0603_1608Metric
C33: TDK C1608X7R1C105K080AC; C_0603_1608Metric
C35: Murata GRM188R60J106ME47D; C_0603_1608Metric
D11: Vishay VSMY14940; VSMY14940
J6: Samtec FTSH-105-01-L-DV-K-P-TR; FTSH-105-01-L-DV-K-P-TR
J7: GCT RFPC-SMA32-FN-175-A; RFPC-SMA32-FN-175-A
J8: Hirose U.FL-R-SMT-1(80); U.FL_Hirose_U.FL-R-SMT-1_Vertical
J9: GCT USB4105-GF-A; USB_C_Receptacle_GCT_USB4105-xx-A_16P_TopMnt_Horizontal
Q2: NX3008NBKS,115; SOT-363_SC-70-6
Q3, Q4, Q5: Diodes Incorporated DMN2056U-7; SOT-23
R76, R80, R81, R84, R85, R87, R88, R89, R90, R93, R96, R98, R100, R102, R104, R113, R114, R118, R123, R124, R125, R126, R127, R128: Yageo RC0402FR-0710KL; R_0402_1005Metric
R77, R78: Yageo RC0402FR-07470RL; R_0402_1005Metric
R79, R82, R83: Yageo RC0402FR-071KL; R_0402_1005Metric
R86, R110, R111, R112, R122: Yageo RC0402FR-071ML; R_0402_1005Metric
R91, R92: Yageo RC0402FR-07100KL; R_0402_1005Metric
R94: Yageo RC0402FR-0749R9L; R_0402_1005Metric
R95, R97, R99, R101, R103, R105: Yageo RC0402JR-070RL; R_0402_1005Metric
R106, R107: Yageo RC0402FR-075K1L; R_0402_1005Metric
R108, R109: Panasonic ERJ-2RKF22R0X; R_0402_1005Metric
R115: Yageo RC0402FR-074K7L; R_0402_1005Metric
R116, R117, R119, R120, R129: Yageo RC0402FR-07100RL; R_0402_1005Metric
R121: FH RS-06K47R0FT; R_1206_3216Metric
SW18, SW19: Alps Alpine SKRTLAE010; SW_Push_1P1T-MP_NO_Horizontal_Alps_SKRTLAE010
U14: ESP32-C5-WROOM-1U-N8R8; ESP32-C5-WROOM-1U
U15: Texas Instruments TPD4E05U06DQAR; USON-10_2.5x1.0mm_P0.5mm
U16: KYOCERA AVX CP0603Q5425ENTR; CP0603Q5425ENTR
U17, U20: 74LVC2G14GV,125; SC-74-6_1.55x2.9mm_P0.95mm
U18: SN74LVC1G74DCUR; VSSOP-8_2.3x2mm_P0.5mm
U19, U59: SN74LV20APWR; TSSOP-14_4.4x5mm_P0.65mm
U21: Texas Instruments TPD2EUSB30ADRTR; Texas_DRT-3
U22: TS3USB221ERSER; Texas_UQFN-10_1.5x2mm_P0.5mm
U23: Vishay TSMP95000TR; Vishay-Heimdall-SMD-TR
U24: Vishay TSOP75238TR; Vishay-Heimdall-SMD-TR
U25: Texas Instruments TPS22919DCKR; SOT-363_SC-70-6
U26: Nexperia 74LVC2G126DP,125; TSSOP-8_3x3mm_P0.65mm
U27: SN74LVC1G08DCKR; Texas_R-PDSO-G5_DCK-5

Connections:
/UI_10_S3_DISPLAY_TOUCH/3V3_MAIN: C28.1 (END_1), C33.1 (END_1), R76.1 (END_1), R80.2 (END_2), R83.2 (END_2), R90.1 (END_1), R93.1 (END_1), R96.1 (END_1), R98.1 (END_1), R100.1 (END_1), R102.1 (END_1), R104.1 (END_1), R114.2 (END_2), R118.2 (END_2), U14.2 (3V3), U22.10 (VCC), U25.1 (IN); also elsewhere on the board
/UI_10_S3_DISPLAY_TOUCH/AON_SAFE_3V3: C21.1 (END_1), C24.1 (END_1), C25.1 (END_1), C26.1 (END_1), C27.1 (END_1), C31.1 (END_1), C37.1 (END_1), C86.1 (END_1), R88.1 (END_1), R113.1 (END_1), R124.1 (END_1), U17.5 (VCC), U18.8 (VCC), U19.12 (2C), U19.13 (2D), U19.14 (VCC), U20.5 (VCC), U27.5 (VCC), U59.13 (2D), U59.14 (VCC); also elsewhere on the board
/UI_10_S3_DISPLAY_TOUCH/POWER_GROUND: C21.2 (END_2), C23.2 (END_2), C24.2 (END_2), C25.2 (END_2), C26.2 (END_2), C27.2 (END_2), C28.2 (END_2), C29.2 (END_2), C30.2 (END_2), C31.2 (END_2), C32.2 (END_2), C33.2 (END_2), C34.2 (END_2), C35.2 (END_2), C36.2 (END_2), C37.2 (END_2), C86.2 (END_2), J6.2, J6.7, J6.9, J7.2 (GROUND_TOP_LEFT), J7.3 (GROUND_TOP_RIGHT), J7.4 (GROUND_BOTTOM_LEFT), J7.5 (GROUND_BOTTOM_RIGHT), J8.2 (SHELL), J9.A1 (A1_GND), J9.A12 (A12_GND), J9.B1 (B1_GND), J9.B12 (B12_GND), J9.SH (SHIELD), Q2.1 (S1), Q2.4 (S2), Q3.2 (S), Q4.2 (S), Q5.2 (S), R81.2 (END_2), R85.2 (END_2), R87.2 (END_2), R89.2 (END_2), R91.2 (END_2), R92.2 (END_2), R94.2 (END_2), R106.2 (END_2), R107.2 (END_2), R110.2 (END_2), R111.2 (END_2), R123.2 (END_2), R125.2 (END_2), R126.2 (END_2), R127.2 (END_2), R128.2 (END_2), SW18.2 (NO), SW19.2 (NO), U14.1 (GND), U14.28 (GND), U14.29 (GND), U14.30 (GND), U14.32 (GND), U15.3 (GND_3), U15.8 (GND_8), U17.2 (GND), U18.1 (CLK), U18.2 (D), U18.4 (GND), U19.7 (GND), U20.2 (GND), U21.3 (GND), U22.5 (GND), U23.1 (GND_1), U23.4 (GND_4), U24.1 (GND_1), U24.4 (GND_4), U25.2 (GND), U26.4 (GND), U27.3 (GND), U59.7 (GND); also elsewhere on the board
/UI_20_C5_WIFI_IR_SERVICE/3V3_IR_SWITCHED: C34.1 (END_1), C35.1 (END_1), C36.1 (END_1), R117.1 (END_1), R120.1 (END_1), R121.1 (END_1), U25.5 (QOD), U25.6 (VOUT), U26.1 (1OE), U26.7 (2OE), U26.8 (VCC)
/UI_20_C5_WIFI_IR_SERVICE/AON_SERVICE_RELEASE_REQ: R123.1 (END_1), U17.3 (2A), U19.5 (1D); also elsewhere on the board
/UI_20_C5_WIFI_IR_SERVICE/C5_BOOT_N: R76.2 (END_2), R79.2 (END_2), U14.15 (GPIO28)
/UI_20_C5_WIFI_IR_SERVICE/C5_COUPLER_TERMINATION: R94.1 (END_1), U16.TERM (TERMINATION_50R)
/UI_20_C5_WIFI_IR_SERVICE/C5_DBG0_CONNECTOR: J6.5, R77.1 (END_1), U15.4 (D2_PLUS)
/UI_20_C5_WIFI_IR_SERVICE/C5_DBG1_CONNECTOR: J6.6, R78.1 (END_1), U15.5 (D2_MINUS)
/UI_20_C5_WIFI_IR_SERVICE/C5_DBG_BOOT_CONNECTOR_N: J6.4, R79.1 (END_1), SW18.1 (C1/C2), U15.2 (D1_MINUS)
/UI_20_C5_WIFI_IR_SERVICE/C5_DBG_ID0: J6.8, R80.1 (END_1)
/UI_20_C5_WIFI_IR_SERVICE/C5_DBG_ID1: J6.10, R81.1 (END_1)
/UI_20_C5_WIFI_IR_SERVICE/C5_DBG_RESET_CONNECTOR_N: J6.3, R82.1 (END_1), SW19.1 (C1/C2), U15.1 (D1_PLUS)
/UI_20_C5_WIFI_IR_SERVICE/C5_DBG_VTREF_SENSE: J6.1, R83.1 (END_1)
/UI_20_C5_WIFI_IR_SERVICE/C5_DETECT_V: C23.1 (END_1), R84.1 (END_1); also elsewhere on the board
/UI_20_C5_WIFI_IR_SERVICE/C5_DETECT_VM: R84.2 (END_2), R85.1 (END_1); also elsewhere on the board
/UI_20_C5_WIFI_IR_SERVICE/C5_EN_LOW_PROOF: U19.2 (1B), U20.6 (1Y)
/UI_20_C5_WIFI_IR_SERVICE/C5_EXTERNAL_RF_50R: J7.1 (RF), U16.OUT (RF_OUT)
/UI_20_C5_WIFI_IR_SERVICE/C5_FORWARD_RF_SAMPLE: C22.2 (END_2); also elsewhere on the board
/UI_20_C5_WIFI_IR_SERVICE/C5_FORWARD_RF_SAMPLE_RAW: C22.1 (END_1), U16.CPL (COUPLED_FWD)
/UI_20_C5_WIFI_IR_SERVICE/C5_GPIO27_FIXED_HIGH: R90.2 (END_2), U14.18 (GPIO27)
/UI_20_C5_WIFI_IR_SERVICE/C5_MODULE_RF_50R: J8.1 (CENTER), U16.IN (RF_IN)
/UI_20_C5_WIFI_IR_SERVICE/C5_MUX_DISABLE: Q3.1 (G), R91.1 (END_1), U22.6 (OE), U59.6 (1Y)
/UI_20_C5_WIFI_IR_SERVICE/C5_MUX_SEL_REQUEST: R87.1 (END_1), R92.1 (END_1), U19.10 (2B), U22.9 (SEL), U59.12 (2C); also elsewhere on the board
/UI_20_C5_WIFI_IR_SERVICE/C5_RESET_N: Q3.3 (D), R82.2 (END_2), R93.2 (END_2), U14.3 (EN), U20.1 (1A); also elsewhere on the board
/UI_20_C5_WIFI_IR_SERVICE/C5_SDIO_CLK: R95.1 (END_1); also elsewhere on the board
/UI_20_C5_WIFI_IR_SERVICE/C5_SDIO_CLK_C5: R95.2 (END_2), U14.11 (GPIO9)
/UI_20_C5_WIFI_IR_SERVICE/C5_SDIO_CMD: R97.1 (END_1); also elsewhere on the board
/UI_20_C5_WIFI_IR_SERVICE/C5_SDIO_CMD_C5: R96.2 (END_2), R97.2 (END_2), U14.12 (GPIO10)
/UI_20_C5_WIFI_IR_SERVICE/C5_SDIO_D0: R99.1 (END_1); also elsewhere on the board
/UI_20_C5_WIFI_IR_SERVICE/C5_SDIO_D0_C5: R98.2 (END_2), R99.2 (END_2), U14.10 (GPIO8)
/UI_20_C5_WIFI_IR_SERVICE/C5_SDIO_D1: R101.1 (END_1); also elsewhere on the board
/UI_20_C5_WIFI_IR_SERVICE/C5_SDIO_D1_C5: R100.2 (END_2), R101.2 (END_2), U14.9 (GPIO7)
/UI_20_C5_WIFI_IR_SERVICE/C5_SDIO_D2: R103.1 (END_1); also elsewhere on the board
/UI_20_C5_WIFI_IR_SERVICE/C5_SDIO_D3: R105.1 (END_1); also elsewhere on the board
/UI_20_C5_WIFI_IR_SERVICE/C5_SERVICE_CC1: J9.A5 (A5_CC1), R106.1 (END_1)
/UI_20_C5_WIFI_IR_SERVICE/C5_SERVICE_CC2: J9.B5 (B5_CC2), R107.1 (END_1)
/UI_20_C5_WIFI_IR_SERVICE/C5_SERVICE_CLEAR_N: U18.6 (CLR_N), U19.6 (1Y)
/UI_20_C5_WIFI_IR_SERVICE/C5_SERVICE_HUB_HOLD: Q2.5 (G2), U59.8 (2Y)
/UI_20_C5_WIFI_IR_SERVICE/C5_SERVICE_OWNED: U17.1 (1A), U18.5 (Q), U19.9 (2A); also elsewhere on the board
/UI_20_C5_WIFI_IR_SERVICE/C5_SERVICE_OWNER_NOT: U17.6 (1Y), U59.9 (2A)
/UI_20_C5_WIFI_IR_SERVICE/C5_SERVICE_PATH_ACK: U59.1 (1A); also elsewhere on the board
/UI_20_C5_WIFI_IR_SERVICE/C5_SERVICE_PATH_VALID: U19.8 (2Y), U59.2 (1B)
/UI_20_C5_WIFI_IR_SERVICE/C5_SERVICE_RELEASE_NOT: U17.4 (2Y), U59.10 (2B)
/UI_20_C5_WIFI_IR_SERVICE/C5_SERVICE_USB_BRANCH_N: R108.1 (END_1), U22.2 (HSD1_MINUS)
/UI_20_C5_WIFI_IR_SERVICE/C5_SERVICE_USB_BRANCH_P: R109.1 (END_1), U22.1 (HSD1_PLUS)
/UI_20_C5_WIFI_IR_SERVICE/C5_SERVICE_USB_CONNECTOR_N: J9.A7 (A7_DM), J9.B7 (B7_DM), R108.2 (END_2), U21.2 (D_MINUS)
/UI_20_C5_WIFI_IR_SERVICE/C5_SERVICE_USB_CONNECTOR_P: J9.A6 (A6_DP), J9.B6 (B6_DP), R109.2 (END_2), U21.1 (D_PLUS)
/UI_20_C5_WIFI_IR_SERVICE/C5_SERVICE_VBUS_DIVIDED: Q4.1 (G), R111.1 (END_1), R112.2 (END_2)
/UI_20_C5_WIFI_IR_SERVICE/C5_SERVICE_VBUS_SENSE_ONLY: J9.A4 (A4_VBUS), J9.A9 (A9_VBUS), J9.B4 (B4_VBUS), J9.B9 (B9_VBUS), R110.1 (END_1), R112.1 (END_1)
/UI_20_C5_WIFI_IR_SERVICE/C5_UART_SERVICE_RX: R78.2 (END_2), U14.24 (GPIO12)
/UI_20_C5_WIFI_IR_SERVICE/C5_UART_SERVICE_TX: R77.2 (END_2), U14.25 (GPIO11)
/UI_20_C5_WIFI_IR_SERVICE/C5_USB_SDIO_COMMON_N: U14.13 (GPIO13), U22.7 (D_MINUS)
/UI_20_C5_WIFI_IR_SERVICE/C5_USB_SDIO_COMMON_P: U14.14 (GPIO14), U22.8 (D_PLUS)
/UI_20_C5_WIFI_IR_SERVICE/EV_N1_C5: R86.1 (END_1), R88.2 (END_2), U14.21 (GPIO23); also elsewhere on the board
/UI_20_C5_WIFI_IR_SERVICE/EV_N7_IR: R122.1 (END_1), R124.2 (END_2), U14.23 (GPIO24); also elsewhere on the board
/UI_20_C5_WIFI_IR_SERVICE/EV_THRESH_1_C5: R86.2 (END_2), R89.1 (END_1); also elsewhere on the board
/UI_20_C5_WIFI_IR_SERVICE/FAULT_ASSERT_N: U59.5 (1D); also elsewhere on the board
/UI_20_C5_WIFI_IR_SERVICE/HUB_C5_SDIO_DAT2_BRANCH: R102.2 (END_2), R103.2 (END_2), U22.3 (HSD2_PLUS)
/UI_20_C5_WIFI_IR_SERVICE/HUB_C5_SDIO_DAT3_BRANCH: R104.2 (END_2), R105.2 (END_2), U22.4 (HSD2_MINUS)
/UI_20_C5_WIFI_IR_SERVICE/HUB_RESET_LOW_PROOF: U19.4 (1C), U20.4 (2Y)
/UI_20_C5_WIFI_IR_SERVICE/HUB_RP_RESET_N: Q2.3 (D2), Q2.6 (D1), U20.3 (2A); also elsewhere on the board
/UI_20_C5_WIFI_IR_SERVICE/IR_CARRIER_BUFFERED_N: R116.1 (END_1), U26.3 (2Y)
/UI_20_C5_WIFI_IR_SERVICE/IR_CARRIER_LOCAL_N: R115.1 (END_1), U23.3 (CARRIER_OUT), U26.5 (2A)
/UI_20_C5_WIFI_IR_SERVICE/IR_CARRIER_VS: C29.1 (END_1), R115.2 (END_2), R117.2 (END_2), U23.2 (VS)
/UI_20_C5_WIFI_IR_SERVICE/IR_DEMOD_BUFFERED_N: R119.1 (END_1), U26.6 (1Y)
/UI_20_C5_WIFI_IR_SERVICE/IR_DEMOD_LOCAL_N: U24.3 (OUT), U26.2 (1A)
/UI_20_C5_WIFI_IR_SERVICE/IR_DEMOD_VS: C30.1 (END_1), R120.2 (END_2), U24.2 (VS)
/UI_20_C5_WIFI_IR_SERVICE/IR_EVIDENCE_VREF: C32.1 (END_1), R125.1 (END_1); also elsewhere on the board
/UI_20_C5_WIFI_IR_SERVICE/IR_FRONTEND_PWR_EN: R126.1 (END_1), U14.17 (GPIO4), U25.3 (ON)
/UI_20_C5_WIFI_IR_SERVICE/IR_LED_ANODE_LIMITED: D11.1 (ANODE), R121.2 (END_2)
/UI_20_C5_WIFI_IR_SERVICE/IR_LED_CATHODE: D11.2 (CATHODE), Q5.3 (D)
/UI_20_C5_WIFI_IR_SERVICE/IR_RX_CARRIER: R114.1 (END_1), R116.2 (END_2), U14.7 (GPIO1)
/UI_20_C5_WIFI_IR_SERVICE/IR_RX_DEMOD: R118.1 (END_1), R119.2 (END_2), U14.6 (GPIO0)
/UI_20_C5_WIFI_IR_SERVICE/IR_TX_CARRIER: R127.1 (END_1), U14.8 (GPIO6), U27.1 (A)
/UI_20_C5_WIFI_IR_SERVICE/IR_TX_CARRIER_SAFE: R129.1 (END_1), U27.4 (Y)
/UI_20_C5_WIFI_IR_SERVICE/IR_TX_GATE: Q5.1 (G), R128.1 (END_1), R129.2 (END_2)
/UI_20_C5_WIFI_IR_SERVICE/RUN_PERMIT: U27.2 (B), U59.4 (1C); also elsewhere on the board
/UI_20_C5_WIFI_IR_SERVICE/SERVICE_VBUS_PRESENT_N: Q4.3 (D), R113.2 (END_2), U18.7 (PRE_N), U19.1 (1A)
/UI_50_FRONT_POWER_SAFETY/C5_RESET_KILL_GATE: Q2.2 (G1); also elsewhere on the board
/UI_50_FRONT_POWER_SAFETY/EV_THRESH_7_IR: R122.2 (END_2); also elsewhere on the board

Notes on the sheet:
EXT ANT1 → C5_MODULE_RF_50R (on-module receptacle)

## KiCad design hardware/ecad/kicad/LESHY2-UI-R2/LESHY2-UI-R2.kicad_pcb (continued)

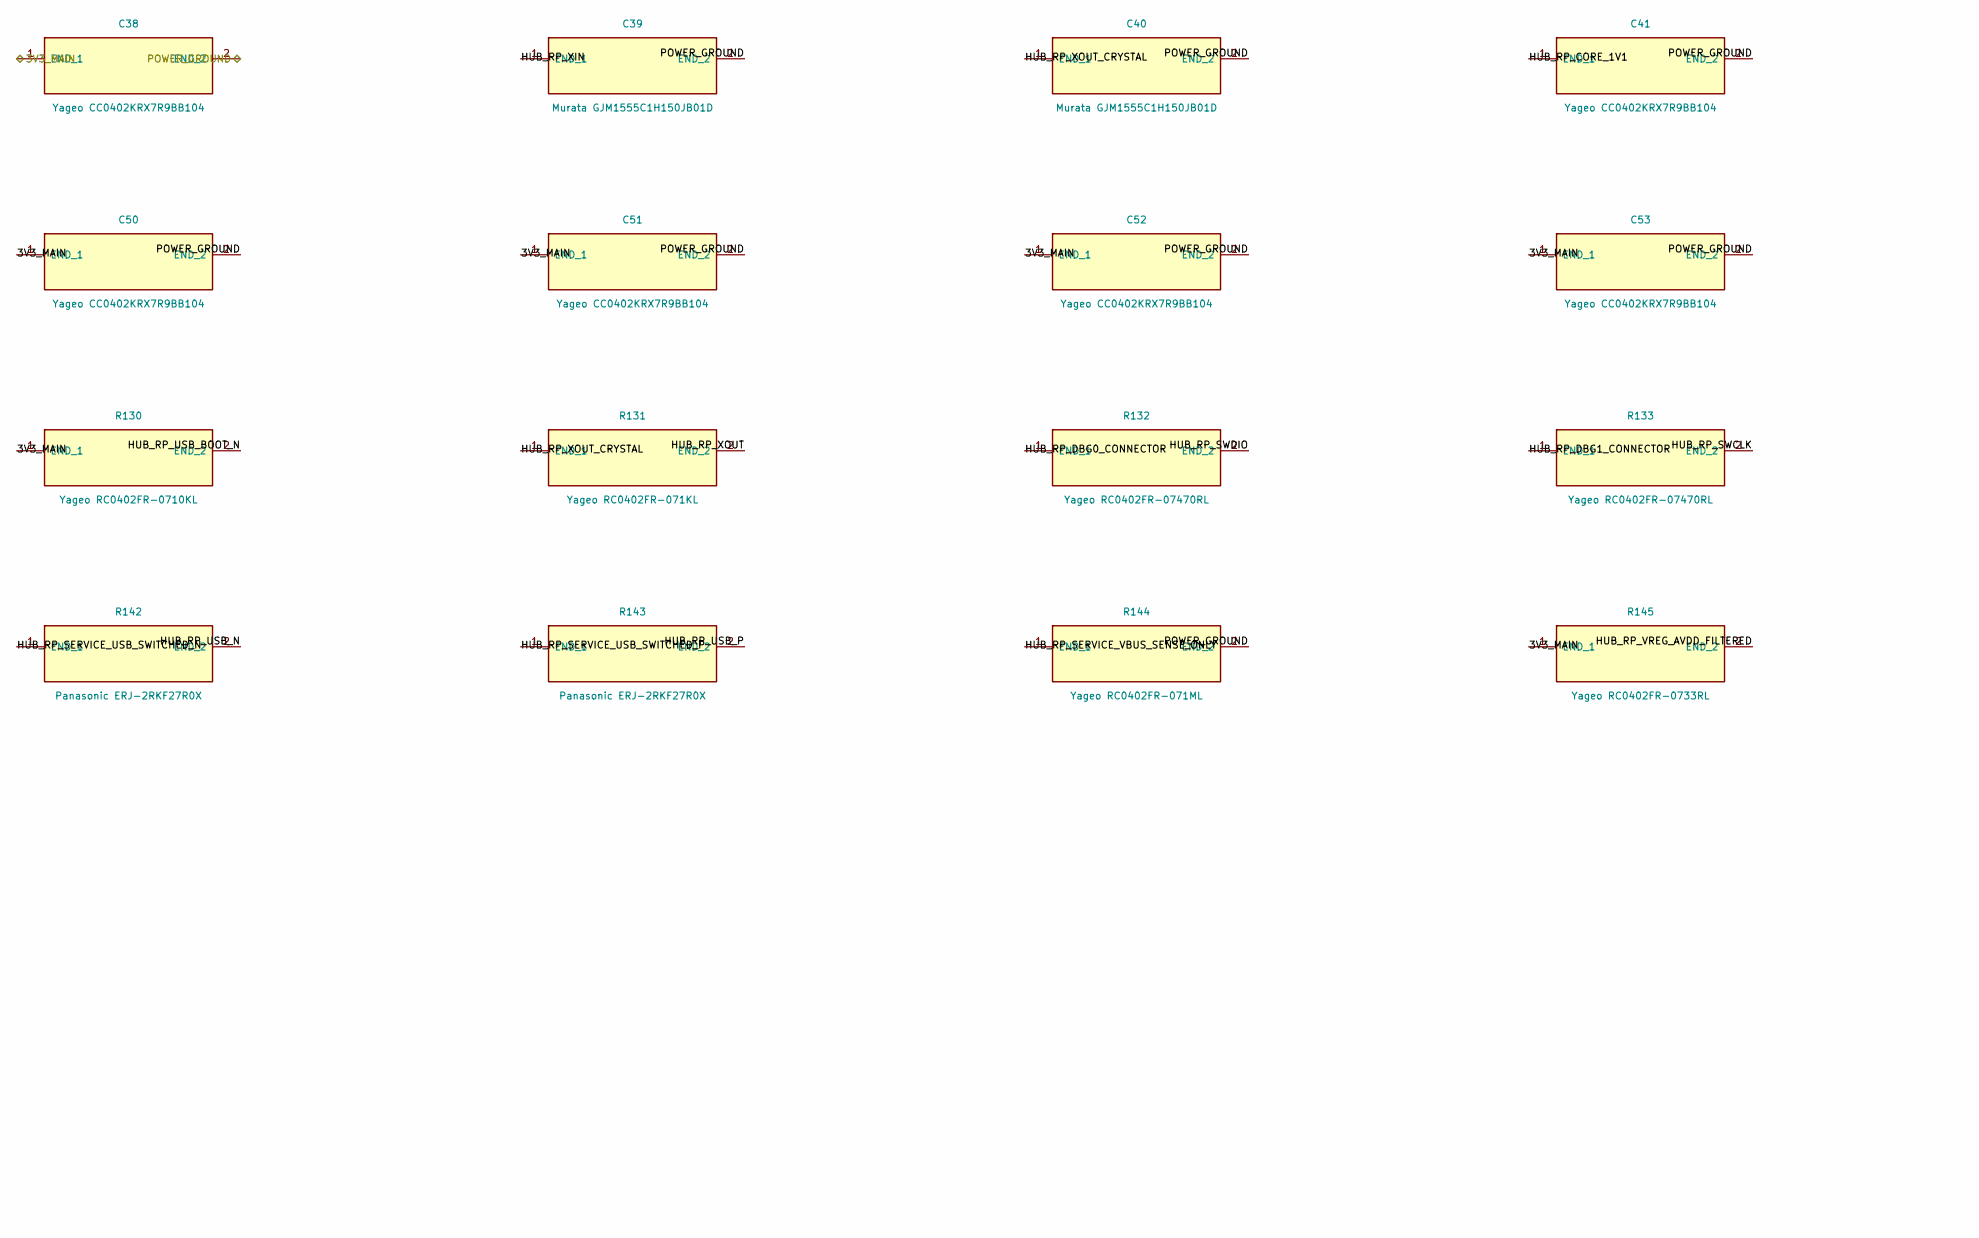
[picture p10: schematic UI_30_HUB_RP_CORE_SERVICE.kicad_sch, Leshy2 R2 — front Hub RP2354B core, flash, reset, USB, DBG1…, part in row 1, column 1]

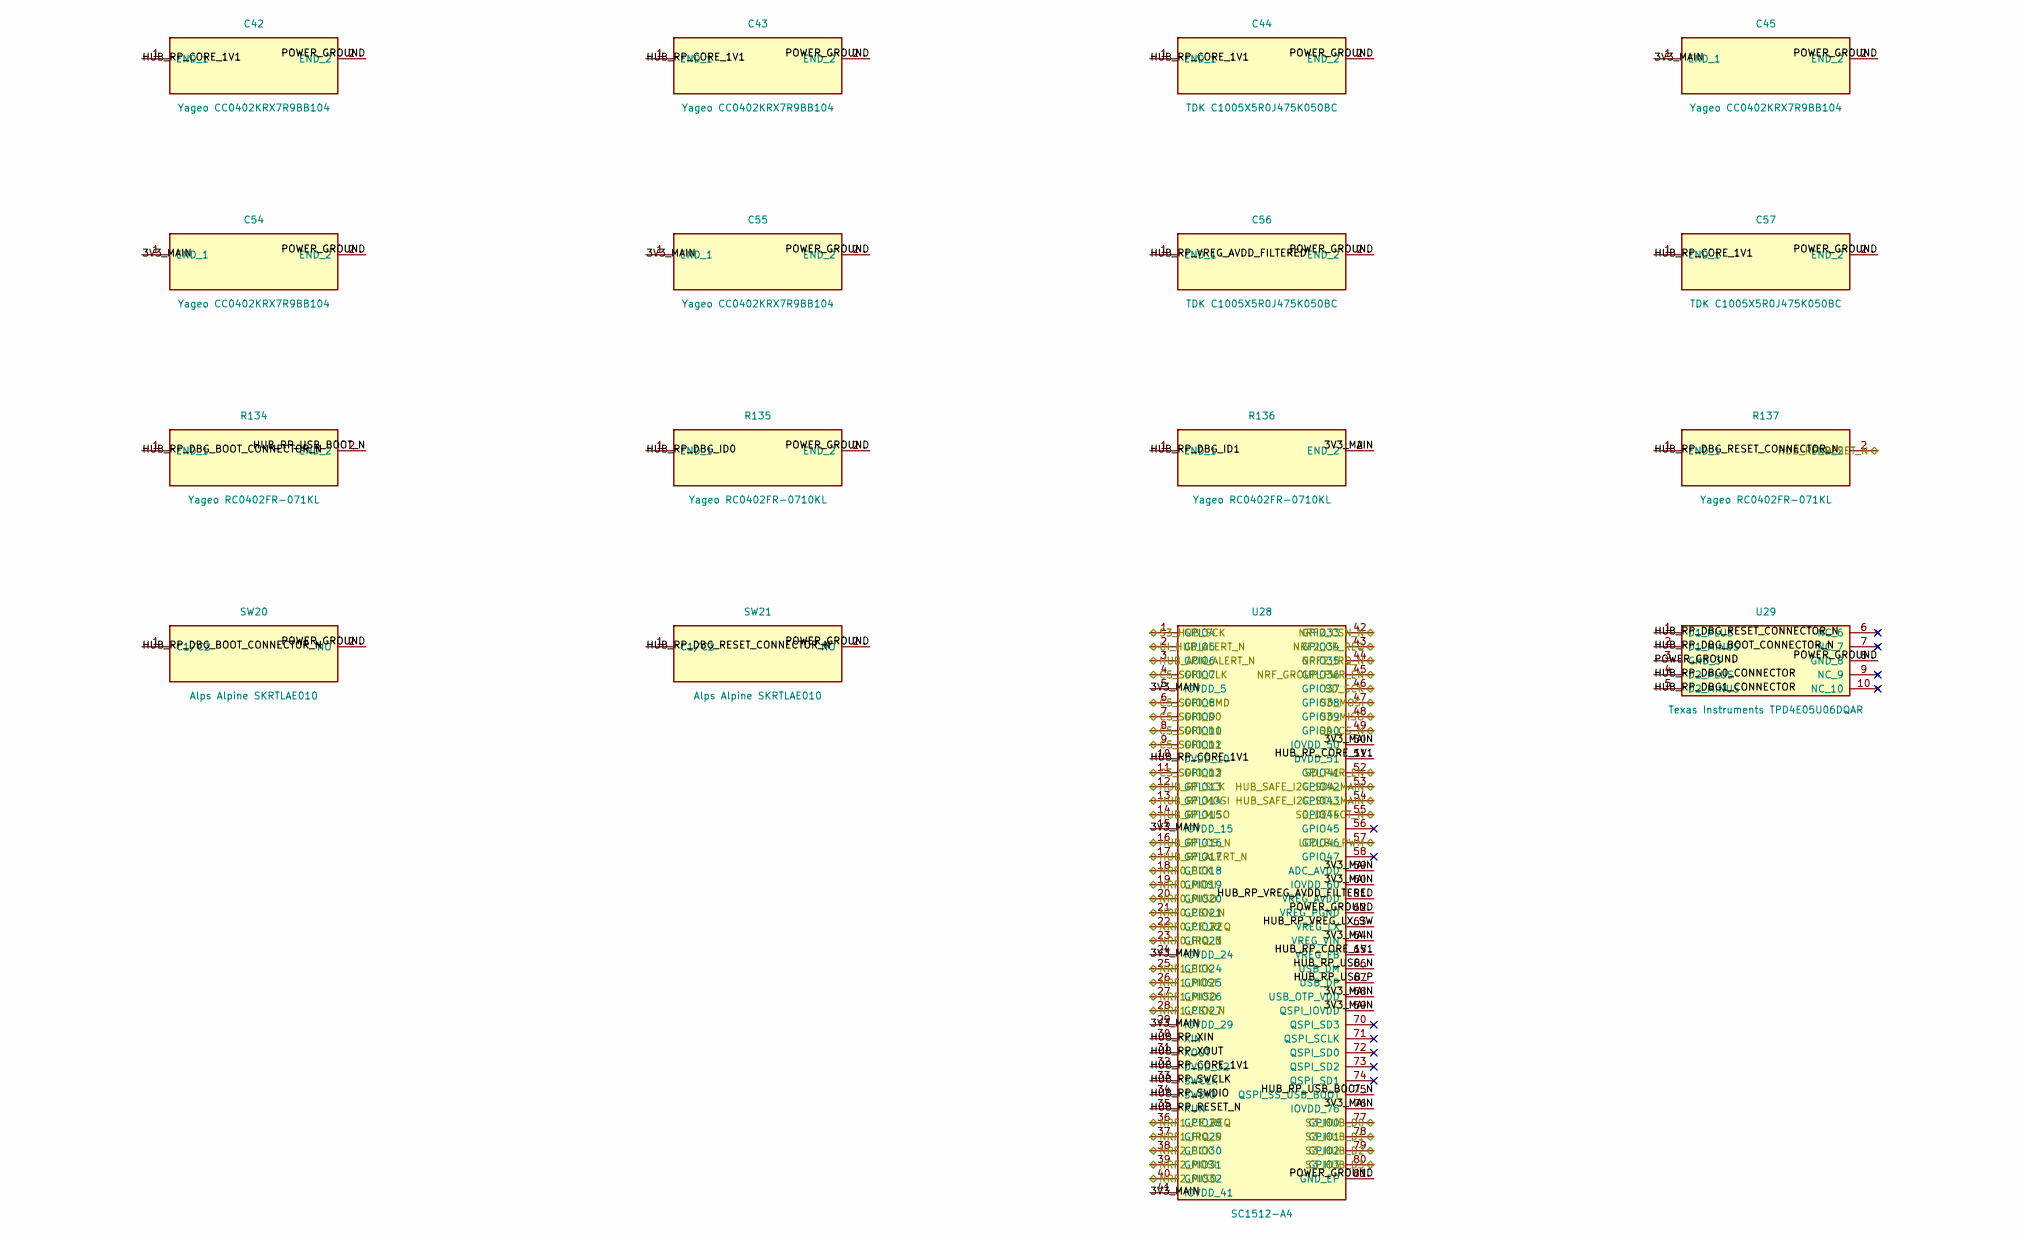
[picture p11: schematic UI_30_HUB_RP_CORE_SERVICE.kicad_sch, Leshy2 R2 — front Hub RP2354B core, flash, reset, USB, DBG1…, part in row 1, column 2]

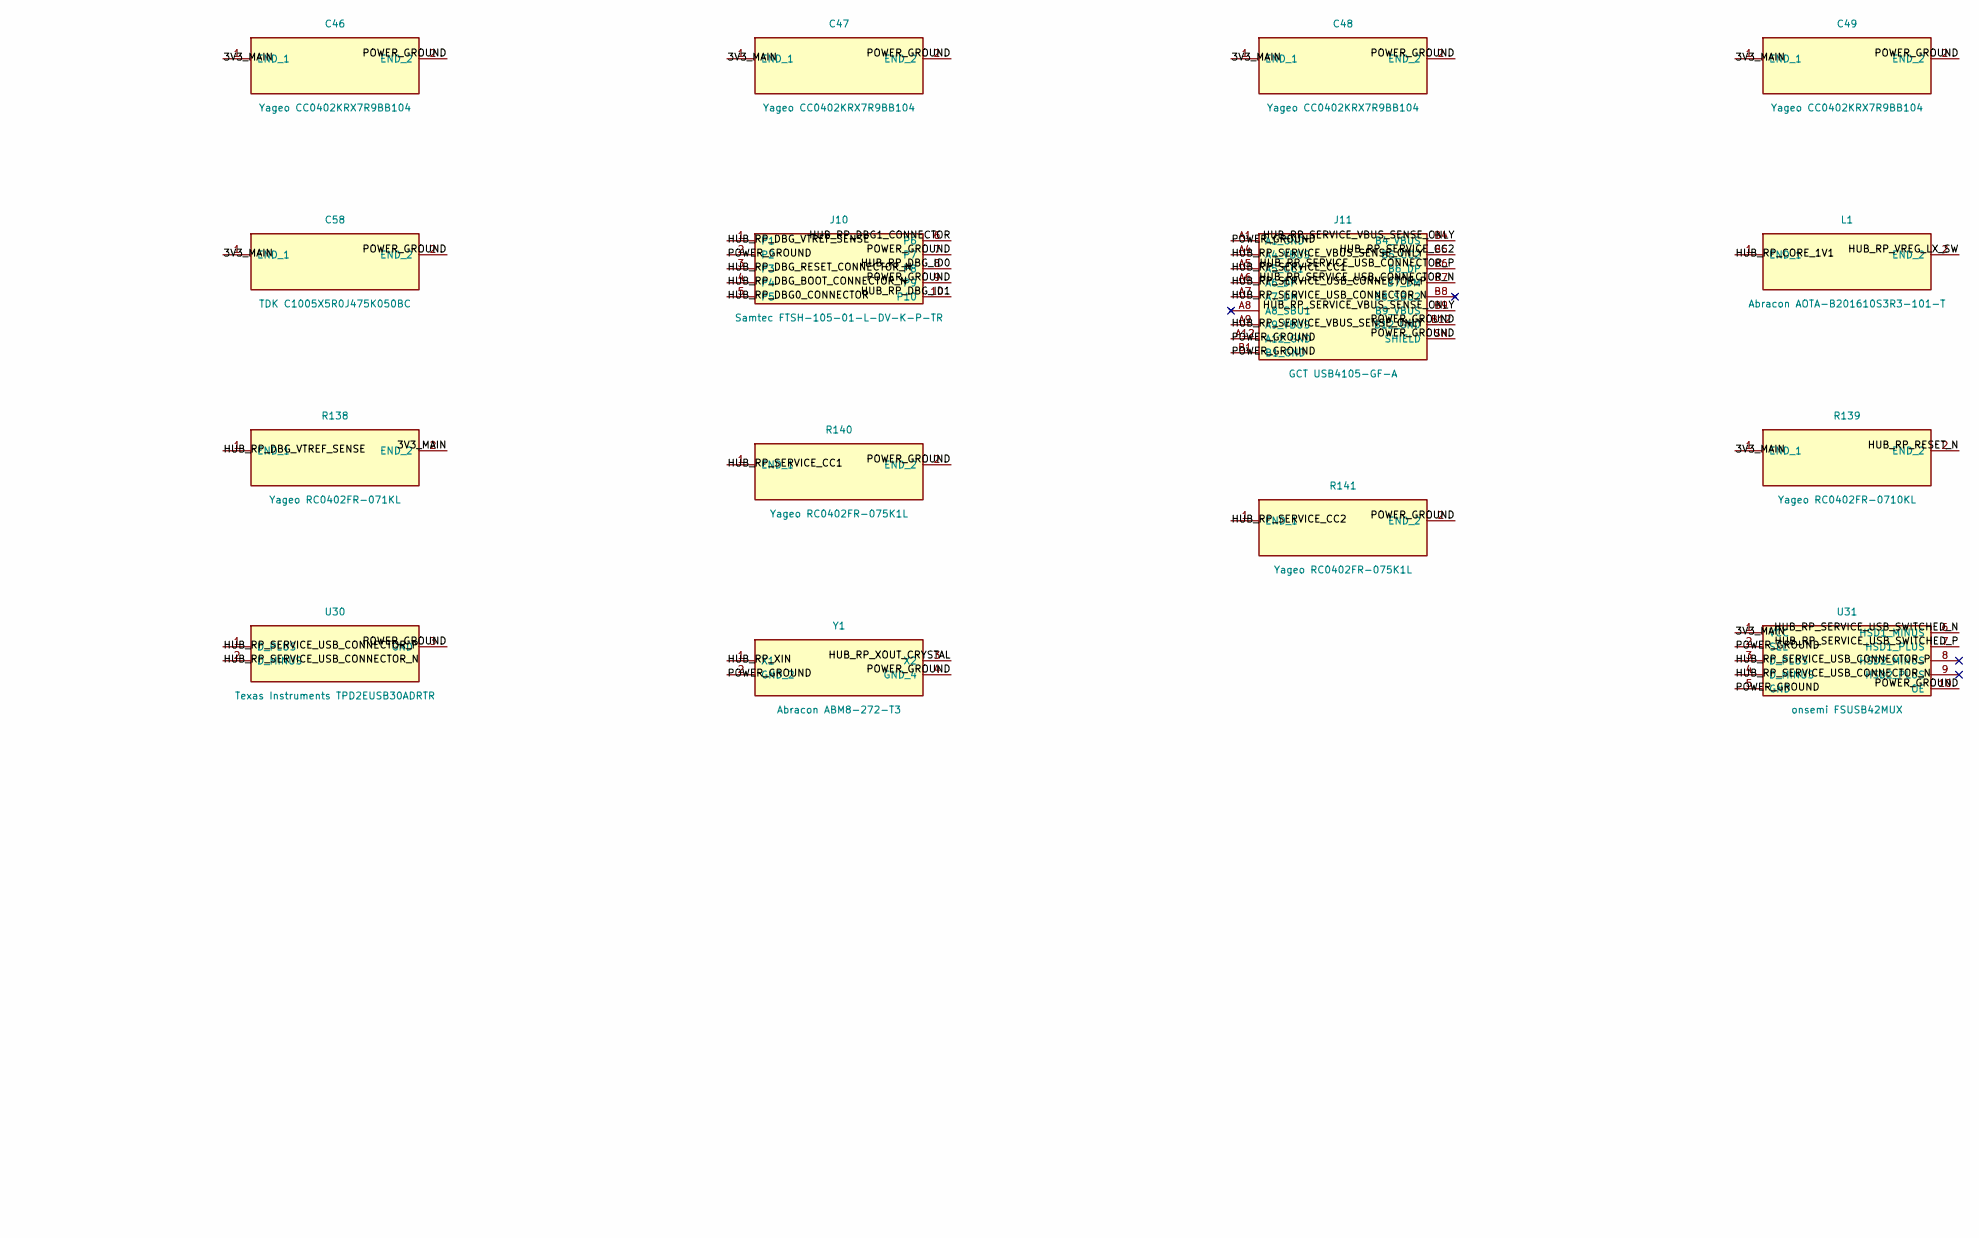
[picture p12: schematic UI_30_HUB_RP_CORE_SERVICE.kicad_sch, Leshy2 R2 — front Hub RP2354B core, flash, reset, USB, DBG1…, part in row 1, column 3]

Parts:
C38, C41, C42, C43, C45, C46, C47, C48, C49, C50, C51, C52, C53, C54, C55: Yageo CC0402KRX7R9BB104; C_0402_1005Metric
C39, C40: Murata GJM1555C1H150JB01D; C_0402_1005Metric
C44, C56, C57, C58: TDK C1005X5R0J475K050BC; C_0402_1005Metric
J10: Samtec FTSH-105-01-L-DV-K-P-TR; FTSH-105-01-L-DV-K-P-TR
J11: GCT USB4105-GF-A; USB_C_Receptacle_GCT_USB4105-xx-A_16P_TopMnt_Horizontal
L1: Abracon AOTA-B201610S3R3-101-T; L_Murata_DFE201610P
R130, R135, R136, R139: Yageo RC0402FR-0710KL; R_0402_1005Metric
R131, R134, R137, R138: Yageo RC0402FR-071KL; R_0402_1005Metric
R132, R133: Yageo RC0402FR-07470RL; R_0402_1005Metric
R140, R141: Yageo RC0402FR-075K1L; R_0402_1005Metric
R142, R143: Panasonic ERJ-2RKF27R0X; R_0402_1005Metric
R144: Yageo RC0402FR-071ML; R_0402_1005Metric
R145: Yageo RC0402FR-0733RL; R_0402_1005Metric
SW20, SW21: Alps Alpine SKRTLAE010; SW_Push_1P1T-MP_NO_Horizontal_Alps_SKRTLAE010
U28: SC1512-A4; QFN-80-1EP_10x10mm_P0.4mm_EP3.4x3.4mm
U29: Texas Instruments TPD4E05U06DQAR; USON-10_2.5x1.0mm_P0.5mm
U30: Texas Instruments TPD2EUSB30ADRTR; Texas_DRT-3
U31: onsemi FSUSB42MUX; MSOP-10_3x3mm_P0.5mm
Y1: Abracon ABM8-272-T3; Crystal_SMD_Abracon_ABM8G-4Pin_3.2x2.5mm

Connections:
/UI_10_S3_DISPLAY_TOUCH/3V3_MAIN: C38.1 (END_1), C45.1 (END_1), C46.1 (END_1), C47.1 (END_1), C48.1 (END_1), C49.1 (END_1), C50.1 (END_1), C51.1 (END_1), C52.1 (END_1), C53.1 (END_1), C54.1 (END_1), C55.1 (END_1), C58.1 (END_1), R130.1 (END_1), R136.2 (END_2), R138.2 (END_2), R139.1 (END_1), R145.1 (END_1), U28.5 (IOVDD_5), U28.15 (IOVDD_15), U28.24 (IOVDD_24), U28.29 (IOVDD_29), U28.41 (IOVDD_41), U28.50 (IOVDD_50), U28.59 (ADC_AVDD), U28.60 (IOVDD_60), U28.64 (VREG_VIN), U28.68 (USB_OTP_VDD), U28.69 (QSPI_IOVDD), U28.76 (IOVDD_76), U31.1 (VCC); also elsewhere on the board
/UI_10_S3_DISPLAY_TOUCH/POWER_GROUND: C38.2 (END_2), C39.2 (END_2), C40.2 (END_2), C41.2 (END_2), C42.2 (END_2), C43.2 (END_2), C44.2 (END_2), C45.2 (END_2), C46.2 (END_2), C47.2 (END_2), C48.2 (END_2), C49.2 (END_2), C50.2 (END_2), C51.2 (END_2), C52.2 (END_2), C53.2 (END_2), C54.2 (END_2), C55.2 (END_2), C56.2 (END_2), C57.2 (END_2), C58.2 (END_2), J10.2, J10.7, J10.9, J11.A1 (A1_GND), J11.A12 (A12_GND), J11.B1 (B1_GND), J11.B12 (B12_GND), J11.SH (SHIELD), R135.2 (END_2), R140.2 (END_2), R141.2 (END_2), R144.2 (END_2), SW20.2 (NO), SW21.2 (NO), U28.62 (VREG_PGND), U28.81 (GND_EP), U29.3 (GND_3), U29.8 (GND_8), U30.3 (GND), U31.2 (SEL), U31.5 (GND), U31.10 (OE), Y1.2 (GND_2), Y1.4 (GND_4); also elsewhere on the board
/UI_10_S3_DISPLAY_TOUCH/S3_HUB_D0: U28.77 (GPIO0); also elsewhere on the board
/UI_10_S3_DISPLAY_TOUCH/S3_HUB_D1: U28.78 (GPIO1); also elsewhere on the board
/UI_10_S3_DISPLAY_TOUCH/S3_HUB_D2: U28.79 (GPIO2); also elsewhere on the board
/UI_10_S3_DISPLAY_TOUCH/S3_HUB_D3: U28.80 (GPIO3); also elsewhere on the board
/UI_10_S3_DISPLAY_TOUCH/S3_HUB_SCK: U28.1 (GPIO4); also elsewhere on the board
/UI_10_S3_DISPLAY_TOUCH/UI_HUB_ALERT_N: U28.2 (GPIO5); also elsewhere on the board
/UI_11_STORAGE_CONTROLS_INDICATORS/LCD_BL_PWM: U28.57 (GPIO46); also elsewhere on the board
/UI_11_STORAGE_CONTROLS_INDICATORS/SD_CS_N: U28.49 (GPIO40); also elsewhere on the board
/UI_11_STORAGE_CONTROLS_INDICATORS/SD_DETECT_N: U28.55 (GPIO44); also elsewhere on the board
/UI_11_STORAGE_CONTROLS_INDICATORS/SD_MISO: U28.48 (GPIO39); also elsewhere on the board
/UI_11_STORAGE_CONTROLS_INDICATORS/SD_MOSI: U28.47 (GPIO38); also elsewhere on the board
/UI_11_STORAGE_CONTROLS_INDICATORS/SD_PWR_EN: U28.52 (GPIO41); also elsewhere on the board
/UI_11_STORAGE_CONTROLS_INDICATORS/SD_SCK: U28.46 (GPIO37); also elsewhere on the board
/UI_20_C5_WIFI_IR_SERVICE/C5_SDIO_CLK: U28.4 (GPIO7); also elsewhere on the board
/UI_20_C5_WIFI_IR_SERVICE/C5_SDIO_CMD: U28.6 (GPIO8); also elsewhere on the board
/UI_20_C5_WIFI_IR_SERVICE/C5_SDIO_D0: U28.7 (GPIO9); also elsewhere on the board
/UI_20_C5_WIFI_IR_SERVICE/C5_SDIO_D1: U28.8 (GPIO10); also elsewhere on the board
/UI_20_C5_WIFI_IR_SERVICE/C5_SDIO_D2: U28.9 (GPIO11); also elsewhere on the board
/UI_20_C5_WIFI_IR_SERVICE/C5_SDIO_D3: U28.11 (GPIO12); also elsewhere on the board
/UI_20_C5_WIFI_IR_SERVICE/HUB_RP_RESET_N: R137.2 (END_2), R139.2 (END_2), U28.35 (RUN); also elsewhere on the board
/UI_30_HUB_RP_CORE_SERVICE/HUB_AON_ALERT_N: U28.3 (GPIO6); also elsewhere on the board
/UI_30_HUB_RP_CORE_SERVICE/HUB_RF_ALERT_N: U28.17 (GPIO17); also elsewhere on the board
/UI_30_HUB_RP_CORE_SERVICE/HUB_RF_CS_N: U28.16 (GPIO16); also elsewhere on the board
/UI_30_HUB_RP_CORE_SERVICE/HUB_RF_MISO: U28.14 (GPIO15); also elsewhere on the board
/UI_30_HUB_RP_CORE_SERVICE/HUB_RF_MOSI: U28.13 (GPIO14); also elsewhere on the board
/UI_30_HUB_RP_CORE_SERVICE/HUB_RF_SCK: U28.12 (GPIO13); also elsewhere on the board
/UI_30_HUB_RP_CORE_SERVICE/HUB_RP_CORE_1V1: C41.1 (END_1), C42.1 (END_1), C43.1 (END_1), C44.1 (END_1), C57.1 (END_1), L1.1 (END_1), U28.10 (DVDD_10), U28.32 (DVDD_32), U28.51 (DVDD_51), U28.65 (VREG_FB)
/UI_30_HUB_RP_CORE_SERVICE/HUB_RP_DBG0_CONNECTOR: J10.5, R132.1 (END_1), U29.4 (D2_PLUS)
/UI_30_HUB_RP_CORE_SERVICE/HUB_RP_DBG1_CONNECTOR: J10.6, R133.1 (END_1), U29.5 (D2_MINUS)
/UI_30_HUB_RP_CORE_SERVICE/HUB_RP_DBG_BOOT_CONNECTOR_N: J10.4, R134.1 (END_1), SW20.1 (C1/C2), U29.2 (D1_MINUS)
/UI_30_HUB_RP_CORE_SERVICE/HUB_RP_DBG_ID0: J10.8, R135.1 (END_1)
/UI_30_HUB_RP_CORE_SERVICE/HUB_RP_DBG_ID1: J10.10, R136.1 (END_1)
/UI_30_HUB_RP_CORE_SERVICE/HUB_RP_DBG_RESET_CONNECTOR_N: J10.3, R137.1 (END_1), SW21.1 (C1/C2), U29.1 (D1_PLUS)
/UI_30_HUB_RP_CORE_SERVICE/HUB_RP_DBG_VTREF_SENSE: J10.1, R138.1 (END_1)
/UI_30_HUB_RP_CORE_SERVICE/HUB_RP_SERVICE_CC1: J11.A5 (A5_CC1), R140.1 (END_1)
/UI_30_HUB_RP_CORE_SERVICE/HUB_RP_SERVICE_CC2: J11.B5 (B5_CC2), R141.1 (END_1)
/UI_30_HUB_RP_CORE_SERVICE/HUB_RP_SERVICE_USB_CONNECTOR_N: J11.A7 (A7_DM), J11.B7 (B7_DM), U30.2 (D_MINUS), U31.4 (D_MINUS)
/UI_30_HUB_RP_CORE_SERVICE/HUB_RP_SERVICE_USB_CONNECTOR_P: J11.A6 (A6_DP), J11.B6 (B6_DP), U30.1 (D_PLUS), U31.3 (D_PLUS)
/UI_30_HUB_RP_CORE_SERVICE/HUB_RP_SERVICE_USB_SWITCHED_N: R142.1 (END_1), U31.6 (HSD1_MINUS)
/UI_30_HUB_RP_CORE_SERVICE/HUB_RP_SERVICE_USB_SWITCHED_P: R143.1 (END_1), U31.7 (HSD1_PLUS)
/UI_30_HUB_RP_CORE_SERVICE/HUB_RP_SERVICE_VBUS_SENSE_ONLY: J11.A4 (A4_VBUS), J11.A9 (A9_VBUS), J11.B4 (B4_VBUS), J11.B9 (B9_VBUS), R144.1 (END_1)
/UI_30_HUB_RP_CORE_SERVICE/HUB_RP_SWCLK: R133.2 (END_2), U28.33 (SWCLK)
/UI_30_HUB_RP_CORE_SERVICE/HUB_RP_SWDIO: R132.2 (END_2), U28.34 (SWDIO)
/UI_30_HUB_RP_CORE_SERVICE/HUB_RP_USB_BOOT_N: R130.2 (END_2), R134.2 (END_2), U28.75 (QSPI_SS_USB_BOOT)
/UI_30_HUB_RP_CORE_SERVICE/HUB_RP_USB_N: R142.2 (END_2), U28.66 (USB_DM)
/UI_30_HUB_RP_CORE_SERVICE/HUB_RP_USB_P: R143.2 (END_2), U28.67 (USB_DP)
/UI_30_HUB_RP_CORE_SERVICE/HUB_RP_VREG_AVDD_FILTERED: C56.1 (END_1), R145.2 (END_2), U28.61 (VREG_AVDD)
/UI_30_HUB_RP_CORE_SERVICE/HUB_RP_VREG_LX_SW: L1.2 (END_2), U28.63 (VREG_LX)
/UI_30_HUB_RP_CORE_SERVICE/HUB_RP_XIN: C39.1 (END_1), U28.30 (XIN), Y1.1 (X1)
/UI_30_HUB_RP_CORE_SERVICE/HUB_RP_XOUT: R131.2 (END_2), U28.31 (XOUT)
/UI_30_HUB_RP_CORE_SERVICE/HUB_RP_XOUT_CRYSTAL: C40.1 (END_1), R131.1 (END_1), Y1.3 (X2)
/UI_30_HUB_RP_CORE_SERVICE/HUB_SAFE_I2C_SCL_MAIN: U28.54 (GPIO43); also elsewhere on the board
/UI_30_HUB_RP_CORE_SERVICE/HUB_SAFE_I2C_SDA_MAIN: U28.53 (GPIO42); also elsewhere on the board
/UI_30_HUB_RP_CORE_SERVICE/NRF0_CE_REQ: U28.22 (GPIO22); also elsewhere on the board
/UI_30_HUB_RP_CORE_SERVICE/NRF1_CE_REQ: U28.36 (GPIO28); also elsewhere on the board
/UI_30_HUB_RP_CORE_SERVICE/NRF2_CE_REQ: U28.43 (GPIO34); also elsewhere on the board
/UI_30_HUB_RP_CORE_SERVICE/NRF_GROUP_PWR_EN: U28.45 (GPIO36); also elsewhere on the board
/UI_31_NRF24_X3_TX_EVIDENCE/NRF0_CSN_N: U28.21 (GPIO21); also elsewhere on the board
/UI_31_NRF24_X3_TX_EVIDENCE/NRF0_IRQ_N: U28.23 (GPIO23); also elsewhere on the board
/UI_31_NRF24_X3_TX_EVIDENCE/NRF0_MISO: U28.20 (GPIO20); also elsewhere on the board
/UI_31_NRF24_X3_TX_EVIDENCE/NRF0_MOSI: U28.19 (GPIO19); also elsewhere on the board
/UI_31_NRF24_X3_TX_EVIDENCE/NRF0_SCK: U28.18 (GPIO18); also elsewhere on the board
/UI_31_NRF24_X3_TX_EVIDENCE/NRF1_CSN_N: U28.28 (GPIO27); also elsewhere on the board
/UI_31_NRF24_X3_TX_EVIDENCE/NRF1_IRQ_N: U28.37 (GPIO29); also elsewhere on the board
/UI_31_NRF24_X3_TX_EVIDENCE/NRF1_MISO: U28.27 (GPIO26); also elsewhere on the board
/UI_31_NRF24_X3_TX_EVIDENCE/NRF1_MOSI: U28.26 (GPIO25); also elsewhere on the board
/UI_31_NRF24_X3_TX_EVIDENCE/NRF1_SCK: U28.25 (GPIO24); also elsewhere on the board
/UI_31_NRF24_X3_TX_EVIDENCE/NRF2_CSN_N: U28.42 (GPIO33); also elsewhere on the board
/UI_31_NRF24_X3_TX_EVIDENCE/NRF2_IRQ_N: U28.44 (GPIO35); also elsewhere on the board
/UI_31_NRF24_X3_TX_EVIDENCE/NRF2_MISO: U28.40 (GPIO32); also elsewhere on the board
/UI_31_NRF24_X3_TX_EVIDENCE/NRF2_MOSI: U28.39 (GPIO31); also elsewhere on the board
/UI_31_NRF24_X3_TX_EVIDENCE/NRF2_SCK: U28.38 (GPIO30); also elsewhere on the board

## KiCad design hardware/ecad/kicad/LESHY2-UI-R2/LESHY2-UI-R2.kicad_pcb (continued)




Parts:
C59, C61, C63, C64, C65, C67, C69, C70, C71, C73, C75, C76, C77: Yageo CC0402KRX7R9BB104; C_0402_1005Metric
C60, C66, C72: Murata GRM1555C1H121JA01D; C_0402_1005Metric
C62, C68, C74: Murata GRM188R60J106ME47D; C_0603_1608Metric
C78, C79: TDK C1608X7R1C105K080AC; C_0603_1608Metric
J12, J14, J16: GCT RFPC-SMA31-FN-175-A; RFPC-SMA31-FN-175-A
J13, J15, J17: Hirose U.FL-R-SMT-1(80); U.FL_Hirose_U.FL-R-SMT-1_Vertical
R146, R148, R156, R157, R164, R165, R166, R168, R176, R177, R184, R185, R186, R188, R196, R197, R204, R205: Panasonic ERJ-2RKF22R0X; R_0402_1005Metric
R147, R167, R187: Yageo RC0402FR-0749R9L; R_0402_1005Metric
R149, R169, R189: Yageo RC0402FR-0752R3L; R_0402_1005Metric
R150, R151, R152, R153, R154, R155, R158, R159, R160, R161, R162, R163, R170, R171, R172, R173, R174, R175, R178, R179, R180, R181, R182, R183, R190, R191, R192, R193, R194, R195, R198, R199, R200, R201, R202, R203, R206, R207: Yageo RC0402FR-0710KL; R_0402_1005Metric
U32, U33, U34: Analog Devices AD8314ARMZ-REEL; MSOP-8_3x3mm_P0.65mm
U35, U39, U43: Ebyte E01-ML01SP4; Ebyte-E01-ML01SP4
U36, U40, U44: TTM Technologies DC2337J5010AHF; DC2337J5010AHF
U37, U41, U45: Nexperia 74LVC126APW,118; TSSOP-14_4.4x5mm_P0.65mm
U38, U42, U46: Nexperia 74LVC2G126DP,125; TSSOP-8_3x3mm_P0.65mm
U47: SN74LVC1G08DCKR; Texas_R-PDSO-G5_DCK-5
U48: Diodes Incorporated BAT54-7-F; SOT-23
U49: Texas Instruments TPS22919DCKR; SOT-363_SC-70-6

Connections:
/UI_10_S3_DISPLAY_TOUCH/3V3_MAIN: C79.1 (END_1), R151.2 (END_2), R152.2 (END_2), R171.2 (END_2), R172.2 (END_2), R191.2 (END_2), R192.2 (END_2), U49.1 (IN); also elsewhere on the board
/UI_10_S3_DISPLAY_TOUCH/AON_SAFE_3V3: C59.1 (END_1), C65.1 (END_1), C71.1 (END_1), C77.1 (END_1), U32.8 (VPOS), U33.8 (VPOS), U34.8 (VPOS), U47.5 (VCC); also elsewhere on the board
/UI_10_S3_DISPLAY_TOUCH/POWER_GROUND: C59.2 (END_2), C61.2 (END_2), C62.2 (END_2), C63.2 (END_2), C64.2 (END_2), C65.2 (END_2), C67.2 (END_2), C68.2 (END_2), C69.2 (END_2), C70.2 (END_2), C71.2 (END_2), C73.2 (END_2), C74.2 (END_2), C75.2 (END_2), C76.2 (END_2), C77.2 (END_2), C78.2 (END_2), C79.2 (END_2), J12.2 (GROUND_TOP_LEFT), J12.3 (GROUND_TOP_RIGHT), J12.4 (GROUND_BOTTOM_LEFT), J12.5 (GROUND_BOTTOM_RIGHT), J13.2 (SHELL), J14.2 (GROUND_TOP_LEFT), J14.3 (GROUND_TOP_RIGHT), J14.4 (GROUND_BOTTOM_LEFT), J14.5 (GROUND_BOTTOM_RIGHT), J15.2 (SHELL), J16.2 (GROUND_TOP_LEFT), J16.3 (GROUND_TOP_RIGHT), J16.4 (GROUND_BOTTOM_LEFT), J16.5 (GROUND_BOTTOM_RIGHT), J17.2 (SHELL), R147.2 (END_2), R149.2 (END_2), R150.2 (END_2), R153.2 (END_2), R154.2 (END_2), R155.2 (END_2), R158.2 (END_2), R161.2 (END_2), R162.2 (END_2), R163.2 (END_2), R167.2 (END_2), R169.2 (END_2), R170.2 (END_2), R173.2 (END_2), R174.2 (END_2), R175.2 (END_2), R178.2 (END_2), R181.2 (END_2), R182.2 (END_2), R183.2 (END_2), R187.2 (END_2), R189.2 (END_2), R190.2 (END_2), R193.2 (END_2), R194.2 (END_2), R195.2 (END_2), R198.2 (END_2), R201.2 (END_2), R202.2 (END_2), R203.2 (END_2), R206.2 (END_2), R207.2 (END_2), U32.5 (COMM), U33.5 (COMM), U34.5 (COMM), U35.8 (GND), U35.9 (GND_9), U35.10 (GND_10), U36.3 (GND_3), U36.4 (GND_4), U37.7 (GND), U38.4 (GND), U39.8 (GND), U39.9 (GND_9), U39.10 (GND_10), U40.3 (GND_3), U40.4 (GND_4), U41.7 (GND), U42.4 (GND), U43.8 (GND), U43.9 (GND_9), U43.10 (GND_10), U44.3 (GND_3), U44.4 (GND_4), U45.7 (GND), U46.4 (GND), U47.3 (GND), U49.2 (GND); also elsewhere on the board
/UI_20_C5_WIFI_IR_SERVICE/FAULT_ASSERT_N: U47.2 (B); also elsewhere on the board
/UI_31_NRF24_X3_TX_EVIDENCE/3V3_NRF_GROUP: C61.1 (END_1), C62.1 (END_1), C63.1 (END_1), C64.1 (END_1), C67.1 (END_1), C68.1 (END_1), C69.1 (END_1), C70.1 (END_1), C73.1 (END_1), C74.1 (END_1), C75.1 (END_1), C76.1 (END_1), R159.2 (END_2), R160.2 (END_2), R179.2 (END_2), R180.2 (END_2), R199.2 (END_2), R200.2 (END_2), U35.1 (VCC), U37.1 (1OE), U37.4 (2OE), U37.10 (3OE), U37.13 (4OE), U37.14 (VCC), U38.1 (1OE), U38.7 (2OE), U38.8 (VCC), U39.1 (VCC), U41.1 (1OE), U41.4 (2OE), U41.10 (3OE), U41.13 (4OE), U41.14 (VCC), U42.1 (1OE), U42.7 (2OE), U42.8 (VCC), U43.1 (VCC), U45.1 (1OE), U45.4 (2OE), U45.10 (3OE), U45.13 (4OE), U45.14 (VCC), U46.1 (1OE), U46.7 (2OE), U46.8 (VCC), U49.5 (QOD), U49.6 (VOUT)
/UI_31_NRF24_X3_TX_EVIDENCE/NRF0_CE_BUFFERED: R146.1 (END_1), U37.3 (1Y)
/UI_31_NRF24_X3_TX_EVIDENCE/NRF0_CE_MODULE: R146.2 (END_2), R158.1 (END_1), U35.2 (CE)
/UI_31_NRF24_X3_TX_EVIDENCE/NRF0_CE_SAFE: R150.1 (END_1), U37.2 (1A); also elsewhere on the board
/UI_31_NRF24_X3_TX_EVIDENCE/NRF0_CSN_BUFFERED_N: R148.1 (END_1), U37.6 (2Y)
/UI_31_NRF24_X3_TX_EVIDENCE/NRF0_CSN_MODULE_N: R148.2 (END_2), R159.1 (END_1), U35.3 (CSN)
/UI_31_NRF24_X3_TX_EVIDENCE/NRF0_CSN_N: R151.1 (END_1), U37.5 (2A); also elsewhere on the board
/UI_31_NRF24_X3_TX_EVIDENCE/NRF0_DETECT_FILTER: C60.1 (END_1), U32.4 (FLTR)
/UI_31_NRF24_X3_TX_EVIDENCE/NRF0_DETECT_V: C60.2 (END_2), U32.3 (VSET), U32.6 (V_UP); also elsewhere on the board
/UI_31_NRF24_X3_TX_EVIDENCE/NRF0_EXTERNAL_RF_50R: J12.1 (RF), U36.6 (RF_OUT)
/UI_31_NRF24_X3_TX_EVIDENCE/NRF0_FORWARD_RF_SAMPLE: R149.1 (END_1), U32.1 (RFIN), U36.2 (COUPLED_FWD)
/UI_31_NRF24_X3_TX_EVIDENCE/NRF0_IRQ_BUFFERED_N: R156.1 (END_1), U38.3 (2Y)
/UI_31_NRF24_X3_TX_EVIDENCE/NRF0_IRQ_MODULE_N: R160.1 (END_1), U35.7 (IRQ), U38.5 (2A)
/UI_31_NRF24_X3_TX_EVIDENCE/NRF0_IRQ_N: R152.1 (END_1), R156.2 (END_2); also elsewhere on the board
/UI_31_NRF24_X3_TX_EVIDENCE/NRF0_MISO: R153.1 (END_1), R157.2 (END_2); also elsewhere on the board
/UI_31_NRF24_X3_TX_EVIDENCE/NRF0_MISO_BUFFERED: R157.1 (END_1), U38.6 (1Y)
/UI_31_NRF24_X3_TX_EVIDENCE/NRF0_MISO_MODULE: R161.1 (END_1), U35.6 (MISO), U38.2 (1A)
/UI_31_NRF24_X3_TX_EVIDENCE/NRF0_MODULE_RF_50R: J13.1 (CENTER), U36.1 (RF_IN)
/UI_31_NRF24_X3_TX_EVIDENCE/NRF0_MOSI: R154.1 (END_1), U37.12 (4A); also elsewhere on the board
/UI_31_NRF24_X3_TX_EVIDENCE/NRF0_MOSI_BUFFERED: R164.1 (END_1), U37.11 (4Y)
/UI_31_NRF24_X3_TX_EVIDENCE/NRF0_MOSI_MODULE: R162.1 (END_1), R164.2 (END_2), U35.5 (MOSI)
/UI_31_NRF24_X3_TX_EVIDENCE/NRF0_REVERSE_ISOLATED_PORT: R147.1 (END_1), U36.5 (ISOLATED_REVERSE)
/UI_31_NRF24_X3_TX_EVIDENCE/NRF0_SCK: R155.1 (END_1), U37.9 (3A); also elsewhere on the board
/UI_31_NRF24_X3_TX_EVIDENCE/NRF0_SCK_BUFFERED: R165.1 (END_1), U37.8 (3Y)
/UI_31_NRF24_X3_TX_EVIDENCE/NRF0_SCK_MODULE: R163.1 (END_1), R165.2 (END_2), U35.4 (SCK)
/UI_31_NRF24_X3_TX_EVIDENCE/NRF1_CE_BUFFERED: R166.1 (END_1), U41.3 (1Y)
/UI_31_NRF24_X3_TX_EVIDENCE/NRF1_CE_MODULE: R166.2 (END_2), R178.1 (END_1), U39.2 (CE)
/UI_31_NRF24_X3_TX_EVIDENCE/NRF1_CE_SAFE: R170.1 (END_1), U41.2 (1A); also elsewhere on the board
/UI_31_NRF24_X3_TX_EVIDENCE/NRF1_CSN_BUFFERED_N: R168.1 (END_1), U41.6 (2Y)
/UI_31_NRF24_X3_TX_EVIDENCE/NRF1_CSN_MODULE_N: R168.2 (END_2), R179.1 (END_1), U39.3 (CSN)
/UI_31_NRF24_X3_TX_EVIDENCE/NRF1_CSN_N: R171.1 (END_1), U41.5 (2A); also elsewhere on the board
/UI_31_NRF24_X3_TX_EVIDENCE/NRF1_DETECT_FILTER: C66.1 (END_1), U33.4 (FLTR)
/UI_31_NRF24_X3_TX_EVIDENCE/NRF1_DETECT_V: C66.2 (END_2), U33.3 (VSET), U33.6 (V_UP); also elsewhere on the board
/UI_31_NRF24_X3_TX_EVIDENCE/NRF1_EXTERNAL_RF_50R: J14.1 (RF), U40.6 (RF_OUT)
/UI_31_NRF24_X3_TX_EVIDENCE/NRF1_FORWARD_RF_SAMPLE: R169.1 (END_1), U33.1 (RFIN), U40.2 (COUPLED_FWD)
/UI_31_NRF24_X3_TX_EVIDENCE/NRF1_IRQ_BUFFERED_N: R176.1 (END_1), U42.3 (2Y)
/UI_31_NRF24_X3_TX_EVIDENCE/NRF1_IRQ_MODULE_N: R180.1 (END_1), U39.7 (IRQ), U42.5 (2A)
/UI_31_NRF24_X3_TX_EVIDENCE/NRF1_IRQ_N: R172.1 (END_1), R176.2 (END_2); also elsewhere on the board
/UI_31_NRF24_X3_TX_EVIDENCE/NRF1_MISO: R173.1 (END_1), R177.2 (END_2); also elsewhere on the board
/UI_31_NRF24_X3_TX_EVIDENCE/NRF1_MISO_BUFFERED: R177.1 (END_1), U42.6 (1Y)
/UI_31_NRF24_X3_TX_EVIDENCE/NRF1_MISO_MODULE: R181.1 (END_1), U39.6 (MISO), U42.2 (1A)
/UI_31_NRF24_X3_TX_EVIDENCE/NRF1_MODULE_RF_50R: J15.1 (CENTER), U40.1 (RF_IN)
/UI_31_NRF24_X3_TX_EVIDENCE/NRF1_MOSI: R174.1 (END_1), U41.12 (4A); also elsewhere on the board
/UI_31_NRF24_X3_TX_EVIDENCE/NRF1_MOSI_BUFFERED: R184.1 (END_1), U41.11 (4Y)
/UI_31_NRF24_X3_TX_EVIDENCE/NRF1_MOSI_MODULE: R182.1 (END_1), R184.2 (END_2), U39.5 (MOSI)
/UI_31_NRF24_X3_TX_EVIDENCE/NRF1_REVERSE_ISOLATED_PORT: R167.1 (END_1), U40.5 (ISOLATED_REVERSE)
/UI_31_NRF24_X3_TX_EVIDENCE/NRF1_SCK: R175.1 (END_1), U41.9 (3A); also elsewhere on the board
/UI_31_NRF24_X3_TX_EVIDENCE/NRF1_SCK_BUFFERED: R185.1 (END_1), U41.8 (3Y)
/UI_31_NRF24_X3_TX_EVIDENCE/NRF1_SCK_MODULE: R183.1 (END_1), R185.2 (END_2), U39.4 (SCK)
/UI_31_NRF24_X3_TX_EVIDENCE/NRF2_CE_BUFFERED: R186.1 (END_1), U45.3 (1Y)
/UI_31_NRF24_X3_TX_EVIDENCE/NRF2_CE_MODULE: R186.2 (END_2), R198.1 (END_1), U43.2 (CE)
/UI_31_NRF24_X3_TX_EVIDENCE/NRF2_CE_SAFE: R190.1 (END_1), U45.2 (1A); also elsewhere on the board
/UI_31_NRF24_X3_TX_EVIDENCE/NRF2_CSN_BUFFERED_N: R188.1 (END_1), U45.6 (2Y)
/UI_31_NRF24_X3_TX_EVIDENCE/NRF2_CSN_MODULE_N: R188.2 (END_2), R199.1 (END_1), U43.3 (CSN)
/UI_31_NRF24_X3_TX_EVIDENCE/NRF2_CSN_N: R191.1 (END_1), U45.5 (2A); also elsewhere on the board
/UI_31_NRF24_X3_TX_EVIDENCE/NRF2_DETECT_FILTER: C72.1 (END_1), U34.4 (FLTR)
/UI_31_NRF24_X3_TX_EVIDENCE/NRF2_DETECT_V: C72.2 (END_2), U34.3 (VSET), U34.6 (V_UP); also elsewhere on the board
/UI_31_NRF24_X3_TX_EVIDENCE/NRF2_EXTERNAL_RF_50R: J16.1 (RF), U44.6 (RF_OUT)
/UI_31_NRF24_X3_TX_EVIDENCE/NRF2_FORWARD_RF_SAMPLE: R189.1 (END_1), U34.1 (RFIN), U44.2 (COUPLED_FWD)
/UI_31_NRF24_X3_TX_EVIDENCE/NRF2_IRQ_BUFFERED_N: R196.1 (END_1), U46.3 (2Y)
/UI_31_NRF24_X3_TX_EVIDENCE/NRF2_IRQ_MODULE_N: R200.1 (END_1), U43.7 (IRQ), U46.5 (2A)
/UI_31_NRF24_X3_TX_EVIDENCE/NRF2_IRQ_N: R192.1 (END_1), R196.2 (END_2); also elsewhere on the board
/UI_31_NRF24_X3_TX_EVIDENCE/NRF2_MISO: R193.1 (END_1), R197.2 (END_2); also elsewhere on the board
/UI_31_NRF24_X3_TX_EVIDENCE/NRF2_MISO_BUFFERED: R197.1 (END_1), U46.6 (1Y)
/UI_31_NRF24_X3_TX_EVIDENCE/NRF2_MISO_MODULE: R201.1 (END_1), U43.6 (MISO), U46.2 (1A)
/UI_31_NRF24_X3_TX_EVIDENCE/NRF2_MODULE_RF_50R: J17.1 (CENTER), U44.1 (RF_IN)
/UI_31_NRF24_X3_TX_EVIDENCE/NRF2_MOSI: R194.1 (END_1), U45.12 (4A); also elsewhere on the board
/UI_31_NRF24_X3_TX_EVIDENCE/NRF2_MOSI_BUFFERED: R204.1 (END_1), U45.11 (4Y)
/UI_31_NRF24_X3_TX_EVIDENCE/NRF2_MOSI_MODULE: R202.1 (END_1), R204.2 (END_2), U43.5 (MOSI)
/UI_31_NRF24_X3_TX_EVIDENCE/NRF2_REVERSE_ISOLATED_PORT: R187.1 (END_1), U44.5 (ISOLATED_REVERSE)
/UI_31_NRF24_X3_TX_EVIDENCE/NRF2_SCK: R195.1 (END_1), U45.9 (3A); also elsewhere on the board
/UI_31_NRF24_X3_TX_EVIDENCE/NRF2_SCK_BUFFERED: R205.1 (END_1), U45.8 (3Y)
/UI_31_NRF24_X3_TX_EVIDENCE/NRF2_SCK_MODULE: R203.1 (END_1), R205.2 (END_2), U43.4 (SCK)
/UI_31_NRF24_X3_TX_EVIDENCE/NRF_EVIDENCE_HOLD: C78.1 (END_1), R206.1 (END_1), U32.2 (ENBL), U33.2 (ENBL), U34.2 (ENBL), U48.3 (K)
/UI_31_NRF24_X3_TX_EVIDENCE/NRF_GROUP_PWR_EN_PRIMARY: U47.1 (A); also elsewhere on the board
/UI_31_NRF24_X3_TX_EVIDENCE/NRF_GROUP_PWR_EN_SAFE: R207.1 (END_1), U47.4 (Y), U48.1 (A), U49.3 (ON)

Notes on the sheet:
EXT ANT → NRF0_MODULE_RF_50R (on-module receptacle)
EXT ANT → NRF1_MODULE_RF_50R (on-module receptacle)
EXT ANT → NRF2_MODULE_RF_50R (on-module receptacle)


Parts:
J18: Hirose FX8C-80P-SV1(92); Hirose_FX8-80P-SV_2x40_P0.6mm

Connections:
/UI_10_S3_DISPLAY_TOUCH/3V3_MAIN: J18.2, J18.4, J18.6, J18.8, J18.10, J18.12, J18.14, J18.16, J18.66, J18.68, J18.70, J18.72, J18.74, J18.76; also elsewhere on the board
/UI_10_S3_DISPLAY_TOUCH/AON_SAFE_3V3: J18.17, J18.19; also elsewhere on the board
/UI_10_S3_DISPLAY_TOUCH/ENCODER_A: J18.51; also elsewhere on the board
/UI_10_S3_DISPLAY_TOUCH/ENCODER_B: J18.52; also elsewhere on the board
/UI_10_S3_DISPLAY_TOUCH/POWER_GROUND: J18.1, J18.3, J18.5, J18.7, J18.9, J18.11, J18.13, J18.15, J18.18, J18.20, J18.21, J18.25, J18.28, J18.31, J18.34, J18.40, J18.47, J18.54, J18.65, J18.67, J18.69, J18.71, J18.73, J18.75; also elsewhere on the board
/UI_10_S3_DISPLAY_TOUCH/S3_RESET_KILL_GATE: J18.36; also elsewhere on the board
/UI_10_S3_DISPLAY_TOUCH/S3_USB_N: J18.29; also elsewhere on the board
/UI_10_S3_DISPLAY_TOUCH/S3_USB_P: J18.30; also elsewhere on the board
/UI_11_STORAGE_CONTROLS_INDICATORS/EV_N5_CC: J18.48; also elsewhere on the board
/UI_11_STORAGE_CONTROLS_INDICATORS/EV_N6_VOICE: J18.49; also elsewhere on the board
/UI_11_STORAGE_CONTROLS_INDICATORS/EV_N8_LORA_EXT: J18.50; also elsewhere on the board
/UI_11_STORAGE_CONTROLS_INDICATORS/FAULT_KILL: J18.35; also elsewhere on the board
/UI_11_STORAGE_CONTROLS_INDICATORS/UI_ENCODER_PUSH_N: J18.53; also elsewhere on the board
/UI_11_STORAGE_CONTROLS_INDICATORS/UI_ZONE_TEMP_ADC: J18.39; also elsewhere on the board
/UI_20_C5_WIFI_IR_SERVICE/AON_SERVICE_RELEASE_REQ: J18.57; also elsewhere on the board
/UI_20_C5_WIFI_IR_SERVICE/C5_MUX_SEL_REQUEST: J18.55; also elsewhere on the board
/UI_20_C5_WIFI_IR_SERVICE/C5_SERVICE_OWNED: J18.58; also elsewhere on the board
/UI_20_C5_WIFI_IR_SERVICE/C5_SERVICE_PATH_ACK: J18.56; also elsewhere on the board
/UI_20_C5_WIFI_IR_SERVICE/EV_N1_C5: J18.42; also elsewhere on the board
/UI_20_C5_WIFI_IR_SERVICE/EV_N7_IR: J18.46; also elsewhere on the board
/UI_20_C5_WIFI_IR_SERVICE/FAULT_ASSERT_N: J18.38; also elsewhere on the board
/UI_20_C5_WIFI_IR_SERVICE/RUN_PERMIT: J18.37; also elsewhere on the board
/UI_30_HUB_RP_CORE_SERVICE/HUB_AON_ALERT_N: J18.59; also elsewhere on the board
/UI_30_HUB_RP_CORE_SERVICE/HUB_RF_ALERT_N: J18.22; also elsewhere on the board
/UI_30_HUB_RP_CORE_SERVICE/HUB_RF_CS_N: J18.23; also elsewhere on the board
/UI_30_HUB_RP_CORE_SERVICE/HUB_RF_MISO: J18.27; also elsewhere on the board
/UI_30_HUB_RP_CORE_SERVICE/HUB_RF_MOSI: J18.26; also elsewhere on the board
/UI_30_HUB_RP_CORE_SERVICE/HUB_RF_SCK: J18.24; also elsewhere on the board
/UI_30_HUB_RP_CORE_SERVICE/HUB_SAFE_I2C_SCL_MAIN: J18.33; also elsewhere on the board
/UI_30_HUB_RP_CORE_SERVICE/HUB_SAFE_I2C_SDA_MAIN: J18.32; also elsewhere on the board
/UI_50_FRONT_POWER_SAFETY/EV_N0_S3: J18.41; also elsewhere on the board
/UI_50_FRONT_POWER_SAFETY/EV_N2_NRF0: J18.43; also elsewhere on the board
/UI_50_FRONT_POWER_SAFETY/EV_N3_NRF1: J18.44; also elsewhere on the board
/UI_50_FRONT_POWER_SAFETY/EV_N4_NRF2: J18.45; also elsewhere on the board

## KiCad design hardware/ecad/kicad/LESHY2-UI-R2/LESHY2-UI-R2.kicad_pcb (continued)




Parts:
C80, C81, C83, C84, C85: Yageo CC0402KRX7R9BB104; C_0402_1005Metric
C82: KEMET C0402C102K5RACTU; C_0402_1005Metric
Q6: NX3008NBKS,115; SOT-363_SC-70-6
R208, R211, R212, R216, R220, R224, R226: Yageo RC0402FR-07100KL; R_0402_1005Metric
R209: Yageo RC0402FR-0747KL; R_0402_1005Metric
R210: Yageo RC0402FR-0712KL; R_0402_1005Metric
R213, R217, R221, R225: Yageo RC0402FR-071ML; R_0402_1005Metric
R214, R215, R218, R219, R222, R223, R227: Yageo RC0402FR-0710KL; R_0402_1005Metric
U50, U52: LTC5532ES6#TRMPBF; TSOT-23-6
U51: VEMD1060X01
U53, U54: TLV1824PWR; TSSOP-14_4.4x5mm_P0.65mm
U55: TLV9061IDBVR; SOT-23-5
U56: SN74LVC1G07DCKR; Texas_R-PDSO-G5_DCK-5
U57: Texas Instruments SN74LVC1G06DCKR; Texas_R-PDSO-G5_DCK-5
U58: SN74LVC08APWR; TSSOP-14_4.4x5mm_P0.65mm

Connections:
/UI_10_S3_DISPLAY_TOUCH/3V3_MAIN: R227.1 (END_1); also elsewhere on the board
/UI_10_S3_DISPLAY_TOUCH/AON_SAFE_3V3: C80.1 (END_1), C81.1 (END_1), C83.1 (END_1), C84.1 (END_1), C85.1 (END_1), R208.1 (END_1), R211.1 (END_1), R212.1 (END_1), R214.1 (END_1), R216.1 (END_1), R218.1 (END_1), R220.1 (END_1), R222.1 (END_1), R224.1 (END_1), R226.1 (END_1), U50.6 (VCC), U52.6 (VCC), U53.3 (VPLUS), U54.3 (VPLUS), U55.5 (V_PLUS), U56.5 (VCC), U57.5 (VCC), U58.14 (VCC); also elsewhere on the board
/UI_10_S3_DISPLAY_TOUCH/POWER_GROUND: C80.2 (END_2), C81.2 (END_2), C83.2 (END_2), C84.2 (END_2), C85.2 (END_2), Q6.1 (S1), Q6.4 (S2), R210.2 (END_2), R215.2 (END_2), R219.2 (END_2), R223.2 (END_2), U50.2 (GND), U50.3 (VOS), U51.1 (ANODE), U52.2 (GND), U52.3 (VOS), U53.10 (IN4_N), U53.11 (IN4_P), U53.12 (VMINUS), U54.10 (IN4_N), U54.11 (IN4_P), U54.12 (VMINUS), U55.2 (V_MINUS), U56.3 (GND), U57.3 (GND), U58.7 (GND); also elsewhere on the board
/UI_10_S3_DISPLAY_TOUCH/S3_DETECT_V: U52.5 (VOUT), U53.4 (IN1_N); also elsewhere on the board
/UI_10_S3_DISPLAY_TOUCH/S3_DETECT_VM: U52.4 (VM); also elsewhere on the board
/UI_10_S3_DISPLAY_TOUCH/S3_FORWARD_RF_SAMPLE: U52.1 (RFIN); also elsewhere on the board
/UI_10_S3_DISPLAY_TOUCH/S3_RESET_KILL_GATE: Q6.5 (G2); also elsewhere on the board
/UI_10_S3_DISPLAY_TOUCH/S3_RESET_N: Q6.3 (D2); also elsewhere on the board
/UI_20_C5_WIFI_IR_SERVICE/C5_DETECT_V: U50.5 (VOUT), U53.6 (IN2_N); also elsewhere on the board
/UI_20_C5_WIFI_IR_SERVICE/C5_DETECT_VM: U50.4 (VM); also elsewhere on the board
/UI_20_C5_WIFI_IR_SERVICE/C5_FORWARD_RF_SAMPLE: U50.1 (RFIN); also elsewhere on the board
/UI_20_C5_WIFI_IR_SERVICE/C5_RESET_N: Q6.6 (D1), U56.4 (Y); also elsewhere on the board
/UI_20_C5_WIFI_IR_SERVICE/EV_N1_C5: U53.1 (OUT2); also elsewhere on the board
/UI_20_C5_WIFI_IR_SERVICE/EV_N7_IR: U53.14 (OUT3); also elsewhere on the board
/UI_20_C5_WIFI_IR_SERVICE/EV_THRESH_1_C5: R208.2 (END_2), U53.7 (IN2_P); also elsewhere on the board
/UI_20_C5_WIFI_IR_SERVICE/FAULT_ASSERT_N: U56.2 (A); also elsewhere on the board
/UI_20_C5_WIFI_IR_SERVICE/IR_EVIDENCE_VREF: R212.2 (END_2), U55.3 (IN_PLUS); also elsewhere on the board
/UI_20_C5_WIFI_IR_SERVICE/RUN_PERMIT: U57.2 (A), U58.2 (1B), U58.5 (2B), U58.10 (3B), U58.13 (4B); also elsewhere on the board
/UI_30_HUB_RP_CORE_SERVICE/NRF0_CE_REQ: U58.1 (1A); also elsewhere on the board
/UI_30_HUB_RP_CORE_SERVICE/NRF1_CE_REQ: U58.4 (2A); also elsewhere on the board
/UI_30_HUB_RP_CORE_SERVICE/NRF2_CE_REQ: U58.9 (3A); also elsewhere on the board
/UI_30_HUB_RP_CORE_SERVICE/NRF_GROUP_PWR_EN: U58.12 (4A); also elsewhere on the board
/UI_31_NRF24_X3_TX_EVIDENCE/NRF0_CE_SAFE: U58.3 (1Y); also elsewhere on the board
/UI_31_NRF24_X3_TX_EVIDENCE/NRF0_DETECT_V: U54.4 (IN1_N); also elsewhere on the board
/UI_31_NRF24_X3_TX_EVIDENCE/NRF1_CE_SAFE: U58.6 (2Y); also elsewhere on the board
/UI_31_NRF24_X3_TX_EVIDENCE/NRF1_DETECT_V: U54.6 (IN2_N); also elsewhere on the board
/UI_31_NRF24_X3_TX_EVIDENCE/NRF2_CE_SAFE: U58.8 (3Y); also elsewhere on the board
/UI_31_NRF24_X3_TX_EVIDENCE/NRF2_DETECT_V: U54.8 (IN3_N); also elsewhere on the board
/UI_31_NRF24_X3_TX_EVIDENCE/NRF_GROUP_PWR_EN_PRIMARY: U58.11 (4Y); also elsewhere on the board
/UI_50_FRONT_POWER_SAFETY/C5_RESET_KILL_GATE: Q6.2 (G1), R227.2 (END_2), U57.4 (Y); also elsewhere on the board
/UI_50_FRONT_POWER_SAFETY/EV_N0_S3: R225.1 (END_1), U53.2 (OUT1); also elsewhere on the board
/UI_50_FRONT_POWER_SAFETY/EV_N2_NRF0: R213.1 (END_1), R214.2 (END_2), U54.2 (OUT1); also elsewhere on the board
/UI_50_FRONT_POWER_SAFETY/EV_N3_NRF1: R217.1 (END_1), R218.2 (END_2), U54.1 (OUT2); also elsewhere on the board
/UI_50_FRONT_POWER_SAFETY/EV_N4_NRF2: R221.1 (END_1), R222.2 (END_2), U54.14 (OUT3); also elsewhere on the board
/UI_50_FRONT_POWER_SAFETY/EV_THRESH_0_S3: R225.2 (END_2), R226.2 (END_2), U53.5 (IN1_P); also elsewhere on the board
/UI_50_FRONT_POWER_SAFETY/EV_THRESH_2_NRF0: R213.2 (END_2), R215.1 (END_1), R216.2 (END_2), U54.5 (IN1_P)
/UI_50_FRONT_POWER_SAFETY/EV_THRESH_3_NRF1: R217.2 (END_2), R219.1 (END_1), R220.2 (END_2), U54.7 (IN2_P)
/UI_50_FRONT_POWER_SAFETY/EV_THRESH_4_NRF2: R221.2 (END_2), R223.1 (END_1), R224.2 (END_2), U54.9 (IN3_P)
/UI_50_FRONT_POWER_SAFETY/EV_THRESH_7_IR: R210.1 (END_1), R211.2 (END_2), U53.9 (IN3_P); also elsewhere on the board
/UI_50_FRONT_POWER_SAFETY/IR_DETECT_V: C82.1 (END_1), R209.1 (END_1), U53.8 (IN3_N), U55.1 (OUT)
/UI_50_FRONT_POWER_SAFETY/IR_OPTICAL_SUM: C82.2 (END_2), R209.2 (END_2), U51.2 (CATHODE), U55.4 (IN_MINUS)



Board: 6 copper layers, 80.0 x 150.0 mm, 434 parts (400 on the bottom side), 307 nets.

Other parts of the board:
MH1, MH2, MH3, MH4: M2.5 compression-stop axis; MountingHole_2.7mm_M2.5

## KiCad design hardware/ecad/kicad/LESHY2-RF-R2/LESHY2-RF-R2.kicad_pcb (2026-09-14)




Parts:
C1, C2, C5, C6, C7, C11, C12, C13, C14, C15, C17, C18: Murata GRM31CR71E106MA12L; C_1206_3216Metric
C3, C4: Murata GRM155R71E473KA88D; C_0402_1005Metric
C8, C16, C19, C22: Yageo CC0402KRX7R9BB104; C_0402_1005Metric
C9, C29: TDK CGA5L1X7R1E475K160AC; C_1206_3216Metric
C10: KEMET C0402C102K5RACTU; C_0402_1005Metric
C20, C21: Murata GRM1555C1H221JA01D; C_0402_1005Metric
C23, C24, C30: Murata GRM188R60J106ME47D; C_0603_1608Metric
C25, C26, C27, C28: Murata GRM32ER71E226KE15L; C_1210_3225Metric
C31: Yageo CC0603KRX7R0BB104; C_0603_1608Metric
C32: TDK C1608X7R1C105K080AC; C_0603_1608Metric
J1: GCT USB4105-GF-A; USB_C_Receptacle_GCT_USB4105-xx-A_16P_TopMnt_Horizontal
L1: Sunlord MWSA0503S-2R2MT; L_Sunlord_MWSA0503S
R1: Yageo RC0402FR-07100RL; R_0402_1005Metric
R2, R5, R10, R13: Yageo RC0402FR-0710KL; R_0402_1005Metric
R3: Yageo RC0402FR-07100KL; R_0402_1005Metric
R4: Yageo RC0402FR-0744K2L; R_0402_1005Metric
R6: UNI-ROYAL 0402WGF8201TCE; R_0402_1005Metric
R7: Yageo RC0402FR-0730K1L; R_0402_1005Metric
R8: TDK B57332V5103F360; R_0603_1608Metric
R9: UNI-ROYAL 0402WGF5231TCE; R_0402_1005Metric
R11, R12: UNI-ROYAL 0402WGF2201TCE; R_0402_1005Metric
U1: Texas Instruments BQ25798RQMR; Texas_RQM0029A_VQFN-29_4x4mm_P0.4mm
U2: onsemi CAT24C512WI-GT3; SOIC-8_3.9x4.9mm_P1.27mm
U3: Texas Instruments TPS25751DREFR; Texas_REF0038A_WQFN-38-2EP_6x4mm_P0.4
U4: Texas Instruments TVS2200DRVR; WSON-6-1EP_2x2mm_P0.65mm_EP1x1.6mm
U5: Texas Instruments TPD4S201RUKR; Texas_RUK0020B_WQFN-20-1EP_3x3mm_P0.4mm_EP1.7x1.7mm
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

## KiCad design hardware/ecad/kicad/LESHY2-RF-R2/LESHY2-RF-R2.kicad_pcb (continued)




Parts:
BT1: Keystone Electronics 1048P; Keystone-1048P-POLARITY-CORRECTED
C33, C35: Samsung CL05B104KO5NNNC; C_0402_1005Metric
C34, C36: Samsung CL05A105KA5NQNC; C_0402_1005Metric
C37: Murata GRM188R60J106ME47D; C_0603_1608Metric
C38, C41, C42, C43, C46, C48, C49: Yageo CC0402KRX7R9BB104; C_0402_1005Metric
C39, C50, C53: Murata GRM155R71H103KA88D; C_0402_1005Metric
C40, C44, C51, C52: Murata GRM188R71E474KA12D; C_0603_1608Metric
C45: TDK C1608X7R1C105K080AC; C_0603_1608Metric
C47: Murata GRM31C5C1H224JE02L; C_1206_3216Metric
F1, F2: Littelfuse 0451005.MRL; 0451005.MRL
J2: Samtec FTSH-105-01-L-DV-K-P-TR; FTSH-105-01-L-DV-K-P-TR
Q1: Diodes Incorporated DMN2056U-7; SOT-23
Q2, Q3: Diodes Incorporated 2N7002DW-7-F; SOT-363_SC-70-6
R14: Yageo RC0402FR-0747KL; R_0402_1005Metric
R15, R18, R23, R24, R25, R26, R27, R29, R36: Yageo RC0402FR-0710KL; R_0402_1005Metric
R16, R17: Panasonic ERJ-P08F49R9V; R_1206_3216Metric
R19: Yageo RC0402FR-07620KL; R_0402_1005Metric
R20, R21: Bourns CRM2512-FX-20R0ELF; R_2512_6332Metric
R22, R30, R38: Yageo RC0402FR-07169KL; R_0402_1005Metric
R28: Panasonic ERJ-P08F10R0V; R_1206_3216Metric
R31, R32, R39, R40, R41, R42, R43: Yageo RC0402FR-07220KL; R_0402_1005Metric
R33, R34: TDK B57332V5103F360; R_0603_1608Metric
R35: Yageo RC0402FR-071KL; R_0402_1005Metric
R37: Vishay WSL25125L000FEA; R_2512_6332Metric
U6: TCA9803DGKR; VSSOP-8_3x3mm_P0.65mm
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

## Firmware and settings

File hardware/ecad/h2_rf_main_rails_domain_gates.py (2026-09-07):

#!/usr/bin/env python3
"""Generate and verify the exact H2.3.4 main rails and domain-gates sheet."""

from __future__ import annotations

import argparse
import json
import re
import subprocess
from collections import Counter, defaultdict
from pathlib import Path

from h2_legacy_device_basis import (
    load_historical_devices, require_historical_check,
    source_sha256 as sha256, verify_historical_scope,
)

from h2_symbol_library import build as build_symbol_library
from h2_ui_s3_core import ScopedReferenceCounter
from h2_ui_audio_codec_headset import endpoint_nets
from h2_ui_display_touch_storage import pin_net
from h2_ui_s3_core import (
    Pin,
    custom_footprint,
    effects,
    escaped,
    library_symbol,
    schematic_symbol,
    stable_uuid,
)


REPO = Path(__file__).resolve().parents[2]
ECAD = REPO / "hardware/ecad"
CANDIDATE_PATH = REPO / "hardware/architecture/candidates/G2F-3I.json"
DEVICES_PATH = REPO / "hardware/architecture/devices.json"
LEDGER_PATH = ECAD / "generated/H2-instance-ledger.json"
ROOT_INTERFACE_PATH = ECAD / "generated/H2-RF-root-interface.json"
SHEET_ID = "RF_03_MAIN_RAILS_DOMAIN_GATES"
PROJECT_ID = "LESHY2-RF"
PROJECT_DIR = ECAD / f"kicad/{PROJECT_ID}"
OUTPUT_SCH = PROJECT_DIR / f"{SHEET_ID}.kicad_sch"
OUTPUT_MANIFEST = ECAD / "generated/H2-RF03-main-rails-domain-gates.json"
SYMBOL_LIBRARY = ECAD / "libraries/leshy2.kicad_sym"
FOOTPRINT_DIR = ECAD / "libraries/Leshy2.pretty"
SYMBOL_NAMESPACE = "RF03"


def pins_for(instance: str, device: dict) -> list[Pin]:
    passive = {"END_1": "1", "END_2": "2"}
    pins = []
    for contact, row in device["contacts"].items():
        number = passive.get(contact)
        if number is None:
            match = re.match(r"^(?:termination\s+)?(\d+)", str(row.get("physical", "")))
            if not match:
                raise ValueError(f"no physical contact number for {instance}.{contact}")
            number = match.group(1)
        pins.append(Pin(number, contact, contact))
    numbers = [pin.number for pin in pins]
    if len(numbers) != len(set(numbers)):
        raise ValueError(f"duplicate physical contact numbers in {instance}: {numbers}")
    return pins


def footprint_for(instance: str, device_key: str) -> str:
    exact = {
        "ext_request_or": "Package_TO_SOT_SMD:SC-74A-5_1.55x2.9mm_P0.95mm",
        "ext_branch_gate": "Package_SO:VSSOP-8_2.3x2mm_P0.5mm",
        "aon_buck": "Leshy2:TI-DRL0008A-SOT-5X3-8",
        "aon_inductor": "Inductor_SMD:L_Murata_LQH2MCNxxxx02_2.0x1.6mm",
        "aon_efuse": "Package_SON:WSON-6-1EP_2x2mm_P0.65mm_EP1x1.6mm",
        "main_buck": "Package_TO_SOT_SMD:Texas_R-PDSO-N6_DRL-6",
        "main_inductor": "Inductor_SMD:L_Sunlord_MWSA0503S",
        "main_efuse": "Leshy2:TI-RPW0010A-VQFN-HR-10",
        "ext_buck": "Package_TO_SOT_SMD:Texas_R-PDSO-N6_DRL-6",
        "ext_inductor": "Inductor_SMD:L_Sunlord_MWSA0503S",
        "ext_pg_qualifier": "Package_TO_SOT_SMD:SOT-23",
        "ext_efuse": "Leshy2:TI-RPW0010A-VQFN-HR-10",
        "ext_evidence_buffer": "Package_TO_SOT_SMD:Texas_R-PDSO-G5_DCK-5",
    }
    if instance in exact:
        return exact[instance]
    if device_key == "tdk_b57332v5103f360":
        return "Resistor_SMD:R_0603_1608Metric"
    if device_key in {"murata_grm32er71e226ke15l"}:
        return "Capacitor_SMD:C_1210_3225Metric"
    if device_key in {"tdk_cga5l1x7r1e475k160ac", "murata_grm31cr71a226ke15l"}:
        return "Capacitor_SMD:C_1206_3216Metric"
    if device_key in {"murata_grm21br71e225ke11l"}:
        return "Capacitor_SMD:C_0805_2012Metric"
    if device_key.startswith(("tdk_c1005", "yageo_cc0402", "murata_grm155", "kemet_c0402")):
        return "Capacitor_SMD:C_0402_1005Metric"
    if device_key.startswith("murata_grm188"):
        return "Capacitor_SMD:C_0603_1608Metric"
    if device_key.startswith(("yageo_rc0402", "uniroyal_0402wgf", "yageo_rt0402", "vishay_tnpw0402")):
        return "Resistor_SMD:R_0402_1005Metric"
    if device_key.startswith("yageo_rc0603"):
        return "Resistor_SMD:R_0603_1608Metric"
    raise ValueError(f"no exact footprint mapping for {instance}/{device_key}")


def reference_prefix(instance: str, device_key: str) -> str:
    if "inductor" in instance:
        return "L"
    if device_key == "tdk_b57332v5103f360":
        return "RT"
    if device_key.startswith(("tdk_c", "yageo_cc", "murata_grm", "kemet_c")):
        return "C"
    if device_key.startswith(("yageo_rc", "uniroyal_0402wgf", "yageo_rt", "vishay_tnpw")):
        return "R"
    if device_key == "diodes_mmbt3904_7_f":
        return "Q"
    return "U"


def footprint_outputs() -> dict[Path, str]:
    copper = ("F.Cu", "F.Paste", "F.Mask")

    # TI MPCS002G DRL0008A package outline: 8 contacts, 0.5-mm pitch,
    # 1.1-1.3 x 1.5-1.7-mm body and 0.6-mm maximum height.  The H6 land-pattern
    # pass still owns paste segmentation and density-class selection.
    drl_pads = []
    for index in range(4):
        y = -0.75 + index * 0.50
        drl_pads.append((str(index + 1), -0.85, y, 0.60, 0.25, copper, "rect"))
        drl_pads.append((str(8 - index), 0.85, y, 0.60, 0.25, copper, "rect"))
    drl = custom_footprint(
        "TI-DRL0008A-SOT-5X3-8", drl_pads, 1.30, 1.70, 2.00, 2.10,
        "TI MPCS002G DRL0008A package-contact pattern: eight 0.5-mm-pitch contacts and 1.3x1.7-mm maximum body; final IPC density and paste rules close in H6",
    )

    # Literal transcription of TI 4225183/A.  The four corner power contacts
    # are L-shaped; flattening them into oversized rectangles both violated the
    # fab clearance and inverted the physical pin order in the early H2 seed.
    rpw = "\n".join([
        '(footprint "TI-RPW0010A-VQFN-HR-10"',
        '\t(version 20260206)',
        '\t(generator "leshy2-h2-rf03")',
        '\t(generator_version "1.0")',
        '\t(layer "F.Cu")',
        '\t(descr "TI 4225183/A RPW0010A recommended PCB layout: ten distinct HotRod lands, including four L-shaped corner power lands; cross-checked against verified JLC/LCSC C3662793 CAD")',
        '\t(property "Reference" "REF**" (at 0 -4 0) (layer "F.SilkS") (effects (font (size 1 1) (thickness 0.15))))',
        '\t(property "Value" "TI-RPW0010A-VQFN-HR-10" (at 0 4 0) (layer "F.Fab") (effects (font (size 1 1) (thickness 0.15))))',
        '\t(attr smd)',
        '\t(fp_rect (start -1.050 -1.050) (end 1.050 1.050) (stroke (width 0.10) (type default)) (fill none) (layer "F.Fab"))',
        '\t(fp_rect (start -1.250 -1.250) (end 1.250 1.250) (stroke (width 0.05) (type default)) (fill none) (layer "F.CrtYd"))',
        '\t(pad "1" smd custom (at -0.725 -0.750) (size 0.25 0.25) (layers "F.Cu" "F.Paste" "F.Mask") (options (clearance outline) (anchor rect)) (primitives (gr_poly (pts (xy -0.125 -0.450) (xy 0.125 -0.450) (xy 0.125 0.150) (xy -0.475 0.150) (xy -0.475 -0.150) (xy -0.125 -0.150)) (width 0) (fill yes))))',
        '\t(pad "2" smd roundrect (at -0.900 -0.225) (size 0.600 0.250) (layers "F.Cu" "F.Paste" "F.Mask") (roundrect_rratio 0.20))',
        '\t(pad "3" smd roundrect (at -0.900 0.225) (size 0.600 0.250) (layers "F.Cu" "F.Paste" "F.Mask") (roundrect_rratio 0.20))',
        '\t(pad "4" smd custom (at -0.725 0.750) (size 0.25 0.25) (layers "F.Cu" "F.Paste" "F.Mask") (options (clearance outline) (anchor rect)) (primitives (gr_poly (pts (xy -0.475 -0.150) (xy 0.125 -0.150) (xy 0.125 0.450) (xy -0.125 0.450) (xy -0.125 0.150) (xy -0.475 0.150)) (width 0) (fill yes))))',
        '\t(pad "5" smd roundrect (at -0.250 0) (size 0.300 2.400) (layers "F.Cu" "F.Paste" "F.Mask") (roundrect_rratio 0.16))',
        '\t(pad "6" smd roundrect (at 0.250 0) (size 0.300 2.400) (layers "F.Cu" "F.Paste" "F.Mask") (roundrect_rratio 0.16))',
        '\t(pad "7" smd custom (at 0.725 0.750) (size 0.25 0.25) (layers "F.Cu" "F.Paste" "F.Mask") (options (clearance outline) (anchor rect)) (primitives (gr_poly (pts (xy -0.125 -0.150) (xy 0.475 -0.150) (xy 0.475 0.150) (xy 0.125 0.150) (xy 0.125 0.450) (xy -0.125 0.450)) (width 0) (fill yes))))',
        '\t(pad "8" smd roundrect (at 0.900 0.225) (size 0.600 0.250) (layers "F.Cu" "F.Paste" "F.Mask") (roundrect_rratio 0.20))',
        '\t(pad "9" smd roundrect (at 0.900 -0.225) (size 0.600 0.250) (layers "F.Cu" "F.Paste" "F.Mask") (roundrect_rratio 0.20))',
        '\t(pad "10" smd custom (at 0.725 -0.750) (size 0.25 0.25) (layers "F.Cu" "F.Paste" "F.Mask") (options (clearance outline) (anchor rect)) (primitives (gr_poly (pts (xy -0.125 -0.450) (xy 0.125 -0.450) (xy 0.125 -0.150) (xy 0.475 -0.150) (xy 0.475 0.150) (xy -0.125 0.150)) (width 0) (fill yes))))',
        ')',
        '',
    ])
    return {
        FOOTPRINT_DIR / "TI-DRL0008A-SOT-5X3-8.kicad_mod": drl,
        FOOTPRINT_DIR / "TI-RPW0010A-VQFN-HR-10.kicad_mod": rpw,
    }


def build() -> tuple[dict[Path, str], dict]:
    candidate = json.loads(CANDIDATE_PATH.read_text(encoding="utf-8"))
    devices = load_historical_devices()
    ledger = json.loads(LEDGER_PATH.read_text(encoding="utf-8"))
    root = json.loads(ROOT_INTERFACE_PATH.read_text(encoding="utf-8"))
    rows = [
        row for row in ledger["rows"]
        if row["project"] == PROJECT_ID and row["sheet"] == SHEET_ID
    ]
    if len(rows) != 69:
        raise ValueError(f"{SHEET_ID} must own exactly 69 rows, got {len(rows)}")
    interface_order = list(next(
        row["interfaces"] for row in root["sheets"] if row["id"] == SHEET_ID
    ))
    interfaces = set(interface_order)
    local_instances = {row["instance"] for row in rows}
    endpoints, aliases, no_connect_nets = endpoint_nets(
        candidate, local_instances, interface_order
    )

    specs = []
    ref_counts: Counter[str] = ScopedReferenceCounter(SHEET_ID)
    for row in rows:
        prefix = reference_prefix(row["instance"], row["device_key"])
        ref_counts[prefix] += 1
        specs.append({
            "instance": row["instance"], "device_key": row["device_key"],
            "mpn": row["mpn"], "role": row["role"],
            "pins": pins_for(row["instance"], devices[row["device_key"]]),
            "reference": f"{prefix}{ref_counts[prefix]}",
            "footprint": footprint_for(row["instance"], row["device_key"]),
        })

    library_defs = []
    placements = {}
    column_x = [50.80, 132.08, 213.36, 294.64, 375.92, 457.20, 538.48]
    cursor_y = [40.64] * len(column_x)
    for spec in specs:
        lib, coords, height = library_symbol(
            spec["instance"], spec["pins"], spec["reference"].rstrip("0123456789") or "X",
            spec["footprint"], spec["role"], True, True, True, SYMBOL_NAMESPACE,
        )
        library_defs.append(lib)
        column = min(range(len(cursor_y)), key=lambda item: cursor_y[item])
        x = column_x[column]
        target_y = cursor_y[column] + height / 2
        remainder = next(iter(coords.values()))[1] % 2.54
        y = round((target_y - remainder) / 2.54) * 2.54 + remainder
        cursor_y[column] = y + height / 2 + 15.24
        placements[spec["instance"]] = (x, y, coords)

    lines = [
        "(kicad_sch", "\t(version 20250114)", '\t(generator "eeschema")',
        '\t(generator_version "10.0")', f'\t(uuid "{stable_uuid(f"sheet:{SHEET_ID}")}")',
        '\t(paper "A0")', "\t(title_block",
        '\t\t(title "Leshy2 — exact independent rails, eFuses and accessory gates")',
        '\t\t(rev "H2.3.4")', "\t)", "\t(lib_symbols", *library_defs, "\t)",
    ]
    net_endpoints: dict[str, list[tuple[str, Pin, float, float, str]]] = defaultdict(list)
    for spec in specs:
        x, y, coords = placements[spec["instance"]]
        lines.append(schematic_symbol(
            spec["instance"], spec["pins"], spec["reference"], spec["mpn"],
            spec["footprint"], spec["role"], x, y, coords, True, True,
            SYMBOL_NAMESPACE, PROJECT_ID, SHEET_ID,
        ))
        for pin in spec["pins"]:
            net = pin_net(spec["instance"], pin, endpoints, no_connect_nets)
            px, py, side = coords[pin.number]
            net_endpoints[net].append((spec["instance"], pin, x + px, y - py, side))

    hierarchy_used: set[str] = set()
    no_connect_endpoints = []
    for net, points in sorted(net_endpoints.items()):
        for instance, pin, x, y, side in points:
            if net == "NO_CONNECT":
                lines += [
                    f"\t(no_connect (at {x:.2f} {y:.2f})",
                    f'\t\t(uuid "{stable_uuid(f"nc:{instance}:{pin.number}")}")', "\t)",
                ]
                no_connect_endpoints.append(f"{instance}.{pin.contact}")
                continue
            hierarchical = net in interfaces and net not in hierarchy_used
            if hierarchical:
                hierarchy_used.add(net)
            angle = 0 if side == "left" else 180
            justify = None if side == "left" else "right bottom"
            token = "hierarchical_label" if hierarchical else "label"
            shape = "\n\t\t(shape bidirectional)" if hierarchical else ""
            lines += [
                f'\t({token} "{escaped(net)}"{shape}',
                f"\t\t(at {x:.2f} {y:.2f} {angle})", f"\t\t{effects(justify)}",
                f'\t\t(uuid "{stable_uuid(f"label:{instance}:{pin.number}:{net}")}")', "\t)",
            ]
    if hierarchy_used != interfaces:
        raise ValueError(f"RF03 does not terminate interfaces: {sorted(interfaces - hierarchy_used)}")

    deferred_fixture_endpoints = ["main_buck.PG"]
    deferred_fixture_labels = []
    for endpoint in deferred_fixture_endpoints:
        instance, contact = endpoint.split(".", 1)
        spec = next(row for row in specs if row["instance"] == instance)
        pin = next(row for row in spec["pins"] if row.contact == contact)
        net = endpoints[(instance, contact)]
        if net not in interfaces:
            deferred_fixture_labels.append({
                "endpoint": endpoint, "net": net,
                "label_uuid": stable_uuid(f"label:{instance}:{pin.number}:{net}"),
            })

    lines += [
        "\t(sheet_instances", '\t\t(path "/"', '\t\t\t(page "1")', "\t\t)", "\t)",
        "\t(embedded_fonts no)", ")", "",
    ]
    schematic = "\n".join(lines)
    generated = {OUTPUT_SCH: schematic, **footprint_outputs()}
    generated[SYMBOL_LIBRARY] = build_symbol_library({OUTPUT_SCH: schematic})
    manifest = {
        "schema_version": 1, "stage": "H2.3.4",
        "status": "reviewed_exact_main_rails_domain_gates_sheet",
        "authority": {"baseline": "R1", "lifecycle": "historical_pre_r2_sheet_scaffold", "allowed_as_r2_authority": False, "superseded_by": "hardware/architecture/h0-r2-rebaseline.json"},
        "project": PROJECT_ID, "sheet": SHEET_ID,
        "source_hashes": {
            str(path.relative_to(REPO)): sha256(path)
            for path in (CANDIDATE_PATH, DEVICES_PATH, LEDGER_PATH, ROOT_INTERFACE_PATH)
        },
        "summary": {
            "ledger_instances": len(rows), "schematic_symbols": len(specs),
            "board_fitted_symbols": len(specs),
            "hierarchical_interfaces": len(interfaces),
            "physical_package_contacts": sum(len(spec["pins"]) for spec in specs),
            "aon_buck_package_pins": len(next(spec for spec in specs if spec["instance"] == "aon_buck")["pins"]),
            "aon_efuse_package_pads": len(next(spec for spec in specs if spec["instance"] == "aon_efuse")["pins"]),
            "main_efuse_package_pads": len(next(spec for spec in specs if spec["instance"] == "main_efuse")["pins"]),
            "external_efuse_package_pads": len(next(spec for spec in specs if spec["instance"] == "ext_efuse")["pins"]),
            "independent_switchmode_domains": 3,
            "intentional_no_connect_pins": len(no_connect_endpoints),
            "custom_package_contact_footprints": 2,
            "pcb_files_created": 0,
        },
        "instances": [
            {
                "instance": spec["instance"],
                "symbol_uuid": stable_uuid(f"symbol:{spec['instance']}"),
                "reference": spec["reference"], "mpn": spec["mpn"],
                "footprint": spec["footprint"], "pin_count": len(spec["pins"]),
                "board_fitted": True,
            }
            for spec in specs
        ],
        "physical_net_aliases_collapsed": {
            alias: canonical for alias, canonical in sorted(aliases.items()) if alias != canonical
        },
        "intentional_no_connect_endpoints": sorted(no_connect_endpoints),
        "known_deferred_fixture_labels": deferred_fixture_labels,
        "review_boundary": {
            "complete": [
                "all 69 RF03 ledger instances and all 186 physical package contacts are explicit",
                "AON, main and accessory converters have independent inductors, feedback, bypass and post-protection",
                "AON eFuse exposed pad is explicit and both HotRod eFuses expose all ten real package contacts",
                "TPS259470 AUXOFF is correctly treated as an unused open-drain output rather than a fast-off input",
                "main PG and all qualified accessory current, thermal and voltage faults share one POWER_FAULT_N aggregate",
                "all twenty-two hierarchy interfaces and three intentional no-connect contacts are explicit",
            ],
            "deferred": [
                "the single raw main-converter PG diagnostic pad is instantiated by RF60",
                "final DRL/RPW copper density, shaped HotRod lands, paste segmentation and DRC close in H6",
                "rail efficiency, transient response, current-limit tolerance, thermal trip and source handover close in H3/H8",
                "exact converter startup order and fault messages close in firmware/virtual/HIL phases",
            ],
        },
    }
    generated[OUTPUT_MANIFEST] = json.dumps(manifest, indent=2, ensure_ascii=False) + "\n"
    return generated, manifest


def structural_check(generated: dict[Path, str], manifest: dict) -> None:
    expected = {
        "ledger_instances": 69, "schematic_symbols": 69,
        "board_fitted_symbols": 69, "hierarchical_interfaces": 22,
        "physical_package_contacts": 186, "aon_buck_package_pins": 8,
        "aon_efuse_package_pads": 7, "main_efuse_package_pads": 10,
        "external_efuse_package_pads": 10, "independent_switchmode_domains": 3,
        "intentional_no_connect_pins": 3, "custom_package_contact_footprints": 2,
        "pcb_files_created": 0,
    }
    if manifest["summary"] != expected:
        raise ValueError(f"H2.3.4 accounting drifted: {manifest['summary']}")
    schematic = generated[OUTPUT_SCH]
    if schematic.count("\n\t(symbol\n") != 69:
        raise ValueError("RF03 symbol accounting mismatch")
    if schematic.count("\n\t(hierarchical_label \"") != 22:
        raise ValueError("RF03 hierarchy accounting mismatch")
    expected_nc = {"aon_buck.FB_VSET", "ext_efuse.AUXOFF", "ext_evidence_buffer.NC"}
    if set(manifest["intentional_no_connect_endpoints"]) != expected_nc:
        raise ValueError(f"RF03 no-connect set drifted: {manifest['intentional_no_connect_endpoints']}")
    if manifest["known_deferred_fixture_labels"]:
        raise ValueError("RF03 deferred fixture-boundary set drifted")
    for row in manifest["instances"]:
        if not row["footprint"]:
            raise ValueError(f"fitted RF03 component lacks footprint: {row['instance']}")


def kicad_check() -> None:
    result = subprocess.run(
        ["python3", str(ECAD / "h2_rf_root.py"), "--check", "--kicad-check"],
        cwd=REPO, text=True, capture_output=True,
    )
    if result.returncode:
        raise RuntimeError(f"KiCad rejected RF03 hierarchy:\n{result.stdout}{result.stderr}")
    print("ok: KiCad parsed H2.3.4 and the live RF/power hierarchy")


def main() -> int:
    parser = argparse.ArgumentParser()
    mode = parser.add_mutually_exclusive_group(required=True)
    mode.add_argument("--write", action="store_true")
    mode.add_argument("--check", action="store_true")
    parser.add_argument("--kicad-check", action="store_true")
    args = parser.parse_args()
    require_historical_check(parser, args)
    generated, manifest = build()
    verify_historical_scope(manifest)
    structural_check(generated, manifest)
    if args.write:
        for path, content in generated.items():
            path.parent.mkdir(parents=True, exist_ok=True)
            path.write_text(content, encoding="utf-8")
            print(f"wrote {path.relative_to(REPO)}")
        root = subprocess.run(
            ["python3", str(ECAD / "h2_rf_root.py"), "--write"],
            cwd=REPO, text=True, capture_output=True,
        )
        if root.returncode:
            raise RuntimeError(f"failed to refresh RF/power hierarchy:\n{root.stdout}{root.stderr}")
        print(root.stdout, end="")
    else:
        stale = [
            path for path, content in generated.items()
            if not path.is_file() or path.read_text(encoding="utf-8") != content
        ]
        if stale:
            for path in stale:
                print(f"stale: {path.relative_to(REPO)}")
            return 1
        print("ok: H2.3.4 main rails and domain gates sheet reproduces its historical R1 input (not current R2 evidence)")
    if args.kicad_check:
        kicad_check()
    return 0


if __name__ == "__main__":
    raise SystemExit(main())

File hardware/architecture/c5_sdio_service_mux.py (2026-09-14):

#!/usr/bin/env python3
"""Validate and render the scoped C5 service-USB / four-bit-SDIO mux contract."""

from __future__ import annotations

import argparse
import importlib.util
import json
import math
from pathlib import Path


REPO = Path(__file__).resolve().parents[2]
CONTRACT = REPO / "hardware/architecture/c5-sdio-service-mux-contract.json"
DEVICES = REPO / "hardware/architecture/devices.json"
H0 = REPO / "hardware/architecture/h0-r2-rebaseline.json"
OUTPUT = REPO / "hardware/architecture/generated/H0-R2-c5-sdio-service-mux.json"
CONTROL_MODEL = REPO / "hardware/verification/c5_mux_control_candidate.py"


EXPECTED_C5_SIGNALS = {
    "SDIO_DAT1": ("GPIO7", 9),
    "SDIO_DAT0": ("GPIO8", 10),
    "SDIO_CLK": ("GPIO9", 11),
    "SDIO_CMD": ("GPIO10", 12),
    "SDIO_DAT3_USB_DM": ("GPIO13", 13),
    "SDIO_DAT2_USB_DP": ("GPIO14", 14),
}
EXPECTED_MUX_PINS = {
    1: ("1D+", "C5_SERVICE_USB_DP_BRANCH"),
    2: ("1D-", "C5_SERVICE_USB_DM_BRANCH"),
    3: ("2D+", "HUB_C5_SDIO_DAT2_BRANCH"),
    4: ("2D-", "HUB_C5_SDIO_DAT3_BRANCH"),
    5: ("GND", "POWER_GROUND"),
    6: ("OE", "C5_MUX_DISABLE"),
    7: ("D-", "C5_GPIO13_COMMON"),
    8: ("D+", "C5_GPIO14_COMMON"),
    9: ("S", "C5_MUX_SEL_REQUEST"),
    10: ("VCC", "3V3_MAIN"),
}
EXPECTED_INPUTS = {
    "O": ("C5_SERVICE_OWNED", "c5_service_owner_latch.Q"),
    "R": ("C5_MUX_SEL_REQUEST", "evidence_mask.P12"),
    "A": ("C5_SERVICE_PATH_ACK", "evidence_mask.P13"),
    "L": ("AON_SERVICE_RELEASE_REQ", "evidence_mask.P14"),
    "P": ("RUN_PERMIT", None), "F": ("FAULT_ASSERT_N", None),
}
EXPECTED_EQUATIONS = {"SEL": "R", "VALID": "!(O&R)", "OE": "!(A&!(O&R)&P&F)", "HUB_HOLD": "O|L|!R"}
EXPECTED_INVERTERS = [
    {"instance": "c5_service_mux_logic_inverters", "gate": 1, "input": "C5_SERVICE_OWNED", "output": "C5_SERVICE_OWNER_NOT"},
    {"instance": "c5_service_mux_logic_inverters", "gate": 2, "input": "AON_SERVICE_RELEASE_REQ", "output": "C5_SERVICE_RELEASE_NOT"},
]
CLEAR_INPUTS = ["SERVICE_VBUS_PRESENT_N", "C5_EN_LOW_PROOF", "HUB_SDIO_HIGH_Z_PROOF", "AON_SERVICE_RELEASE_REQ"]
EXPECTED_NANDS = [
    {"instance": "c5_service_release_logic", "gate": 1, "inputs": CLEAR_INPUTS, "output": "C5_SERVICE_CLEAR_N"},
    {"instance": "c5_service_release_logic", "gate": 2, "inputs": ["C5_SERVICE_OWNED", "C5_MUX_SEL_REQUEST", "AON_SAFE_3V3", "AON_SAFE_3V3"], "output": "C5_SERVICE_PATH_VALID"},
    {"instance": "c5_service_path_logic", "gate": 1, "inputs": ["C5_SERVICE_PATH_ACK", "C5_SERVICE_PATH_VALID", "RUN_PERMIT", "FAULT_ASSERT_N"], "output": "C5_MUX_DISABLE"},
    {"instance": "c5_service_path_logic", "gate": 2, "inputs": ["C5_SERVICE_OWNER_NOT", "C5_SERVICE_RELEASE_NOT", "C5_MUX_SEL_REQUEST", "AON_SAFE_3V3"], "output": "C5_SERVICE_HUB_HOLD"},
]
QUALIFICATION_FIELDS = {
    "native_topology_verified", "full_temperature_levels_qualified", "voltage_ramps_qualified",
    "vbus_detector_latch_qualified", "switching_timing_qualified", "recovery_qualified", "production_release_allowed",
}


def positive_number(value: object) -> bool:
    return type(value) in (int, float) and math.isfinite(value) and value > 0


def route_complete(inventory: dict, checked_at: str | None = None) -> bool:
    """A documented acquisition route, NOT electrical or production acceptance."""
    if (not (inventory.get("checked_at") or checked_at)
            or inventory.get("currency") != "USD"
            or type(inventory.get("stock")) is not int or inventory["stock"] < 0
            or type(inventory.get("moq")) is not int or inventory["moq"] <= 0):
        return False
    if inventory.get("route") == "public JLCPCB stock":
        quantity = inventory.get("available_order_quantity")
        prices = inventory.get("price_tiers_usd")
        return (type(quantity) is int and inventory["stock"] >= quantity >= inventory["moq"]
                and isinstance(prices, list) and bool(prices)
                and all(type(row.get("minimum_quantity")) is int and row["minimum_quantity"] > 0
                        and positive_number(row.get("unit_price")) for row in prices))
    estimate = inventory.get("preorder_estimate", {})
    return (inventory.get("route") == "explicit JLCPCB Pre-order"
            and inventory["stock"] == 0 and inventory.get("available_order_quantity") is None
            and inventory.get("explicit_preorder_offered") is True
            and inventory.get("price_is_estimate") is True
            and "lead_time_days" in inventory and inventory["lead_time_days"] is None
            and inventory.get("price_tiers_usd") == []
            and positive_number(estimate.get("unit_price"))
            and type(estimate.get("minimum_quantity")) is int
            and estimate["minimum_quantity"] == inventory["moq"]
            and estimate.get("not_a_stocked_price_tier") is True)


def ordered_trace_errors(control: dict) -> list[str]:
    """Cross-check explicit event order; the model's waits remain unmeasured."""
    errors = []
    traces = control.get("ordered_traces", {})
    if set(traces) != {"runtime_to_service", "service_to_runtime"}:
        return ["both explicit ordered control traces are required"]
    spec = importlib.util.spec_from_file_location("c5_mux_order_witness", CONTROL_MODEL)
    module = importlib.util.module_from_spec(spec)
    assert spec.loader is not None
    spec.loader.exec_module(module)
    for name, destination in (("runtime_to_service", "usb"), ("service_to_runtime", "sdio")):
        try:
            events = []
            for row in traces[name]:
                if set(row) == {"controls"}:
                    values = row["controls"]
                    if len(values) != 6 or any(type(value) is not int or value not in (0, 1) for value in values):
                        raise ValueError("six literal binary O/R/A/L/P/F controls required")
                    events.append(module.Controls(*values))
                elif set(row) in ({"assumed_wait"}, {"assumed_wait", "duration_ms"}):
                    events.append(module.AssumedWait(row["assumed_wait"], row.get("duration_ms")))
                else:
                    raise ValueError("unknown event or measurement claim")
            result = module.check_sequence(events)
            required_waits = {"reset_and_pad_high_z", "mux_settle"}
            if destination == "sdio":
                required_waits.add("c5_strap_and_ready")
            if (result["errors"] or result["final_outputs"]["path"] != destination
                    or not required_waits.issubset({row["kind"] for row in result["conditional_waits"]})
                    or result["boundary"]["timing_qualified"] is not False
                    or result["boundary"]["production_topology_verified"] is not False):
                errors.append(f"{name}: ordered control trace lacks safe conditional sequencing")
        except (KeyError, TypeError, ValueError):
            errors.append(f"{name}: malformed ordered control trace")
    return errors
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

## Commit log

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2026-08-08 docs: sync display to QSPI AMOLED across all docs
    Replace SPI-TFT (ST7789/ILI9341) with QSPI AMOLED (RM67162) in README,
    hardware, roadmap and power docs (EN+RU); display now on its own QSPI bus.
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2026-08-08 docs: make I²C role per-mode in pin-budget (not a generic label)
    I²C was labelled "sensors · RTC · RFID · buttons" in every mode, which is
    wrong — in most modes I²C only carries the buttons (hub). It's radio-
    relevant only in Listen (Si4732 control) and Keys (RFID2 reader).
2026-08-08 docs: rebuild pin-budget bottom-up (minimal common + per-mode, no hub)
    Restructure by the requested method: a minimal always-present common set
    (encoder + status + SPI bus + 74HC138 CS + I2C = 12, + display), then each
    mode's use case and the exact lines it adds from a reused pool. Peak =
    LoRa+GPS. Aggregate: SPI 17/19 fits with no hub and no cuts; QSPI 21/19
    overflows. Hub section shows it's pin-neutral and cannot fix the overflow
    (the peak mode's pins are all timing-critical). Plus a mode-switch latency
    table and the warm/sleep + pre-warm firmware rules.
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2026-08-09 docs: lock ST7796 SPI display, correct pin budget, sync architecture
    Pin budget corrected: per-chip radio control lines SUM (not a reusable pool); add a PCA9555 I2C expander for the slow control lines; C5 ceiling ~20 GPIO. Display locked to ST7796 320x480 IPS over SPI (+1 pin); QSPI would exceed budget. Architecture: LoRa raw SX1262 onboard, GPS as u-blox on I2C, single Grove I2C port, 8 onboard antennas, hardware-only TX-live LEDs.
2026-08-09 hardware: add Sheet 2 (ESP32-C5 + buses) and Sheet 3 (RF chains)
    Sheet 2: C5 GPIO map, 74HC138 CS decoder (8 chip-selects), PCA9555 slow-line expander, SPI/I2C/UART fan-out, native USB, battery gauge via BQ25887 I2C. Sheet 3: SPI data radios (3x nRF24L01+PA/LNA, CC1101, SX1262 LoRa) with CS via 138 and brownout caps. Roadmap items checked off.
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2026-08-09 hardware: add Sheet 6 (indicators/IO) + reset/boot/power buttons
    Sheet 6: 7x hardware TX-live envelope-detector LEDs (0 GPIO), WS2812 status, active buzzer, IR TX/RX, microSD, encoder. Added the three system buttons the pin map had missed: RESET on EN, BOOT on GPIO28 (C5 download strap), POWER on BQ25887 /QON (Sheet 1). Fixed strap conflicts: GPIO28 was 'spare' -> now BOOT; GPIO27 (WS2812) needs a boot pull-up (must be high for download); GPIO2 = crystal-freq strap. All six schematic sheets now designed; README status updated.
2026-08-09 power: add hard master switch (true-off), fix power-off model
    Add a hard SPST master switch in series with the pack for a firmware-independent true-off / storage kill (breaks the pack line, ~0 draw; USB still runs SYS via power-path). Correct the earlier claim that a long /QON press is a cutoff — it is a hardware RESET (reboots a hung MCU), not an off. Daily on/off stays soft via BQ25887 ship-mode (clean shutdown parks TX + flushes SD).
2026-08-09 power: fix BQ25887 (boost, no PD/power-path/ship-mode), master-only off
    Datasheet correction: BQ25887 is a 2S BOOST charger (5V->8.4V, no PD), has no NVDC power-path and no ship mode. Bucks now sit on the BAT node; drop CH224K/PD, VSYS, SW_PWR/QON, VMON->ADC. 2S AFE fixed to S-8252A with low-side FETs. LoRa moved off +5V to +3V3. Master switch is the only on/off (fuel gauge via BQ I2C ADC).
2026-08-09 c5-buses: WROOM-1U antenna, consolidate PCA9555 map, gate 74HC138, drop soft power button
    WROOM-1U (u.FL external antenna, TX-LED-capable). Consolidate all slow signals onto the PCA9555 (16 mapped): add LCD_RESX, LCD_BL_EN, MUX_SEL, LoRa_TR (RXEN/TXEN via inverter), PAM_SD, RFSW_CTL, HC138_EN; drop nRF24_IRQ (polled) and BQ_QON; rename BQ_CE->BQ_CD. Gate 74HC138 G2A via HC138_EN (pulled high = disabled through the boot/strap window). Remove the soft power button (BQ25887 has no ship mode); RESET+BOOT only, power via master switch. Note WS2812 5V level shifter.
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2026-08-09 expansion: Grove 3V3 default + translator for 5V, TCA9548 channel pull-ups, Si4732 0x11
    Grove I2C port is 3.3V by default (C5 not 5V-tolerant); 5V only via a jumper behind a PCA9306/TCA9517 translator. Each used TCA9548A downstream channel needs its own pull-up pair. Si4732 address fixed to 0x11 (SEN=GND).
2026-08-09 indicators: WS2812 5V level shifter, microSD dummy clocks + card-detect
    Add 74AHCT1G125 buffer on WS2812 DIN (3.3V is below the 5V part's ~3.5V threshold). microSD: issue 8+ dummy clocks after deselect; optional card-detect on a spare PCA9555 port. POWER is the master switch, not a PMIC button.
2026-08-09 docs: GPS onboard wording, WS2812/5V level-shift carve-out, pin-budget = 20/20 (BOOT counted)
    GPS is onboard on the I2C bus (not on the Grove port) everywhere. Level-shift claim now carves out WS2812 and 5V Grove. Pin budget corrected: DIO1 and nRF24 IRQ are polled baseline (radio lines 6 not 7); 19 signals + BOOT = 20/20 with no spare; PCA9555 now lists all 16 slow lines the review surfaced.
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2026-08-09 diagrams: fix system-diagram legend (CSS text-anchor override), power labels + S-8252A
    system-diagram: the .s class text-anchor:middle overrode inline text-anchor=start, centering long legend/notes off-screen; moved notes to the start-anchored .sub class and de-crowded the legend. power-schematic: fix S-8254A->S-8252A, un-overlap the +5V/+3V3 rail labels from the inductor labels, shorten BAT node label.
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2026-08-09 docs(sheet2): rewrite MCU+buses for dual-chip S3+C5
    S3 (N8R2 quad-PSRAM) main brain, 36/38 GPIO; C5 co-processor.
    Dedicated SPI3 link + DRDY ready-strobe; standalone via 74CBTLV3257
    SPI mux (variant A: display+SD+own radios). Corrects C5 flash/PSRAM
    pin set (GPIO19 free, GPIO15 used) and download strap combo (26+28).
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2026-08-10 docs(sheet2): apply pre-propagation review fixes
    Root-fix the GPIO45 brick via eFuse de-strapping (set_flash_voltage
    3.3V) so CC1101 GDO2 carrier-sense stays a direct interrupt with no
    band-aid and no pin movement (net renamed CC1101_GDO2, not CC1101_CS).
    nRF24 IRQ is push-pull -> 74AHC 3-input gate (idle-low, strap-safe).
    Add C5_BOOT pull-up, rail-gating interlocks (+3V3A from +5V; WS2812/IR
    back-power rule), brick-safe battery caveat; reorder pin rows.
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2026-08-10 hw(tscircuit): drop broken kicad_sch export; PCB is the layout target
    tscircuit's kicad_sch export produces dangling labels (KiCad ERC: 319
    pin-not-connected / label-dangling), so it is not a usable schematic —
    removed. The schematic of record is power.tsx + power-schematic.svg
    (connectivity correct); power.kicad_pcb carries the real nets (358) and
    is the KiCad layout target. README updated with the caveat + verify step.
    [power.kicad_sch]
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2026-08-10 hw(tscircuit): merge 6 sheets into one board; fix 5 cross-sheet net breaks
    Merging the sheets surfaced 5 buses that failed to connect because two sheets
    named the same signal differently. Aligned the peripheral sheets to the MCU/bus
    canon:
    - microSD data lines SPI2_* -> SPI_* (onto the shared SPI bus)
    - SA868 UART SA_TXD/RXD -> SA868_UART_TX/RX (S3-TX -> module-RXD verified)
    - SA868 SA_PTT/PD -> SA868_PTT/PD; Si4732 SI_RST -> Si4732_RST
    - BOOT button -> S3_BOOT (S3 GPIO0 strap)
    board.tsx = whole device (133 parts, 131 nets); board.kicad_pcb = layout target.
    [board.kicad_pcb]
2026-08-11 hw(power/buses): fix 8 issues from schematic self-review (1 blocker)
    An adversarial multi-agent review of the merged schematic surfaced 8 real
    defects; each was verified against the combined netlist, then fixed:
    - BLOCKER: +3V3 buck was TLV62569 (Vin max 5.5V) sitting on the 8.4V BAT node
    -> swapped to wide-Vin MP2315 (FB R3 45.3k->31.6k for 0.8V ref); EN auto-on
    via a 100k/47k divider off BAT instead of raw 8.4V on the EN pin.
    - +5V and +3V3 MP2315 bootstrap caps (BST->SW) were missing -> bucks would not
    switch; added Cbst4 / Cbst5 100nF.
    - S3 had no EN pin wired -> the reset chain (SW11 + RC) was a floating island;
    added U10.EN and connected net.S3_EN.
    - C5 EN had no pull-up/RC ->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
    [board.kicad_pcb]
2026-08-11 hw(power): realize sheet to fab-draft — engine-pulled footprints, boost topology fix
    power.tsx now uses manufacturer-verified footprints + pinouts pulled from the
    LCSC/JLCPCB database by part number (footprint="jlcpcb:C…"), so pinouts are
    authoritative, not hand-typed. KiCad DRC on the export: 0 unconnected, 0 shorts,
    0 schematic-parity (remaining violations are placement/routing only).
    - BQ25887 rewired as the BOOST it is: inductor PMID<->SW, boost output SNS->BAT,
    full support net (PMID/REGN/BTST/SNS/ILIM/MID caps) + TS thermistor divider from
    REGN (missing before -> charging would be blocked). Was buck-style SW->L->BAT.
    - MP2315 on its authoritative pinout (1 AAM,2 IN,3 SW,4 GND,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
    [power.kicad_pcb]
2026-08-11 hw(c5-buses): realize sheet + fix GPIO33/34 blocker (not bonded on WROOM-1U)
    Realized to fab-draft via engine-pulled footprints (LCSC): ESP32-S3-WROOM-1U-N8R2
    C3013944, ESP32-C5-WROOM-1U C49308183, 74HC138 C157527, 2x PCA9555 C128392.
    KiCad DRC: 0 unconnected, 0 shorts, 0 schematic-parity.
    DESIGN CORRECTION found by realizing against the real module: the WROOM-1U does not
    bond out GPIO33/34 (module pins jump IO21->IO35), so the plan of C5_EN=GPIO33 /
    C5_BOOT=GPIO34 was invalid — those pads do not exist (independent of PSRAM; quad frees
    only 35-37). Moved C5_EN/C5_BOOT to PCA9555 #2 (P05/P06) — slow set-once lines whose
    pull-ups hold safe power-on defaults. S3 direct GPIO is 36/36 (was m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
    [c5-buses.kicad_pcb]
2026-08-11 hw(rf): realize sheet to fab-draft — engine footprints, CC1101 support, IRQ NAND
    Realized via engine-pulled LCSC footprints; KiCad DRC 0 unconnected / 0 shorts /
    0 schematic-parity. Parts: CC1101RGPR C29953, E22-900M22S C411293, 74LVC1G04 C7827,
    74LVC1G10 C485078. nRF24 / PE42440 / balun kept as documented placeholders.
    - CC1101 (bare QFN-20) gained the full support net the logical sheet lacked:
    all AVDD/DVDD + DGUARD -> +3V3, DCOUPL 100nF -> GND, RBIAS 56k 1% -> GND, EP -> GND.
    - nRF24 IRQ combiner pinned as a 3-input NAND (74LVC1G10): idle-HIGH active-low inputs
    -> idle-LOW output (asserts HIGH), matching the GPIO46 boot strap.
    - Fixed a crystal footprint that dropped its trace coor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
    [rf.kicad_pcb]
2026-08-11 hw(rf,c5-buses): resolve SP4T sourcing — SKY13414 (in stock) + RFSW_C
    PE42440 isn't stocked at JLCPCB; swapped to the in-stock SKY13414-485LF (C255353),
    engine-pulled footprint. It uses 3-line control (V1/V2/V3 = RFSW_A/RFSW_B/RFSW_C);
    added RFSW_C on PCA9555 #2 P07 (c5-buses). Switch common -> CC1101 radio, RF1..RF4 ->
    per-band matches -> shared antenna; EP + unused pads grounded. Both sheets KiCad DRC
    0 unconnected / 0 shorts / 0 parity. Docs (rf EN+RU) updated.
    [c5-buses.kicad_pcb, rf.kicad_pcb]
2026-08-11 hw(audio): realize sheet to fab-draft — engine footprints, SA868 single-supply fix
    0 schematic-parity. Parts: Si4732-A10 C1526102, SA868-U C3001507, PAM8302A C113367
    (8-pin MSOP), 74LVC1G3157 C10426, 32.768kHz NX3215SA C280830.
    Corrections found by realizing against the real parts:
    - SA868-U is a single-supply module (one VBAT, 3.3-5.5V) — the base's separate
    VIN(+5V)+VCC3V3(+3V3) is wrong; VBAT -> +5V, the 3V3 pin dropped. AudioON (active-
    low internal-amp enable) -> GND.
    - PAM8302A is 8-pin MSOP, not SOT-23-6.
    - Si4732 gained RFGND -> GND + a 100nF VDD HF decap.
    Jack/mic/speaker are placeholders; SA8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
    [audio.kicad_pcb]
2026-08-11 hw(expansion,indicators): realize final two sheets to fab-draft
    Both realized via engine-pulled LCSC footprints; KiCad DRC 0 unconnected / 0 shorts /
    0 schematic-parity on each. All 6 sheets are now fab-drafted with real parts.
    expansion: SAM-M8Q C5447387, Grove C722729, ESD PESD5V0S2UAT C552572, BAT54 C466635,
    0.22F supercap C3019760. Correction: SAM-M8Q has a separate VCC_IO pad the placeholder
    lacked -> tied to +3V3; added datasheet GPS decoupling. DDC pins left open (UART-only).
    indicators: MMBT3904 C20526, WS2812B C2761795, 74AHCT1G125 C7484, TSOP38238 C141632,
    microSD C961683, EC11 C361165. Correction: U51 pinout was wrong (real SOT-23-5 =
    1 OE,2 A,3 GND,4 Y,5 VCC); must be AHCT not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
    [expansion.kicad_pcb, indicators.kicad_pcb]
2026-08-11 hw(board): merge all 6 realized sheets into one real-parts board (169 parts)
    Final recombine with the parts engine on: every sheet's real jlcpcb: footprints
    carried into one board.tsx. Cross-sheet nets stitch (SPI / I2C / rails / CS /
    interrupts / C5-link / SP4T-select all verified in board.net). KiCad DRC:
    schematic_parity = 0, 0 shorts, 0 NaN. Refdes collisions renamed (U20, Y1, and the
    new Rbias). The board is not yet routed (0 copper) — unconnected_items is the
    ratsnest, not breaks; routing (RF by hand) is the next step. README updated.
    [board.kicad_pcb]
2026-08-12 hw: fix 6 issues from realized-board self-review (2 blockers)
    Adversarial multi-agent review of the real-parts board caught 6 real defects the
    per-sheet DRC couldn't see; all datasheet-verified, fixed, sheets re-verified
    (DRC parity=0 each):
    - BLOCKER (power): BQ25887 SNS was tied to BAT externally -> shorts the internal
    charge-current shunt, defeating ICHG regulation on the 2S pack. SNS is now its own
    net (44uF to GND only); the SNS<->BAT shunt is internal.
    - BLOCKER (expansion): PESD5V0S2UAT ESD arrays (common-cathode) had the common cathode
    on GND -> every I2C logic-high forward-biases the diode and clamps SDA/SCL to ~0.6V
    (whole bus dead). Cathode moved to +3V3 (clamps overshoot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
    [audio.kicad_pcb, c5-buses.kicad_pcb, expansion.kicad_pcb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]
2026-08-12 hw(board): re-merge after self-review fixes (174 parts, parity=0)
    Re-combined all 6 corrected sheets. KiCad schematic_parity=0 (PCB netlist matches
    schematic), 0 NaN. All 6 self-review fixes confirmed in the merged netlist: SNS
    isolated from BAT, ESD cathodes on +3V3, PAM8302 input coupling caps, MP2315 20R
    bootstraps, BQ25887 TS RT2. Cross-sheet buses stitch (SPI/I2C/rails/RFSW_C). The
    board is unplaced/unrouted, so DRC unconnected + shorting are placement artifacts
    (see README). README updated (174 parts + DRC note).
    [board.kicad_pcb]
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2026-08-12 hardware: add edge-aware 4-layer placement (routing start)
    Auto-placement draft from board.kicad_pcb: 174 parts in floorplan zones
    (RF at antenna edge, power bottom, MCU centre), cable/slot connectors
    pinned to board edges (USB-C bottom, microSD left, Grove right), 0
    courtyard overlaps. Converted to 4-layer (JLC7628, In1=GND plane) with a
    DRC floor in the sibling .kicad_pro.
    Routing stays a KiCad-by-hand job: a headless autorouter
    (KiCadRoutingTools) tops out ~45% of nets with clearance/short
    violations on a board this dense — expected; interactive routing + hand
    RF is the path. README documents the status.
    [board-placed-4layer.kicad_pcb]
2026-08-12 hardware: auto-route with Freerouting (~85% of nets)
    Corrects the earlier call that this board can't be auto-routed: the
    tool was wrong, not the task. Freerouting 2.3.0 (headless, Java 25)
    via Specctra DSN->SES routes 424/499 connections (85%) with only 4
    KiCad-DRC clearance nits — 2960 segments + 457 vias over a filled In1
    GND plane. Remaining ~75 nets (RF feeds + tightest spots) are the
    hand-finish. Fixes In2.Cu layer type (was power -> signal) and fills
    the GND plane BEFORE routing.
    board-autorouted.kicad_pcb added; README documents the DSN/SES flow.
    [board-autorouted.kicad_pcb]
2026-08-12 hardware: near-complete auto-route (424/425 nets)
    Two-tool pipeline: Freerouting routes signals + RF, then
    KiCadRoutingTools plane-finalize welds GND pads to the In1 plane.
    Result: 424/425 connections on 4 layers, 3304 segments + 715 vias over
    a filled GND plane, only 1 net (encoder B) + 4 DRC clearance nits left.
    RF traces still want an impedance/coplanar hand-redo. Supersedes the
    Freerouting-only draft in board-autorouted.kicad_pcb.
    [board-autorouted.kicad_pcb]
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2026-08-12 hardware(stage1): add display FPC, antenna u.FL, full controls + 3rd PCA9555
    Completes the schematic's missing connectors + controls:
    - Display FPC connector C19273968 (LCD_*/SPI/power/backlight wired;
    backlight LED nets go to the Stage-3 driver; touch pins NC).
    - 3× u.FL C2987682 for the bare radios (CC1101/SA868/Si4732),
    pin2=signal; Si4732 whip shares FM/AM via a coupling cap.
    - Master switch: proxy resistor -> real SPDT C496164 (COM=pin2).
    - Full nav control set: D-pad (5 tactiles) + BACK + OPTIONS + STOP +
    F1 + F2 on a 3rd PCA9555 (U14, 0x22); PTT stays on U13.
    191 footprints (was 174). All display + bare-radio-antenna nets now
    connected. Remaining danglers are expected: ANT_LoR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
    [board.kicad_pcb]
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2026-08-15 docs: drop stale single-board artifacts + regen hints; GPS -> external M5 Unit
    1. Artifact triage (two-board clamshell + C5-drives-nRF/IR pivots): dropped 21 regenerable/abandoned files -- the single-board board.tsx + all board-*/placed/autorouted/4-layer outputs, the pre-C5-drive rf/c5-buses schematic exports, and the abandoned hand-drawn hardware/kicad tree. Added how-to-(re)obtain recipes to README stages 6/7/8 (EN/RU) with the trial-and-error lessons baked in (parts-engine footprints, merge.py -> two boards, Freerouting + route.py plane-finalize, the write-gate, the clamshell-fold / mezz-mate checks). Stage 6 status -> in-rework (sheets need the C5-drive re-netlist).
    2. GPS is now an EX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
    [audio.kicad_sch, board-autorouted.kicad_pcb, board-placed-4layer.kicad_pcb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]
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2026-08-17 Review non-interfering digital layout
    [generate.py]
2026-08-17 Accept qualified nRF mix observer fixture
    [generate.py]
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2026-08-17 Accept fail-safe audio architecture and clarify diagrams
    [generate.py]
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2026-08-17 docs: review fail-closed 2s manager options
    [generate.py]
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2026-08-17 docs: accept fail-closed 2s manager
    [generate.py]
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2026-08-17 docs: accept fail-closed battery circuit
    [generate.py]
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2026-08-18 Complete local controls and correct TCA9534A addressing
    [generate.py]
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2026-08-19 Fix layout legend and close U214 host connector
    [G2F-3I-target-bom.csv]
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2026-08-19 Correct raised U214 dock geometry
    [G2F-3I-target-bom.csv]
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2026-08-19 Use compact fail-safe STOP button
    [G2F-3I-target-bom.csv]
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2026-08-19 Replace D-pad matrix with guided direct controls
    [G2F-3I-target-bom.csv]
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2026-08-19 Replace stop controls with monitored RUN KILL safety
    [G2F-3I-target-bom.csv]
2026-08-19 Fix exact native RF jumper routes
    [G2F-3I-target-bom.csv]
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2026-08-20 Replace safety MCUs and define rollback memory
    [G2F-3I-target-bom.csv]
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2026-08-23 Replace custom D-pad with series buttons
    [G2F-3I-target-bom.csv]
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2026-08-23 redesign product landing around mockups
    [generate.py]
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2026-08-25 hardware: replace full-reel IR receiver
    [G2F-3I-target-bom.csv, UI_20_C5_RADIO_IR_SERVICE.kicad_sch]
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2026-08-27 Correct K331 RSSI contract and free rear GPIO15
    [h0_r2_report.py]
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2026-08-28 Replace six pre-order resistor identities
    [CAP_20_POWER_BUS.kicad_sch, CAP_30_TX_EVIDENCE.kicad_sch, G2F-3I-target-bom.csv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]
2026-08-28 Replace pre-order Schmitt inverter package
    [G2F-3I-target-bom.csv, H1-R2-cost-ranked.csv, H5-EVR04-jlcpcb-bom-upload.csv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]
2026-08-28 Replace three pre-order passive parts
    [G2F-3I-target-bom.csv, H1-R2-cost-ranked.csv, H5-EVR04-jlcpcb-bom-upload.csv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]
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2026-08-28 Correct dual-NMOS physical pin mapping
    [RF_02_PACK_SAFETY_AON.kicad_sch, RF_50_TX_SAFETY_EVIDENCE.kicad_sch, UI_50_TX_SAFETY_EVIDENCE.kicad_sch]
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2026-08-28 Correct U219 live Cap-Bus pin contract
    [h1_r2_u219_cap.py]
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2026-08-28 fix dual-face GCT antenna footprints
    [generate.py, h2_rf_nrf24_x3.py]
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2026-08-29 make first prototype release fail closed
    [G2F-3I-target-bom.csv, H1-R2-cost-ranked.csv, RF_03_MAIN_RAILS_DOMAIN_GATES.kicad_sch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]
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2026-08-29 Correct R2 cost quantities and retain recovery hardware
    [H1-R2-cost-ranked.csv, H1-R2-cost-top20.csv]
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2026-08-30 Correct H2-R2 physical contact ledger
    [h0_r2_report.py]
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2026-08-31 Connect RF emergency reset to active RP reset net
    [LESHY2-RF-R2.kicad_sch, RF_10_RP2354_CORE_SERVICE.kicad_sch, RF_50_TX_SAFETY_EVIDENCE.kicad_sch]
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2026-09-03 Route oscillator control slice
    [LESHY2-RF-R2.kicad_pcb, LESHY2-UI-R2.kicad_pcb]
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2026-09-06 Complete oscillator-class routing
    [LESHY2-RF-R2.kicad_pcb]
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2026-09-07 Correct SMA geometry and module power; bind verification to current boards
    [LESHY2-RF-R2.kicad_pcb, LESHY2-UI-R2.kicad_pcb, LESHY2-UI-R2.kicad_sch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]
2026-09-07 Fix exact pin maps and RP flash power; add typed electrical review
    [LESHY2-RF-R2.kicad_pcb, LESHY2-UI-R2.kicad_pcb, RF_03_MAIN_RAILS_DOMAIN_GATES.kicad_sch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]
2026-09-07 Correct exact connector and protection geometry; expand electrical review
    [LESHY2-RF-R2.kicad_pcb, LESHY2-UI-R2.kicad_pcb, RF_10_RP2354_CORE_SERVICE.kicad_sch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]
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2026-09-07 Correct exact RF lands and reopen native power prerequisites
    [LESHY2-RF-R2.kicad_pcb, LESHY2-UI-R2.kicad_pcb, RF_20_CC1101_VOICE_TX.kicad_sch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]
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2026-09-07 Audit native interfaces and correct connector poses and user silkscreen
    [LESHY2-RF-R2.kicad_pcb, LESHY2-UI-R2.kicad_pcb, RF_01_USB_PD_CHARGE.kicad_sch]
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2026-09-08 Correct second-cell polarity and fuse locality; reopen unproven thermal contact
    [LESHY2-RF-R2.kicad_pcb, RF_02_PACK_SAFETY_AON.kicad_sch]
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2026-09-08 Correct EC11 fit and add seven reviewed LED routes
    Integrate the exact-axis engineering EC11 footprint and local support placement while preserving all765 RF copper objects and five encoder world pad/net pairs. Add51 UI segments and8 vias for seven reviewed anode nets, retaining all33 prior UI copper objects and excluding FAULT.
    Refresh native DRC, four-face component views, routing counters, H3 contract hashes, typed ERC and source-path triage. Correct stale holder/JAE evidence wording; retain24 raw ERC findings, open mechanical/power gates and historical firmware qualification. Add actual-files freshness and public-counter regressions.
    Checks:1182 hardware tests with46 skips;116 native f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
    [LESHY2-RF-R2.kicad_pcb, LESHY2-UI-R2.kicad_pcb, RF_31_REAR_CONTROLS.kicad_sch]
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2026-09-08 fix(hardware): correct native placement and publish verified component views
    [LESHY2-RF-R2.kicad_pcb, LESHY2-UI-R2.kicad_pcb]
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2026-09-09 Complete native interface silkscreen with verified local clearances
    Add 29 real front/back labels and independently cover 76 interfaces / 95 required captions. Move eight reviewed unrouted RF resistors while preserving all native copper and named pad connectivity. Refresh four-face, exterior, and routing visuals; keep H6.0.3-R1 open.
    Validation: system suite 1459 tests OK (114 skips in system Python); KiCad H6 suite 863 tests OK, no skips. Both native DRC reports have zero violations and zero schematic-parity errors. Current routing remains incomplete.
    [LESHY2-RF-R2.kicad_pcb, LESHY2-UI-R2.kicad_pcb]
2026-09-09 Separate RF cell polarity labels from the branding block
    Move the three branding lines down 0.8 mm without moving battery labels, USB labels, components or copper. Add finite native typography/clearance regressions and refresh source-bound audits and views.
    Validation: 135 focused native tests pass; both boards have zero DRC violations and schematic-parity findings. Raw native comparison permits only the three text-position changes. Cell-to-title ink gap is 0.99028 mm; existing routing remains incomplete.
    [LESHY2-RF-R2.kicad_pcb]
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2026-09-13 Increase display clearance above upper LED row
    [LESHY2-UI-R2.kicad_pcb]
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

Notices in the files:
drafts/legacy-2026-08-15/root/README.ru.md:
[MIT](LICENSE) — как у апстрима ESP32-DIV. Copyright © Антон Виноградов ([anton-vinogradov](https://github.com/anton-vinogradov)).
